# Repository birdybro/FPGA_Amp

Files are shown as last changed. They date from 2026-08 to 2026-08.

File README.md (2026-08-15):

# FPGA Amp

FPGA Amp is a physically informed vacuum-tube audio simulator. The immediate
target is a moving-magnet cartridge feeding the two triodes of a 12AX7 through
the passive RIAA network published by Kevin Kennedy in 1998. It is modeled as a
coupled electrical circuit—not as an EQ block followed by a waveshaper.

```text
AT-VM95E R/L source -> 47.5 kΩ || 150 pF -> 12AX7 #1
 -> 47 nF / 210 kΩ / 33.2 kΩ / 10 nF / 3.3 nF passive RIAA
 -> 12AX7 #2 -> 470 nF -> 2.21 MΩ line load
```

The project keeps three categories separate:

- **Reference:** the frozen 1998 circuit, including its measured low-frequency
  RIAA departure.
- **Approximation:** tube-model, integration, LUT, fixed-point, solver, and RTL
  errors measured against the immediately upstream reference.
- **Enhancement:** future subsonic filtering, tube variation, noise, and other
  modern/creative controls, all explicitly opt-in.

## Current measured milestone

The mono reference and complete 768 kHz circuit solver are operating:

- ngspice DC: stage 1 is 180.0 V / 0.992 mA and stage 2 is 192.8 V /
  1.072 mA at a 300 V supply.
- SPICE circuit gain is 41.087 dB at 1 kHz. Relative RIAA error is
  -0.919 to +0.000 dB from 20 Hz to 20 kHz; this is a property of the frozen
  historical network, not digitally corrected.
- The 768 kHz backward-Euler nonlinear nodal model differs from the ngspice
  5 mV-peak, 1 kHz result by -53.10 dB normalized residual and 0.0018 dB RMS
  gain, with no failed solves.
- A four-frequency SPICE transient sweep exposes backward-Euler's audio-band
  phase cost: at 100 Hz it is +0.00131 dB / +0.0244°, while at 20 kHz it is
  -0.0646 dB / +4.72°. Raising backward-Euler to 3.072 MHz still leaves 1.24°
  at 20 kHz. An explicit 768 kHz trapezoidal candidate improves 10/20 kHz
  floating error to at most 0.00846 dB / 0.0582°.
- A separately labeled 384 kHz/8× trapezoidal architecture candidate measures
  at most 0.06653 dB / 0.02234° against the same 10/20 kHz SPICE captures. At
  20 kHz, its complete-circuit selected 4/8/12/16 kHz products remain within
  0.52 dB of 768 kHz for 5 mV, 20 mV, and steady 0.5 V inputs, while a hot
  static-tube stress is 11.33 dB worse but still -118.65 dBc. Distinct
  fixed-point assets now match 1,024 all-bank chord, 1,024 KCL, and 512
  persistent full-solver RTL vectors exactly at 384 kHz with zero solver
  diagnostics. The 127-clock core
  leaves 129 of 256 clocks free at 98.304 MHz. Its Q17.1 chord inverse requires
  signed 19-bit coefficients rather than the 768 kHz core's 18 bits; controlled
  Yosys synthesis measures 13,713 LC / 183 DSP / 10 RAMB18 equivalents versus
  13,158 LC / 174 DSP / 10 RAMB18 equivalents at 768 kHz. The complete
  candidate stream now matches 64 external outputs across 512 nonlinear
  updates exactly, with zero converter, solver, or deadline diagnostics.
  After serializing each decimator center tap and replacing both resamplers'
  reset-cleared shift histories with reset-masked circular distributed memory,
  controlled full-stream synthesis measures 15,716 LC / 8,547 FF / 207 DSP /
  10 RAMB18 equivalents at 384 kHz versus 16,062 / 9,033 / 206 / 10 for 768 kHz.
  Reference mode remains 16×/768 kHz. A 772,608-update paired fixed-stream
  campaign finds
  8× recovery only 0.1875 ms later, with -84.71 dB aligned waveform and
  -81.02 dB audio-band residuals. Known-delay, windowed-sinc alignment measures
  the synthetic pop at -35.92 dB overall, 2.623 mV peak error, and -53.33 dB
  in-band. A layer decomposition measures the identity converters at -67.49 dB
  in-band, floating Newton at -55.71 dB, and fixed at -53.33 dB; same-rate
  fixed/float nulls remain about -59 dB. This supersedes an invalid earlier
  linear-interpolation result. Direct RTL capture matches the corresponding
  fixed models for all 24,576 pop/recovery outputs and 294,912 nonlinear
  updates at both rates with zero diagnostics. A matched, unfitted absolute
  pop-response comparison against ngspice measures -61.47 dB residual at the
  48 kHz output boundary for 384 kHz and -61.00 dB for 768 kHz; maximum errors
  are 0.539 and 0.546 mV, respectively, with zero failed floating solves. This
  experiment therefore does not support keeping 16× on transient-accuracy
  grounds. The earlier shifting-history three-pin harness packs on XC7A100T at
  63,902 LUTX / 14,737 FFX / 4,071 CARRY4 / 207 DSP, but heap placement does
  not legalize. That baseline legally places on XC7A200T with
  nextpnr's static placer at only 34.40 MHz versus 98.304 MHz. The experimental
  backend's `DEFAULT` grade is not qualified -1 signoff, but the 2.86× miss is
  decisive enough to skip routing. An explicit 49.152 MHz fabric schedule then
  halves every enable interval while preserving the same 384 kHz arithmetic:
  its 127-clock solver fits exactly within the 128-clock internal period, and
  the complete 64-output/512-update regression remains bit-exact with zero
  diagnostics. Baseline static A200T placement improves to 38.34 MHz versus
  49.152 MHz. Circular decimator history then cuts the packed design to 58,363
  LUTX / 10,562 FFX / 4,099 CARRY4 / 207 DSP and makes heap placement legal for
  the first time, but its 22.79 MHz estimate still fails timing. Static
  placement initially reaches 38.38 MHz. Circular interpolation then reduces
  the pack to 56,041 LUTX / 8,589 FFX / 4,116 CARRY4 / 207 DSP and improves
  static placement to 41.27 MHz. The completed legal route reaches 48.482 MHz,
  only 1.38% below 49.152 MHz. Its 20.626 ns critical path starts at solver
  state selection, crosses voltage selection and plate-pin conversion, and
  ends in the factorized-tube input mapping. A separately named exact
  123-clock parallel/pipelined profile instead grows to 242 DSPs and places at
  only 39.62 MHz, so it is rejected. A route-guided tube-pin prefetch plus
  diagnostic-only KCL maximum pipeline also preserves all 64 outputs / 512
  updates and the 127-clock latency. After removing an invalid-only dead
  maximum load it routes legally at 47.07 MHz, but its 21.24 ns chord-preview
  path is slower than the baseline and is likewise not promoted. The route
  remains diagnostic rather than timing closure or a bitstream claim. A
  zero-latency late-selector candidate instead converts current and corrected
  stage-one tube pins independently and selects only the two 32-bit pin buses.
  It remains bit-exact at 127 clocks, synthesizes to 15,645 LC / 8,589 FF /
  207 DSP / 10 RAMB18 equivalents, and routes legally at 48.700 MHz in seed 1.
  That is the best measured route but still misses 49.152 MHz by 0.92%; seed 2
  reaches only 45.051 MHz. Combining it with the register-heavy four-boundary
  maximum sideband was stopped after a pathological first routing iteration
  and is not promoted. A lower-state serial maximum instead scans the nine
  stable residual rows during terminal chord work. It matches 2,048 KCL
  vectors and the complete stream exactly, reduces the pack to 54,699 LUTX /
  8,657 FFX / 4,044 CARRY4 / 207 DSP, and routes legally in 14 iterations, but
  reaches only 47.567 MHz through the now-exposed chord-to-tube path.
  Registering the six raw tube nodes on the exact one-cycle-early chord preview
  removes that path without adding a solver clock: the same complete stream is
  bit-exact at 127 clocks, Yosys measures 15,220 LC / 8,855 FF / 207 DSP /
  10 RAMB18 equivalents, and a legal seed-1 A200T route reaches 61.072 MHz
  against 49.152 MHz. The 16.37 ns critical path is now terminal-current/state
  arithmetic, with 6.44 ns logic and 9.94 ns routing. This closes the target
  under nextpnr's experimental `DEFAULT` grade. Seed 2 independently routes at
  51.080 MHz with 0.77 ns positive estimated slack and a different 19.58 ns
  registered-node-to-tube critical path. Neither result is qualified -1
  signoff or physical validation. The selected seed-1 FASM now also passes a
  wholly open Project-X-Ray bitstream stage: 20,230 frame records become a
  reproducible 9,730,907-byte `.bit`, and `bitread -C` validates 24,060
  configuration frames / 2,432,650 words. Two conversions have identical
  SHA-256 `98a53adf...2b9dcb`; the script fixes only header timestamp metadata
  and records that hardware remains unprogrammed/unvalidated. The 8×
  architecture remains an explicit candidate and reference mode remains 16×.
  The selected 8× profile now also runs through the actual calibrated fabric
  adapter, asynchronous I²S bridge, register bank, and SPI transport. Exact
  regressions cover 64 adapter frames, 64 serial inputs / 44 observable DAC
  frames, control transitions, and 15 SPI frames. Yosys measures 15,699 LC /
  9,085 FF for the adapter and 16,614 LC / 11,586 FF for the full SPI/I²S top;
  both use 217 DSPs / 10 RAMB18 equivalents with zero structural problems.
  The Nexys Video clock leaf now cascades two checked XC7 MMCMs from its real
  100 MHz oscillator to exact 12.288 MHz codec MCLK and 49.152 MHz fabric
  clocks. Its clock-only open route and CRC-readable bitstream pass. A tested
  /16 divider now produces 3.072 MHz BCLK with owning-domain reset release;
  a bus-level-tested open-drain I2C writer and 27-register ADAU1761 startup
  sequence pass exact-byte and fail-stop NACK simulation. The codec layer is
  warning-free in XC7 synthesis at 88 estimated logic cells / 94 flip-flops /
  no DSP or BRAM. The codec remains subordinate to FPGA-provided BCLK/LRCLK,
  and line unmute occurs last. The actual Nexys Video wrapper now composes that
  clock/reset/bootstrap path with one shared codec LRCLK, the 384 kHz
  timing-closed phono profile, SPI control, open-drain I2C, and fail-closed DAC
  data. A mutation-tested contract checks all 18 LOC/IOSTANDARD pairs, active-
  low reset, internal 3.072 MHz BCLK constraint, model rate, and startup mute;
  a separate guard regression proves that serial DAC data stays zero and the
  I2S bridge/FIFO serial ports stay reset through two BCLK synchronizer edges
  after configuration. This prevents undefined ADC frames during the 10 ms
  bootstrap from pre-filling the receive FIFO. Complete synthesis reports
  16,688 estimated logic cells / 11,687 flip-flops / 217 DSPs / ten RAMB18
  equivalents and zero structural problems. Programming, physical ACKs,
  analog audio, and clock measurements remain open. The full open A200T route
  converges legally in 20 iterations and estimates 54.663 MHz against the
  49.152 MHz fabric constraint and 123.457 MHz against 3.072 MHz BCLK. The
  pinned Project-X-Ray stage twice emits the same CRC-readable 9,730,825-byte
  bitstream at SHA-256 `5f196e52...b09dbb8`. This closes the experimental open
  implementation gate only; the `DEFAULT` timing grade is not qualified -1
  signoff and the image has not been programmed. A non-programming hardware
  preflight now rechecks that exact artifact's part, length, SHA-256, and saved
  `bitread -C` evidence before asking openFPGALoader to detect the official
  `nexysVideo` board profile. The current host has neither openFPGALoader nor a
  Nexys Video USB device, so physical bring-up is explicitly blocked rather
  than inferred from the image.
- A 100 ms floating overload comparison finds the trapezoidal candidate finite
  and convergent through 1.5 V peak / 26.4 µA stage-two grid current. At 20 mV,
  its 10% / 1% / 1 mV recovery agrees with backward Euler within 2.6 µs. Both
  retain the modeled long recovery above 0.5 V; trapezoidal does not conceal or
  correct that reference behavior.
- The bit-accurate trapezoidal candidate uses the wide Q28/Q32 node contract,
  Q30 previous capacitor voltage, and explicit signed Q4.44 previous capacitor
  current. Across six 5 mV points from 20 Hz through 20 kHz it stays within
  0.000131 dB / 0.000784° of floating trapezoidal, with zero convergence,
  saturation, range, or correction-fallback events. Its RTL is bit-exact at the
  same 116-clock schedule, including the banked large-signal captures below.
  It remains an optional numerical candidate rather than a silent reference
  change.
- In the 5 ms burst gate, fixed trapezoidal stays diagnostic-clean through
  0.5 V peak and retains the same severe-overload boundary as backward Euler:
  1.0/1.5 V cause 1,107/1,690 residual failures and 1.5 V causes 4,048 tube-
  domain clips. Stored capacitor current reaches 203.34 uA with no arithmetic
  saturation. The doubled 470 nF companion coefficient requires signed 48-bit
  Q0.47, one bit wider than the current backward-Euler RTL KCL contract.
- The 128 × 256 Q0.31 tube LUT has 0.139 µA mean and 9.33 µA worst absolute
  error in a 100,000-point full-range probe.
- The complete bit-accurate three-pass chord candidate is -57.87 dB normalized
  residual from analytical/full-Newton float on the initial multitone; isolated
  state/chord error is -70.33 dB relative to the same circuit using the tube LUT.
- A settled 1 kHz sweep exposes a narrower low-level limitation: at 5 mV peak,
  fixed THD is 0.0733% versus 0.0191% analytical. Doubling either LUT axis does
  not fix the existing 2-D implementation.
- A new factorized Koren candidate replaces that current surface with three
  value/slope 1-D tables and cubic Hermite interpolation. Its bit-accurate Python
  model measures 50.6 nA worst plate-current error in 100,000 points and 0.0188%
  THD at 5 mV versus 0.0191% analytical. Its 1,024-point grid-current branch
  measures 12.55 nA worst / 2.82 nA active-region RMS error; total raw storage
  is 262,144 bits (14.22 raw RAMB18 equivalents). Standalone RTL is exact across
  4,110 vectors at the existing eight-clock latency; structural synthesis
  reports 1,496 logic cells, 35 DSP48E1s, and 8 RAMB18E1 + 1 RAMB36E1. Solver and
  complete-stream modes are also
  bit-exact at the unchanged 126-clock solver schedule.
- A separately named value-only factorized candidate keeps the physical Koren
  factorization and eight-clock interface while using 1,024/8,192/4,096 linear
  tables. Its dense fixed probe measures 47.49 nA worst plate-current error;
  tube, wide-solver, and complete 127-clock terminal-solver RTL are bit-exact.
  The isolated tube routes at 113.24 MHz with 27 DSPs. Full solver synthesis
  uses 166 DSPs and 13 RAMB18E1 + 5 RAMB36E1; routing is still in progress, so
  this remains an FPGA approximation candidate rather than reference mode.
- The SystemVerilog tube lookup accepts physical Q-format voltages, is
  bit-exact for 4,096 randomized vectors, and has eight-clock latency.
- The nine-node chord corrector is bit-exact for 1,024 randomized/boundary
  vectors, including 18 saturation cases, with ten-clock latency; XC7 synthesis
  uses 9 DSP48E1 blocks and no block RAM.
- A device-neutral depth-8 dual-clock FIFO now crosses full audio words with
  binary local/Gray synchronized pointers, two-flop CDC synchronizers, registered
  reads, sticky overflow/underflow, and conservative local-domain occupancy plus
  high-water diagnostics. Unrelated 100/71.4 MHz test clocks preserve a 128-word
  wrap sequence after directed full/empty faults; directed fill reaches exactly
  depth eight and both estimates return to zero after drain. Generic XC7 synthesis
  uses 127 logic cells / 331 flip-flops / no DSP or RAM; Yosys intentionally
  expands this small 8×32 memory to registers. Embedded formal invariants exist,
  and a depth-four formal instance now passes 13 properties for all arbitrary
  clock/control interleavings over 32 global steps. A separate trace reaches
  full plus both fault stickies. This is bounded safety evidence, not unbounded
  induction or a physical metastability claim.
- Separate I²S receive/transmit blocks now implement signed 24-bit stereo in
  32-BCLK slots with the mandatory one-clock I²S delay. A warning-free 16-frame
  loopback covers positive/negative endpoints, independent 32-period slot/delay
  monitoring, injected LRCLK framing failure, and transmit underflow/clear.
  Warning-free XC7 synthesis measures 35 LC / 105 rising-edge flops for receive
  and 97 LC / 137 falling-edge flops for transmit, with no DSP or RAM.
- A bidirectional I²S asynchronous bridge now composes those protocol blocks
  with independent depth-8 stereo-frame FIFOs. A warning-free test sends 20
  exact frames from BCLK to an unrelated fabric clock and back while applying
  fabric receive backpressure; all six bridge diagnostics remain clean apart
  from deliberate DAC startup starvation, which clears in its owning domain.
  Directed multi-frame receive backpressure records 3/3-frame receive and
  4/4-frame transmit high-water marks without loss. Flattened XC7
  synthesis reports 571 LC / 1,547 FF / no DSP or RAM. The small
  8×64 memories are explicitly register-expanded.
- A Gray-counter audio-clock monitor now measures BCLK over 32,768 fabric
  clocks, accepts 1,024 ± 1 edges, and requires three consecutive windows for
  lock. Warning-free directed RTL acquires at the exact ratio, observes 11
  rather than 10 edges after a deliberate speed change, drops lock/latches the
  error, reacquires, clears, detects a stopped clock as zero edges, and revokes
  live state on BCLK reset. Sixteen properties hold over 32-step arbitrary-clock
  traces in a reduced instance, and a witness locks before retaining a bad-rate
  error. The pin top measures exactly 1,024 edges in four windows. Standalone
  synthesis is 68 LC / 125 FF / no DSP or RAM. This detects gross rate error;
  FIFO drift remains the longer-term mismatch diagnostic and neither mechanism
  performs rate matching.
  The register-controlled wrapper now treats missing lock or retained rate
  error as an explicitly modern immediate-mute condition. A shortened-window
  integration test proves startup qualification, stopped-BCLK clamp, recovery
  that remains latched, coherent fault snapshot, and host clear before release;
  model scheduling continues silently so the receive FIFO is not filled.
- A reusable 16-bit held-bus CDC snapshot now uses a four-phase handshake, two
  data synchronizer stages, and a final settling clock. Three warning-free
  captures survive unrelated clocks and a destination reset during a request;
  nine properties also hold for every 40-step arbitrary-clock formal
  interleaving after shared startup reset, with a nonzero complete-transfer
  witness. Generic synthesis is 5 LC / 75 FF with no warnings. The register
  bank waits for this capture before advancing its snapshot sequence and packs
  all four I²S-domain FIFO level/high-water nibbles at `0x35`.
- Standalone converter calibration now maps PCM24 to physical input Q8.24 volts
  and physical output volts back to saturating PCM24 with explicit positive
  Q8.24 coefficients, full-width products, symmetric rounding, endpoint/clip
  counters, and invalid-configuration muting. Python and warning-free RTL match
  4,159 vectors per direction. Twelve full-width arithmetic/state properties
  also close by SAT temporal induction at depth 2, including proof that valid
  input conversion cannot silently truncate. Structural synthesis measures 95
  LC / 66 FF / 4 DSP48E1 input and 86 LC / 58 FF / 4 DSP48E1 output. The
  serial bridge and converter-specific control remain outside the framed
  fabric adapter below.
- The atomic calibration guard now has 12 arbitrary-input properties proven by
  Yosys SAT temporal induction at depth 2. They require exact acknowledge,
  simultaneous positive-pair commit only while muted, state retention on both
  rejection paths, sticky diagnostics, and clear precedence. A satisfiable
  trace includes invalid reject, accepted commit, and unsafe reject.
- A deterministic fabric frame scheduler now accepts one held stereo frame per
  2,048-clock interval and launches it one clock before phase zero, so the
  registered input calibrator reaches the core on its required 48 kHz phase.
  Warning-free RTL verifies held-frame handshakes, a missing-frame zero fill,
  phase alignment, and saturating underflow diagnostics. Generic synthesis is
  41 LC / 43 FF / no DSP or RAM. This aligns frequency-locked domains; it is not
  asynchronous sample-rate conversion and cannot absorb oscillator drift. Nine
  arbitrary-source assertions now prove phase wrap, launch strobes, accepted/
  zero-filled data, and exact saturating-underflow transitions by temporal
  induction at depth 2; a witness covers an absent then present boundary.
- A fabric-domain mono adapter now composes that scheduler, both calibration
  boundaries, and the exact trapezoidal/banked/terminal phono stream. It models
  only left input and explicitly duplicates the mono result into both output
  slots; this is bring-up routing, not stereo. A 64-frame warning-free
  regression checks every calibrated input, raw Q8.24 model output, and held
  PCM frame exactly, including unrelated right-channel data and five clocks of
  output backpressure, then forces and clears one held-output overrun without
  overwriting the older frame. Model and calibration diagnostics remain zero.
  The core remains reset through initial scheduler phase
  acquisition so hidden interpolator zeros cannot advance physical capacitor
  state before the first accepted frame. A downstream modern safety ramp begins
  muted, reaches exact-unity bypass, and leaves reference mode bit-identical;
  the integration test also checks a synchronous force-mute gain clamp.
  Flattened structural synthesis is 18,642 LC / 16,354 FF / 216 DSP48E1 /
  8 RAMB18E1 + 1 RAMB36E1. This leaves 24 DSPs on the provisional
  XC7A100T and has no placed timing, serial-pin, or physical-converter claim.
- A pin-facing digital top now composes the asynchronous I²S bridge with that
  adapter. With exactly frequency-locked but phase-offset 3.072 MHz BCLK and
  98.304 MHz fabric clocks, a warning-free integration test delivers all 64
  unrelated stereo inputs to the left-only model exactly, checks all 64 raw
  model outputs, and receives 45 consecutive observable post-startup DAC frames
  as exact mono duplicates. Receive prefill precedes audio-reset release;
  expected serial startup starvation remains observable. The active ADC/DAC
  scaling pair now resets to zero and commits atomically only while the output
  ramp is muted. The same test accepts the startup pair, then rejects a live
  candidate without changing either active coefficient and clears the unsafe
  diagnostic. Timestamped serial/fabric events measure 192 BCLKs, 62.500 µs,
  or three 48 kHz frames from the first complete ADC PCM frame to the first
  complete valid model-output DAC frame. This is transport latency, not FIR or
  circuit group delay. All four local FIFO views remain at a one-frame
  high-water mark, and the clock monitor is locked after four exact 1,024-edge
  windows. Flattened synthesis is 19,156 LC / 17,669 FF / 216 DSP48E1 /
  8 RAMB18E1 + 1 RAMB36E1. This is a
  digital protocol integration, not placed CDC/I/O timing or converter/analog
  validation. The digital ramp cannot revoke frames already queued in the CDC
  transmit FIFO and is not a substitute for physical analog muting. Host
  register transport and candidate CDC remain open.
- Exact RTL RHS and KCL engines stamp all ten capacitor histories and the
  physical conductance network. Each passes 1,024 vectors at 12 and 10 clocks.
- The integrated solver matches 512 sequential fixed-model samples bit-for-bit
  at every node and capacitor, completes three corrections plus its diagnostic
  residual in 126 of 128 available clocks, and reports no deadline misses.
- Hierarchical out-of-context XC7 synthesis of that complete solver reports
  8,024 estimated logic cells, 89 DSP48E1, and 47 RAMB18E1 blocks. This is an
  accuracy-first baseline; no Fmax is claimed before place-and-route.
- The selectable factorized solver also matches 512 persistent-state samples
  exactly at 126 clocks. Its hierarchy measures 9,148 logic cells, 108 DSP48E1s,
  and 8 RAMB18E1 + 1 RAMB36E1: 37 fewer RAMB18-equivalents at the cost of 19
  DSPs and 1,124 logic cells.
- The complete 48 kHz reference stream—16× interpolation, nonlinear circuit,
  saturating output-format conversion, and 16× decimation—matches 64 consecutive
  Python outputs exactly with zero diagnostic events. Structural synthesis is
  13,170 estimated XC7 logic cells, 137 DSP48E1s, and 47 RAMB18E1s.
- The factorized stream independently matches 64 outputs / 1,024 nonlinear
  updates with zero diagnostics. It synthesizes to 14,290 logic cells, 156
  DSP48E1s, and 8 RAMB18E1 + 1 RAMB36E1. Both modes remain explicit while broader accuracy
  and overload tests determine the preferred hardware configuration.
- At 5 mV the factorized fixed raw null is -42.90 dB, but its mean-removed null
  is -59.63 dB: a -2.840 mV DC difference dominates the raw result. Fundamental
  phase error is 0.00958°. These are reported separately; no DC/gain alignment
  is used to conceal implementation error.
- A 5 mV fixed-vs-analytical sweep at 20, 50, 100 Hz and 1, 10, 20 kHz bounds
  fundamental gain error to 0.00846 dB and phase error to 0.0729°, with no
  residual-limit failures, saturations, or tube-range clips. Raw high-frequency
  nulls remain DC-offset dominated and are not substituted for gain/phase error.
- A 5 ms, 1 kHz overload-burst study measures grid current, clipping asymmetry,
  and recovery against an undisturbed trajectory. The 20 mV fixed case is clean
  and recovers below 10% / 1% nominal RMS in 8.67 / 24.6 ms. At 1.0 V the
  residual limit fails; at 1.5 V stage-two grid current reaches 26.3 µA and the
  transformed tube domain clips.
- Increasing the fixed chord count from three to six reduces the 1.0 V maximum
  residual from 6.93 to 2.31 µA but still leaves 30 failures and projects a
  213-clock serialized schedule. At 1.5 V it remains inadequate. Overload needs
  a different solver/range strategy rather than an unbudgeted extra pass.
- A physically derived, fixed-schedule cutoff-Jacobian bank removes the 1.0 V
  residual failure for both backward-Euler and trapezoidal state. RTL matches
  every fixed state, retains the 116-clock schedule, and records zero
  diagnostics. A Vgk-slew-qualified shallow matrix extends that result through
  the tested 1.5 V peak burst without activating at 0.5 or 1.0 V. Structural
  synthesis is 13,302 logic cells / 120 DSPs / 8 RAMB18E1 + 1 RAMB36E1 for
  backward Euler and 13,840 / 120 / 8 RAMB18E1 + 1 RAMB36E1 for trapezoidal.
- A fixed-intermediate domain audit proves that all former 1.5 V range events
  were only `Vgk < -5 V`: measured `Vpk`, transformed coordinate, and `E1`
  remained inside their tables. The plate-law acceptance bound is now -8 V,
  covering the measured -7.03 V minimum, while the grid-current lookup still
  clamps below -5 V at its negative-grid leakage floor. Backward-Euler and
  trapezoidal 12 ms outputs are bit-exact before/after this diagnostic change.
  Integrated RTL is full-state exact at both 1.0 and 1.5 V; after the independent
  slew-selector change, all four captures have zero residual, range, arithmetic,
  or fallback events.
- Against full Newton with the same Q8.24 input, banked 1.0 V burst error is
  -76.43 dB backward Euler and -76.79 dB trapezoidal, improving the failing DC
  chord by 22.98 and 23.13 dB. No gain, DC, or delay alignment is applied.
- The optional backward-Euler terminal correction reuses the final measured
  residual for a fourth chord update and commits state bit-exact to a
  conventional four-pass fixed trajectory. Its complete 48→768→48 kHz stream
  matches 64 external outputs across 1,024 nonlinear updates exactly with zero
  diagnostics at a measured 127-clock solver latency. Full-hierarchy XC7
  synthesis reports 18,466 logic cells, 168 DSP48E1s, and 8 RAMB18E1 + 1 RAMB36E1; the
  one-clock schedule margin is not a timing-closure claim.
- A captured 100 ms RTL campaign now covers 20 mV, 0.5 V, 1.0 V, and 1.5 V
  overload bursts—384,000 updates including the control trajectory. All fixed
  state is exact and all diagnostics remain zero. Over the final three burst
  cycles, H2--H10 content grows from 0.903% to 25.213%, stage-two grid current
  reaches 26.267 µA, and peak asymmetry changes from +2.659 to -0.541 dB.
  Against analytical Newton, terminal-RTL burst RMS error is 0.288, 1.237,
  4.895, and 6.817 mV; harmonic-window phase error stays within 0.00221° and
  H2--H10 ratio within 0.00122 percentage points. This transient-window
  spectral fit is not mislabeled as settled continuous-drive THD.
- Trapezoidal terminal correction now recomputes all ten Q4.44 companion-current
  histories from the corrected, saturated branch voltages on that same final
  edge. A second 384,000-update campaign is full-state exact and diagnostic-
  clean; burst RMS error versus floating trapezoidal is 0.276, 1.210, 4.709,
  and 3.604 mV. Its 64-output complete 768 kHz stream is exact at 127 clocks.
  The current controlled Yosys build measures 13,158 logic cells / 174 DSPs
  for the solver and 18,280 / 206 / 8 RAMB18E1 + 1 RAMB36E1 for the complete
  stream. This fits the provisional A7-100T structurally with 34 DSPs free,
  but timing is not claimed.
- Schedule-neutral attempts to reduce its remaining 4.709/3.604 mV severe-
  burst error are preserved as negative results. Corrected-state bank
  reselection, rational terminal-residual relaxation, full dual-triode median
  Jacobians, and stage-one-split banks each fail cross-level, recovery, or
  residual-limit acceptance. Reference behavior and production coefficients
  remain unchanged; `make terminal-bank-study`, `make terminal-relaxation-study`,
  and `make dual-triode-bank-study` regenerate the evidence.
- A protocol-neutral fabric register bank now resets muted, atomically commits
  the two converter-calibration shadows, and freezes 16 diagnostic words behind
  a saturating snapshot sequence. Directed RTL covers accepted/invalid/unsafe
  commits, busy writes, clears, and malformed addresses. With delayed coherent
  capture and timeout, current structural synthesis is
  354 LC / 735 FF / no DSP or block RAM. The wrapper below supplies pin
  integration; a host protocol is supplied by the SPI composition below.
- The modern output mute/ramp now has a reproducible Yosys 0.66 formal harness.
  Fifteen reset, force-clamp, valid, state-hold, exact gain-step, endpoint, and
  monotonicity assertions close by temporal induction at depth 2 for arbitrary
  post-reset inputs. A separate SAT witness reaches unity in four accepted
  samples, guarding against vacuous assumptions. This proves the digital
  primitive's stated control contract, not analog speaker safety.
- A register-controlled pin wrapper now owns calibration and mute, freezes 22
  fabric-coherent status words, synchronizes sticky I²S faults, and transfers
  low-rate idempotent diagnostic clear across the unrelated BCLK domain. Ten
  properties hold over 40-step protocol-constrained arbitrary-clock traces,
  with a two-event witness; directed RTL exposes the one replay caused by
  destination reset while the retained source toggle is odd. Integration is
  warning-free. The wrapper also fails closed through BCLK qualification and
  after a retained rate error without changing reference-circuit state.
  Structural synthesis is 19,616 LC / 18,684 FF / 216 DSP48E1 /
  8 RAMB18E1 + 1 RAMB36E1. The current 22-word image adds a coherent held-bus
  I²S occupancy capture; stopped BCLK times out explicitly without advancing
  the retained-image sequence. Named-part timing is not claimed.
- A mode-0 SPI bridge now oversamples CS/SCLK/MOSI in the fabric domain and
  executes fixed 80-bit request/response frames on that register bus. Eight
  warning-free 5 MHz transactions cover real calibration, readback, malformed
  address, short frame, withheld response, and diagnostic clear. Eleven safety
  properties hold through 32 arbitrary-pin fabric steps, and a 100-step witness
  reaches request decode plus both transport errors. Standalone synthesis is
  112 LC / 172 FF / no DSP or RAM. The complete composition then
  passes 15 SPI frames through the pin-facing hierarchy, including untorn
  force-mute snapshots, snapshotted transport count, calibration ownership,
  a retained short-frame fault, and one I²S-domain clear event. Flattened
  synthesis is 19,719 LC / 18,856 FF /
  216 DSP48E1 / 8 RAMB18E1 + 1 RAMB36E1; placed SCLK/CDC/I/O limits remain open.
- A dependency-free Python host client defines the same ten-byte full-duplex
  wire frame, register/capability constants, status validation, explicit-mute
  snapshot/clear commands, snapshot completion polling, and guarded calibration
  commit sequencing. Six unit
  tests cover exact bytes and failure behavior through a fake transport; a
  physical `spidev`/USB/embedded backend remains board-specific and unvalidated.
- A captured complete-stream sweep at 100 Hz, 1 kHz, 10 kHz, and 20 kHz proves
  all 19,200 Q8.24 outputs exact with zero diagnostics. Relative to the composed
  floating trapezoidal reference, gain/phase error stays within 0.000134 dB /
  0.000444°. The worst mean-removed null is -63.77 dB at 20 kHz because the
  fixed/float startup-state residual drifts 87.89 µV across the 50 ms window;
  retaining that metric while removing only its fitted linear drift gives a
  -74.79 dB shape null. No gain, phase, or fractional-delay alignment is used.
- The fixed stream now has a real PCM WAV boundary with mandatory, explicit
  input/output peak-voltage mappings and no hidden normalization. A 1,024-frame
  synthetic MM/pop/multitone regression runs the trapezoidal terminal model
  with zero diagnostics or WAV clips. Its independent null fixture recovers an
  injected 23-sample delay exactly and preserves +2.405 dB raw, -30.462 dB
  latency-aligned, and -100.810 dB opt-in gain-aligned residuals as separate
  fields. Optional fractional alignment is labeled with its interpolation
  method; it is never enabled by default.
- A 14-vector PCM24 library exercises silence, 5/0.5 mV 1 kHz, selected
  19/20 kHz products, a 60 Hz/7 kHz 4:1 SMPTE-style profile, a 100 Hz/1/10 kHz
  multitone, 11 Hz warp, a record pop, a separately controlled impulse, a
  20 Hz–20 kHz log sweep, and both short severe and paired 250 ms accepted-range
  overload records. All 69,440 external frames / 1,111,040 nonlinear updates
  pass with zero model diagnostics or WAV clips. H2–H10 THD is 0.019826% at
  5 mV peak and 0.011559% at 0.5 mV; profile sideband IMD is 0.461295%. The
  5 mV one-sample impulse is strictly causal, first exceeds four PCM LSBs after
  34 samples, and peaks at 138.118 mV. Paired 0.5 V recovery crosses 10% of
  nominal RMS at 147.750 ms after the input burst stop and ends at 18.650 mV
  RMS over the final 10 ms. The high-frequency fixture remains a selected-
  product report, and the SMPTE-style fit is not a calibrated RP 120
  conformance claim.
- Moving only the shallow trapezoidal threshold from -2.50 to -2.75 V prevents
  bank activation at 0.5 V, preserves zero 1.0 V failures, and reduces final
  10 ms mean error from 1.042 to 0.537 mV with the former 128-point grid-current
  branch. This historical selector A/B remains reproducible; the denser branch
  below supersedes its absolute final-window figure.
- A 20 mV/sample previous-Vgk slew qualifier separates the measured severe
  cutoff arc from every accepted <=1.0 V trajectory. Backward Euler adds a
  fourth matrix evaluated at (-2.25 V, 261 V); trapezoidal reuses its shallow
  matrix. The 100 ms 1.5 V residual-failure counts fall from 72/67 to zero and
  the 12 ms RTL proof is full-state exact across 36,864 total updates. With the
  old 128-point grid-current branch, severe burst error remained
  -61.80/-62.12 dB and final 10 ms error remained 18.27/17.36 mV. Those results
  are retained as the pre-resolution baseline, not current accuracy.
- A converged layer decomposition localized that severe recovery error to the
  128-entry linear grid-current table, not the factorized plate law. The
  implemented 1,024-entry branch reduces direct worst error from 716 to
  12.55 nA. At 1.5 V it improves raw burst error to -72.87/-81.77 dB and the
  final-window circuit error to 0.631/0.321 mV for backward Euler/trapezoidal,
  with all fixed diagnostics clean. Standalone and 36,864-state integrated RTL
  regressions are bit-exact and structural RAM use remains eight RAMB18E1s plus one RAMB36E1.
- A second decomposition passes continuously evaluated quantized coefficients
  through the exact Q24/Q20 input and Q31 current interfaces of the banked fixed
  circuit. Integer Hermite evaluation accounts for only 0.149–0.168 mV burst
  RMS, while fixed node/capacitor/chord arithmetic accounts for 6.40–19.07 mV.
  Every intermediate solve is diagnostic-clean. This directs the next accuracy
  work to circuit/state/chord arithmetic rather than another tube-table change.
- A banked three-to-six-pass sensitivity study confirms that solver truncation
  is material: a fourth pass improves 1.0/1.5 V burst error by 5.65–9.02 dB,
  and six passes reduce maximum residual below 0.207 µA and burst RMS to
  2.35–2.94 mV. Recovery-state error is not monotonic with pass count, however,
  and a conventional extra serialized pass projects to 145 clocks versus the
  128-clock deadline. An optional backward-Euler terminal path instead reuses
  the already-computed diagnostic residual: it is output-exact to four-pass,
  completes in 127 measured clocks, and explicitly reports the preterminal
  residual. The later accuracy-first trapezoidal implementation also recomputes
  and commits all ten corrected companion-current histories on that edge.
- Removing the shallowest cutoff matrix is not a valid optimization: the 100 ms
  selector study leaves 289 backward-Euler or 119 trapezoidal 1.0 V residual
  failures. All generated matrices remain required; activation thresholds are
  studied separately from coefficient-bank removal.
- A new one-second silence/click audit exposes a Q12.20 state deadband that the
  KCL diagnostics miss: after bipolar 100 mV one-sample clicks, fixed output is
  still -5.368 mV in the final 100 ms while analytical output is about 7.2 uV
  RMS. The current RTL remains bit-exact to that now-rejected state contract;
  wider internal output/history precision is the active redesign.
- A 40-bit Q28/Q32 all-node Python candidate with Q30 capacitor history,
  branch-current stamping, and Q30/Q34/Q40 staged correction precision reduces
  that late raw residual from 5.375 mV to 38.74 uV RMS with zero diagnostics.
  At 5 mV/1 kHz it improves raw fixed/analytical null from -42.90 to -63.83 dB,
  with -0.000058 dB gain and -0.000187 degree phase error. Its standalone
  wide-state chord corrector is now bit-exact RTL, but complete KCL/state
  integration, schedule, and hierarchical synthesis gates remain.
- Across 20 Hz, 50 Hz, 100 Hz, 1 kHz, 10 kHz, and 20 kHz at 5 mV, that
  candidate stays within 0.000196 dB gain and 0.000982 degree phase of the
  analytical model with zero diagnostics. Raw null spans -95.26 to -44.75 dB;
  high-frequency values remain reported separately from their DC-dominated
  mean-removed residuals.
- A bounded block-floating correction selector requests Q30/Q34/Q40 but reduces
  precision when needed to keep all 25-bit residual operands in range. It
  eliminates arithmetic saturation in the 1.5 V burst (729 recorded fallbacks),
  while ordinary signals never fall back. At 20 mV, 1% recovery improves from
  24.61 ms legacy to 14.92 ms, matching analytical; post-burst error falls from
  5.80 mV to 0.258 mV RMS. Severe overload remains rejected: 1.0/1.5 V still
  produce 1,122/1,695 convergence failures and 1.5 V retains 4,046 range clips.
- The wide Q28/Q32 chord block accepts only the bounded Q30/Q34/Q40 correction
  schedule, matches 1,024 randomized and boundary vectors exactly at 10 clocks,
  and synthesizes structurally to 1,701 XC7 logic cells, 9 DSP48E1s, and no
  block RAM. The constrained three-format shifter avoids the 5,531-cell cost of
  the rejected arbitrary-shift experiment.
- Wide network RTL now matches 1,024 exact RHS and 1,024 exact KCL vectors. The
  two-clock RHS omits capacitor history by design; the ten-clock KCL evaluates
  all ten Q30 branch differences, tests delayed tube-current handshakes, and
  globally selects correction precision. Structural XC7 results are 31 logic
  cells / 4 DSPs for RHS and 8,034 logic cells / 72 DSPs for KCL.
- The same KCL block now has an explicit trapezoidal mode. It remains ten clocks
  and matches 1,024 independent residual/current-history vectors exactly,
  including 1,013 deliberately extreme Q4.44 current-saturation cases. The
  original backward-Euler vector set remains exact and warning-free.
- The integrated wide factorized solver matches Python bit-for-bit for 512
  sequential samples, including every node, capacitor, residual, and diagnostic.
  The measured schedule is 116 clocks, leaving 12 of 128 clocks, with zero test
  diagnostics. Hierarchical XC7 synthesis is 12,544 logic cells, 120 DSP48E1s,
  and 8 RAMB18E1 + 1 RAMB36E1; Fmax remains unmeasured.
- The explicitly selectable trapezoidal solver also matches 512 persistent
  samples exactly, including ten Q4.44 current histories, at the unchanged
  116-clock latency. Its separate chord-inverse ROM is required by the doubled
  capacitor companions. Structural synthesis measures 12,786 logic cells,
  120 DSP48E1s, and 8 RAMB18E1 + 1 RAMB36E1: +242 cells and no DSP/BRAM change versus
  backward Euler. This is structural evidence only; Fmax remains unmeasured.
- The corresponding complete 48 kHz stream matches 64 outputs spanning 1,024
  nonlinear updates exactly with zero diagnostics. Structural synthesis is
  17,492 logic cells, 168 DSP48E1s, and 8 RAMB18E1 + 1 RAMB36E1, so the mono reference fits
  the provisional A7-100T resource envelope but leaves only 72 of 240 DSPs.
- The selectable trapezoidal 48 kHz stream likewise matches all 64 outputs /
  1,024 nonlinear updates exactly with zero diagnostics and 5.02 nA maximum
  residual. Structural synthesis is 17,735 logic cells, 168 DSP48E1s, and
  8 RAMB18E1 + 1 RAMB36E1: +243 cells with unchanged DSP/BRAM versus backward Euler.
- A 23,040-sample captured RTL run at 5 mV / 1 kHz is Q32 bit-exact to fixed
  Python. Measured directly from RTL output, gain/phase error versus analytical
  float is -0.000054 dB / -0.000187 degrees, THD is 0.019371% versus 0.019059%,
  and raw/mean-removed residual is -63.83 / -88.45 dB.
- Captured solver output at 100 Hz, 1 kHz, 10 kHz, and 20 kHz remains Q32
  bit-exact to fixed Python. Against analytical float, maximum gain/phase error
  is 0.000194 dB / 0.000982 degrees with zero runtime diagnostics. This is an
  RTL-simulation result, not an FPGA or analog measurement.
- The same four-point captured sweep in trapezoidal mode is exact to fixed at
  every output and persistent state, and stays within 0.000128 dB / 0.000784°
  of floating trapezoidal with zero diagnostics. The report links, but does not
  combine, the independent ngspice layer: float trapezoidal differs by at most
  0.00846 dB / 0.0582° at the measured 10/20 kHz points.
- The complete 48 kHz trapezoidal boundary is captured for 4,800 outputs at
  each of 100 Hz, 1 kHz, 10 kHz, and 20 kHz. Every RTL output is fixed-model
  exact, all diagnostics remain zero, and the full chain stays within 0.000111
  dB / 0.001185° of its composed floating reference. The report measures the
  causal rate-converter path separately at exactly 51 external samples
  (1.0625 ms), then subtracts that phase only in the explicitly labeled
  circuit-attributed view.
- A captured 100 ms overload campaign matches all fixed nodes, capacitor states,
  outputs, and diagnostics for 384,000 total solver updates. The 20 mV burst
  reaches the 10% / 1% recovery thresholds in 8.47 / 14.92 ms. Bursts at 0.5 V
  and above remain outside even the 10% threshold after 85 ms in both analytical
  and RTL trajectories. Solver residual failures begin at 1.0 V; the 1.5 V case
  has 4,046 modeled-tube range clips and 729 safe scale fallbacks but no arithmetic
  saturation.
- A separate floating trapezoidal run extends physical-model observation to
  235 ms after the burst. It directly measures the 0.5 V case crossing 10% of
  nominal output at 146.552 ms. The 1.0/1.5 V cases remain above that threshold;
  50--240 ms envelope fits identify 110.1/98.2 ms dominant coupled modes and
  project 297/408 ms crossings. Those projections are not reported as measured
  recovery. Node/capacitor checkpoints show stage-two plate/output displacement
  dominates the observed window, rather than the isolated 1.039 s product of
  470 nF and 2.21 MΩ.
- Direct 850 ms trajectories then falsify those early single-exponential
  projections. The 1.0 V case reaches sustained 10% recovery at 270.112 ms but
  never reaches 1%; the 1.5 V case remains above 10% after 835 ms. More
  importantly, deviation nearly cancels at 362/316 ms and then rebounds by
  451×/413× to 31.6/183.8 mV RMS. Recovery is therefore gated on the last
  sliding-RMS threshold crossing, and no severe fixed/RTL accuracy is claimed.
- At the accepted 0.5 V boundary, a separate selectable-trapezoidal RTL run
  captures 192,000 control and 192,000 overload updates. Every node and both
  voltage/current histories for all ten capacitors are fixed-model exact, all
  diagnostics are zero, and sustained 10% recovery is 146.570 ms—18.23 µs from
  the independent floating result. The 1% threshold remains outside 235 ms.
- A continuous-time small-signal linearization of the frozen nodal circuit now
  solves `det(G+sC)=0` at the tube DC bias. All eight finite modes are stable.
  The two recovery-relevant time constants are 143.936 ms and 1.067763 s, with
  99.49% and >99.999999% of their normalized capacitor energy in the 470 nF
  output branch. Their opposing signs explain why an early exponential fit
  failed. Applying the slow mode only after the 835 ms measured endpoint
  estimates the last severe 1 mV crossing near 6.33 s; a seven-second direct
  run is required before turning that estimate into a measurement.
- The resulting seven-second trajectories now measure the complete tail. At
  1.0 V, sustained 10%/1%/1 mV recovery occurs at 0.270112/3.053927/4.536427 s;
  at 1.5 V it occurs at 2.429673/4.888292/6.370790 s. Full Newton covers the
  first 850 ms; a two-pass floating chord solver covers the near-bias tail only
  after a 100 ms overlap stays below 33.2 nV maximum error. A final-cycle probe
  stays below 17.9 nV and all solves converge. The modal estimates were within
  61.4 ms, but the measured times now supersede them.
- A downstream, explicitly non-reference output guard now starts muted, applies
  a configurable sample-qualified linear ramp, bypasses exactly at unity, and
  synchronously clamps held output on a fault. Its warning-free RTL regression
  passes signed rounding/reset/control cases; generic XC7 synthesis reports 171
  logic cells, 2 DSP48E1s, and no block RAM.
- The guarded wide-stream top now enforces model-change sequencing: linear
  ramp-down, frame-aligned core reset, 64-output muted warmup, acknowledgment,
  and ramp-up. A warning-free integration regression proves no reset or warmup
  sample escapes before mute. Structural synthesis reports 17,562 logic cells,
  170 DSP48E1s, and 8 RAMB18 + 1 RAMB36; this remains an unplaced estimate.
- A four-stage 16× half-band reference provides at least 91.6 dB per-stage image
  rejection and suppresses the measured cubic 45 kHz→3 kHz decimation alias to
  -137.8 dB with bit-accurate Q8.24/Q1.23 MACs. An 8,192-output RTL capture now
  reproduces -137.814 dB exactly with zero saturation. A separate complete-tube
  0.5 V / 15 kHz capture is also exact, but has a 1.402 mV finite-window 3 kHz
  projection before decimation. A phase-aware decomposition now isolates all 16
  internal frequencies that fold to ±3 kHz. The 45 kHz component produces zero
  Q8.24 output in the analysis window; removing the complete out-of-band family
  changes the 3 kHz output by only 10.77 nV (-176.96 dBc), below the measured
  fixed-rounding closure. The remaining 3 kHz output dominates by 102.37 dB, so
  the raw -74.59 dBc bin is no longer left ambiguous or mislabeled as aliasing.

There is no physical host-adapter backend, fabricated analog front end,
converter board, qualified speed-grade timing, or physical measurement yet.
The complete board top has a timing-clean experimental open route, but an older
98.304 MHz accuracy-first architecture remains instructive: its XC7 placement measures the
solver timing harness at only 13.90 MHz against 98.304 MHz; this is a diagnosed
architecture failure, not a timing-closure claim. A bit-exact three-clock
Hermite kernel independently routes at 132.54 MHz with two DSP48E1s, but a
value-only eight-clock tube candidate that independently reaches 113.24 MHz
still places at only 13.67 MHz in the full solver. This disproves the earlier
assumption that Hermite dominates the complete path. An extracted 54-DSP
terminal-current block improves from 51.95 to 88.83 MHz after a bit-exact
balanced diagnostic popcount, but still misses the target. Isolated chord and
KCL routes measure 46.40 and 16.64 MHz respectively, identifying KCL's final
residual/fallback cone as the primary limiter. A bit-exact residual register
plus balanced KCL reductions retains 127 integrated clocks and improves KCL
placement to 33.92 MHz, although its router2 attempt did not converge legally.
A separately selectable parallel dual-triode schedule remains bit-exact while
reducing the complete solver from 127 to 95 clocks. Optional KCL column/finish
and chord-apply registers then produce an exact 119-clock complete solver. The
pipelined chord routes at 100.92 MHz. A relaxed-constraint legal route of the
15-clock KCL reaches 42.07 MHz and identifies its exact maximum-residual
diagnostic as the limiter. Accumulator and final-only maximum pipelines plus an
equivalent sign-extension overflow predicate raise the selected isolated KCL
route to 92.23 MHz. The resulting complete solver remains exact at 126 clocks
and synthesizes to 14,990 logic cells, 13,458 flip-flops, 209/240 DSP48E1s, and
20 RAMB18 equivalents, leaving two clocks per internal sample. The isolated
KCL still misses 98.304 MHz by 6.6%. The full design packs to 59,027 slice LUT
elements and 209/240 DSPs but places at only 34.20 MHz, so its router run is
deliberately skipped. A placement-region report shows the KCL, terminal-current,
two tube, and chord hard blocks dispersed across most DSP rows. Building the
same open flow for the Nexys Video's XC7A200T reduces DSP utilization to
209/740, but deterministic placement reaches only 23.83 MHz at the default
timing weight and 35.22 MHz at a measured weight of 20. The larger device alone
therefore does not solve hierarchy timing, and its route is also skipped. A
second, explicitly selectable terminal-current schedule reuses five arithmetic
workers over two registered batches. It is bit-exact across 1,027 standalone
and 512 stateful solver vectors, uses 34 rather than 54 DSPs, and consumes the
last schedule clock (127 total). Fixed lane-pair muxes let the isolated block
route at 90.50 MHz with the default placement weight and 99.59 MHz with a
measured timing weight of 20, closing its 98.304 MHz isolated constraint. The
complete 189-DSP hierarchy still places at only 25.02 MHz with 59,514 LUTX and
14,590 FFX under the default weight. Timing weight 20 improves that placement
to 32.56 MHz, still below both the target and the selected 209-DSP baseline's
34.20 MHz. An overlapping hierarchy floorplan then reaches 36.83 MHz by keeping
KCL/RHS in the left and center DSP columns and nonlinear blocks in the center
and right columns. This is the best complete placement so far, but remains
2.67x short. Mapping all eleven KCL multipliers to LUT logic removes 72 more
DSPs, but the complete shared solver then packs to 101,479/126,800 LUT elements
(80%) and 117 DSPs; even the isolated 71,592-LUT KCL did not complete analytical
placement in a useful interval, so no timing result is claimed. The open runner
now has a pack-only stage that records this exact utilization while explicitly
leaving placement and Fmax incomplete. The candidate is retained as
resource-sharing evidence, not promoted as the default full-solver timing
solution. Softening only the two capacitor multipliers is less expensive—the
complete solver packs at 66,341 LUT elements and 171 DSPs—but its isolated KCL
places at only 37.57 MHz (seed 2), versus the all-DSP KCL's completed 92.23 MHz
route. Routing and complete placement are skipped. The final exact KCL maximum
diagnostic can now complete on a separate `max_valid` sideband while chord
correction starts from the already exact residual. This keeps 1,024 vectors per
integration method and all 512 stateful solver samples bit-exact while reducing
KCL correction latency from 19 to 16 clocks and the complete schedule from 126
to 123 clocks. The isolated decoupled candidate legally routes at only 87.07
MHz (29,569 LUTX / 72 DSP), timing-weight-20 placement reaches 80.03 MHz, and
the 209-DSP full hierarchy places at only 31.97 MHz. The change is retained for
its five-clock scheduling margin, not represented as physical timing closure.
That margin now supports an exact acceptance-edge prefetch of capacitor branch
9, allowing all ten capacitor branches to reuse one wide KCL multiplier with
no added latency. The isolated KCL and complete solver remain bit-exact at 16
and 123 clocks while DSP use falls from 72 to 63 and from 209 to 200. The
isolated candidate places at 72.95 MHz; the full hierarchy reaches 35.06 MHz at
the default weight but only 29.05 MHz at timing weight 20. Combining the same
KCL sharing with the two-batch terminal engine produces an exact 124-clock,
180-DSP solver, yet default and floorplanned placements reach only 30.63 and
32.94 MHz. These measured area reductions do not improve on the 36.83 MHz
complete-placement result and are not promoted as timing closure.
None of these experiments is timing closure or a reference-mode change.
All figures use the backend's unqualified `DEFAULT` timing grade. The implemented digital mute
primitive is not independent analog speaker protection.

## Verification chain

```text
published circuit/data
        -> ngspice
        -> Python floating-point circuit model
        -> bit-accurate Python LUT model
        -> synthesizable SystemVerilog
        -> synthesis
        -> future FPGA and analog measurement
```

The exact circuit and operating points are in
[`docs/phono_stage.md`](docs/phono_stage.md). Equations and measured error
layers are in [`docs/modeling.md`](docs/modeling.md), and the source decisions
are annotated in [`docs/references.md`](docs/references.md).

## Reproduce

Python 3.10+, NumPy, PyYAML, and Matplotlib are required. Verilator is needed
for RTL tests. If ngspice/Yosys are unavailable, the non-root bootstrap downloads
the distribution packages into ignored `.tools/` without changing the host:

```bash
make tools
make test
```

Individual workflows:

```bash
make spice                         # DC, AC, and 5 mV transient
python3 scripts/spice_level_sweep.py
python3 scripts/run_reference.py --plots
python3 scripts/compare_spice_python.py
make spice-python-frequency          # four SPICE transients + integrator study
make internal-rate-study             # explicit 8x-vs-16x nonlinear rate study
make internal-rate-pop-decomposition # converter/float/fixed transient layers
make internal-rate-spice-pop         # absolute rate-specific pop vs ngspice
make internal-rate-transient-rtl     # direct long pop/recovery RTL equivalence
make fixed-384-assets                 # regenerate distinct 384 kHz fixed assets
make trapezoidal-384-chord-rtl        # exact five-bank correction equivalence
make trapezoidal-384-network-rtl      # exact 384 kHz KCL equivalence
make trapezoidal-384-terminal-banked-solver-rtl # exact stateful core equivalence
make synth-trapezoidal-384-terminal-banked-solver # rate-tagged Yosys report
make stream-trapezoidal-384-terminal-banked-rtl # exact complete 48→384→48 kHz stream
make stream-trapezoidal-384-terminal-banked-half-clock-rtl # same stream at 49.152 MHz
make stream-trapezoidal-384-terminal-banked-half-clock-pipelined-rtl # exact rejected 123-clock schedule
make synth-stream-trapezoidal-384-terminal-banked # controlled full-stream synthesis
make trapezoidal-overload            # floating integrator overload stability
python3 scripts/characterize_solver.py
python3 scripts/study_solver_architecture.py
python3 scripts/compare_fixed_float.py
make accuracy-sweeps                # settled level and low-level LUT studies
make factorized-study               # smooth 1-D/Hermite tube candidate
make factorized-frequency           # 20 Hz-20 kHz fixed/analytical sweep
make factorized-frequency-wide      # same sweep with wide-state candidate
make factorized-frequency-trapezoidal # explicit-voltage/current-history candidate
make factorized-domain              # before/after cutoff-domain equivalence audit
make state-drift                    # one-second silence/click state audit
make state-wide                     # wide-state candidate on the same audit
make state-wide-audio               # 5 mV/1 kHz legacy/wide A/B
make linear-modes                   # physical G+sC poles at tube DC bias
make wide-rtl-audio                 # capture and measure 23,040 RTL samples
make wide-rtl-frequency             # captured 100 Hz-20 kHz solver sweep
make trapezoidal-rtl-frequency      # captured selectable-integrator sweep
make trapezoidal-rtl-recovery       # accepted 0.5 V long-recovery capture
make trapezoidal-stream-rtl-frequency # captured complete 48 kHz sweep
make trapezoidal-terminal-stream-rtl-frequency # accuracy-first stream sweep
make wide-rtl-overload              # captured 100 ms overload/recovery sweep
make terminal-banked-rtl-metrics    # terminal H1-H10/clipping/recovery capture
make wide-stream-rtl-alias          # captured nonlinear decimation-alias test
make wav-null-regression            # fixed V1 PCM WAV + explicit null fixture
make audio-regression               # nine-vector distortion/IMD/overload suite
make overload-study                 # grid conduction, clipping, recovery
make overload-trapezoidal           # fixed/float trapezoidal burst comparison
make overload-long                  # 235 ms floating severe-recovery observation
make overload-severe-long           # direct 850 ms multimode recovery test
make overload-seven-second          # complete severe floating recovery timing
make overload-wide                  # same bursts with wide-state candidate
make overload-iterations            # three-to-six-pass solver trade
make overload-banked                # cutoff-Jacobian bank convergence study
make banked-slew-selector           # qualify the severe shallow-bank selector
make banked-error-decomposition     # localize tube/circuit/chord error
make banked-iterations              # banked three-to-six-pass waveform study
make grid-current-resolution        # sweep grid-conduction table accuracy
python3 scripts/study_lut_resolution.py
python3 scripts/analyze_frontend.py
python3 scripts/design_resampler.py
make arithmetic-bounds             # prove wide RHS/KCL/chord integer widths
make rtl                           # lint + 4,096 bit-exact vectors
make factorized-rtl                # smooth tube RTL + directed clip vectors
make chord-rtl                     # lint + 1,024 circuit-correction vectors
make wide-chord-rtl                # exact 40-bit Q28/Q32 correction vectors
make network-rtl                   # RHS/KCL bit-exact unit tests
make wide-network-rtl              # branch-current RHS/KCL exact tests
make trapezoidal-network-rtl       # explicit current-history KCL vectors
make solver-rtl                    # 512-sample persistent-state integration
make solver-factorized-rtl         # exact smooth-tube solver integration
make wide-solver-rtl               # exact 40-bit branch-current solver
make trapezoidal-solver-rtl        # exact selectable integration-mode solver
make banked-solver-rtl             # exact four-bank cutoff solver
make terminal-banked-solver-rtl    # exact 127-clock terminal correction
make trapezoidal-banked-solver-rtl # exact five-bank cutoff solver
make trapezoidal-terminal-banked-solver-rtl # exact terminal current commit
make banked-rtl-overload           # 1.0/1.5 V full-state bank-selection gate
make terminal-banked-rtl-overload  # terminal full-state overload gate
make banked-accuracy               # 100 ms banked/full-Newton waveform gate
make banked-selector               # prove required cutoff-bank partitions
make banked-threshold              # sweep shallow trapezoidal activation
make halfband-rtl                  # exact 2x units and complete 16x streams
make stream-rtl                    # complete 48 kHz reference stream
make stream-factorized-rtl         # complete smooth-tube reference stream
make stream-wide-rtl               # complete wide-state reference stream
make stream-terminal-banked-rtl    # complete banked terminal-correction stream
make stream-trapezoidal-rtl        # complete trapezoidal reference stream
make stream-trapezoidal-terminal-banked-rtl # 127-clock trap terminal stream
make guarded-stream-rtl            # mute/reset/warmup model-change sequence
make mute-rtl                      # reset/ramp/fault output safety primitive
make formal-mute                   # Yosys SAT safety-ramp induction + witness
make formal-async-fifo             # bounded arbitrary-clock FIFO safety
make formal-calibration-control    # atomic scaling commit/reject induction
make formal-frame-scheduler        # cadence/zero-fill/counter induction
make formal-cdc-snapshot           # bounded coherent held-bus CDC safety
make formal-cdc-pulse              # bounded low-rate toggle CDC safety
make formal-audio-clock            # bounded BCLK monitor safety/lock witness
make formal-audio-calibration      # exhaustive converter rounding/saturation
make formal-spi-control            # bounded arbitrary-pin SPI state safety
make master-volume-rtl             # stereo click-free Q0.31 volume endpoint
make volume-servo-test             # host C11 motor-position/fault controller
make audio-clock-rtl               # BCLK/fabric ratio lock and error monitor
make async-fifo-rtl                # unrelated-clock CDC ordering/fault gate
make cdc-pulse-rtl                # one-shot host command CDC
make spi-control-rtl              # 80-bit mode-0 register transport
make i2s-rtl                       # 24-bit/32-slot stereo protocol loopback
make i2s-bridge-rtl                # exact bidirectional I2S/fabric CDC loopback
make calibration-rtl               # bit-exact PCM24/physical-volts boundary
make calibration-control-rtl       # atomic muted coefficient-pair commit
make control-registers-rtl         # snapshot/shadow/transaction register bank
make frame-scheduler-rtl           # deterministic 48 kHz fabric phase launch
make mono-adapter-rtl               # exact framed PCM-to-model-to-PCM datapath
make mono-adapter-384-rtl           # selected 8x/49.152 MHz adapter path
make i2s-mono-top-rtl               # serial ADC through model to serial DAC
make i2s-mono-top-384-rtl           # serial path with selected 384 kHz model
make i2s-control-top-rtl            # register-owned pin hierarchy and clear CDC
make i2s-control-top-384-rtl        # register hierarchy with 384 kHz model
make i2s-spi-top-rtl                # complete SPI-controlled I2S audio hierarchy
make i2s-spi-top-384-rtl            # complete 384 kHz SPI/I2S hierarchy
make synth                         # generic XC7 structural estimate
make synth-factorized              # factorized tube structural estimate
make synth-chord                   # generic XC7 chord-corrector estimate
make synth-wide-chord              # wide-state corrector structural estimate
make synth-wide-network            # wide RHS/KCL structural estimates
make synth-solver                  # hierarchical complete-solver estimate
make synth-solver-factorized       # smooth-tube hierarchy/resource trade
make synth-wide-solver             # wide-state hierarchy estimate
make synth-trapezoidal-solver      # trapezoidal hierarchy estimate
make synth-banked-solver           # backward-Euler banked hierarchy estimate
make synth-terminal-banked-solver  # terminal-correction hierarchy estimate
make synth-trapezoidal-banked-solver # trapezoidal banked hierarchy estimate
make synth-trapezoidal-terminal-banked-solver # terminal-current hierarchy
make synth-stream-wide             # complete wide-state stream estimate
make synth-stream-trapezoidal-terminal-banked # accuracy-first mono stream
make synth-stream-terminal-banked  # complete terminal-correction stream estimate
make synth-stream-trapezoidal      # complete trapezoidal stream estimate
make synth-stream-guarded          # wide stream plus safety/control guard
make synth-halfband                # complete interpolator/decimator estimates
make synth-stream                  # complete reference-stream estimate
make synth-stream-factorized       # smooth-tube stream resource estimate
make synth-mute                    # output ramp structural estimate
make synth-audio-clock             # audio clock ratio monitor estimate
make synth-async-fifo              # depth-8 dual-clock FIFO estimate
make synth-cdc-pulse               # one-shot command crossing estimate
make synth-spi-control             # oversampled SPI transport estimate
make synth-master-volume           # out-of-context stereo volume estimate
make synth-i2s                     # receiver/transmitter structural estimates
make synth-i2s-bridge              # bidirectional protocol/CDC bridge estimate
make synth-calibration             # dynamic converter-scaling estimates
make synth-calibration-control     # atomic calibration guard estimate
make synth-control-registers       # fabric control/snapshot register estimate
make synth-frame-scheduler         # frame-phase scheduler estimate
make synth-mono-adapter            # calibrated accuracy-first fabric datapath
make synth-i2s-mono-top            # protocol/CDC plus calibrated mono datapath
make synth-i2s-control-top         # register-controlled complete pin hierarchy
make synth-i2s-spi-top             # SPI transport plus complete pin hierarchy
make synth-mono-adapter-384        # 384 kHz adapter XC7 resource measurement
make synth-i2s-spi-top-384         # complete 384 kHz pin-top measurement
make audio-clock-plan              # verify exact MMCM ratios from board RTL
make nexys-audio-top-contract      # verify pins/reset/clocks/profile composition
make synth-audio-clock-xc7         # clock-only XC7 structural measurement
make audio-serial-clock-rtl        # verify /16 BCLK and domain reset release
make synth-audio-serial-clock-xc7  # XC7 BCLK/reset leaf measurement
make i2c-write-rtl                 # verify open-drain register transactions
make i2c-read-rtl                  # verify repeated-START byte register reads
make synth-i2c-read                # measure I2C read primitive XC7 resources
make adau1761-codec-init-rtl       # verify fixed bootstrap and fail-stop NACK
make pcm5242-dac-init-rtl          # verify exact DAC write sequence/NACK abort
make synth-pcm5242-dac-init        # measure DAC bootstrap XC7 resources
make pcm5242-dac-verify-rtl        # verify DAC readback/status fail-closed gate
make synth-pcm5242-dac-verify      # measure readback/status XC7 resources
make pcm5242-dac-runtime-rtl       # verify periodic clock/short/power monitor
make synth-pcm5242-dac-runtime     # measure runtime monitor XC7 resources
make pcm5242-dac-startup-rtl       # verify integrated startup/runtime gate
make synth-pcm5242-dac-startup     # measure integrated startup XC7 resources
make dac-line-sequencer-rtl        # verify relay-first/XSMT-first board order
make synth-dac-line-sequencer      # measure output sequencer XC7 resources
make codec-shared-i2s-guard-rtl    # verify shared LRCLK and startup zero gate
make synth-nexys-phono-audio-xc7   # synthesize complete board wrapper
make hermite-rtl                   # bit-exact iterative Hermite regression
make synth-hermite                 # isolated Hermite resource measurement
make factorized-linear-rtl         # value-only tube exact-vector regression
make wide-linear-solver-rtl        # integrated value-only solver regression
make factorized-linear-study       # Hermite/linear/full-Newton circuit A/B
make tools-openxc7                 # build pinned open XC7 P&R tools locally
make openxc7-probe                 # report Yosys/nextpnr/database revisions
make openxc7-a200t-probe           # verify the second Artix-7 chip database
make openxc7-stream-384-pack       # pack complete 384 kHz stream on A7-100T
make openxc7-stream-384-place      # attempt A7-100T heap placement
make openxc7-a200t-stream-384-static-place # static-place stream on A7-200T
make openxc7-a200t-stream-384-half-clock-static-place # test 49.152 MHz schedule
make openxc7-a200t-stream-384-half-clock-node-prefetch-serial-max-pnr # route selected 49.152 MHz profile
make openxc7-a200t-stream-384-half-clock-node-prefetch-serial-max-bit # Project X-Ray .bit + bitread CRC gate
make openxc7-a200t-audio-clock-pnr # route exact Nexys Video audio clocks
make openxc7-a200t-audio-clock-bit # assemble/CRC-check clock-only bitstream
make openxc7-a200t-phono-audio-pnr # route complete codec/phono/SPI board top
make openxc7-a200t-phono-audio-bit # assemble/CRC-check complete board image
make nexys-audio-hardware-preflight # validate image and detect cable, no load
make nexys-audio-program-sram      # explicitly load volatile SRAM after checks
make openxc7-pnr                   # route the solver timing harness on A7-100T
make openxc7-hermite-pnr           # route the Hermite timing harness on A7-100T
make openxc7-linear-tube-pnr       # route the value-only tube harness
make openxc7-linear-solver-pnr     # route the value-only complete solver
make openxc7-terminal-current-pnr  # isolate terminal companion-current timing
make terminal-current-half-parallel-rtl # exact two-batch resource-sharing test
make openxc7-terminal-current-half-parallel-pnr # route 34-DSP shared block
make openxc7-terminal-current-half-parallel-timing-pnr # measured weight-20 closure
make openxc7-kcl-pnr               # isolate wide KCL timing
make openxc7-chord-pnr             # isolate banked chord-correction timing
make openxc7-pipelined-kcl-pnr     # route bit-exact staged KCL candidate
make openxc7-pipelined-chord-pnr   # route bit-exact staged chord candidate
make openxc7-parallel-pipelined-solver-pnr # route 119-clock solver candidate
make openxc7-diagnostic-pipelined-kcl-pnr # route 19-clock final-diagnostic KCL
make openxc7-decoupled-diagnostic-pipelined-kcl-pnr # route 16-clock correction/sideband KCL
make openxc7-decoupled-diagnostic-pipelined-kcl-timing-place # weight-20 placement only
make shared-capacitor-decoupled-diagnostic-kcl-rtl # exact 63-DSP KCL schedule
make openxc7-shared-capacitor-decoupled-diagnostic-kcl-place # place shared KCL
make openxc7-parallel-diagnostic-pipelined-solver-place # diagnose full placement
make openxc7-parallel-diagnostic-pipelined-solver-pnr # route 126-clock solver
make openxc7-parallel-decoupled-diagnostic-pipelined-solver-place # place 123-clock solver
make trapezoidal-parallel-shared-capacitor-decoupled-diagnostic-pipelined-terminal-banked-solver-rtl # exact 200-DSP solver
make openxc7-parallel-shared-capacitor-decoupled-diagnostic-pipelined-solver-place # place 200-DSP solver
make openxc7-parallel-shared-capacitor-decoupled-diagnostic-pipelined-solver-timing-place # tagged weight-20 experiment
make trapezoidal-parallel-shared-capacitor-terminal-decoupled-diagnostic-pipelined-terminal-banked-solver-rtl # exact 180-DSP composition
make openxc7-parallel-shared-capacitor-terminal-decoupled-diagnostic-pipelined-solver-regions-place # floorplan 180-DSP solver
make openxc7-parallel-shared-terminal-diagnostic-pipelined-solver-place # place 189-DSP candidate
make openxc7-parallel-shared-terminal-diagnostic-pipelined-solver-timing-place # tagged weight-20 experiment
make openxc7-parallel-shared-terminal-diagnostic-pipelined-solver-regions-place # overlapping hierarchy floorplan
make openxc7-parallel-shared-terminal-diagnostic-pipelined-solver-soft-kcl-pack # exact all-soft-KCL resource trade
make openxc7-parallel-shared-terminal-diagnostic-pipelined-solver-soft-kcl-capacitors-pack # partial-soft full pack
make openxc7-diagnostic-pipelined-kcl-soft-pack # isolated all-soft-KCL pack
make openxc7-diagnostic-pipelined-kcl-soft-capacitors-place # partial-soft seed-2 timing
make openxc7-a200t-parallel-diagnostic-pipelined-solver-place # compare A200T
```

Run a user-supplied 48 kHz integer-PCM WAV through an explicitly selected V1
fixed model by supplying the physical peak-voltage mappings at both boundaries:

```bash
python3 scripts/process_wav.py input.wav output.wav \
  --report build/process.json \
  --mode banked-terminal-trapezoidal \
  --input-full-scale-v 0.02 --output-full-scale-v 2.0

python3 scripts/compare_wav.py reference.wav candidate.wav \
  --report build/null.json --residual-wav build/residual.wav \
  --spectrum-csv build/residual_spectrum.csv
```

The comparison defaults to integer latency alignment but does not fit gain, DC,
or fractional delay. `--gain-align` and `--fractional-delay` are opt-in. The
fractional method is explicitly selected as `linear` or `windowed_sinc`, and a
known physical delay can be supplied instead of correlation. Every applied
transformation is recorded alongside the unaligned metrics.

Generated CSV, plots, logs, ROM images, and reports are intentionally ignored;
every one has a source script. The compact LUT characterization report is kept
under `model/generated/` as part of the numerical contract.

## Repository map

- `reference/spice/`: frozen analog golden reference and Koren tube subcircuit
- `reference/tube_data/`, `reference/vectors/`: traceable comparison data
- `model/python/fpga_amp/`: mathematical, nonlinear circuit, and fixed models
- `model/configurations/`: circuit and simulation values
- `models/phono/`: versioned model asset metadata
- `rtl/tube/`, `rtl/circuit/`, `rtl/phono/`: synthesizable tube and V1 solver
- `sim/unit/`, `sim/integration/`: self-checking RTL testbenches
- `scripts/`: all reproduction, comparison, analysis, and synthesis entry points
- `firmware/front_panel/`: host-tested motor-volume safety/control core
- `hardware/kicad/front_panel_controller_rev_a/`: generated/routed six-layer
  touchscreen, UI MCU, memory, control, and backlight EVT controller
- `hardware/kicad/phono_adc_eval_rev_a/`: generated/routed four-layer MM input,
  flat-gain, differential-driver, and PCM4202 ADC EVT board
- `hardware/kicad/dac_line_output_eval_rev_a/`: generated/routed four-layer
  PCM5242 DAC, reconstruction, hardware-mute, and line-output EVT board
- `hardware/kicad/front_panel_motor_eval_rev_a/`: generated and routed KiCad
  motor/position EVT daughterboard, source generator, BOM, and invariants
- `docs/`: engineering decisions, budgets, known limitations, and hardware path
- `hardware/product_v1/`: machine-checked product-board requirements and
  interface ownership

The comprehensive product-board baseline is
[`docs/product_hardware_spec.md`](docs/product_hardware_spec.md). It partitions
the low-noise phono/ADC, eARC/FPGA, DAC/line, LCD/touch/motor-control, and power/
protection functions across five serviceable boards. Its eARC receiver,
asynchronous clock boundary, motorized volume servo, premium physical controls,
remote-control paths, grounding, safety, manufacturing, and acceptance gates
are checked for traceability with `make product-hardware-spec`. These are design
requirements, not a released PCB or HDMI compliance claim.

The first concrete PCB artifact is the motor-volume evaluation daughterboard
at
[`hardware/kicad/front_panel_motor_eval_rev_a/`](hardware/kicad/front_panel_motor_eval_rev_a/README.md).
It isolates the DRV8874, protected 5 V motor rail, current telemetry, and dual
ratiometric position tracks from audio. The checked 80 x 48 mm four-layer board
has 0 schematic ERC violations, 0 PCB DRC violations, and 0 unconnected items
under KiCad 10.0.5; `make kicad-motor-fab` regenerates its reports and
fabrication package. It remains an unbuilt EVT design, not a production PCB or
a motor-noise/lifetime result.

The matching front-panel controller is at
[`hardware/kicad/front_panel_controller_rev_a/`](hardware/kicad/front_panel_controller_rev_a/README.md).
Its checked 150 x 90 mm six-layer route has 0 ERC violations, 0 DRC
violations, and 0 unconnected items under KiCad 10.0.5. It concretely maps an
STM32H753ZIT6 to LTDC RGB565, 32 MiB SDRAM, Quad-SPI, touch, physical encoders,
mute/standby, and the motor/digital board links. Exact project-local Molex
54104-4031/52271-0679 footprints are dimension-audited and regression-checked.
The board is visibly marked and documented as not fabrication-released until
physical connector fit/first-article inspection, stackup/SI, switching-power
layout, and mechanical interfaces are signed off.

The first audio-input PCB is at
[`hardware/kicad/phono_adc_eval_rev_a/`](hardware/kicad/phono_adc_eval_rev_a/README.md).
Its checked 130 x 90 mm four-layer route has 0 ERC violations, 0 DRC
violations, and 0 unconnected items under KiCad 10.0.5. It implements physical
47.5 kilohm/selectable-capacitance MM loading, OPA1656 20/26/32 dB flat gain,
OPA1632 differential drive, PCM4202 conversion, and local low-noise
post-regulation. It remains an unbuilt EVT design; measured input capacitance,
noise/hum/overload/RF/ESD, production connector mechanics, muted relay changes,
and physical validation of the simulated 6.144 MHz/128-fS FPGA receiver are
explicit release gates.

The matching audio-output PCB is at
[`hardware/kicad/dac_line_output_eval_rev_a/`](hardware/kicad/dac_line_output_eval_rev_a/README.md).
Its checked 112 x 72 mm four-layer route has 0 ERC violations, 0 DRC
violations, and 0 unconnected items under KiCad 10.0.5. It implements a
PCM5242 external-clock slave, balanced and RCA reconstruction networks,
separate low-noise analog/digital post-regulators, normally-open output relays,
and dual hardware AND interlocks so an external supervisor dominates both DAC
XSMT and relay permission. It remains an unbuilt EVT design; converter
control integration, loaded audio measurements, physical fault/mute sequencing,
ESD/RF, production connector/chassis mechanics, stackup, and DFM are explicit
release gates.

The matching write-only PCM5242 RTL bootstrap is bus-regression-tested for its
exact twenty one-byte-register transactions and NACK abort. It configures the
external-clock, unity/reference path but deliberately exposes only
`configuration_written`; it cannot authorize board unmute until a later
readback/status layer validates the actual converter state.

A separate synthesizable I2C reader now implements the required one-byte
register-address transaction through repeated START and master NACK. Its
directed target model checks exact bus bytes, returned data, STOP/release, and
an address-NACK abort; Yosys reports 70 estimated XC7 logic cells, 63
flip-flops, no DSP/BRAM, and no warnings. It remains deliberately transport
only. The page-aware verifier above it performs 24 exact operations and requires
the critical page 0/1 configuration, detected 48 kHz, 512-fS SCK, 64-fS BCK,
valid clock flags, DSP boot, and run state. Directed simulation covers the
complete success path and injected masked-mismatch/NACK failures. Its
`configuration_verified` result is distinct from the ACK-only write result;
Yosys reports 170 logic cells, 173 flip-flops, no DSP/BRAM, and no warnings.
This remains a startup snapshot; the integrated controller follows it with a
separate continuous monitor rather than treating it as permanent health.

The integrated controller now makes that ordering explicit: it runs the
20-write initializer, launches the 24-operation verifier only after ACK-only
completion, then requires a four-register runtime-health sweep before exposing
one fail-low `unmute_permitted`. Periodic polls read live/latched clock faults,
active/sticky output-short status, and DSP power state. Its full bus test proves
48-transaction release and shows that ACK-only completion, the startup snapshot,
both startup failure phases, and a post-unmute short cannot leave permission
asserted. The runtime monitor alone is 122 logic cells / 178 flip-flops; the
integrated controller is 340 / 439, with no DSP/BRAM or warnings. Physical
FPGA/PCB integration and measured fault/mute timing remain release gates.

The final controller-side split matches the PCB rather than driving both gates
at once. `dac_line_output_sequencer` closes the normally-open relays, waits a
default 491,520 clocks (5 ms at 98.304 MHz), then releases XSMT. Orderly mute
drops XSMT, waits for the soft ramp, and opens the relays; emergency mute drops
both registered controller permissions on the next fabric edge. The independent
`HARD_MUTE_N` path remains asynchronous hardware veto. Directed simulation
covers all paths, and Yosys reports 28 logic cells / 22 flip-flops with no
DSP/BRAM or warnings.

The prioritized engineering ledger is [`TASKS.md`](TASKS.md). The next critical
path is further reducing terminal-solver approximation error without breaking
the 128-clock deadline and resolving full-placement congestion through broader
cross-block scheduling or explicit hierarchy placement; controlled XC7A200T
and 189-DSP terminal-sharing experiments show that capacity or one locally
shared block alone is insufficient. The required Linux flow is Yosys plus the
experimental nextpnr-Himbaechel/Project X-Ray XC7 backend; Vivado is not part
of the project flow, and the backend's `DEFAULT` timing grade is not presented
as qualified XC7A100T-1 signoff.

## License

GPL-3.0; see [`LICENSE`](LICENSE).

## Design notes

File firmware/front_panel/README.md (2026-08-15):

# Front-panel firmware cores

`volume_servo.c` is the mechanism-independent safety and position controller
for the motorized volume dial. It contains no STM32 HAL calls and builds under a
host C11 compiler so command, reversal, timeout, and fault behavior can be
regressed before a front-panel PCB exists.

The integration task calls `volume_servo_step()` at one fixed period (a 1 ms
initial target), after synchronously sampling:

- ratiometric absolute dial position;
- filtered DRV8874-class current feedback;
- the motor-driver fault pin;
- optional grip/manual-override detection; and
- the latest serialized authoritative volume-position command.

The returned `drive` and `duty_per_mille` command the H-bridge. Hardware current
regulation remains mandatory; software is not a safety substitute for the
driver's cycle-level limit. The core adds soft endpoints, approach-speed
reduction, deadband/coast, reversal dead time, retained overcurrent/stall,
bounded travel time, driver/sensor faults, explicit safe fault clear, manual
override, and idle back-drive takeover. A fault clear resets the target to the
present safe position, so it cannot automatically retry against a mechanical
stop.

`target_changed` tells the UI event owner to propagate a manual position change
back through the same authoritative volume sequence used by touchscreen, CEC,
and network commands. The target maps to decibels outside this core. No
potentiometer track or position value is part of the audio path.

Run:

```sh
make volume-servo-test
```

The host regression builds with C11, `-Wall -Wextra -Werror -pedantic`, then
checks configuration rejection, endpoint clamping, fast/approach duty,
deadband, exact reversal coast, explicit and inferred manual takeover, retained
stall, safe clear/no retry, travel timeout, driver fault, and sensor fault. This
is digital behavioral evidence only. PWM/ADC timing, motor torque, EMI, acoustic
noise, touch safety, and mechanism lifetime require the physical FP prototype.

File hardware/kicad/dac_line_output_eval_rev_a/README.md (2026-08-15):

# PCM5242 DAC / protected line-output Rev-A EVT board

This directory contains a routed four-layer KiCad 10 evaluation board for the
stereo FPGA-to-line-output path. It is a concrete bench prototype, not a
production fabrication release and not evidence of measured audio performance.
Open `dac_line_output_eval.kicad_pro` in KiCad 10. KiCad does not live-reload
files changed by the generator, so close/reopen the board after regeneration.

```text
FPGA 24-bit I2S + 24.576 MHz SCK
  -> PCM5242 in external-clock slave / I2C mode
  +-> 499 ohm/leg + 1 nF differential reconstruction -> fail-open relays -> balanced harness
  +-> 499 ohm + 2.2 nF shunt reconstruction -> fail-open relay -> isolated-RCA harness
```

The board is 112 x 72 mm with F.Cu / continuous L2 GND / L3 POWER_SIG /
B.Cu. Digital/control entry, DAC and charge pump, reconstruction networks,
relays, and panel harnesses are physically partitioned. The harness connectors
are EVT choices; production XLR/RCA mechanics belong to the enclosure design.

## Fixed electrical contract

- DAC: PCM5242RHBR, 48 kHz slave, 24-bit I2S in 32-BCK channel slots.
- Clocks: 24.576 MHz external SCK (`512 fS`), 3.072 MHz BCK (`64 fS`), and
  48 kHz LRCK. External SCK is used instead of making the DAC PLL the reference.
- Control: I2C mode with `MODE1=0`, `MODE2=1`, `ADR1=0`, and `ADR2=0`.
  Reference firmware must hold XSMT low while configuring and reading back a
  unity path; optional miniDSP/creative processing is disabled in reference
  mode.
- Supplies: separate external 3.7 V analog and digital feeds post-regulated by
  two TPS7A2033 devices, plus a separate 5 V relay feed. The power board owns
  sequencing and the single reviewed chassis/signal-ground bond.
- Balanced output: the official EVM-style 499 ohm per-leg and 1 nF
  differential network. Into 20 kilohm differential, calculated full scale is
  4.00038 V RMS at DC and 3.97214 V RMS at 20 kHz.
- RCA output: the data-sheet-style 499 ohm / 2.2 nF single-ended network. Into
  10 kilohm, calculated full scale is 2.00019 V RMS at DC and 1.98314 V RMS at
  20 kHz.
- Output switching: three Omron G6K-2F-Y 5 V relays use only normally-open
  contacts, so loss of power opens every signal output.

Two SN74LVC1G08 gates provide independent fail-low interlocks:

```text
LINE_RELAY_EN_SAFE = LINE_RELAY_EN_CTL AND HARD_MUTE_N
DAC_XSMT_SAFE      = DAC_SOFT_UNMUTE_CTL AND HARD_MUTE_N
```

Each input is pulled low. The external supervisor can therefore force both
PCM5242 soft mute and physical relay mute even if the controller is stuck high,
reset, absent, or unpowered. The intended unmute order is configure/read back
the DAC while XSMT is low, energize output relays, then raise XSMT. Mute reverses
that order after allowing the DAC ramp to finish.

`design.py` is the auditable source for exact clock, loading, output-level, and
reconstruction-response calculations. Its committed result is
`design_calculations.json`.

## Reproduction and verification

From the repository root:

```sh
make kicad-dac-line-check
make kicad-dac-line-render
```

To regenerate and route from source, set `FREEROUTING_JAR` to Freerouting 2.2.4
or a verified compatible release:

```sh
make kicad-dac-line-route FREEROUTING_JAR=/path/to/freerouting.jar
make kicad-dac-line-check
```

The route script rotates the PCM5242 so its clock pins face the digital side and
its four analog outputs face the reconstruction networks. Freerouting completes
the dense routing; a deterministic reviewed back-edge trace finishes J2.4 I2C
SDA without passing through the header's other even-numbered pads.

The committed board passes KiCad ERC and DRC with zero violations and zero
unconnected items. `verify.py` also locks the PCM5242 and interlock pad maps,
mode straps, normally-open relay contacts, filter values, DNP chassis options,
calculation consistency, board stack/outline, and minimum routing geometry.

The matching open RTL now includes the 20-write configuration bootstrap,
24-operation page-aware readback verifier, and periodic clock/error/short/power
monitor. The integrated controller requires a 48-transaction success path
before `unmute_permitted` and revokes it on a later fault. A separate
`dac_line_output_sequencer` maps that permission to the actual board pins:
`LINE_RELAY_EN_CTL` rises first, `DAC_SOFT_UNMUTE_CTL` follows after a default
5 ms, and orderly mute reverses the order. Emergency mute drops both registered
permissions on the next fabric edge; `HARD_MUTE_N` remains the independent
asynchronous hardware veto. All bus/sequence tests and Yosys structural checks
pass, but no populated-board timing or audio behavior is claimed.

## Release gates

Do not order this as a production board until all of the following are closed:

- PCM5242 control is integrated onto the selected FPGA pins and every physical
  mute transition is verified with the external supervisor able to dominate a
  stuck controller;
- loaded THD+N, dynamic range, frequency response, channel balance, crosstalk,
  output impedance, DC, and clipping are measured on populated hardware;
- power-up, shutdown, brownout, missing-clock, hot-plug, and harness-unplug
  behavior are measured without an audible or damaging transient;
- enclosure-qualified XLR/RCA connectors, pin-1/chassis treatment, isolated
  RCA mounting, and keyed harnesses are selected;
- the provisional PESD5V0X1BCL output clamps pass leakage/capacitance/audio and
  IEC ESD/EFT/RF-immunity qualification; and
- a fabricator stackup, DFM, return-current, thermal, assembly, and sourcing
  review is complete.

## Primary component sources

- [TI PCM5242 data sheet](https://www.ti.com/lit/ds/symlink/pcm5242.pdf)
- [TI PCM5242EVM user guide](https://www.ti.com/lit/ug/slau592a/slau592a.pdf)
- [TI TPS7A20 data sheet](https://www.ti.com/lit/ds/symlink/tps7a20.pdf)
- [TI SN74LVC1G08 data sheet](https://www.ti.com/lit/ds/symlink/sn74lvc1g08.pdf)
- [Omron G6K relay family](https://components.omron.com/sg-en/products/relays/G6K)

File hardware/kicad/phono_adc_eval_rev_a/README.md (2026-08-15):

# Shielded MM phono / PCM4202 ADC Rev-A EVT board

This directory contains a routed four-layer KiCad 10 evaluation board for the
flat-gain Architecture A input path. It is a concrete bench prototype, not a
production fabrication release and not evidence of measured performance.

```text
isolated panel RCA harness -> 100 ohm RF limiter -> 47.5 kilohm load
  -> selectable 0/47/100/147 pF C0G load -> OPA1656 flat gain
  -> OPA1632 fully differential driver/filter -> PCM4202 stereo ADC
  -> 24-bit I2S to the FPGA board
```

The board is 130 x 90 mm with F.Cu / continuous L2 GND / L3 POWER_SIG /
B.Cu. Cartridge entry, relay loading, flat gain, differential drivers, ADC,
local post-regulation, and digital headers are physically partitioned. The RCA
and turntable-ground connectors are EVT harness/terminal choices; production
parts remain enclosure decisions.

## Fixed electrical contract

- ADC: PCM4202DBR, 48 kHz single-rate master, 24-bit I2S.
- SCKI: 24.576 MHz from the digital board (`512 fS`).
- ADC outputs: 6.144 MHz BCK (`128 fS`), 48 kHz LRCK, serial data, and L/R
  clip indicators. `pcm4202_i2s_capture` now receives this exact 64-BCK
  half-frame format and crosses it into fabric in RTL simulation; pin timing
  and populated-board operation remain unverified.
- PCM4202 straps: `S/M=0`, `FMT1:FMT0=01`, `FS2:FS0=001`, `HPFD=1`.
  `HPFD=1` disables the converter high-pass filter so reference mode retains
  the external circuit's low-frequency behavior.
- Analog rails: TPS7A39 local +12.0/-11.9 V from external +/-15.5 V;
  TPS7A2050 +5 V from +5.7 V; TPS7A2033 +3.3 V from +3.7 V. Relay +5 V is
  supplied separately.
- Input termination: 47.5 kilohm, 0.1%, per channel. Installed capacitance is
  switchable in 47 pF and 100 pF increments. Cable, connector, ESD, relay,
  amplifier, and PCB parasitics are additional and must be measured.
- ADC reset and all relay controls fail low. The signal path must be hardware
  muted before changing gain or capacitance.

The gain relay truth table is:

| `GAIN_BANK_CTL` | `GAIN_RANGE_CTL` | Selected gain | Meaning |
|---:|---:|---:|---|
| 0 | X | 26.064 dB | unpowered/reset default |
| 1 | 0 | 20.008 dB | high-headroom range |
| 1 | 1 | 32.002 dB | low-level range; 100 mV stress clips |

The capacitance relays act independently:

| `CAP_47PF_CTL` | `CAP_100PF_CTL` | Installed C0G increment |
|---:|---:|---:|
| 0 | 0 | 0 pF |
| 1 | 0 | 47 pF |
| 0 | 1 | 100 pF |
| 1 | 1 | 147 pF |

`design.py` is the auditable source for exact gain, headroom, clock, strap, and
rail calculations. Its committed result is `design_calculations.json`.

## Reproduction and verification

From the repository root:

```sh
make kicad-phono-adc-check
make kicad-phono-adc-render
```

To regenerate and autoroute from source, set `FREEROUTING_JAR` to Freerouting
2.2.4 or a verified compatible release and run:

```sh
make kicad-phono-adc-route FREEROUTING_JAR=/path/to/freerouting.jar
make kicad-phono-adc-check
```

The committed routed board passes KiCad ERC and DRC with zero violations and
zero unconnected items. `verify.py` additionally locks the critical IC and
relay pad maps, component population, ADC straps/clocks, layer structure,
outline, minimum routing geometry, and generated calculation consistency.

## Release gates

Do not order this as a production board until all of the following are closed:

- enclosure-qualified isolated RCA jacks and turntable ground-post mechanics;
- measured total input capacitance in every relay state;
- input-referred noise, hum, gain, overload recovery, channel separation, RF
  injection, and ESD tests on populated hardware;
- stackup/return-current and safety review with the intended enclosure/power
  board;
- 128-fS PCM4202 receive timing verified at physical FPGA pins (RTL simulation
  is complete); and
- muted relay switching and all power-up/down fault cases verified.

## Primary component sources

- [TI PCM4202 data sheet](https://www.ti.com/lit/ds/symlink/pcm4202.pdf)
- [TI OPA1656 data sheet](https://www.ti.com/lit/ds/symlink/opa1656.pdf)
- [TI OPA1632 data sheet](https://www.ti.com/lit/ds/symlink/opa1632.pdf)
- [TI TPS7A39 data sheet](https://www.ti.com/lit/ds/symlink/tps7a39.pdf)
- [TI TPS7A20 data sheet](https://www.ti.com/lit/ds/symlink/tps7a20.pdf)

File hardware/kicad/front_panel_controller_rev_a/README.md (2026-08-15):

# Front-panel controller PCB — revision A EVT

This directory contains the generated, routed KiCad controller board for the
5-inch touchscreen, user controls, and motor-volume daughterboard. Open
`front_panel_controller.kicad_pro` in KiCad 10. KiCad does not live-reload
files changed externally, so close and reopen the schematic/PCB editor after a
generator or routing run.

## Checked artifact

The checked-in board is 150 x 90 mm with six copper layers:

```text
L1  F.Cu    components and signals
L2  GND1    continuous ground reference
L3  PWR     power and routing
L4  SIG2    signals
L5  GND2    continuous ground reference
L6  B.Cu    signals and ground pour
```

KiCad 10.0.5 reports zero schematic ERC violations, zero PCB DRC
violations, and zero unconnected items after zone fill. The open route has
1,827 track segments and 327 vias at minimum 0.20 mm track / 0.30 mm drill.
The source-aware verifier checks the package pin map, connector electrical map,
layer stack, board size, source damping, regulator choice, and routed
geometries.

This is an EVT routing baseline, **not a fabrication release**. In particular,
the checked board deliberately carries `NOT FAB RELEASED` silkscreen and the
following gates remain open:

- print and physically fit the drawing-derived Molex 54104-4031 and 52271-0679
  footprints, obtain assembler DFM review, and inspect first-article joints;
- define the fabricator's six-layer stackup, then review impedance, return
  paths, SDRAM flight time/skew, and LTDC edge integrity;
- perform a specialist layout review of the TPS62132 buck and TPS61165 boost,
  including switch-node copper, hot loops, thermal paths, and emissions;
- freeze enclosure, display, harness, encoder, and mounting geometry; and
- close sourcing, assembly, bring-up, ESD, thermal, EMC, and lifetime tests.

No fabrication-output target is provided while those stop conditions are
open.

## Implemented electrical architecture

- STM32H753ZIT6 in LQFP-144 with all supply pins, 11 local 100 nF bypass
  sites, connected VCAP pins with two 2.2 uF low-ESR capacitors, filtered
  VDDA/VREF+, HSE/LSE footprints, reset, BOOT0, and 10-pin SWD.
- An independently checked 106-I/O allocation covering RGB565 LTDC, touch,
  x16 FMC SDRAM, Quad-SPI, FPGA control SPI, three quadrature encoders,
  mute/standby, ambient sensing, and the motor-volume interface.
- IS42S16160J 32 MiB x16 SDR SDRAM and W25Q256JV 32 MiB Quad-SPI flash.
- Twenty 33 ohm LTDC source-damping resistors plus clock damping for SDRAM and
  Quad-SPI. Values are provisional until stackup-specific measurement/SI.
- Exact NHD-5.0-800480AF-ASXP-CTP electrical pin assignment. Unused RGB LSBs
  are grounded for RGB565; DE, HSYNC, VSYNC, standby, and the capacitive-touch
  reset/interrupt signals are retained.
- Project-local footprints for the exact Molex 54104-4031 40-pin top-contact
  TFT connector and 52271-0679 6-pin bottom-contact touch connector. Their
  manufacturer-drawing pad count, pitch, land size, and fitting-nail geometry
  are locked by `verify.py`; see `footprint_audit.md` for the dimension audit.
- TPS61165 backlight boost from 12 V with a 3.32 ohm feedback resistor for
  approximately 60.2 mA nominal LED current and 32 kHz PWM target. The display
  data sheet's typical LED string voltage is about 21.1 V.
- TPS62132 fixed 3.3 V / 3 A buck. TPS62133 is intentionally rejected here
  because it is the fixed 5 V member, not the 3.3 V part.
- Separate harnesses for panel-mounted encoders/buttons, digital-board control,
  and the motor-volume board. The motor position tracks remain control inputs
  only and never carry audio.
- `FORCE_MUTE_N` defaults asserted through hardware. A healthy MCU must
  intentionally establish control; the GUI is not allowed to become the sole
  safety path.

The high-quality source/model/parameter knobs are panel-mounted optical
encoder candidates rather than PCB-mounted consumer encoders. This keeps shaft
loads in the metal panel and lets enclosure mechanics determine the exact
Grayhill 62H or Bourns EM14 variant. The motorized volume mechanism remains on
the separate, already-routed motor board so its PWM currents do not share the
display/MCU board.

Direct Ethernet is not available in this LQFP-144 Rev-A allocation: the RMII
pin set conflicts with the chosen LTDC/FMC functions. Adding Ethernet requires
an external SPI bridge/module or a package/architecture revision. The eARC
receiver is also intentionally absent; it belongs on the separately licensed
digital/eARC mainboard next to the HDMI connector and ASRC.

## Reproduction

```text
make kicad-controller-generate
make kicad-controller-route FREEROUTING_JAR=/path/to/freerouting.jar
make kicad-controller-check
make kicad-controller-render
```

`generate.py` recreates the native schematic, source placement, custom symbol
library, project, and BOM from one part/net model. It erases routing by design.
`route_open.py` exchanges DSN/SES with Freerouting and refills zones on import.
It also applies one reviewed 1.6 mm U2 ground dogleg when v2.2.4 stops one
connection short; the mandatory DRC remains the acceptance gate. The checked
route used Freerouting v2.2.4. `verify_pin_assignment.py` rejects
duplicate package pins or package-position drift before board generation.

## Primary references

- [Newhaven NHD-5.0-800480AF-ASXP-CTP data sheet](https://newhavendisplay.com/content/specs/NHD-5.0-800480AF-ASXP-CTP.pdf)
- [Molex 54104-4031 product/drawing record](https://www.molex.com/en-us/products/part-detail/541044031)
- [Molex 52271-0679 product/drawing record](https://www.molex.com/en-us/products/part-detail/522710679)
- [ST STM32H753ZI data sheet](https://www.st.com/resource/en/datasheet/stm32h753zi.pdf)
- [ST AN4938 hardware-development guidance](https://www.st.com/resource/en/application_note/an4938-getting-started-with-stm32h74xig-and-stm32h75xig-mcu-hardware-development-stmicroelectronics.pdf)
- [ST official open pin data](https://github.com/STMicroelectronics/STM32_open_pin_data), pinned extract provenance commit `7d1f1514ed5583ec5007ad91236b4e1d377295b1`
- [ISSI IS42S16160J data sheet](https://www.issi.com/WW/pdf/42-45S83200J-16160J.pdf)
- [TI TPS61165 data sheet](https://www.ti.com/lit/ds/symlink/tps61165.pdf)
- [TI TPS62132/TPS6213x data sheet](https://www.ti.com/lit/gpn/TPS62133)
- [Freerouting open autorouter](https://github.com/freerouting/freerouting)

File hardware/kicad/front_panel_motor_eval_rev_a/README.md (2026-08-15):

# Motor-volume evaluation PCB — revision A

This is the first physical KiCad design derived from the product hardware
specification. It isolates the electrically noisy and mechanically uncertain
motor-volume subsystem so it can be measured before committing it to the large
LCD/MCU front-panel board.

Open `front_panel_motor_eval.kicad_pro` in KiCad 10. The checked board was
generated and verified with KiCad 10.0.5. KiCad does not live-reload files
changed by the generator, so close and reopen the schematic/PCB editor after an
external regeneration. Do not hand-edit generated connectivity without also
updating `generate.py`.

## Verified artifact

The checked-in board is an 80 x 48 mm, four-copper-layer EVT daughterboard with
44 schematic parts, four M3 mounting holes, 28 named nets, 235 routed segments,
and 28 vias. The last clean run reports:

```text
schematic ERC violations:  0
PCB DRC violations:        0
unconnected PCB items:     0
minimum routed width:      0.25 mm
minimum via drill:         0.35 mm
```

The bottom and inner-1 layers are GND pours. Inner-2 is reserved as `POWER` but
is not used as an indiscriminate plane in this small prototype. Connector and
test-point functions are labeled on silkscreen. R19/C10 carry KiCad DNP flags,
and placement export excludes them.

## Electrical intent

- 4.75–5.25 V motor input for the Bourns PRM16 4.5 V / 100 mA prototype motor.
- DRV8874 in PH/EN control mode with 33 ohm input damping and 100 kilohm
  fail-off pulldowns.
- 10 kilohm IPROPI resistor: nominal 0.45 V at 100 mA using the datasheet's
  nominal 450 microamp/amp scaling. This is stall telemetry, not precision
  metrology; the datasheet permits substantial absolute error below 0.4 A.
- 14.7/10 kilohm VREF divider and 10 kilohm IPROPI resistor: nominal hardware
  current regulation near 297 mA. This threshold and the 500 mA PTC are not
  released values until motor start/stall measurements are complete.
- IMODE uses 62 kilohms to select cycle-by-cycle regulation and latched-off
  overcurrent behavior. Firmware still detects ordinary stalls from IPROPI and
  stops without waiting for device OCP.
- Dual 10 kilohm-class potentiometer tracks are excited ratiometrically from
  MCU 3.3 V. Their filtered wipers carry position only and never audio.
- R19/C10 are deliberately DNP EMI-tuning sites. They may only be populated
  from measured motor emissions and driver-current evidence.

## Connectors

`J1` is keyed motor power. `J2` is the prototype MCU interface. `J3` is a
separate twisted motor pair. `J4` carries the two position tracks. Separating
J3 from J4 prevents PWM current from sharing position-sensor conductors.

This is an EVT instrument, not a production-released board. The PRM16 has a
published 15,000-cycle rotational life, while the product requirement remains
100,000 qualified full-range cycles.

The DRV8874 PowerPAD is assigned to GND using the standard non-via-in-pad KiCad
HTSSOP footprint. That is suitable for low-current motor evaluation only after
assembly inspection; a production layout must close copper area, thermal vias,
paste aperture, and fabricator capability from measured dissipation. The
0.25 mm routes are ample for the candidate's published 100 mA maximum motor
current but are not evidence for an unselected larger mechanism. Connector
families, PTC trip/hold rating, TVS selection, current threshold, and optional
snubber remain provisional until bench measurements.

Primary component references are the
[TI DRV8874 datasheet](https://www.ti.com/lit/ds/symlink/drv8874.pdf) and the
[Bourns PRM16 datasheet](https://www.bourns.com/docs/product-datasheets/PRM16.pdf).
The route was produced with
[Freerouting](https://github.com/freerouting/freerouting) v2.2.4 through
KiCad's DSN/SES interchange. Freerouting is intentionally not vendored.

## Commands

```text
make kicad-motor-generate
make kicad-motor-route FREEROUTING_JAR=/path/to/freerouting.jar
make kicad-motor-check
make kicad-motor-fab
```

`kicad-motor-route` starts from generated placement and can occasionally leave
an unrouted item because the open autorouter is heuristic. The mandatory check
target fails in that case; rerun the route rather than accepting an incomplete
board. Fabrication outputs are generated under
`build/kicad/front_panel_motor_eval/fab/` and are intentionally not committed.
Passing export is not an instruction to order boards: peer layout review,
mechanical fit, sourcing, assembly rules, and the provisional items above are
still open.

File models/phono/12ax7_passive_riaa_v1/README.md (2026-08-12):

# 12AX7 passive-RIAA V1 asset

This directory is the stable identity/provenance wrapper for the exact Kennedy
1998 mono circuit. `model.yaml` links the single source of component values, the
ngspice golden reference, Python implementation, and expected nominal results.

The asset category is `reference`. Tube/component tolerance, modern subsonic
filtering, hum reduction, and creative bias/sag controls require distinct mode
metadata and may not alter these expected results in place.

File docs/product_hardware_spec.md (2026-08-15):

# Product hardware specification — V1 platform

Status: architecture baseline, not a released schematic or production claim.  
Machine-readable requirements: `hardware/product_v1/requirements.json`.  
Signal/contact budget: `hardware/product_v1/interface_budget.csv`.  
Last reviewed: 2026-08-15.

This specification turns the existing phono-model prototype into a product
platform with a TV input, premium local controls, and a motorized volume dial.
It deliberately does not change the frozen two-stage 12AX7 passive-RIAA
circuit. HDMI eARC, asynchronous rate conversion, master volume, display,
remote control, muting, and protection are modern system functions outside the
historical model (`SYS-002`).

The product is a line-level component in V1. A later clean physical power
amplifier may be attached, but speaker power and speaker protection are not
provided by the FPGA or by the V1 line-output boards.

## 1. Decisions and release gates

### 1.1 Frozen architecture decisions

- Use five cooperating PCBs rather than one mixed-signal board (`SYS-001`).
- Keep phono input/RIAA modeling, TV audio, and safety/UX layers explicitly
  separated (`SYS-002`, `SYS-004`).
- Use a local low-jitter 48 kHz-family clock for ADC, FPGA output, and DAC;
  cross TV audio through an asynchronous sample-rate converter (`CLK-001`,
  `EARC-005`).
- Advertise only stereo LPCM in V1. Do not claim or expose compressed-audio,
  Atmos, DTS, DSD, or multichannel decoding (`EARC-002`, `EARC-004`).
- Use the volume dial only as a position/control transducer. It carries no
  audio (`VOL-002`).
- Provide local mute and standby controls that work without the LCD
  (`UI-004`).
- Build and program FPGA images with Yosys, nextpnr/Project X-Ray, and
  openFPGALoader; a vendor-IDE-only device is not an acceptable production
  substitution (`FPGA-001`).

### 1.2 Provisional component selections

| Function | Baseline candidate | Reason and open gate |
|---|---|---|
| eARC/ARC receiver | Lattice SiI9437 | Audio-device eARC receiver with four-lane I2S and S/PDIF output. Selection is conditional on current supply, full documentation, vendor software terms, licensed reference design, and adopter/compliance access. |
| full HDMI contingency | Analog Devices ADV7671A | Current 48 Gbit/s transceiver with eARC receiver support, but its video/HDCP complexity, 108-LFCSP package, licensed high-level API, and adopter requirements make it an expensive fallback rather than the audio-only baseline. |
| asynchronous SRC | TI SRC4392 | Active two-channel converter, host control/diagnostics, 24-bit words, and rates through 216 kHz. ADI AD1896 is the no-programming alternate. Bench comparison must measure lock behavior, group delay, spur floor, and recovery. |
| FPGA | XC7A200T resource class, SBG484 prototype baseline | Existing mono hierarchy openly routes on this device. The exact production package and speed grade remain provisional until stereo/full-path synthesis, power analysis, SI, and sourcing close. |
| front-panel MCU | STM32H753ZIT6 Cortex-M7 | LTDC, FMC, timers/ADCs, 2 MiB flash, and hardware cryptography in a serviceable LQFP-144 package. The completed Rev-A allocation uses 106 unique I/O positions and cannot expose the on-chip Ethernet MAC because RMII conflicts with LTDC/FMC; Ethernet therefore requires an external bridge/module or an architecture revision. Firmware shall use an open GCC/Clang build even if manufacturer configuration tools assist bring-up. |
| LCD/touch | Newhaven NHD-5.0-800480AF-ASXP-CTP | 5-inch, 800 x 480, 24-bit RGB, IPS, capacitive FT5426G touch over I2C, cover glass, EMI-shielded FPC, and high-brightness backlight. Lifecycle and backlight thermal tests remain gates. |
| motorized rotary prototype | Bourns PRM16 dual-track motorized control | Available rotary prototype part with manual/motor operation. Its 15,000-cycle rating is not acceptable as the unqualified production life claim. |
| production volume mechanism | supported metal shaft + position sensor + back-drivable gearmotor, or qualified motor-pot | Must pass the mechanical feel, acoustic, stall, manual override, and at least 100,000 full-range-cycle qualification in `VOL-006`. A front bearing/coupler carries the large knob load. |
| volume motor driver | TI DRV8874 | Bidirectional H-bridge with current regulation, proportional current feedback, fault indication, and supply range compatible with prototype motor rails. Current limit is set for the selected mechanism, not for the driver's maximum rating. |
| other rotary controls | Grayhill 62H or Bourns EM14 optical encoder | Metal shaft/bushing, quadrature output, push option, and long published rotational life. Final detent torque and resolution are selected by a physical human-factors trial. |

The parts table is not permission to copy a public data brief into a schematic.
In particular, the HDMI connector network and receiver layout shall come from
the licensed specification and vendor reference design after `EARC-008` is
closed.

### 1.3 Production stop conditions

Do not order a production PCB or advertise eARC until all of these are true:

1. the manufacturer is operating under the required HDMI adopter agreement;
2. the receiver vendor has supplied the complete register/API, schematic,
   layout, firmware, errata, and compliance package;
3. the selected receiver and approved connector have a credible production
   supply path;
4. stereo FPGA processing meets numerical, timing, resource, and thermal gates
   (`SYS-003`);
5. a pre-layout power-integrity and signal-integrity review is complete;
6. the eARC design passes analyzer tests and multi-vendor TV interoperability;
7. HDMI compliance is completed for the finished product (`EARC-008`,
   `TEST-002`); and
8. the full board set passes the noise, mute, motor, ESD, thermal, and analog
   acceptance tests in section 18.

An HDMI receiver component does not license the finished device. HDMI LA states
that the finished product must be made by an adopter and satisfy compliance
requirements even if it contains licensed components.

## 2. System partition

```text
                            PRODUCT CHASSIS

  MM RCA L/R + ground                          TV eARC/ARC
          |                                         |
          v                                         v
  +----------------+       local I2S       +-----------------------+
  | AB: PHONO/ADC  |---------------------->| DB: eARC + ASRC + FPGA|
  | termination    |                       | source router          |
  | flat gain      |                       | physical models        |
  | anti-alias     |                       | volume/mute/diagnostics |
  +----------------+                       +-----------+-----------+
                                                      |
                                            local I2S |
                                                      v
  +----------------+       control SPI     +-----------------------+
  | FP: LCD/TOUCH  |<--------------------->| OB: DAC + LINE OUTPUT |
  | encoders       |                       | reconstruction/filter  |
  | motor volume   |                       | analog mute/line driver|
  | remote host    |                       +-----------------------+
  +-------+--------+
          |
          | power-good / hard-mute / fault
          v
  +---------------------------------------------------------------+
  | PB: DC INPUT + RAIL SEQUENCING + SUPERVISION + PROTECTION     |
  +---------------------------------------------------------------+
```

The phono/ADC board occupies the quiet rear corner immediately behind the RCA
jacks. The HDMI connector and eARC receiver occupy the opposite rear corner.
The FPGA and switching regulators remain between those zones only when plane
and enclosure current paths have been reviewed. The front-panel motor and
backlight are physically remote from the cartridge input (`EMC-002`).

### 2.1 DB — digital and eARC mainboard

Responsibilities:

- approved Type-A TV-audio connector, eARC/ARC receiver, CEC/control support,
  capability data, link diagnostics, and ESD network;
- incoming-TV-clock serial audio capture;
- stereo asynchronous rate conversion into the local audio domain;
- local master oscillator, FPGA clocks, ADC/DAC clocks, and reset sequencing;
- FPGA, configuration flash, JTAG, serial control, source routing, model
  processing, master volume, delay, muting, and diagnostic counters;
- board-identity/calibration EEPROM and temperature/rail monitors; and
- service USB/UART/JTAG headers that can be depopulated for production.

### 2.2 AB — shielded phono and ADC board

Responsibilities inherit the quantitative design in `analog_frontend.md`:

- two RCA inputs, turntable ground post, 47.5 kilohm termination, and
  selectable 0/47/100 pF installed input capacitance (`PHONO-001`,
  `PHONO-003`);
- low-capacitance ESD/RF protection whose capacitance is included in the total
  cartridge load;
- 20/26/32 dB relay- or low-leakage-switch-selected flat gain (`PHONO-002`);
- fully characterized input-referred noise and overload behavior;
- differential anti-alias drive and a stereo 24-bit-class ADC (`CONV-001`);
- a local low-noise post-regulator tree from separately supplied analog rails;
  and
- no display, motor, radio, HDMI, or high-current switching load.

The physical input loading is required even though the reference tube circuit
is digital. Cartridge inductance, cable capacitance, front-end capacitance, and
47.5 kilohm resistance form a real electrical network before the ADC.

The concrete Rev-A EVT artifact is
`hardware/kicad/phono_adc_eval_rev_a/`. It implements OPA1656 flat gain,
OPA1632 differential drive, PCM4202 conversion, relay-selected gain/loading,
and local post-regulation on a routed 130 x 90 mm four-layer board. KiCad 10.0.5
reports zero ERC, DRC, and unconnected items. It is intentionally marked not
fabrication-released: the panel RCA/ground mechanics, total input capacitance,
noise/hum/overload, RF/ESD behavior, stackup, muted relay operation, and the
PCM4202 128-fS FPGA receive path are still release gates.

### 2.3 OB — DAC and line-output board

Responsibilities:

- stereo 24-bit-class DAC clocked from the local audio domain;
- reconstruction filtering and a low-noise line driver;
- nominal consumer output near 2 V RMS and a balanced path with sufficient
  clean headroom for the documented 2.25 V RMS reference case;
- calibrated output scaling owned atomically with ADC calibration
  (`CONV-003`);
- balanced outputs preferred, plus protected single-ended outputs
  (`CONV-002`);
- hardware analog mute that defaults active when power, clocks, configuration,
  or supervisory state is invalid (`SAFE-001`, `SAFE-002`); and
- output DC/overload monitoring and test injection points.

Line muting may use an audio-qualified relay or a measured low-distortion solid
state arrangement. The release decision is based on THD+N, resistance,
charge-injection transient, fail state, and lifetime measurements, not on part
category alone.

The concrete Rev-A EVT artifact is
`hardware/kicad/dac_line_output_eval_rev_a/`. It implements a PCM5242 in 48 kHz
external-clock slave/I2C mode, official-reference 499 ohm reconstruction
branches, direct ground-centered balanced and RCA outputs, separate analog and
digital post-regulators, normally-open signal relays, and two fail-low hardware
AND interlocks. The controller and external supervisor must both release the
relay path and PCM5242 XSMT independently. The routed 112 x 72 mm four-layer
board passes KiCad 10.0.5 with zero ERC, DRC, and unconnected items. It remains
an unbuilt EVT artifact. The open RTL now provides exact configuration/readback,
continuous status polling, and relay-first/XSMT-first controller sequencing;
pin integration, audio performance, physical mute/fault transitions, ESD/RF,
connector/chassis mechanics, stackup, and DFM remain release gates.

### 2.4 FP — front-panel board

Responsibilities:

- MCU, external SDRAM/QSPI flash, LCD timing, touch input, encoder decoding,
  LEDs, ambient-light sensing, and local settings storage;
- volume position sensing, H-bridge control, current/stall detection, manual
  takeover, and motor fault reporting;
- protocol-neutral FPGA register access over SPI plus interrupt and heartbeat;
- local-only operation always available (`UI-006`). The Rev-A LQFP-144 pin
  allocation omits direct Ethernet because RMII conflicts with the selected
  LTDC/FMC signals; any network option must use an isolated external SPI
  bridge/module or trigger a package/architecture review rather than silently
  stealing display or memory pins; and
- direct physical mute/standby paths that do not depend on the GUI task.

The MCU owns the GUI and user intent, not audio samples. If it resets, the FPGA
continues with the last valid settings only under the selected safe policy; an
invalid heartbeat, malformed transaction, or explicit safety event mutes
output (`UI-005`, `SAFE-002`).

The routed Rev-A controller source is in
`hardware/kicad/front_panel_controller_rev_a/`. It implements the MCU, SDRAM,
QSPI, RGB565/touch display, backlight supply, panel-control harnesses, and
motor-board/control-board interfaces. It passes KiCad connectivity checks but
remains an EVT artifact. The exact Molex 54104-4031/52271-0679 land patterns
are now drawing-derived and regression-checked; physical connector fit and
first-article inspection, stackup/SI, switching-power layout, and enclosure
geometry remain explicit fabrication stop conditions.

### 2.5 PB — power and protection board

V1 uses an external safety-certified DC supply so mains does not enter the
development enclosure (`PWR-001`). PB provides input fuse/e-fuse, reverse and
surge protection, standby supply, sequenced main rails, rail monitoring,
thermal sensing, hard-mute logic, and keyed board distribution. A future
integrated speaker amplifier gets a separate high-current supply/protection
design and may not borrow this line-level protection argument (`SAFE-003`).

## 3. Source and processing modes

| Source | Clock boundary | Allowed processing | Forbidden implicit behavior |
|---|---|---|---|
| MM phono | local ADC clock | input calibration -> frozen V1 tube/RIAA model -> optional explicitly labeled modern subsonic -> master volume -> DAC | bypassing or retuning historical RIAA because another mode sounds better |
| TV eARC/ARC | TV clock -> ASRC -> local clock | bypass/line mode initially; later selected virtual line or complete-amplifier model -> master volume -> DAC | sending TV PCM through phono RIAA; silently discarding channels; claiming compressed decode |
| service digital generator | explicit local or asynchronous test clock | bypass or selected model with capture diagnostics | entering customer mode without an obvious test indication |

The first eARC firmware shall publish capability data for two-channel LPCM only
(`EARC-002`). V1 accepts 16/20/24-bit PCM containers at the rates proven during
bring-up, with a design target through 192 kHz (`EARC-003`). If the link presents
an unadvertised or unsupported format, the product mutes that source, records
the received status, and tells the user why. It does not interpret IEC 61937
payloads as PCM.

The UI may expose the following clearly labeled paths:

- **Phono Reference** — frozen phono circuit, no modern filter.
- **Phono Modern** — same reference model plus separately identified modern
  options.
- **TV Direct** — ASRC, delay, master volume, and DAC.
- **TV Amplifier** — future line/full-amplifier model, never the phono model.
- **Diagnostic Loop** — factory/service only.

## 4. eARC/ARC electrical and protocol architecture

### 4.1 Receiver choice and connector

The SiI9437 is the preferred audio-only receiver because its public brief
describes eARC/ARC reception, an eARC discovery/control channel, I2C control,
four I2S outputs, and an IEC 60958 output. The public brief also describes up to
eight-channel, 24-bit, 192 kHz transport capability. Those transport limits do
not authorize V1 to advertise decoders that do not exist.

The DB layout shall:

- use an HDMI-approved connector applicable to the licensed design;
- place receiver, prescribed common-mode/ESD components, and connector as a
  compact vendor-reviewed block;
- route eARC differential signals at the impedance, loss, skew, and reference
  plane required by the licensed reference design;
- connect DDC/CEC/HPD/5 V detection and every unused connector signal exactly
  as required by the licensed implementation, not by guesswork from a public
  pin summary;
- bond the connector shell to chassis at entry with the reviewed high-frequency
  return network (`EMC-001`); and
- place accessible link-status and bus test points without creating stubs on
  sensitive high-speed nets.

The ADV7671A is retained only if the product later needs a full video
transceiver. Its official page says purchase/sample access requires HDMI 2.1
and HDCP 2.x adopter status. Adding it would also add high-speed video lanes,
HDCP/key handling, API integration, power, BGA/LFCSP layout, and compliance
scope that an audio-only receiver avoids.

### 4.2 Capability and control policy

Capability data shall be generated from one versioned table shared by receiver
firmware and UI. Automated tests decode that table and fail if it advertises a
format absent from the audio router (`EARC-004`). Initial capability:

```text
channels:       2
encoding:       LPCM
word lengths:   advertise only receiver/ASRC/router combinations tested
sample rates:   32 / 44.1 / 48 / 88.2 / 96 / 176.4 / 192 kHz as qualified
compressed:     none
multichannel:   none
```

ARC fallback is a separate tested state. If a TV exposes only legacy ARC, V1
accepts the stereo PCM subset proven with that receiver. The UI reports
`eARC`, `ARC`, `no link`, `unsupported format`, or `receiver fault` rather than
presenting all failures as silence.

CEC or receiver-supported control messages may request volume, mute, standby,
or active source (`EARC-007`). They enter the same event queue as the physical
dial, touchscreen, and any future network/radio transport. No source writes
FPGA gain registers directly.

### 4.3 Clock boundary and ASRC

The TV/eARC receiver is an asynchronous audio source. Its I2S clocks enter only
the source side of the SRC4392-class boundary. The ASRC output is subordinate
to the local 48 kHz audio clock. This arrangement:

- prevents TV clock ppm error from filling or emptying a finite audio FIFO;
- attenuates incoming sample-clock jitter before the physical model and DAC;
- lets the phono ADC and DAC remain synchronous; and
- makes the FPGA model operate at one calibrated external rate.

A plain asynchronous FIFO is not a rate converter and is not accepted as the
steady-state clock-drift solution. The selected ASRC must be measured for pass
band, alias rejection, idle tones, THD+N, group delay, ratio-change transients,
lock time, and mute behavior. The AD1896 remains a pin-programmed alternate if
the SRC4392 host/control complexity proves unnecessary.

The ASRC output feeds the FPGA as stereo 24-bit I2S at local 48 kHz. A bypass
relay in firmware is permitted only when input and local clocks are proven
synchronous and the transition occurs under mute. Normal eARC operation keeps
ASRC enabled.

### 4.4 TV latency and diagnostics

DB exposes at least (`EARC-006`):

- connector 5 V/HPD state;
- receiver reset/boot/API version;
- discovery result and eARC versus ARC mode;
- capability exchange completion;
- incoming coding type, word length, channel count, and measured sample rate;
- I2S framing error, receiver interrupt/fault, and CEC error counters;
- ASRC lock, ratio class, input/output mute, and overflow/underflow evidence;
- source-to-DAC sample count and measured analog latency; and
- the last rejected-format reason.

Provide a user TV-delay control after ASRC and before master volume. Initial
storage reserves 0–250 ms in 1 ms user steps, but the actual range and step are
frozen only after memory sizing and lip-sync tests. Changing delay is
cross-faded or performed while muted; it may not drop/duplicate a sample
without an explicit discontinuity diagnostic.

## 5. Audio clocks and reset domains

The local clock family is based on a low-phase-noise 24.576 MHz or 12.288 MHz
audio oscillator. The selected FPGA plan derives the exact fabric and internal
sample enables documented in `adc_dac.md`; no fractional PLL approximation is
accepted without measured jitter and rate error. The current Nexys path uses
12.288 MHz MCLK, 3.072 MHz BCLK, 48 kHz LRCLK, 49.152 MHz fabric, and a 384 kHz
model enable.

Clock ownership:

| Domain | Owner | Crossings |
|---|---|---|
| local audio serial | DB oscillator/FPGA clock leaf | AB ADC in, OB DAC out, ASRC output |
| FPGA fabric | DB FPGA clock manager | clock enables only for model/resampler |
| eARC input audio | TV through eARC receiver | terminates at ASRC input |
| front-panel control | FP MCU | oversampled SPI plus explicit IRQ/heartbeat synchronizers |
| touch/encoder/motor | FP MCU timers/GPIO | never enters FPGA as raw edges |
| power supervisor | PB asynchronous logic | fail-safe static inputs and qualified synchronizers |

Every reset asserts asynchronously where required for safety and releases
synchronously in the owning domain (`CLK-002`). Startup order is:

1. PB asserts hard analog mute and holds main reset.
2. Standby and monitored rails become valid.
3. Local oscillator and FPGA configuration become valid.
4. FPGA rate monitors acquire lock; ADC, ASRC, and DAC remain muted/reset.
5. Control firmware identifies every board and checks compatible versions.
6. Converter configuration and readback complete.
7. ADC/DAC calibration commits as a muted atomic pair.
8. Model state initializes at its DC operating point and consumes stable frames.
9. Digital output ramps from zero.
10. OB analog mute releases last.

Shutdown reverses the audible portion: analog mute first, digital ramp/reset
second, rails last. Brownout and watchdog faults jump immediately to analog
mute (`PWR-003`).

## 6. FPGA and memory architecture

The current `XC7A200T-SBG484` implementation is a prototype sizing baseline,
not a production-package freeze (`FPGA-002`). It openly routes the mono 384 kHz
phono top using 217 DSP48E1 blocks and has not yet proven stereo or a complete
amplifier. Before DB schematic freeze:

- synthesize and place/route the exact stereo product hierarchy;
- include eARC router, stereo ASRC interface, delay RAM, source crossfades,
  volume, control, diagnostic snapshots, configuration, and both audio ports;
- reserve measured headroom for the selected full-amplifier milestone rather
  than assuming unused headline resources are routable;
- generate switching activity and size the core/auxiliary regulators and
  thermal path from measured implementation data; and
- retain the exact open-source tool/database revisions and reproducible
  bitstream manifest.

DB provides nonvolatile configuration flash supported by the open programming
flow, JTAG pads/header, a recoverable golden image or external recovery path,
board ID EEPROM, and sufficient block/external memory for TV delay and future
model assets. External memory is outside the real-time solver unless its worst
case latency is bounded.

The current protocol-neutral 32-bit register bus remains the audio control ABI.
FP receives no direct internal-node write access outside labeled creative or
service modes. Runtime counters include saturation, solver residual failure,
iteration count, deadline miss, FIFO errors, converter clipping, invalid
control commit, rate/link fault, and mute cause (`FPGA-003`).

## 7. Front-panel display and touch

The baseline display is 5-inch, 800 x 480, IPS, capacitive touch, and 24-bit
parallel RGB (`UI-001`). The candidate Newhaven module's official product page
identifies a 900-nit backlight, FT5426G I2C touch controller, cover glass,
3.3 V logic, and EMI-shielded FPC. The production build shall add:

- MCU LTDC output with series damping selected from edge-rate/SI measurements;
- local framebuffer in at least 16 MiB SDRAM, with 32 MiB preferred;
- QSPI asset/firmware flash sized after UI assets are frozen;
- backlight constant-current driver with >25 kHz PWM or measured DC dimming;
- ambient-light input and a user-set maximum brightness;
- touch interrupt/reset, ESD protection, and production calibration;
- a shield/back plate bonded through the intended chassis return; and
- a replaceable FFC/interposer arrangement that does not require replacing DB.

The front-panel MCU renders the display (`UI-002`). The FPGA neither scans
touch nor generates pixels. The screen shows source/link format, active model
and category (reference/variation/modern/creative), volume, mute, clock/link
faults, and a diagnostics page. It never hides an unsupported TV format behind
a generic spinner.

The LCD is not a safety interface. Mute, standby, and volume remain usable when
the display cable is disconnected. Touch targets are sized for finger use,
critical destructive actions require confirmation, and reference-mode changes
remain visibly labeled.

## 8. Physical controls

The proposed front-panel control set is:

| Control | Mechanical function | Electrical function |
|---|---|---|
| volume | large 50 mm-class aluminum dial, smooth rotation, motor follow | absolute position request, never analog audio |
| source/select | premium detented optical encoder with push | source selection and confirm |
| model | premium detented optical encoder with push | reference model/variation selection |
| parameter | premium detented optical encoder with push | context-sensitive parameter, balance, or tone function |
| mute | dedicated illuminated momentary button | MCU event plus independent hard-mute request path |
| standby | dedicated button | PB-supervised standby request |

Grayhill 62H and Bourns EM14 are current encoder candidates (`UI-003`). Both
offer metal shaft/bushing optical construction; published configurations and
life differ. Order multiple detent/torque samples and perform a blind tactile
trial with the final knob inertia. The electrical design provides Schmitt
inputs, pull resistors per manufacturer guidance, ESD protection at panel
cables, hardware timer decoding where available, and impossible-transition
counters.

Knob shafts must be panel supported. Encoder/volume bushings locate the control
but do not carry cantilever loads from a heavy cosmetic knob. The volume
assembly uses a front bearing or supported coupler, anti-rotation structure,
and serviceable connector (`MECH-002`).

## 9. Motorized volume system

### 9.1 Signal ownership

There is one authoritative `volume_target` in signed decibels. Physical,
touchscreen, CEC/TV, optional network/radio, and restore-on-boot events are
serialized by the front-panel MCU. The MCU commits target plus monotonic
sequence number to the FPGA. The FPGA applies click-free gain outside the
reference model and returns the accepted sequence/effective gain. Only the
accepted effective gain drives the motor target and display (`VOL-005`).

Suggested UI mapping is -96 dB through 0 dB with a distinct hard-mute state.
User steps may be 0.5 dB while internal gain and remote ramps use finer
resolution. The exact law is frozen after listening and level-resolution tests,
but it remains a modern output control and cannot modify tube operating points.

The FPGA endpoint is now implemented as `rtl/audio/master_volume_ramp.sv`.
It accepts unsigned Q0.31 linear gain, reserves `0x7fffffff` as an exact-unity
sentinel, rejects values with bit 31 set, and slews a new target in at most
2^10 accepted 48 kHz samples (21.33 ms by default) using a shift/round-up
operation rather than hardware division. Stereo samples use full 64-bit
products and symmetric round-to-nearest, ties away from zero. Silence and unity
bypass the multiplier exactly. The primitive is outside the historical model
and is not yet integrated into the mono Nexys board top.

Warning-free directed/randomized RTL simulation covers mid-ramp retargeting,
positive/negative rounding, independent stereo samples, silence, exact unity,
and invalid-target retention. Yosys out-of-context XC7 synthesis reports 312
estimated logic cells, 151 flip-flops, eight DSP48E1 blocks, no BRAM, and zero
structural problems or warnings. This is not placed timing or stereo product-
hierarchy evidence.

### 9.2 Position sensor and prototype mechanism

For the PRM16 prototype, one resistive section is excited from the filtered MCU
ADC reference and read ratiometrically; the second section may be used for
plausibility or left available for evaluation. Neither section carries audio
(`VOL-002`). Production may replace it with a supported shaft, absolute
magnetic/optical angle sensor, and back-drivable gearmotor if that produces
better feel and life.

At manufacturing calibration, the MCU learns safe low/high endpoints, maps the
usable span to volume, and stores values with CRC plus board serial number.
Endpoint calibration is clamped inside mechanical stops and may not be run by
normal users.

### 9.3 Servo and motor driver

The DRV8874-class H-bridge receives a separately filtered motor rail, 25 kHz or
higher PWM, direction/enable, sleep, current-limit setting, proportional
current feedback, and fault feedback (`VOL-003`). The motor rail and return go
directly to PB/FP power entry rather than through touch/display ground traces.
The MCU ADC samples position and motor current synchronously to PWM blanking.

The first concrete PCB artifact is the separate
`hardware/kicad/front_panel_motor_eval_rev_a` daughterboard. It implements this
motor/position boundary without any audio nets, labels eight bring-up points,
and has a checked open route with zero KiCad 10.0.5 ERC/DRC/unconnected items.
It is intentionally narrower than the eventual FP board: it qualifies the
driver, mechanism, current telemetry, motor cable, and position sensing before
placing those aggressors beside the LCD MCU. Its current threshold, PTC/TVS,
connector release, and PowerPAD thermal-via implementation remain EVT
decisions; the clean CAD checks are not electrical or production validation.

The servo shall implement (`VOL-004`):

- position-dependent speed so large remote moves are quick and the final
  approach is quiet;
- a deadband that removes hunting and leaves the bridge in coast/sleep;
- soft endpoints inside calibrated hard stops;
- a bounded movement timeout and accumulated motor-on-time diagnostic;
- current-limited stall detection with immediate coast, latched fault, and UI
  report;
- reversal dead time and command slew;
- local manual movement detection while the bridge is idle;
- manual override/current rise handling while driven; and
- no automatic retry against a mechanical stop.

The mechanism-independent portion is now implemented in
`firmware/front_panel/volume_servo.c` with a warning-as-error host regression.
It explicitly retains command intent through reversal dead time; without that
state, the idle-manual detector can mistake a pending remote reversal for a
back-driven knob and cancel it. The core is not a physical motor validation or
an STM32 peripheral implementation. PWM timing, ADC/current filtering, grip
detection, and exact tick parameters are closed on the FP prototype.

The motor is normally unpowered. Grabbing the dial must not expose unsafe
torque or cause the control loop to fight continuously. A production prototype
should evaluate a capacitive grip electrode or clutch if current-limited
back-drive does not feel natural.

### 9.4 Motor acceptance

Prototype Bourns/Alps-class motor pots commonly publish roughly 15,000-cycle
life. Therefore the production assembly must complete at least 100,000
full-range remote cycles under representative knob inertia and enclosure
temperature, followed by position-linearity, backlash, acoustic-noise, stall,
and manual-feel checks (`VOL-006`). The test logs motor current and travel time
to identify wear trends. This is a design qualification requirement, not a
claim that the current candidate passes it.

## 10. Remote-control architecture

Remote operation is additive:

- CEC/TV control through the selected eARC receiver when supported;
- optional wired Ethernet through a separately allocated SPI bridge/module or
  a future MCU/package revision; the Rev-A LTDC/FMC allocation cannot route
  the STM32H753 RMII pins;
- optional certified Wi-Fi/BLE module, isolated from the phono zone and able
  to be depopulated or disabled; and
- USB-C service/configuration with no requirement for a cloud account.

All transports call the same settings API. Authentication is mandatory on IP
control, remote access is disabled by default until commissioned, and network
services bind only as configured. Firmware update uses signed images, an
anti-rollback policy appropriate to release state, and a recovery image or
physical recovery path (`FW-001`). Audio remains locally usable without any
network (`UI-006`).

Hardware revision, FPGA ABI, UI firmware, eARC firmware/API, converter setup,
and model asset versions are reported together. Incompatible combinations stay
muted and show a precise error (`FW-002`).

## 11. Power architecture

The line-level product accepts a locking external DC input from a certified
supply. A 24 V distribution voltage is preferred because it supports efficient
distribution and future line-driver headroom, but connector, input range, and
wattage are frozen only after measured FPGA/display/motor load and 30% design
margin are available.

Preliminary rail tree:

```text
external DC
   |
   +-- always-on standby -> supervisor / power button / hard mute
   |
   +-- digital preregulator -> FPGA core / auxiliary / I/O post-regulators
   |                       -> eARC receiver rails
   |                       -> ASRC and digital clock rails
   |
   +-- UI preregulator ------> MCU / SDRAM / QSPI / touch
   |                       -> constant-current LCD backlight
   |
   +-- motor rail -----------> current-limited H-bridge (normally asleep)
   |
   +-- low-noise analog -----> AB ADC/front-end local post-regulators
                           -> OB DAC/line-driver local post-regulators
```

Motor, backlight, FPGA, converter digital, converter analog, phono analog, and
line-driver rails are separate at the impedance-sensitive level (`PWR-002`).
This does not mean arbitrary split grounds. Each board uses a continuous local
reference plane, deliberate connector returns, and controlled chassis/signal
bonding. Switching nodes remain compact and outside the phono enclosure zone.

Every rail has design-min/max load, startup monotonicity, soft start,
sequencing dependency, ripple/noise mask, test point, and fault response before
schematic release. FPGA rail current comes from a post-route activity-based
estimate with margin and is verified on hardware; headline typical current is
not adequate.

## 12. Grounding, EMC, and physical layout

### 12.1 Chassis and signal reference

- Conductive chassis panels bond at low impedance; paint/anodizing is removed
  or pierced at designated bonds (`MECH-001`).
- HDMI shell, USB shield, Ethernet magnetics/shield, XLR pin-1/shield, and ESD
  return at their entry zones, with the exact DC/RF bond selected in EMC test.
- Turntable ground gets a dedicated binding post adjacent to phono RCAs and a
  documented connection to chassis/signal reference.
- Phono RCA grounds do not carry display, motor, eARC, or DC-input currents.
- Balanced internal audio is preferred when a cable leaves a board.
- Board-to-board connectors assign return pins beside each fast clock/data
  group and do not share one remote ground pin for high-current and phono
  returns.

### 12.2 Noise zoning

The AB board gets a shielding can or compartment. HDMI/eARC, FPGA clocks,
configuration flash, display RGB, backlight switch node, radio antenna, and
motor/motor cable remain outside it (`EMC-002`). Motor wires are a close
twisted pair with local suppression selected after motor emissions testing.
Backlight and motor PWM run above the audio band, but frequency placement alone
does not prove absence of intermodulation (`EMC-003`).

Worst-case phono tests exercise full-white/display-pattern changes, maximum
backlight PWM, optional network traffic, radio transmit, FPGA stress activity,
repeated motor moves, and eARC link changes individually and together
(`TEST-003`).

### 12.3 ESD/RF

External ports use protectors selected for the port impedance and capacitance.
Protection returns to chassis before sensitive traces. The MM protector's
capacitance is measured and counted in selectable cartridge load. The exact
eARC protector and common-mode parts come from receiver reference/compliance
guidance. Pre-compliance includes contact/air ESD, EFT on the DC input where
applicable, conducted/radiated emissions, RF immunity, and graceful recovery.

## 13. Connectors and service access

Rear-panel baseline:

- 1 x approved Type-A TV eARC/ARC connector;
- 2 x phono RCA plus turntable ground post;
- 2 x balanced line outputs, with 2 x RCA line outputs preferred;
- locking DC power input;
- 10/100 Ethernet where fitted;
- USB-C service/configuration, explicitly not assumed to be USB-PD power;
- optional 12 V trigger in/out after protection review; and
- an expansion connector for a future clean power amplifier, carrying
  differential audio, mute, fault, standby, and low-current control—not raw
  speaker current through the line-level stack.

Internal connectors are keyed, locking, and pin-staggered where sequencing
matters. AB/OB audio clock and data connectors include local grounds and reset/
fault lines. FP control includes SPI, IRQ, heartbeat, and hard-mute request.
PB supervisory lines are electrically valid when destination rails are absent.

Production JTAG/SWD/UART and rail test pads remain accessible after assembly
but may require an authenticated/service fixture. Each board includes a read-
only identity/calibration EEPROM or equivalent (`TEST-001`).

## 14. Control plane and settings integrity

`IF-CTRL-FP-DB` carries the existing protocol-neutral register transactions
through SPI. FP is SPI main; DB oversamples the raw input in the fabric clock
and reports frame/underflow errors. Production timing is set below the placed
oversampling limit with at least the documented margin.

Settings update rules:

- active audio parameters use shadow/commit semantics;
- state-disruptive model/rate/source changes ramp down, reset or cross-fade,
  warm up, and ramp up;
- ADC/DAC calibration changes only while muted and commits atomically;
- reference mode exposes only values belonging to the frozen model;
- modern/creative settings carry their category in register snapshots and
  saved presets; and
- control sequence, source, volume, mute cause, model version, and diagnostic
  snapshot are captured with every hardware-comparison recording.

The UI heartbeat is not used as a high-frequency audio command. Its timeout and
safe action are explicit. A UI reboot cannot send uninitialized zeros as valid
configuration (`UI-005`).

## 15. Safety, mute, and fault behavior

There are three mute layers:

1. FPGA sample-domain ramp for click-free normal operations;
2. DAC mute/configuration state; and
3. independent OB/PB analog mute, asserted by hardware default.

Master volume precedes the safety mute ramp. A unity master setting is
bit-transparent; safety mute retains authority regardless of the user target.

The dedicated front mute button requests both normal digital mute and a direct
hardware-safe path. Normal user action may ramp before opening the analog path;
a rail, clock, watchdog, overtemperature, DC, or control-integrity fault asserts
hardware mute immediately (`UI-004`, `SAFE-001`).

Fault state is latched with a cause and cannot silently clear merely because a
clock returned. Recovery verifies rails, clocks, receiver/converter state,
model initialization, calibration, and digital zero before controlled unmute
(`SAFE-002`).

If a later physical speaker amplifier is installed, dedicated hardware owns
speaker DC disconnect, overcurrent, overtemperature, and power-stage fault.
FPGA/UI diagnostics may observe or request protection but cannot be the only
protector (`SAFE-003`).

## 16. Thermal and mechanical design

The target is fanless line-level operation at the specified ambient. DB uses a
four-or-more-layer stackup appropriate to the FPGA/eARC SI and power planes;
the exact layer counts of AB and OB are selected from noise and manufacturing
review rather than forced to match DB. FPGA thermal vias/spreader and chassis
coupling are sized after placed-design power estimates and verified with
thermocouples or calibrated thermal imaging.

Temperature sensors cover FPGA vicinity, eARC/ASRC area, phono compartment,
line driver, regulator hot spots, display enclosure, and any later power stage.
Firmware exposes temperatures and maximums; PB supplies an independent critical
shutdown where required.

The display mounts without FPC strain and is replaceable. The front glass and
metalwork do not load the LCD active area. Knobs have controlled panel gaps,
ESD paths, and replaceable couplers. Board removal does not require disturbing
the phono input wiring unless AB itself is serviced (`MECH-001`).

## 17. Manufacturing and calibration

Each board records:

- product/board ID, assembly revision, serial, and manufacture date;
- BOM variant and fitted options;
- bootloader/application/API compatibility versions;
- ADC/DAC scale and DC offset calibration;
- volume endpoint/linearity calibration;
- phono capacitance/gain variant and measured input capacitance; and
- final test result hash or database key.

Factory sequence:

1. boundary-scan/short/open and rail-current test;
2. program recovery, FPGA, UI, receiver, and board identity;
3. verify every rail, reset, oscillator, and supervisory fault;
4. calibrate volume endpoints and exercise servo/stall response;
5. configure eARC analyzer modes and verify capability data;
6. calibrate converter gains under mute;
7. run stereo digital/analog loopback, crosstalk, noise, gain, phase, THD+N,
   clipping, and mute transient tests (`TEST-004`);
8. run phono cartridge-emulator loading/noise/gain tests;
9. save coherent FPGA diagnostics and firmware versions; and
10. complete button, touch, display, encoder, network, and standby test.

Calibration never edits reference-model constants to conceal analog hardware
error. Converter calibration maps PCM to physical volts; model changes remain
versioned assets.

## 18. Verification and acceptance matrix

These are design targets until measured reports are committed.

| Subsystem | Required evidence before DVT release |
|---|---|
| eARC | analyzer discovery/capability/PCM sweep; ARC fallback; CEC volume/mute where implemented; link interruption/recovery; at least five TV families from multiple vendors; finished-product compliance (`TEST-002`) |
| ASRC | 32–192 kHz supported-rate matrix; 24-bit stereo; passband and stopband; THD+N and residual spectrum; lock/group delay; ppm offset; rate change and unplug transient |
| phono | exact 47.5 kilohm and installed capacitance; 20/26/32 dB gain; cartridge-emulator sweep; overload; input-referred noise; hum/RF/ESD recovery |
| converters/output | at least 115 dB(A) target dynamic range at 2 V RMS class, output noise below 4 microvolt RMS target, gain/phase/crosstalk, line-load drive, THD+N, DC, clipping and reconstruction spectrum |
| FPGA | stereo bit-accurate regressions, open synthesis/P&R/bitstream, no deadline miss, resource/power report, clock/CDC review, hardware capture versus fixed model (`SYS-003`) |
| UI | 24-hour animation/touch stress, unplug/reset behavior, backlight thermal/EMI test, all operations possible without network, safety controls with LCD disconnected |
| motor volume | endpoint/stall/manual override, target/effective-position coherence, acoustic noise, conducted/radiated coupling, 100,000-cycle production qualification (`VOL-006`) |
| system noise | phono and line noise with every aggressor idle and worst-case active; no hidden mute during test (`TEST-003`) |
| power/mute | cold/hot plug, rapid cycling, brownout, stuck clock, receiver/MCU/FPGA reset, invalid firmware, unplugged board, and output transient capture |
| EMC/thermal | pre-compliance emissions/immunity/ESD and worst-case ambient steady state before formal certification |

For the motor/display aggressor test, record both integrated input-referred
phono noise and spectra. A threshold is frozen after quiet-board baseline data,
but any deterministic spur or audible transient correlated with motor/backlight
activity is a release failure requiring root-cause analysis—not a candidate for
masking with digital noise or reference-model changes.

## 19. Development sequence

### EVT-0 — evaluation interconnect

- Obtain receiver/vendor access and eARC evaluation hardware.
- Evaluate SiI9437 versus any current supported successor before schematic
  commitment.
- Compare SRC4392 and AD1896 evaluation paths with asynchronous TV/audio clocks.
- Bring up STM32H753-class MCU, selected LCD/touch, optical controls, PRM16, and
  DRV8874 on a front-panel bench harness.
- Implement the authoritative volume event/servo state machine and instrument
  current, position, faults, and travel time.

### EVT-1 — first board set

- Spin FP and PB first because their interfaces are stable and their emissions
  can be characterized against the existing FPGA platform.
- Spin AB/OB from the completed analog requirements and converter evaluation.
- Keep eARC as a receiver mezzanine on the first DB if vendor/supply risk is not
  fully closed; do not contaminate every DB revision with an uncertain IC.
- Run full aggressor/noise and analog loopback characterization.

### EVT-2 — integrated digital board

- Integrate the selected eARC receiver only after licensed reference review.
- Route the exact stereo FPGA image with production I/O/package constraints.
- Complete multi-vendor TV, ASRC, CEC, latency, and recovery tests.
- Produce compliance-intent enclosure, grounding, and connector layout.

### DVT/PVT

- Close formal compliance, environmental/ESD/EMC, thermal, life, safety, and
  production-test coverage.
- Freeze component alternates only after electrical and firmware compatibility
  evidence.
- Publish measured rather than estimated performance.

## 20. Open issues

- Current mono RTL must become stereo and be openly placed/routed before DB
  FPGA/package freeze (`SYS-003`).
- SiI9437 lifecycle, access terms, current receiver successor, and full eARC
  software/reference package must be confirmed (`EARC-001`, `EARC-008`).
- SRC4392 versus AD1896 requires evaluation measurements, especially ratio
  change and mute/relock behavior.
- Production ADC/DAC parts remain deliberately unfrozen in `adc_dac.md`.
- PRM16 is a prototype mechanism; production volume feel/life is a mechanical
  development project, not a BOM assumption (`VOL-006`).
- Exact remote transport, antenna, and cybersecurity maintenance policy remain
  to be selected; offline local operation is the baseline, while Rev-A direct
  MCU Ethernet has been rejected by the frozen pin-conflict audit.
- Enclosure dimensions, display viewing angle, knob spacing, and thermal path
  require industrial-design mockups.
- Numeric EMC, environmental, motor-coupling, and mute-transient limits must be
  frozen from EVT baseline data and applicable market standards.

## 21. Requirement traceability

The normative requirement records are machine checked from
`hardware/product_v1/requirements.json`. IDs covered by this specification are:

```text
SYS-001 SYS-002 SYS-003 SYS-004
EARC-001 EARC-002 EARC-003 EARC-004 EARC-005 EARC-006 EARC-007 EARC-008
CLK-001 CLK-002
PHONO-001 PHONO-002 PHONO-003
CONV-001 CONV-002 CONV-003
FPGA-001 FPGA-002 FPGA-003
UI-001 UI-002 UI-003 UI-004 UI-005 UI-006
VOL-001 VOL-002 VOL-003 VOL-004 VOL-005 VOL-006
PWR-001 PWR-002 PWR-003
EMC-001 EMC-002 EMC-003
SAFE-001 SAFE-002 SAFE-003
MECH-001 MECH-002
TEST-001 TEST-002 TEST-003 TEST-004
FW-001 FW-002
```

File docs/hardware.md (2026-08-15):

# FPGA and synthesis baseline

## Reference development platform

The provisional FPGA is the Digilent Arty A7-100T (XC7A100T). It offers roughly
101,440 logic cells, 240 DSP48E1 blocks, and 4,860 Kib of block RAM. It is widely
available and Project X-Ray contains the exact `xc7a100tcsg324-1` database, but
has no precision audio converter on board; a short, controlled-interface
converter daughterboard is required. Core RTL stays device-neutral and Xilinx
primitives are not used in the tube module.

The required Linux implementation flow is fully open source: Yosys produces
the XC7 JSON netlist and nextpnr-Himbaechel performs packing, placement, and
routing against Project X-Ray data. The upstream nextpnr project labels its
7-series backend experimental. At the pinned revision it imports timing data
under a single `DEFAULT` grade rather than identifying XC7A100T-1, so a routed
frequency result is valuable engineering evidence but is not mislabeled as a
certified `-1` speed-grade limit. `scripts/bootstrap_openxc7.sh` builds the
pinned backend without root access; `make openxc7-probe` records the installed
versions and database. No Vivado step is part of the required flow.

`run_openxc7.py --pack-only` records exact named-part packing and utilization
without claiming placement or timing. `--place-only` continues through
placement, writes a separate placed netlist/log/report/summary, and records
placement Fmax without claiming a route. These stages exist for candidates
whose congestion makes the next implementation step impractical or whose
placement miss is too large to justify a long router run.
`analyze_openxc7_placement.py` groups a flattened placed JSON by the major
solver blocks and reports resource counts, bounding boxes, and hard-block
centroids. These diagnostic artifacts remain generated; their measured
conclusions are recorded here.

## First named-part placement diagnosis

`solver_pnr_harness` wraps the complete 127-clock
trapezoidal/banked/terminal solver with an internal deterministic stimulus and
a one-bit registered signature. Only the Arty oscillator, one button, and one
LED are package pins, so wide debug buses cannot distort the I/O requirement.
Yosys 0.66 measures the harness at 14,967 estimated logic cells, 6,372
flip-flops, 174 DSP48E1s, eight RAMB18E1s, and one RAMB36E1. The open XC7
packer expands this to 50,789 `SLICE_LUTX` elements, including 29,653 LUT1s,
plus 3,770 CARRY4s and the same DSP/RAM count.

With seed 1, one thread, router2, and a 98.304 MHz request, nextpnr commit
`4d23515` reports only 13.90 MHz after placement. This is an experimental
`DEFAULT`-grade estimate, not a qualified -1 speed result, but the 7.07x miss is
too large to treat as a signoff nuance. The value-only tube substitution later
placed at 13.67 MHz despite its isolated 113.24 MHz result. That controlled
experiment falsifies the initial hypothesis that cubic Hermite is the dominant
complete-solver path. The historical circuit and numerical tolerances are not
changed to hide this timing failure. Router2 completion and post-route
critical-path extraction remain in progress for both full baselines.

### Bit-exact Hermite timing experiment

`hermite_q16_pipeline` preserves the factorized tube's exact cubic-Hermite
Horner arithmetic: signed 32-bit state wraps at the same boundaries, each
32-by-17-bit product is retained at 49 bits, and add-half arithmetic-shift
rounding is unchanged. It accepts one request while idle and emits the result
three clocks later, ignoring starts while busy. The test covers 4,096
deterministic directed/random full-range input tuples plus in-flight reset; the
existing 4,110-vector complete tube regression also remains exact.

Out-of-context Yosys synthesis reports 265 estimated logic cells, 198
flip-flops, two DSP48E1s, no RAM, no warnings, and no structural problems. The
three-pin `hermite_pnr_harness` packs to 886 `SLICE_LUTX`, 231 `SLICE_FFX`, 49
CARRY4, and two DSP48E1s. With the same part, XDC, seed, router, and 98.304 MHz
request as the solver baseline, routing completes in seven router2 iterations
and reports 132.54 MHz post-route. This demonstrates that the separated kernel
meets the open backend estimate; it does not establish qualified -1 timing or
complete-solver closure.

The kernel is intentionally not wired into the accuracy-first tube yet. The
three physical table evaluations are serially dependent, and the reciprocal
and softplus results each feed another multiplication. A direct substitution
therefore consumes more than the existing eight-clock tube contract and, when
repeated across solver passes, exceeds the 127-clock internal-sample deadline.
The next architecture step must budget those dependencies explicitly instead
of trading away the reference law or silently lowering oversampling.

### Value-only eight-clock tube candidate

`triode_12ax7_factorized_linear` takes a different, separately error-bounded
route: it spends memory on 1,024/8,192/4,096 value-only tables so each scalar
interpolation has one product, while preserving the original eight-clock tube
and 127-clock complete-solver schedules. Out-of-context Yosys reports 642
estimated logic cells, 27 DSP48E1s, 13 RAMB18E1s, and five RAMB36E1s. The
three-pin tube harness packs to 2,630 `SLICE_LUTX`, 373 `SLICE_FFX`, 246 CARRY4,
the same DSP/RAM count, and routes at 113.24 MHz against 98.304 MHz. As with all
current nextpnr-XC7 results, this is an experimental `DEFAULT`-grade estimate.

The complete accuracy-first terminal solver remains bit-exact to its matching
Python candidate at 127 clocks. Its named-part synthesis measures 14,140
estimated logic cells, 6,282 flip-flops, 166 DSP48E1s, 13 RAMB18E1s, and five
RAMB36E1s; packing expands it to 49,530 `SLICE_LUTX` and 3,710 CARRY4. This is
eight fewer DSPs and 1,259 fewer packed LUT elements than the Hermite harness,
at the cost of additional RAM. Placement reaches only 13.67 MHz, statistically
indistinguishable from and slightly below the Hermite solver's 13.90 MHz.
Therefore it is not a whole-solver timing solution and is not promoted to the
reference/default implementation. Full routing remains in progress only to
extract the detailed path and congestion evidence.

### Solver-block timing isolation

The ten simultaneous trapezoidal terminal-current recomputations are factored
into `terminal_current_update_v1` without changing their single-edge contract.
Both 512-vector solver regressions remain bit exact at 116 and 127 clocks. The
three-pin isolated harness measures 54 DSP48E1s, 5,442 packed `SLICE_LUTX`,
1,281 `SLICE_FFX`, and 612 CARRY4s. A literal serial overflow-count expression
initially limited post-route timing to 51.95 MHz. Replacing only that diagnostic
sum with an explicitly widened balanced popcount raises the measured result to
88.83 MHz. It still fails 98.304 MHz and does not claim full-solver closure,
but it converts a source-level suspicion into a measured, reproducible timing
target. The next experiment must separately route KCL and chord blocks, then
pipeline or reschedule the dominant physical paths without changing the V1
circuit law.

The isolated banked chord corrector uses nine DSP48E1s and routes at 46.40 MHz.
Its worst path is the final correction scaling, node subtraction, and
saturation commit, not the nine-cycle coefficient MAC itself. The original
wide trapezoidal KCL block uses 72 DSP48E1s and routes at only 16.64 MHz. Its
60.09 ns critical cone begins at a stored accumulator, performs the final tube
and capacitor-9 residual sum, propagates through the cross-row Q40/Q34/Q30
fallback decision, and ends at the saturated residual register. This matches
the whole-solver placement failure and establishes KCL as the primary limiter.

The first KCL correction captures invariant capacitor 9 on the first matrix
column and stages the complete physical residual when the second tube result
arrives. That edge was already an integrated-solver wait, so all 512 complete
solver vectors retain their exact 127-clock contract; a standalone request
with an early tube result now takes 11 rather than 10 clocks. Serial procedural
all-fit, maximum-residual, and saturation-count reductions were also replaced
with explicit balanced trees. All 1,024 backward-Euler and 1,024 trapezoidal
KCL vectors remain exact, including tube-result delays through 19 clocks. The
revised isolated KCL placement estimate improves from 14.95 to 33.92 MHz. A
router2 experiment reached 183 overused resources at iteration 57 before
diverging to 499 by iteration 114 and was stopped without a legal route. This
is a measured improvement, not timing closure, and the remaining gap requires
further staged arithmetic and a solver schedule that can absorb it.

### Parallel dual-triode schedule

The V1 circuit contains two physical 12AX7 sections whose currents depend only
on the candidate node-voltage vector for a solver pass. A selectable scheduling
mode therefore instantiates two identical factorized Hermite primitives and
launches both sections together. It does not share one result between stages,
alter the tube equations, or change any physical network state. Both the 512-
vector backward-Euler solver and the complete 512-vector trapezoidal/banked/
terminal solver remain bit-exact; their measured latencies fall from 116 to 84
clocks and from 127 to 95 clocks respectively. The latter recovers 32 of the
128 clocks available per 768 kHz sample for additional network pipelining.

Yosys 0.66 measures the complete parallel terminal harness at 15,887 estimated
logic cells, 7,360 flip-flops, 209 DSP48E1s, 16 RAMB18E1s, and two RAMB36E1s.
The comparable sequential harness after KCL restructuring is 14,354 cells,
7,000 flip-flops, 174 DSP48E1s, eight RAMB18E1s, and one RAMB36E1. Thus the
schedule recovery costs 1,533 cells, 360 flip-flops, 35 DSPs, and ten
RAMB18-equivalents while remaining below the XC7A100T's 240-DSP limit. The
parallel harness has a reproducible open-flow netlist but no placement or Fmax
claim yet. It is an implementation option, not a modern or creative circuit
mode.

### Bit-exact KCL and chord timing schedules

The recovered parallel-tube margin is now spent by three independent compile-
time schedule controls. KCL column products, rounded currents, and prior-column
accumulation overlap at one column per clock with two pipeline-fill clocks per
call. Two further KCL clocks separate physical-residual capture, fixed-point
format conversion, global fallback/diagnostic reduction, and saturation.
Finally, two clocks per chord separate scaled correction, updated-node/
diagnostic calculation, and saturation commit. All four nonlinear passes use
the same unchanged equations and arithmetic boundaries.

The pipelined chord is bit-exact across 1,024 vectors at 12 clocks rather than
10. Its isolated Arty-A7-100 harness routes legally at 100.92 MHz against the
98.304 MHz request, improving the original 46.40 MHz result. It uses nine
DSP48E1s and packs to 9,501 `SLICE_LUTX`, 2,865 `SLICE_FFX`, and 530 CARRY4s.
This is an experimental nextpnr `DEFAULT`-grade result, not qualified -1
speed-grade signoff.

The combined pipelined KCL remains bit-exact across 1,024 backward-Euler and
1,024 trapezoidal vectors at 15 early-current clocks rather than 11. A finish-
only candidate placed at 40.00 MHz, and a superseded one-stage column candidate
placed at 36.76 MHz. The selected two-fill-clock column pipeline plus finish
pipeline uses 72 DSP48E1s and packs to 32,006 `SLICE_LUTX`, 9,356 `SLICE_FFX`,
and 1,958 CARRY4s. Its initial 98.304 MHz placement reaches only 38.95 MHz. A
subsequent 40 MHz request routes legally in 25 router2 iterations and measures
42.07 MHz post-route. That route identifies four cascaded 63-bit comparisons
in the exact maximum-absolute-residual diagnostic as the critical path rather
than the physical accumulator.

The route-informed schedule adds a register before the accumulator feedback
and pipelines only the final solver pass's nine-row maximum diagnostic. Earlier
KCL passes bypass the three maximum clocks because the solver does not consume
that diagnostic until its final residual. The global Q30/Q34/Q40 fallback is
unchanged. Signed 25-bit fit is expressed as the exactly equivalent sign-
extension test on bits 62:24; Q34/Q40 saturation is known false after their
existing all-row fit qualification, so only the registered Q30 fallback needs
an overflow count. The standalone diagnostic-enabled KCL is bit-exact across
1,024 vectors per integration method at 19 clocks.

Successive legal routes measure 64.90 MHz after splitting the maximum tree,
72.31 MHz after moving Q30 overflow work before global selection, and 92.23 MHz
after using the exact sign-extension predicate. The selected seed-1 route packs
to 29,514 `SLICE_LUTX`, 10,436 `SLICE_FFX`, 1,814 CARRY4s, and 72 DSP48E1s. Its
10.84 ns critical path now forms a signed capacitor stamp and adds it to a
registered matrix current; 3.34 ns is logic and 7.50 ns is routing. It misses
the 98.304 MHz request by 6.6% under the experimental `DEFAULT` timing grade.
An algebraically collapsed one-adder source form was tested and rejected: it
placed at only 70.24 MHz and produced substantially worse router congestion.
The completed 92.23 MHz result remains the measured baseline.

The final maximum is a diagnostic, not an input to chord correction. A new
selectable schedule therefore emits the final correction after the first
maximum-tree boundary and completes the exact maximum on a separate
`max_valid` sideband two clocks later. The KCL engine remains busy until the
sideband commits, preventing a new request from overwriting its diagnostic
state. Both backward-Euler and trapezoidal tests remain bit-exact across 1,024
vectors: correction latency falls from 19 to 16 clocks while the maximum value
and its valid pulse remain exact. The integrated chord is already running
during those two clocks, so the complete solver falls from 126 to 123 clocks
without changing its output, state, or diagnostic counters. This leaves five
of 128 fabric clocks available for subsequent multiplier scheduling.

This schedule recovery is not timing closure. The isolated seed-1 harness uses
6,294 estimated logic cells and 72 DSP48E1s, packs to 29,569 `SLICE_LUTX`,
10,437 `SLICE_FFX`, and 1,814 CARRY4s, and routes legally at 87.07 MHz against
98.304 MHz. Its 11.48 ns critical path is a registered capacitor current
through the exact current-overflow comparison into the current-state result;
1.50 ns is logic and 9.99 ns is routing. A timing-weight-20 placement reaches
only 80.03 MHz, so its congested router run is deliberately not continued.
The complete 123-clock hierarchy packs to 59,188 LUTX, 13,459 FFX, 4,036
CARRY4s, and 209 DSPs, then places at only 31.97 MHz. These results keep the
decoupled schedule as cycle-budget infrastructure while rejecting it as a
standalone Fmax fix.

### KCL capacitor-multiplier sharing

The decoupled schedule permits a cycle-free reduction in simultaneous KCL hard
multipliers. On the accepting `start` edge, capacitor branch 9's exact Q0.47 by
Q30 product is formed directly from the request voltage and history buses and
captured before those buses are latched. The same explicitly muxed 48-by-44-bit
multiplier then serves branches 0--8 during the existing pipelined column
schedule. This removes one wide multiplier implementation, or nine DSP48E1s,
without changing a product, rounding boundary, state update, or latency.

Both 1,024-vector integration-mode KCL regressions remain bit-exact at the
16-clock correction latency with the exact maximum sideband two clocks later.
Yosys measures the isolated candidate at 6,422 estimated logic cells, 10,437
flip-flops, and 63 DSP48E1s instead of 72. It packs to 29,469 `SLICE_LUTX`,
10,437 `SLICE_FFX`, 1,783 CARRY4s, and 63 DSPs, but seed-1 placement reaches
only 72.95 MHz. Because this is below the 98.304 MHz request and the established
72-DSP KCL has already routed at 87.07 MHz under the same decoupled schedule,
routing is skipped. The candidate is an area result, not an isolated timing
improvement.

The complete solver remains exact for all 512 stateful vectors at 123 clocks.
Its structural result is 14,779 estimated logic cells, 13,459 flip-flops, 200
DSPs, 16 RAMB18E1s, and two RAMB36E1s. Default placement uses 58,885 LUTX,
13,459 FFX, 4,005 CARRY4s, and 200 DSPs and reaches 35.06 MHz, a small gain over
the otherwise matching 209-DSP decoupled hierarchy's 31.97 MHz. A controlled
timing-weight-20 placement instead falls to 29.05 MHz. Neither run justifies
routing or promotion as the timing architecture.

Composing this KCL sharing with the two-batch terminal-current engine removes
another 20 DSPs. The 180-DSP solver is bit-exact for 512 stateful vectors at
124 clocks and synthesizes to 14,975 estimated logic cells and 14,591
flip-flops. Default placement reaches 30.63 MHz; the existing overlapping
hierarchy floorplan and timing weight 20 reach 32.94 MHz while matching 36,180
KCL/RHS and 25,572 nonlinear cells. Both are slower than the prior 189-DSP
floorplanned candidate's 36.83 MHz. An attempted reuse of that floorplan for
the 200-DSP candidate over-constrained its larger nonlinear group and was
stopped before a timing result. Multiplier sharing is therefore retained as a
selectable, exact scheduling architecture, while the measured results direct
the next timing work toward broader registered data paths rather than DSP count
alone.

With parallel triodes, KCL column/finish/accumulator boundaries, the final-only
maximum pipeline, and chord-apply boundaries enabled, the complete trapezoidal/
banked/terminal solver remains bit-exact across 512 stateful vectors at 126
clocks, leaving two of the 128 clocks available per internal sample. Yosys 0.66
measures its harness at 14,990 estimated logic cells, 13,458 flip-flops, 209
DSP48E1s, 16 RAMB18E1s, and two RAMB36E1s. The structural check has zero
problems. A separately verified capacitor-current rounding boundary would use
127 clocks, but has not been promoted because the selected KCL route shows a
different limiter. This is a structurally fitting schedule, not timing closure:
the isolated KCL is still 6.6% short.

The complete 126-clock hierarchy packs to 59,027 `SLICE_LUTX`, 13,458
`SLICE_FFX`, 4,036 CARRY4s, 209 DSP48E1s, 16 RAMB18E1s, and two RAMB36E1s.
Seed-1 placement reaches only 34.20 MHz against 98.304 MHz, so routing is not
attempted. The result is reproducible with the placement-only target and is a
whole-design architecture failure, not a local KCL timing estimate.

Placed-hierarchy analysis explains why isolated-block results do not compose.
KCL's 72 DSPs span 91 by 202 device-coordinate units; its 36,090 placed cells
span nearly the full device. Terminal-current uses another 54 DSPs over a
31-by-182 hard-block region. The two exact tube engines each use 35 DSPs plus
eight RAMB18E1s and one RAMB36E1; their hard-block centroids are approximately
(98,104) and (52,39). Chord correction's nine DSPs center near (98,179).
Therefore the 209-DSP hierarchy necessarily crosses most available DSP rows and
columns. The next architecture decision must reduce simultaneous hard-block
occupancy, adopt a larger open-tool-supported target, or both; another isolated
KCL register alone cannot close the measured 2.87x full-placement gap.

### Terminal-current resource-sharing experiment

The first lower-simultaneous-hard-block candidate reuses five terminal-current
workers for lanes 0--4 and 5--9. The pipelined chord exposes its already
registered final node update one cycle before `valid`, allowing the first batch
to overlap that preview. The second batch and its exact saturation count are
registered, after which a dedicated terminal-commit state consumes the last
available internal-sample clock. This is a scheduling approximation only: all
rounding, saturation, terminal voltages, conductances, and current-history
subtractions remain unchanged.

A dynamic procedural lane index initially synthesized into wide mux trees. The
corrected implementation uses five explicit fixed lane-pair muxes and latches
only the second-batch inputs. The isolated candidate is exact against the
original all-lane arithmetic for 1,027 directed/random vectors. Its named-part
route uses 4,296 `SLICE_LUTX`, 2,412 `SLICE_FFX`, 334 CARRY4s, and 34 DSP48E1s,
reaching 90.50 MHz with the default heap timing weight under the experimental
`DEFAULT` grade. A second deterministic seed-1 route with heap timing weight 20
reaches 99.59 MHz and closes the 98.304 MHz isolated-block constraint. The
established all-lane block uses 54 DSPs and reaches 88.83 MHz, so sharing
removes 20 DSPs and can meet the isolated deadline when placement is instructed
to prioritize timing.

The complete selectable schedule remains bit-exact for all 512 stateful solver
vectors at 127 clocks. Yosys measures 15,072 estimated logic cells, 14,590
flip-flops, 189 DSP48E1s, 16 RAMB18E1s, and two RAMB36E1s. Packing reports
59,514 `SLICE_LUTX`, 14,590 `SLICE_FFX`, 3,964 CARRY4s, and 189/240 DSPs. Legal
seed-1 placement reaches only 25.02 MHz, worse than the 209-DSP schedule's
34.20 MHz, so routing is deliberately skipped and the candidate is not
promoted. Region analysis confirms terminal hard-block occupancy falls from 54
to 34 DSPs and its span contracts to 31 by 161 coordinate units, but KCL still
spans 60 by 202 and the full design remains globally dispersed. Reducing a
single hierarchy's DSP count is therefore insufficient by itself. The isolated
99.59 MHz result does not supersede the separately measured 25.02 MHz complete
hierarchy result.

A tagged timing-weight-20 placement raises the complete candidate to 32.56 MHz
but still misses 98.304 MHz by 66.9% and remains below the selected 209-DSP
schedule's 34.20 MHz default-weight result. That run packs 59,539 `SLICE_LUTX`,
14,590 `SLICE_FFX`, 3,964 CARRY4s, and 189 DSPs. Its terminal-current DSP region
actually expands to 91 by 167 coordinate units while KCL remains spread 60 by
197, so the timing preference does not create useful hierarchy locality.
Routing remains unjustified. The open-flow runner's `--run-tag` option retains
the netlist, placed design, logs, reports, and compact summary for tuning runs
without overwriting the untagged baseline evidence.

### Overlapping hierarchy-region experiment

The A100T exposes DSP columns at tile X coordinates 28, 88, and 119. A strict
left/right partition was over-constrained: forcing KCL plus RHS into 76 of the
left column's 80 DSP sites did not complete even its first heap iteration in
more than six minutes. That exploratory partition was stopped and is not a
timing result.

The retained V2 floorplan instead uses overlapping rectangular regions. KCL
plus RHS may use the left and center columns (76 of 160 DSP sites); the tube,
chord, and terminal-current blocks may use the center and right columns (113 of
160 sites). Solver control remains unconstrained. The pre-place hook matches
36,360 packed KCL/RHS cells and 25,574 nonlinear cells, proving the hierarchy
selectors are active after packing.

At seed 1 and timing weight 20, this placement reaches 36.83 MHz. It improves
the same candidate's unconstrained 32.56 MHz by 13.1% and the selected
209-DSP/default-weight baseline's 34.20 MHz by 7.7%, but still falls 62.5% below
98.304 MHz. KCL remains 60 by 197 hard-block coordinates, while the terminal
DSP span contracts from 91 by 167 to 31 by 161. Total annealed wire length falls
from 3,010,517 to 2,006,868 units. This validates explicit hierarchy placement
as a useful optimization, but its 2.67x remaining frequency gap requires a
broader arithmetic/scheduling change; routing is deliberately skipped.

### Soft KCL multiplier experiments

The KCL source contains eleven signed multipliers; their widths expand to 72
DSP48E1s in the selected isolated implementation. A reproducible Yosys branch
stops immediately before `map_dsp`, asserts that exactly those eleven `$mul`
cells exist under `network_kcl_v1_wide`, marks them for soft multiplication,
and then resumes the standard XC7 mapping flow. This is a technology-mapping
experiment: it changes neither RTL, fixed-point widths, rounding, saturation,
nor the 19-clock KCL schedule.

The isolated KCL maps from 72 DSPs to zero, but Yosys grows from the selected
implementation's compact hard-multiplier structure to 43,389 estimated logic
cells. Exact nextpnr packing consumes 71,592/126,800 `SLICE_LUTX`, 10,436
`SLICE_FFX`, and 1,843 CARRY4s. In the complete shared-terminal solver, KCL
softening reduces the DSP count from 189 to 117 but raises estimated logic from
15,072 to 51,475 cells. Exact packing consumes 101,479/126,800 LUT elements
(80%), 14,590 FFX, 3,993 CARRY4s, 117 DSPs, 16 RAMB18s, and two RAMB36s.

No Fmax is claimed. The isolated 56%-LUT candidate did not finish placement in
a useful diagnostic interval: the default run completed five analytical
iterations in about 7 minutes 20 seconds without reaching timing analysis, and
an eightfold tighter heap-attempt bound reproduced 81.39 and 77.29 second first
iterations because that option does not bound the dominant analytical phase.
Both exploratory placement runs were stopped. The retained `--pack-only` flow
finishes normally and labels placement/timing as incomplete. All-soft KCL is
therefore not promoted: it removes DSP pressure at the cost of severe LUT and
placement pressure. Partial multiplier sharing or a scheduled, explicitly
pipelined soft-multiply kernel remains a distinct future experiment.

A second mapping softens only the two 48-by-44-bit capacitor-current
multipliers, selected by cell type, hierarchy, and operand-width parameter with
an asserted count of two. The nine 41-by-40 matrix multipliers remain hard.
This removes 18 rather than 72 DSP48E1s. Isolated synthesis reports 12,710
estimated logic cells and 54 DSPs; exact packing uses 36,327 LUTX, 10,436 FFX,
1,798 CARRY4s, and 54 DSPs. Seed 1 fails strict legalization on one FFX after
the backend's 10,001-attempt minimum. Reducing the documented timeout divisor
from 8 to 4 reproduces the same minimum and failure, so this is not represented
as increased placement effort. Seed 2 legalizes and reaches only 37.57 MHz
after placement, versus the selected all-DSP KCL's completed 92.23 MHz route.
Routing is deliberately skipped after the 2.62x placement miss.

The partial mapping raises the complete shared-terminal solver from 15,072 to
21,333 estimated logic cells. It packs legally at 66,341 LUTX, 14,590 FFX,
3,948 CARRY4s, 171 DSPs, 16 RAMB18s, and two RAMB36s. This is a much smaller LUT
penalty than all-soft KCL, but it adds 6,827 LUT elements while the isolated
block loses 59.2% of its measured frequency. Complete placement is therefore
not justified. Static hard-block removal without an explicit registered
soft-multiply schedule is rejected for both tested scopes.
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

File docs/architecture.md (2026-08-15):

# Architecture

## Accuracy boundary

Reference mode begins at the cartridge generator and ends at the line load.
Its circuit values come from the frozen model asset. Converter calibration maps
real volts to the model's physical units; it must not compensate reference
response. Approximation diagnostics sit beside the datapath. Modern features
are separate blocks with explicit bypass and mode state.

```text
physical RCA input
  -> selectable 47.5 kΩ / total capacitance and RF protection
  -> low-current-noise flat gain, nominally 26 dB
  -> differential anti-alias/ADC (2 V RMS differential design reference)
  -> calibrated volts/sample
  -> 48 kHz to 768 kHz interpolation
  -> nonlinear V1 circuit solver (reference)
  -> 768 kHz to 48 kHz anti-alias/decimation
  -> mute/volume outside reference model
  -> DAC/reconstruction/line driver
```
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

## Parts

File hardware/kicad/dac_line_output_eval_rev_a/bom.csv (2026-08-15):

Reference | Value | Footprint | Description
J1 | DAC_AUDIO | Connector_PinHeader_2.54mm:PinHeader_2x05_P2.54mm_Vertical | 24.576MHz SCK; 3.072MHz BCK; 48kHz LRCK; 24-bit I2S from digital board
J2 | DAC_CONTROL | Connector_PinHeader_2.54mm:PinHeader_2x05_P2.54mm_Vertical | Low-speed control; DAC and relay paths fail muted
J3 | POWER_INPUT | Connector_PinHeader_2.54mm:PinHeader_2x04_P2.54mm_Vertical | Separate analog; digital; relay; chassis; and return feeds from power board
J4 | BALANCED_PANEL_HARNESS_EVT | Connector_JST:JST_XH_B8B-XH-A_1x08_P2.50mm_Vertical | EVT harness to enclosure XLRs; XLR pin 1 bonds to chassis at connector
J5 | RCA_PANEL_HARNESS_EVT | Connector_JST:JST_XH_B3B-XH-A_1x03_P2.50mm_Vertical | EVT harness to isolated RCA output jacks
U1 | PCM5242RHBR | Package_DFN_QFN:Texas_RHB0032E_VQFN-32-1EP_5x5mm_P0.5mm_EP3.45x3.45mm_ThermalVias | Stereo DirectPath DAC; I2C mode; slave clocks; external SCK; VREF output mode
U2 | TPS7A2033PDBVR_ANALOG | Package_TO_SOT_SMD:SOT-23-5 | Low-noise analog/charge-pump 3.3V post-regulator
U3 | TPS7A2033PDBVR_DIGITAL | Package_TO_SOT_SMD:SOT-23-5 | Low-noise digital 3.3V post-regulator
U4 | SN74LVC1G08DBVR_RELAY_INTERLOCK | Package_TO_SOT_SMD:SOT-23-5 | Hardware AND: controller and independent supervisor must both release line relays
U5 | SN74LVC1G08DBVR_XSMT_INTERLOCK | Package_TO_SOT_SMD:SOT-23-5 | Hardware AND: controller and independent supervisor must both release DAC XSMT
R1 | 0R_LINK | Resistor_SMD:R_0402_1005Metric | Receiver-side link; source damping belongs on digital board
R2 | 0R_LINK | Resistor_SMD:R_0402_1005Metric | Receiver-side link; source damping belongs on digital board
R3 | 0R_LINK | Resistor_SMD:R_0402_1005Metric | Receiver-side link; source damping belongs on digital board
R4 | 0R_LINK | Resistor_SMD:R_0402_1005Metric | Receiver-side link; source damping belongs on digital board
R5 | 1k | Resistor_SMD:R_0603_1608Metric
R6 | 100k_FAIL_MUTE | Resistor_SMD:R_0603_1608Metric
C1 | 10nF_X7R | Capacitor_SMD:C_0603_1608Metric
R7 | 4.7k | Resistor_SMD:R_0603_1608Metric
R8 | 4.7k | Resistor_SMD:R_0603_1608Metric
R9 | 0R_LINK | Resistor_SMD:R_0603_1608Metric
R10 | 0R_LINK | Resistor_SMD:R_0603_1608Metric
R11 | 10k | Resistor_SMD:R_0603_1608Metric
R12 | 100k_FAIL_MUTE | Resistor_SMD:R_0603_1608Metric
R13 | 100k_FAIL_MUTE | Resistor_SMD:R_0603_1608Metric | Independent supervisor release defaults low if disconnected
R14 | 100k_FAIL_MUTE | Resistor_SMD:R_0603_1608Metric
C11 | 100nF_X7R | Capacitor_SMD:C_0402_1005Metric | U4 local bypass
C12 | 100nF_X7R | Capacitor_SMD:C_0402_1005Metric | U5 local bypass
C2 | 100nF_X7R_LDOO | Capacitor_SMD:C_0402_1005Metric
C3 | 2.2uF_X7R_FLY | Capacitor_SMD:C_0603_1608Metric
C4 | 2.2uF_X7R_VNEG | Capacitor_SMD:C_0603_1608Metric
C5 | 100nF_X7R_AVDD | Capacitor_SMD:C_0402_1005Metric
C6 | 10uF_X5R_AVDD | Capacitor_SMD:C_0805_2012Metric
C7 | 100nF_X7R_CPVDD | Capacitor_SMD:C_0402_1005Metric
C8 | 2.2uF_X7R_CPVDD | Capacitor_SMD:C_0603_1608Metric
C9 | 100nF_X7R_DVDD | Capacitor_SMD:C_0402_1005Metric
C10 | 10uF_X5R_DVDD | Capacitor_SMD:C_0805_2012Metric
R20 | 499R_0.1% | Resistor_SMD:R_0805_2012Metric
R21 | 499R_0.1% | Resistor_SMD:R_0805_2012Metric
R22 | 499R_0.1% | Resistor_SMD:R_0805_2012Metric
R23 | 499R_0.1% | Resistor_SMD:R_0805_2012Metric
R24 | 499R_0.1% | Resistor_SMD:R_0805_2012Metric
R25 | 499R_0.1% | Resistor_SMD:R_0805_2012Metric
C20 | 1nF_C0G_DIFF | Capacitor_SMD:C_0603_1608Metric
C21 | 1nF_C0G_DIFF | Capacitor_SMD:C_0603_1608Metric
C22 | 2.2nF_C0G_SE | Capacitor_SMD:C_0603_1608Metric
C23 | 2.2nF_C0G_SE | Capacitor_SMD:C_0603_1608Metric
K1 | G6K-2F-Y-5V_FAIL_OPEN_1 | Relay_SMD:Relay_DPDT_Omron_G6K-2F-Y | Left balanced normally-open hard mute
Q1 | MMBT3904 | Package_TO_SOT_SMD:SOT-23 | Independent low-side relay driver
R31 | 2.2k | Resistor_SMD:R_0603_1608Metric
R34 | 100k | Resistor_SMD:R_0603_1608Metric
D1 | 1N4148W_FLYBACK | Diode_SMD:D_SOD-123
K2 | G6K-2F-Y-5V_FAIL_OPEN_2 | Relay_SMD:Relay_DPDT_Omron_G6K-2F-Y | Right balanced normally-open hard mute
Q2 | MMBT3904 | Package_TO_SOT_SMD:SOT-23 | Independent low-side relay driver
R32 | 2.2k | Resistor_SMD:R_0603_1608Metric
R35 | 100k | Resistor_SMD:R_0603_1608Metric
D2 | 1N4148W_FLYBACK | Diode_SMD:D_SOD-123
K3 | G6K-2F-Y-5V_FAIL_OPEN_3 | Relay_SMD:Relay_DPDT_Omron_G6K-2F-Y | Stereo RCA normally-open hard mute
Q3 | MMBT3904 | Package_TO_SOT_SMD:SOT-23 | Independent low-side relay driver
R33 | 2.2k | Resistor_SMD:R_0603_1608Metric
R36 | 100k | Resistor_SMD:R_0603_1608Metric
D3 | 1N4148W_FLYBACK | Diode_SMD:D_SOD-123
D4 | PESD5V0X1BCL_EVT | Diode_SMD:D_SOD-882 | EVT bidirectional line-output ESD candidate; qualify to IEC test plan
D5 | PESD5V0X1BCL_EVT | Diode_SMD:D_SOD-882 | EVT bidirectional line-output ESD candidate; qualify to IEC test plan
D6 | PESD5V0X1BCL_EVT | Diode_SMD:D_SOD-882 | EVT bidirectional line-output ESD candidate; qualify to IEC test plan
D7 | PESD5V0X1BCL_EVT | Diode_SMD:D_SOD-882 | EVT bidirectional line-output ESD candidate; qualify to IEC test plan
D8 | PESD5V0X1BCL_EVT | Diode_SMD:D_SOD-882 | EVT bidirectional line-output ESD candidate; qualify to IEC test plan
D9 | PESD5V0X1BCL_EVT | Diode_SMD:D_SOD-882 | EVT bidirectional line-output ESD candidate; qualify to IEC test plan
R40 | 1R_ANALOG_ISOLATION | Resistor_SMD:R_0805_2012Metric
C30 | 1uF_X7R_LDO_IN | Capacitor_SMD:C_0805_2012Metric
C31 | 2.2uF_X7R_LDO_OUT | Capacitor_SMD:C_0805_2012Metric
C32 | 10uF_X5R_ANALOG_BULK | Capacitor_SMD:C_0805_2012Metric
C33 | 1uF_X7R_LDO_IN | Capacitor_SMD:C_0805_2012Metric
C34 | 2.2uF_X7R_LDO_OUT | Capacitor_SMD:C_0805_2012Metric
C35 | 10uF_X5R_DIGITAL_BULK | Capacitor_SMD:C_0805_2012Metric
C36 | 10uF_X5R_RELAY_BULK | Capacitor_SMD:C_0805_2012Metric
R50 | DNP_0R_CHASSIS_BOND | Resistor_SMD:R_1206_3216Metric | DNP; populate only from complete chassis grounding review
C50 | DNP_4.7nF_CHASSIS | Capacitor_SMD:C_1206_3216Metric | DNP; safety/EMC population requires rated part and review
TP1 | +3V3A | TestPoint:TestPoint_Pad_D1.0mm | Local EVT pogo point
TP2 | +3V3D | TestPoint:TestPoint_Pad_D1.0mm | Local EVT pogo point
TP3 | DAC_XSMT_PIN | TestPoint:TestPoint_Pad_D1.0mm | Local EVT pogo point
TP4 | LINE_RELAY_EN_SAFE | TestPoint:TestPoint_Pad_D1.0mm | Local EVT pogo point
TP5 | L_RCA_OUT | TestPoint:TestPoint_Pad_D1.0mm | Local EVT pogo point
TP6 | R_RCA_OUT | TestPoint:TestPoint_Pad_D1.0mm | Local EVT pogo point
TP7 | CHASSIS | TestPoint:TestPoint_Pad_D1.0mm | Local EVT pogo point
TP8 | GND | TestPoint:TestPoint_Pad_D1.0mm | Local EVT pogo point

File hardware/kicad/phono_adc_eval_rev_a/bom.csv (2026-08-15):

Reference | Value | Footprint | Description
J1 | ISOLATED_PANEL_RCA_HARNESS | Connector_JST:JST_XH_B3B-XH-A_1x03_P2.50mm_Vertical | Short shielded harness to enclosure-qualified isolated RCA jacks; connector is EVT only
J2 | TURNTABLE_GROUND_POST | TerminalBlock_MetzConnect:TerminalBlock_MetzConnect_360425_1x01_Horizontal_ScrewM4.0_Boxed | EVT screw terminal; production binding post is chassis-mounted
J3 | ADC_AUDIO | Connector_PinHeader_2.54mm:PinHeader_2x05_P2.54mm_Vertical | Clock/data harness to digital board; PCM4202 is the 48 kHz I2S master
J4 | POWER_INPUT | Connector_PinHeader_2.54mm:PinHeader_2x06_P2.54mm_Vertical | Separately supplied analog; digital; and relay rails from product power board
J5 | ADC_CONTROL | Connector_PinHeader_2.54mm:PinHeader_2x05_P2.54mm_Vertical | Low-speed controls; all selection controls default low
U1 | TPS7A39DSCR | Package_SON:Texas_DSC0010J_ThermalVias | Dual low-noise post-regulator; ±12 V nominal from separately supplied ±15.5 V
U2 | TPS7A2050PDBVR | Package_TO_SOT_SMD:SOT-23-5 | Low-noise +5 V ADC analog post-regulator
U3 | TPS7A2033PDBVR | Package_TO_SOT_SMD:SOT-23-5 | Low-noise +3.3 V ADC digital post-regulator
U4 | OPA1656IDR | Package_SO:SOIC-8_3.9x4.9mm_P1.27mm | Dual JFET-input flat gain stage; 2.9 nV/rtHz at 10 kHz; 6 fA/rtHz at 1 kHz
U5 | OPA1632DR | Package_SO:SOIC-8_3.9x4.9mm_P1.27mm | Left fully differential PCM4202 driver; enabled by grounding EN with bipolar supplies
U6 | OPA1632DR | Package_SO:SOIC-8_3.9x4.9mm_P1.27mm | Right fully differential PCM4202 driver; enabled by grounding EN with bipolar supplies
U7 | PCM4202DBR | Package_SO:SSOP-28_5.3x10.2mm_P0.65mm | Stereo 24-bit ADC; 48 kHz master/I2S; 512fS SCKI; internal HPF disabled
U8 | OPA1656IDR | Package_SO:SOIC-8_3.9x4.9mm_P1.27mm | Dual voltage follower required because PCM4202 VCOM cannot drive OPA1632 VOCM directly
R1 | 100R_0.1% | Resistor_SMD:R_0805_2012Metric
R2 | 100R_0.1% | Resistor_SMD:R_0805_2012Metric
R3 | 47.5k_0.1%_25ppm | Resistor_SMD:R_0805_2012Metric
R4 | 47.5k_0.1%_25ppm | Resistor_SMD:R_0805_2012Metric
D1 | PESD5V0X1BCL_EVT | Diode_SMD:D_SOD-882 | 0.49 pF nominal bidirectional ESD candidate; fit only after leakage/noise review
D2 | PESD5V0X1BCL_EVT | Diode_SMD:D_SOD-882 | 0.49 pF nominal bidirectional ESD candidate; fit only after leakage/noise review
C1 | 47pF_C0G_1% | Capacitor_SMD:C_0603_1608Metric
C2 | 47pF_C0G_1% | Capacitor_SMD:C_0603_1608Metric
C3 | 100pF_C0G_1% | Capacitor_SMD:C_0603_1608Metric
C4 | 100pF_C0G_1% | Capacitor_SMD:C_0603_1608Metric
C5 | DNP_22pF_C0G_RF | Capacitor_SMD:C_0603_1608Metric | DNP; populate only from RF injection data and include in measured cartridge load
C6 | DNP_22pF_C0G_RF | Capacitor_SMD:C_0603_1608Metric | DNP; populate only from RF injection data and include in measured cartridge load
K1 | G6K-2F-Y-5V_GAIN_BANK | Relay_SMD:Relay_DPDT_Omron_G6K-2F-Y | Default NC is 26 dB; energized delegates both channels to K2
K2 | G6K-2F-Y-5V_GAIN_RANGE | Relay_SMD:Relay_DPDT_Omron_G6K-2F-Y | NC selects 20 dB and NO selects 32 dB only while K1 is energized
K3 | G6K-2F-Y-5V_CAP47 | Relay_SMD:Relay_DPDT_Omron_G6K-2F-Y | Normally open 47 pF C0G load increment for both channels
K4 | G6K-2F-Y-5V_CAP100 | Relay_SMD:Relay_DPDT_Omron_G6K-2F-Y | Normally open 100 pF C0G load increment for both channels
R5 | 19.1k_0.1% | Resistor_SMD:R_0805_2012Metric
R6 | 19.1k_0.1% | Resistor_SMD:R_0805_2012Metric
R7 | 1.00k_0.1% | Resistor_SMD:R_0805_2012Metric
R8 | 1.00k_0.1% | Resistor_SMD:R_0805_2012Metric
R9 | 2.12k_0.1% | Resistor_SMD:R_0805_2012Metric
R10 | 2.12k_0.1% | Resistor_SMD:R_0805_2012Metric
R11 | 492R_0.1% | Resistor_SMD:R_0805_2012Metric
R12 | 492R_0.1% | Resistor_SMD:R_0805_2012Metric
R20 | 316R_0.1% | Resistor_SMD:R_0603_1608Metric
R21 | 316R_0.1% | Resistor_SMD:R_0603_1608Metric
R22 | 316R_0.1% | Resistor_SMD:R_0603_1608Metric
R23 | 316R_0.1% | Resistor_SMD:R_0603_1608Metric
C20 | 1nF_C0G | Capacitor_SMD:C_0603_1608Metric
C21 | 1nF_C0G | Capacitor_SMD:C_0603_1608Metric
R24 | 40.2R_0.1% | Resistor_SMD:R_0603_1608Metric
R25 | 40.2R_0.1% | Resistor_SMD:R_0603_1608Metric
C22 | 2.7nF_C0G | Capacitor_SMD:C_0603_1608Metric
C23 | 100pF_C0G | Capacitor_SMD:C_0603_1608Metric
C24 | 100pF_C0G | Capacitor_SMD:C_0603_1608Metric
R30 | 316R_0.1% | Resistor_SMD:R_0603_1608Metric
R31 | 316R_0.1% | Resistor_SMD:R_0603_1608Metric
R32 | 316R_0.1% | Resistor_SMD:R_0603_1608Metric
R33 | 316R_0.1% | Resistor_SMD:R_0603_1608Metric
C30 | 1nF_C0G | Capacitor_SMD:C_0603_1608Metric
C31 | 1nF_C0G | Capacitor_SMD:C_0603_1608Metric
R34 | 40.2R_0.1% | Resistor_SMD:R_0603_1608Metric
R35 | 40.2R_0.1% | Resistor_SMD:R_0603_1608Metric
C32 | 2.7nF_C0G | Capacitor_SMD:C_0603_1608Metric
C33 | 100pF_C0G | Capacitor_SMD:C_0603_1608Metric
C34 | 100pF_C0G | Capacitor_SMD:C_0603_1608Metric
C40 | 33uF_LOW_ESR | Capacitor_SMD:C_Elec_4x5.8
C41 | 100nF_X7R | Capacitor_SMD:C_0603_1608Metric
C42 | 33uF_LOW_ESR | Capacitor_SMD:C_Elec_4x5.8
C43 | 100nF_X7R | Capacitor_SMD:C_0603_1608Metric
C44 | 100nF_X7R | Capacitor_SMD:C_0603_1608Metric
C45 | 100nF_X7R | Capacitor_SMD:C_0603_1608Metric
C46 | 33uF_LOW_ESR | Capacitor_SMD:C_Elec_4x5.8
C47 | 100nF_X7R | Capacitor_SMD:C_0603_1608Metric
C48 | 33uF_LOW_ESR | Capacitor_SMD:C_Elec_4x5.8
C49 | 100nF_X7R | Capacitor_SMD:C_0603_1608Metric
R40 | 22R | Resistor_SMD:R_0402_1005Metric
R41 | 33R | Resistor_SMD:R_0402_1005Metric
R42 | 33R | Resistor_SMD:R_0402_1005Metric
R43 | 33R | Resistor_SMD:R_0402_1005Metric
R44 | 100k | Resistor_SMD:R_0603_1608Metric | External control must actively release reset; PCM4202 internal POR remains upstream
R45 | 10k | Resistor_SMD:R_0603_1608Metric
Q1 | MMBT3904 | Package_TO_SOT_SMD:SOT-23 | Relay low-side driver
R51 | 2.2k | Resistor_SMD:R_0603_1608Metric
R55 | 100k | Resistor_SMD:R_0603_1608Metric
D3 | 1N4148W | Diode_SMD:D_SOD-123
Q2 | MMBT3904 | Package_TO_SOT_SMD:SOT-23 | Relay low-side driver
R52 | 2.2k | Resistor_SMD:R_0603_1608Metric
R56 | 100k | Resistor_SMD:R_0603_1608Metric
D4 | 1N4148W | Diode_SMD:D_SOD-123
Q3 | MMBT3904 | Package_TO_SOT_SMD:SOT-23 | Relay low-side driver
R53 | 2.2k | Resistor_SMD:R_0603_1608Metric
R57 | 100k | Resistor_SMD:R_0603_1608Metric
D5 | 1N4148W | Diode_SMD:D_SOD-123
Q4 | MMBT3904 | Package_TO_SOT_SMD:SOT-23 | Relay low-side driver
R54 | 2.2k | Resistor_SMD:R_0603_1608Metric
R58 | 100k | Resistor_SMD:R_0603_1608Metric
D6 | 1N4148W | Diode_SMD:D_SOD-123
R60 | 90.9k_0.1% | Resistor_SMD:R_0603_1608Metric
R61 | 10.0k_0.1% | Resistor_SMD:R_0603_1608Metric
R62 | 100k_0.1% | Resistor_SMD:R_0603_1608Metric
R63 | 10.0k_0.1% | Resistor_SMD:R_0603_1608Metric
C60 | 10nF_X7R | Capacitor_SMD:C_0603_1608Metric
C61 | 10nF_X7R | Capacitor_SMD:C_0603_1608Metric
C62 | 10nF_X7R | Capacitor_SMD:C_0603_1608Metric
C63 | 10uF_25V_X7R | Capacitor_SMD:C_1206_3216Metric
C64 | 10uF_25V_X7R | Capacitor_SMD:C_1206_3216Metric
C65 | 10uF_25V_X7R | Capacitor_SMD:C_1206_3216Metric
C66 | 10uF_25V_X7R | Capacitor_SMD:C_1206_3216Metric
C67 | 1uF_X7R | Capacitor_SMD:C_0603_1608Metric
C68 | 1uF_X7R | Capacitor_SMD:C_0603_1608Metric
C69 | 1uF_X7R | Capacitor_SMD:C_0603_1608Metric
C70 | 1uF_X7R | Capacitor_SMD:C_0603_1608Metric
C71 | 100nF_X7R | Capacitor_SMD:C_0603_1608Metric
C72 | 100nF_X7R | Capacitor_SMD:C_0603_1608Metric
C73 | 100nF_X7R | Capacitor_SMD:C_0402_1005Metric
C74 | 100nF_X7R | Capacitor_SMD:C_0402_1005Metric
C75 | 100nF_X7R | Capacitor_SMD:C_0402_1005Metric
C76 | 100nF_X7R | Capacitor_SMD:C_0402_1005Metric
C77 | 100nF_X7R | Capacitor_SMD:C_0603_1608Metric
C78 | 100nF_X7R | Capacitor_SMD:C_0603_1608Metric
C79 | 10uF_25V_X7R | Capacitor_SMD:C_1206_3216Metric
C80 | 10uF_25V_X7R | Capacitor_SMD:C_1206_3216Metric
R70 | 0R_CHASSIS_BOND | Resistor_SMD:R_1206_3216Metric | Reference build bonds signal return to chassis at the cartridge entry
R71 | DNP_10R_CHASSIS | Resistor_SMD:R_1206_3216Metric | Alternative only; remove R70 before fitting
C81 | DNP_100nF_CHASSIS | Capacitor_SMD:C_1206_3216Metric | Alternative RF bond used only with documented ground strategy
TP1 | L_INPUT | TestPoint:TestPoint_Pad_D1.0mm | Local EVT pogo point; do not extend sensitive-node routing
TP2 | R_INPUT | TestPoint:TestPoint_Pad_D1.0mm | Local EVT pogo point; do not extend sensitive-node routing
TP3 | L_GAIN_OUT | TestPoint:TestPoint_Pad_D1.0mm | Local EVT pogo point; do not extend sensitive-node routing
TP4 | R_GAIN_OUT | TestPoint:TestPoint_Pad_D1.0mm | Local EVT pogo point; do not extend sensitive-node routing
TP5 | ADC_L_IN_P | TestPoint:TestPoint_Pad_D1.0mm | Local EVT pogo point; do not extend sensitive-node routing
TP6 | ADC_L_IN_N | TestPoint:TestPoint_Pad_D1.0mm | Local EVT pogo point; do not extend sensitive-node routing
TP7 | ADC_R_IN_P | TestPoint:TestPoint_Pad_D1.0mm | Local EVT pogo point; do not extend sensitive-node routing
TP8 | ADC_R_IN_N | TestPoint:TestPoint_Pad_D1.0mm | Local EVT pogo point; do not extend sensitive-node routing
TP9 | +12VA | TestPoint:TestPoint_Pad_D1.0mm | Local EVT pogo point; do not extend sensitive-node routing
TP10 | -12VA | TestPoint:TestPoint_Pad_D1.0mm | Local EVT pogo point; do not extend sensitive-node routing
TP11 | +5VA | TestPoint:TestPoint_Pad_D1.0mm | Local EVT pogo point; do not extend sensitive-node routing
TP12 | +3V3D | TestPoint:TestPoint_Pad_D1.0mm | Local EVT pogo point; do not extend sensitive-node routing
TP13 | SCKI_24M576 | TestPoint:TestPoint_Pad_D1.0mm | Local EVT pogo point; do not extend sensitive-node routing
TP14 | ADC_BCK_OUT | TestPoint:TestPoint_Pad_D1.0mm | Local EVT pogo point; do not extend sensitive-node routing
TP15 | ADC_LRCK_OUT | TestPoint:TestPoint_Pad_D1.0mm | Local EVT pogo point; do not extend sensitive-node routing
TP16 | GND | TestPoint:TestPoint_Pad_D1.0mm | Local EVT pogo point; do not extend sensitive-node routing

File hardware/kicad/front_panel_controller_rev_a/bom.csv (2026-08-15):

Reference | Value | Footprint | Description
U1 | STM32H753ZIT6 | Package_QFP:LQFP-144_20x20mm_P0.5mm | 480 MHz UI controller; exact Rev-A pin map in pin_assignment.csv
U2 | IS42S16160J-6TLI_32MiB | Package_SO:TSOP-II-54_22.2x10.16mm_P0.8mm | 166 MHz x16 SDR SDRAM; 32 MiB framebuffer/work RAM
U3 | W25Q256JVSIQ_32MiB | Package_SO:SOIC-8_5.3x5.3mm_P1.27mm | Quad-SPI UI assets and firmware storage
U4 | TPS62132RGTR_3V3_3A | Package_DFN_QFN:VQFN-16-1EP_3x3mm_P0.5mm_EP1.6x1.6mm_ThermalVias | Fixed 3.3 V 3 A synchronous buck; TPS62132; not TPS62133
U5 | TPS61165DRVR | Package_SON:WSON-6-1EP_2x2mm_P0.65mm_EP1x1.6mm_ThermalVias | 38 V boost LED driver; 60 mA nominal current
J1 | UI_12V_INPUT | Connector_JST:JST_VH_B2P-VH-B_1x02_P3.96mm_Vertical | Protected 12 V input from product power board
J2 | NHD-5.0-800480AF-ASXP-CTP_TFT | fpga_amp:Molex_54104-4031_1x40-2MP_P0.50mm_Horizontal | 40-pin 0.5 mm TFT FFC; land pattern from Molex 541041000 rev B
J3 | NHD_CTP_6P | fpga_amp:Molex_52271-0679_1x06-2MP_P1.00mm_Horizontal | 6-pin 1.0 mm capacitive touch FFC; land pattern from Molex SD-52271-036 rev F
J4 | MOTOR_VOLUME_BOARD | Connector_PinHeader_2.54mm:PinHeader_2x06_P2.54mm_Vertical | Harness to isolated motor-volume evaluation board
J5 | DIGITAL_BOARD_CONTROL | Connector_PinHeader_2.54mm:PinHeader_2x08_P2.54mm_Vertical | Low-speed control link to FPGA/digital board; no audio samples
J6 | PANEL_CONTROLS | Connector_PinHeader_2.54mm:PinHeader_2x08_P2.54mm_Vertical | Panel-mounted optical encoders/buttons and ambient sensor
J7 | CORTEX_SWD | Connector_PinHeader_1.27mm:PinHeader_2x05_P1.27mm_Vertical | 1.27 mm Cortex debug connector
F1 | 1.5A_PTC | Fuse:Fuse_1206_3216Metric | Select final hold/trip after measured UI load
D1 | SMBJ15A | Diode_SMD:D_SMB
C1 | 10uF_25V_X7R | Capacitor_SMD:C_1210_3225Metric
C2 | 100nF_25V_X7R | Capacitor_SMD:C_0603_1608Metric
L1 | 2.2uH_4A | Inductor_SMD:L_Bourns_SRN6045TA
C3 | 22uF_6V3_X7R | Capacitor_SMD:C_1210_3225Metric
C4 | 22uF_6V3_X7R | Capacitor_SMD:C_1210_3225Metric
C5 | 3.3nF_X7R | Capacitor_SMD:C_0603_1608Metric
R1 | 100k | Resistor_SMD:R_0603_1608Metric
R2 | 100k | Resistor_SMD:R_0603_1608Metric
L2 | 10uH_1A | Inductor_SMD:L_Bourns-SRN4018
D2 | MBR0540T1G | Diode_SMD:D_SOD-123
C6 | 1uF_50V_X7R | Capacitor_SMD:C_1206_3216Metric
R3 | 3.32R_1% | Resistor_SMD:R_0805_2012Metric
C7 | 220nF_X7R | Capacitor_SMD:C_0603_1608Metric
R4 | 100k | Resistor_SMD:R_0603_1608Metric
R10 | 33R | Resistor_SMD:R_0402_1005Metric | LTDC source damping; verify by scope/SI
R11 | 33R | Resistor_SMD:R_0402_1005Metric | LTDC source damping; verify by scope/SI
R12 | 33R | Resistor_SMD:R_0402_1005Metric | LTDC source damping; verify by scope/SI
R13 | 33R | Resistor_SMD:R_0402_1005Metric | LTDC source damping; verify by scope/SI
R14 | 33R | Resistor_SMD:R_0402_1005Metric | LTDC source damping; verify by scope/SI
R15 | 33R | Resistor_SMD:R_0402_1005Metric | LTDC source damping; verify by scope/SI
R16 | 33R | Resistor_SMD:R_0402_1005Metric | LTDC source damping; verify by scope/SI
R17 | 33R | Resistor_SMD:R_0402_1005Metric | LTDC source damping; verify by scope/SI
R18 | 33R | Resistor_SMD:R_0402_1005Metric | LTDC source damping; verify by scope/SI
R19 | 33R | Resistor_SMD:R_0402_1005Metric | LTDC source damping; verify by scope/SI
R20 | 33R | Resistor_SMD:R_0402_1005Metric | LTDC source damping; verify by scope/SI
R21 | 33R | Resistor_SMD:R_0402_1005Metric | LTDC source damping; verify by scope/SI
R22 | 33R | Resistor_SMD:R_0402_1005Metric | LTDC source damping; verify by scope/SI
R23 | 33R | Resistor_SMD:R_0402_1005Metric | LTDC source damping; verify by scope/SI
R24 | 33R | Resistor_SMD:R_0402_1005Metric | LTDC source damping; verify by scope/SI
R25 | 33R | Resistor_SMD:R_0402_1005Metric | LTDC source damping; verify by scope/SI
R26 | 33R | Resistor_SMD:R_0402_1005Metric | LTDC source damping; verify by scope/SI
R27 | 33R | Resistor_SMD:R_0402_1005Metric | LTDC source damping; verify by scope/SI
R28 | 33R | Resistor_SMD:R_0402_1005Metric | LTDC source damping; verify by scope/SI
R29 | 33R | Resistor_SMD:R_0402_1005Metric | LTDC source damping; verify by scope/SI
R30 | 22R | Resistor_SMD:R_0402_1005Metric | SDRAM clock source termination
R31 | 22R | Resistor_SMD:R_0402_1005Metric | QSPI clock source termination
C10 | 100nF_X7R | Capacitor_SMD:C_0402_1005Metric | One per STM32 VDD/VDD33_USB pin; place at assigned power pin
C11 | 100nF_X7R | Capacitor_SMD:C_0402_1005Metric | One per STM32 VDD/VDD33_USB pin; place at assigned power pin
C12 | 100nF_X7R | Capacitor_SMD:C_0402_1005Metric | One per STM32 VDD/VDD33_USB pin; place at assigned power pin
C13 | 100nF_X7R | Capacitor_SMD:C_0402_1005Metric | One per STM32 VDD/VDD33_USB pin; place at assigned power pin
C14 | 100nF_X7R | Capacitor_SMD:C_0402_1005Metric | One per STM32 VDD/VDD33_USB pin; place at assigned power pin
C15 | 100nF_X7R | Capacitor_SMD:C_0402_1005Metric | One per STM32 VDD/VDD33_USB pin; place at assigned power pin
C16 | 100nF_X7R | Capacitor_SMD:C_0402_1005Metric | One per STM32 VDD/VDD33_USB pin; place at assigned power pin
C17 | 100nF_X7R | Capacitor_SMD:C_0402_1005Metric | One per STM32 VDD/VDD33_USB pin; place at assigned power pin
C18 | 100nF_X7R | Capacitor_SMD:C_0402_1005Metric | One per STM32 VDD/VDD33_USB pin; place at assigned power pin
C19 | 100nF_X7R | Capacitor_SMD:C_0402_1005Metric | One per STM32 VDD/VDD33_USB pin; place at assigned power pin
C20 | 100nF_X7R | Capacitor_SMD:C_0402_1005Metric | One per STM32 VDD/VDD33_USB pin; place at assigned power pin
C21 | 4.7uF_X7R | Capacitor_SMD:C_0805_2012Metric
C22 | 2.2uF_LOW_ESR | Capacitor_SMD:C_0805_2012Metric | VCAP; two capacitors total; VCAP pins connected per ST AN4938
C23 | 2.2uF_LOW_ESR | Capacitor_SMD:C_0805_2012Metric
FB1 | 600R@100MHz | Inductor_SMD:L_0603_1608Metric_Pad1.05x0.95mm_HandSolder
C24 | 1uF_X7R | Capacitor_SMD:C_0603_1608Metric
C25 | 100nF_X7R | Capacitor_SMD:C_0402_1005Metric
R40 | 0R | Resistor_SMD:R_0402_1005Metric
C26 | 1uF_X7R | Capacitor_SMD:C_0603_1608Metric
C27 | 100nF_X7R | Capacitor_SMD:C_0402_1005Metric
Y1 | 25MHz_10pF | Crystal:Crystal_SMD_3225-4Pin_3.2x2.5mm
Y2 | 32.768kHz_7pF | Crystal:Crystal_SMD_3215-2Pin_3.2x1.5mm
C28 | 12pF_C0G | Capacitor_SMD:C_0402_1005Metric
C29 | 12pF_C0G | Capacitor_SMD:C_0402_1005Metric
C30 | 10pF_C0G_DNP | Capacitor_SMD:C_0402_1005Metric | DNP pending crystal CL calculation
C31 | 10pF_C0G_DNP | Capacitor_SMD:C_0402_1005Metric | DNP pending crystal CL calculation
R41 | 10k | Resistor_SMD:R_0603_1608Metric
C32 | 100nF | Capacitor_SMD:C_0603_1608Metric
SW1 | RESET | Button_Switch_SMD:Panasonic_EVQPUJ_EVQPUA
R42 | 100k | Resistor_SMD:R_0603_1608Metric
JP1 | BOOT0 | Connector_PinHeader_2.54mm:PinHeader_1x02_P2.54mm_Vertical
FB2 | 600R@100MHz | Inductor_SMD:L_0603_1608Metric_Pad1.05x0.95mm_HandSolder
C33 | 1uF_X7R | Capacitor_SMD:C_0603_1608Metric
C34 | 100nF_X7R | Capacitor_SMD:C_0402_1005Metric
R43 | 2.2k | Resistor_SMD:R_0603_1608Metric
R44 | 2.2k | Resistor_SMD:R_0603_1608Metric
R45 | 10k | Resistor_SMD:R_0603_1608Metric
R46 | 10k | Resistor_SMD:R_0603_1608Metric
C40 | 100nF_X7R | Capacitor_SMD:C_0402_1005Metric | SDRAM VDD/VDDQ bypass
C41 | 100nF_X7R | Capacitor_SMD:C_0402_1005Metric | SDRAM VDD/VDDQ bypass
C42 | 100nF_X7R | Capacitor_SMD:C_0402_1005Metric | SDRAM VDD/VDDQ bypass
C43 | 100nF_X7R | Capacitor_SMD:C_0402_1005Metric | SDRAM VDD/VDDQ bypass
C44 | 100nF_X7R | Capacitor_SMD:C_0402_1005Metric | SDRAM VDD/VDDQ bypass
C45 | 100nF_X7R | Capacitor_SMD:C_0402_1005Metric | SDRAM VDD/VDDQ bypass
C46 | 10uF_X7R | Capacitor_SMD:C_0805_2012Metric
C47 | 100nF_X7R | Capacitor_SMD:C_0402_1005Metric
C48 | 1uF_X7R | Capacitor_SMD:C_0603_1608Metric
R47 | 10k | Resistor_SMD:R_0603_1608Metric
R48 | 10k | Resistor_SMD:R_0603_1608Metric | Default asserted; firmware must release mute intentionally
R49 | 10k | Resistor_SMD:R_0603_1608Metric
R50 | 10k | Resistor_SMD:R_0603_1608Metric
R51 | 1k | Resistor_SMD:R_0603_1608Metric
D3 | GREEN_STATUS | LED_SMD:LED_0603_1608Metric
TP1 | +12V_UI | TestPoint:TestPoint_Plated_Hole_D2.0mm | EVT bring-up test point
TP2 | +3V3 | TestPoint:TestPoint_Plated_Hole_D2.0mm | EVT bring-up test point
TP3 | GND | TestPoint:TestPoint_Plated_Hole_D2.0mm | EVT bring-up test point
TP4 | VCAP_CORE | TestPoint:TestPoint_Plated_Hole_D2.0mm | EVT bring-up test point
TP5 | VDDA | TestPoint:TestPoint_Plated_Hole_D2.0mm | EVT bring-up test point
TP6 | LCD_LED_A | TestPoint:TestPoint_Plated_Hole_D2.0mm | EVT bring-up test point
TP7 | BL_FB | TestPoint:TestPoint_Plated_Hole_D2.0mm | EVT bring-up test point
TP8 | NRST | TestPoint:TestPoint_Plated_Hole_D2.0mm | EVT bring-up test point

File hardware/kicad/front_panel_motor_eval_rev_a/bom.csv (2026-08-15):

Reference | Value | Footprint | Description
U1 | DRV8874PWPR | Package_SO:HTSSOP-16-1EP_4.4x5mm_P0.65mm_EP3.4x5mm_Mask2.46x2.31mm | Current-sensed PH/EN H-bridge; PWP PowerPAD must be soldered
J1 | MOTOR_5V_INPUT | Connector_JST:JST_VH_B2P-VH-B_1x02_P3.96mm_Vertical | Keyed 4.75-5.25 V motor supply from PB
J2 | FP_MCU_CONTROL | Connector_PinHeader_2.54mm:PinHeader_2x06_P2.54mm_Vertical | MCU control/telemetry; prototype header; production connector TBD
J3 | PRM16_MOTOR | Connector_JST:JST_VH_B2P-VH-B_1x02_P3.96mm_Vertical | Twisted motor pair to supported volume mechanism
J4 | PRM16_POSITION | Connector_JST:JST_XH_B6B-XH-A_1x06_P2.50mm_Vertical | Two ratiometric position tracks; never carries audio
F1 | 500mA_PTC | Fuse:Fuse_1206_3216Metric | Resettable input fuse; select hold/trip after measured stall test
D1 | SMBJ6.0A | Diode_SMD:D_SMB | Motor-rail transient clamp
C1 | 100nF_50V_X7R | Capacitor_SMD:C_0805_2012Metric
C2 | 10uF_16V_X7R | Capacitor_SMD:C_1210_3225Metric
C3 | 220uF_10V_LOW_ESR | Capacitor_SMD:C_Elec_6.3x5.8
C4 | 100nF_16V_X7R | Capacitor_SMD:C_0805_2012Metric
C5 | 22nF_16V_X7R | Capacitor_SMD:C_0805_2012Metric
R1 | 33R | Resistor_SMD:R_0805_2012Metric
R2 | 100k | Resistor_SMD:R_0805_2012Metric
R3 | 33R | Resistor_SMD:R_0805_2012Metric
R4 | 100k | Resistor_SMD:R_0805_2012Metric
R5 | 33R | Resistor_SMD:R_0805_2012Metric
R6 | 100k | Resistor_SMD:R_0805_2012Metric
R7 | 10k | Resistor_SMD:R_0805_2012Metric
R8 | 14.7k_1% | Resistor_SMD:R_0805_2012Metric
R9 | 10k_1% | Resistor_SMD:R_0805_2012Metric
C6 | 10nF_X7R | Capacitor_SMD:C_0805_2012Metric
R10 | 10k_1% | Resistor_SMD:R_0805_2012Metric
C7 | 10nF_X7R | Capacitor_SMD:C_0805_2012Metric
R11 | 1k | Resistor_SMD:R_0805_2012Metric
R12 | 62k_1% | Resistor_SMD:R_0805_2012Metric
R13 | 100R | Resistor_SMD:R_0805_2012Metric
R14 | 100R | Resistor_SMD:R_0805_2012Metric
R15 | 1k | Resistor_SMD:R_0805_2012Metric
C8 | 10nF_C0G | Capacitor_SMD:C_0805_2012Metric
R16 | 1k | Resistor_SMD:R_0805_2012Metric
C9 | 10nF_C0G | Capacitor_SMD:C_0805_2012Metric
R17 | 22k_1% | Resistor_SMD:R_0805_2012Metric
R18 | 10k_1% | Resistor_SMD:R_0805_2012Metric
R19 | DNP_SNUBBER | Resistor_SMD:R_0805_2012Metric | DNP; tune only from conducted/radiated measurements
C10 | DNP_SNUBBER | Capacitor_SMD:C_0805_2012Metric | DNP; tune only from conducted/radiated measurements
TP1 | VM_DRV | TestPoint:TestPoint_Plated_Hole_D2.0mm | Bring-up test point
TP2 | GND | TestPoint:TestPoint_Plated_Hole_D2.0mm | Bring-up test point
TP3 | MOTOR_OUT1 | TestPoint:TestPoint_Plated_Hole_D2.0mm | Bring-up test point
TP4 | MOTOR_OUT2 | TestPoint:TestPoint_Plated_Hole_D2.0mm | Bring-up test point
TP5 | VREF | TestPoint:TestPoint_Plated_Hole_D2.0mm | Bring-up test point
TP6 | IPROPI_SENSE | TestPoint:TestPoint_Plated_Hole_D2.0mm | Bring-up test point
TP7 | POT_A_ADC | TestPoint:TestPoint_Plated_Hole_D2.0mm | Bring-up test point
TP8 | POT_B_ADC | TestPoint:TestPoint_Plated_Hole_D2.0mm | Bring-up test point

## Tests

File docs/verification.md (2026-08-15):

# Verification

## Reproducible gates

`make test` runs the mathematical unit suite and the bit-exact RTL test. The
reference tests cover the canonical RIAA table, AT-VM95E resonance, 12AX7 bias,
LUT absolute error, V1 DC nodes, 1 kHz gain, and solver convergence. Verilator
checks 4,096 deterministic randomized tuples including range boundaries and
requires exact `Ip`, `Ig`, clipping, valid timing, and eight-clock latency.
The chord-corrector test requires exact nine-node outputs and saturation status
for 1,024 vectors, including forced positive/negative limits, at ten clocks.
The network tests require 1,024 exact RHS and 1,024 exact KCL vectors. The
integration test then carries one persistent circuit state through 512 samples
and compares every node, capacitor, residual, output, and diagnostic count.
The complete stream test independently composes the fixed interpolator, 1,024
fixed nonlinear updates, output format conversion, and decimator, then requires
64 consecutive 48 kHz RTL outputs to be exactly equal without latency/gain
alignment. The wide-stream bench also accepts up to 8,192 external samples and
can capture arbitrary exact trajectories for longer measurements. The
guarded-stream integration test covers muted startup, ramp-down before core
reset, 48 kHz phase-aligned reset release, muted warmup, one acknowledgment, and
unity-gain recovery. The standalone output-safety test covers reset,
positive/negative rounding, sample-qualified gain changes, exact-unity bypass,
graceful ramp-down, and a forced clamp with and without a valid input sample.

`make formal-mute` independently uses the Yosys 0.66 built-in SAT engine. After
one assumed reset clock it leaves sample data, validity, mute request, and force
mute arbitrary. Fifteen assertions cover reset state, synchronous force clamp,
valid timing, held state, the exact saturating gain transition, endpoint output,
gain monotonicity, and status decode. Temporal induction closes at depth 2. A
separate satisfiability run reaches `0xffff` gain after four accepted samples,
showing the reset assumptions admit the intended unmute path. Logs are retained
under `build/formal_output_mute_ramp/`.

The asynchronous FIFO test uses unrelated 10 ns write and 14 ns read clocks. It
fills exactly, rejects and records a ninth word, drains in order, records an
empty read, clears both owning-domain sticky flags, and preserves 128 further
words over repeated pointer wraps. The RTL includes Gray one-bit-transition and
blocked-pointer formal assertions under `FORMAL`; they are not claimed as proven
for all time. `make formal-async-fifo` uses `clk2fflogic` to retain independent
clock transitions and exhaustively checks 13 Gray-transition, blocked-pointer,
occupancy/watermark, valid, and sticky-fault properties through 32 global formal
steps after a disciplined shared-reset release. A separate satisfiable 24-step
trace reaches depth four and both overflow/underflow stickies. Unbounded
induction does not close with the current incomplete invariant set; the bounded
result also cannot represent analog metastability.

The held-bus snapshot test uses unrelated 10 ns source and 14 ns destination
clocks to require three exact 16-bit captures and recovery when the destination
is reset during an active request. `make formal-cdc-snapshot` separately leaves
both clock levels, request, and four-bit live data arbitrary after a disciplined
shared startup reset. Nine assertions cover destination capture provenance and
hold stability, exact source-domain data, one-cycle valid, completion bounded by
accepted requests, and idle only after all accepted requests complete for every
40-step interleaving. A separate satisfiable trace accepts and completes one
nonzero `0xa` transfer and returns to available. This is a bounded digital logic
result: it neither proves progress if a clock stops, models analog metastability,
nor covers an independently resetting destination in the formal environment.

The toggle-pulse CDC directed test transfers two source commands across
unrelated 10 ns/34 ns clocks. It also resets the destination while the retained
source toggle is one and requires exactly one replay after release; only
idempotent commands may use this primitive. `make formal-cdc-pulse` assumes a
new event is launched only after the previous event has been observed, then
leaves both clocks and source event timing arbitrary. Ten pipeline, decode,
pulse-width, at-most-one-outstanding, no-fabrication, and delivery-accounting
properties hold through 40 global steps. A satisfiable trace accepts and
delivers two events. Progress with a stopped clock, independently resetting
domains, events outside the separation contract, and analog metastability are
not proven.

The asynchronous audio-clock monitor's directed test uses 320-clock windows to
acquire three exact ten-edge measurements, reject an 11-edge window, reacquire,
clear retained evidence, reject a stopped clock as zero edges, and revoke live
state after BCLK reset. `make formal-audio-clock` uses a reduced four-clock,
one-edge, two-good-window instance with arbitrary BCLK/fabric clock levels and
clear timing after disciplined startup reset. Sixteen assertions cover exact
binary/Gray counter and synchronizer evolution, measurement cadence, every
window-state branch, measured delta, lock/count invariants, and sticky-clear
precedence through 32 global steps. A 48-step witness acquires lock and later
retains a bad-rate error while unlocked. This bounded digital proof does not
establish Gray-bus skew/placement, metastability MTBF, absolute clock accuracy,
or progress if either clock stops.

The I²S test passes 16 stereo frames through independent transmitter and
receiver blocks, including signed 24-bit maximum/minimum and pseudorandom-like
channel patterns. A separate monitor—not the receiver—requires 31 stable sampled
edges between LRCLK changes and a zero serial delay bit on each transition.
Starving the next frame sets transmitter underflow; a one-edge LRCLK corruption
sets receiver framing error; both sticky flags clear in the BCLK domain.

The bidirectional bridge test uses a 20 ns BCLK and an unrelated, phase-offset
13 ns fabric clock. An I²S transmitter supplies 20 nonzero signed stereo frames;
the fabric scoreboards each receive handshake, loops each frame back, and
deliberately removes receive ready one cycle in four. Held valid/data stability
is checked during every stall. A second I²S receiver requires the exact same 20
frames in order. Bridge framing and both FIFO overflow/underflow pairs remain
clear; deliberate zero output during pipeline startup sets the serial underflow
flag, which is then cleared in the BCLK domain.

The calibration generator preserves 4,159 deterministic vectors in each
direction: signed endpoints, zero/negative coefficients, realistic study
coefficients, full coefficient range, and 4,096 seeded random tuples. Python and
one-clock RTL must agree exactly. The input test records 14 PCM endpoint events
and 51 invalid configurations. The output test deliberately produces 4,079
saturations and 52 invalid configurations; saturation is not weakened to make
random vectors pass. Both diagnostic blocks are cleared explicitly after the
count/sticky checks.

`make formal-audio-calibration` complements those vectors with arbitrary
full-width samples, coefficients, valid timing, and clears. Twelve assertions
cover the input conversion's signed-32 post-shift range, exact registered
valid/output/hold behavior in both directions, exact PCM24 clipping, saturating
endpoint/saturation counters, and invalid-configuration sticky precedence.
Yosys 0.66 SAT temporal induction closes at depth 2. A separate trace reaches
one endpoint event, one output saturation, and both invalid-configuration
stickies. This proves the digital arithmetic/control contract, not the physical
converter voltage calibration.

The frame-scheduler unit test reduces the period to eight clocks for directed
coverage while preserving the production phase relationship. A source holds a
nonzero frame until the one-clock ready pulse, leaves the next boundary empty,
and supplies a second signed-endpoint frame after that miss. An independent
one-clock preprocessing register and phase counter require outputs `[frame A,
zero, frame B]` only at consumer phase zero. Exactly one underflow is retained
and then cleared. The test does not claim asynchronous rate conversion.

The mode-0 SPI integration drives eight complete 80-bit frames at 5 MHz through
the real register bank and calibration guard, plus a ten-bit abort and withheld
response. `make formal-spi-control` independently leaves the asynchronous pins,
response channel, and diagnostic clear arbitrary. Eleven synchronization,
bit-count, request-field, response-state, saturating-count, frame-reset, and
sticky-precedence assertions hold through 32 fabric clocks. Because a request
requires 40 synchronized input bits, a separate 100-step satisfiable trace
reaches request decode plus short-frame and underflow evidence. The result is
explicitly bounded and does not prove analog metastability, a placed SCLK rate,
or complete-frame wire order; the directed integration supplies the latter.

The analog/reference commands are intentionally separate so a missing external
tool is not reported as a pass:

```text
make spice                          ngspice DC/AC/transient
scripts/spice_level_sweep.py        H1-H10/THD/gain compression
scripts/compare_spice_python.py     transient residual
scripts/compare_spice_python_frequency.py  four-point integrator/SPICE sweep
scripts/compare_internal_rate_pop_spice.py matched 8x/16x pop vs ngspice
scripts/characterize_solver.py      fixed-iteration residual/convergence
scripts/study_lut_resolution.py     BRAM/error trade study
scripts/study_factorized_tube.py    factorized current/circuit accuracy
scripts/analyze_factorized_domain.py  paired cutoff-domain equivalence audit
scripts/characterize_factorized_frequency.py  six-point audio-band equivalence
scripts/characterize_state_drift.py           one-second silence/click state audit
scripts/characterize_wide_state_audio.py      nominal-level state-format A/B
scripts/analyze_linearized_modes.py           physical G+sC pole extraction
scripts/characterize_wide_solver_rtl.py       captured 1 kHz RTL metrics/null
scripts/sweep_wide_solver_rtl.py              captured four-point RTL sweep
scripts/sweep_wide_solver_rtl.py --trapezoidal  captured integrator sweep
scripts/characterize_trapezoidal_solver_rtl_recovery.py  accepted long recovery
scripts/sweep_wide_stream_rtl.py --trapezoidal  captured complete 48 kHz sweep
scripts/characterize_wide_solver_rtl_overload.py  captured 100 ms burst/recovery
scripts/characterize_wide_solver_rtl_overload.py --banked --terminal-correction  terminal H1-H10/clipping/recovery
scripts/characterize_wide_stream_rtl_alias.py     captured cubic alias/full stream
scripts/process_wav.py                         explicit-voltage fixed V1 WAV path
scripts/compare_wav.py                         latency/gain/residual WAV comparison
scripts/run_wav_null_regression.py             synthetic end-to-end audio gate
scripts/generate_audio_regression_vectors.py   original physical-level fixtures
scripts/run_audio_regression.py                fixed distortion/IMD/overload gate
scripts/characterize_overload_recovery.py     grid conduction and recovery
scripts/characterize_overload_recovery.py --trapezoidal  fixed integrator overload
scripts/characterize_long_overload_recovery.py  235 ms physical-model tail
scripts/measure_severe_overload_recovery.py     direct 850 ms multimode tail
scripts/measure_seven_second_recovery.py        complete severe recovery timing
scripts/study_overload_iterations.py          pass-count/deadline trade
scripts/study_banked_chord_iterations.py      banked pass-count waveform trade
scripts/study_trapezoidal_overload.py         floating integrator stability
scripts/characterize_factorized_frequency.py --trapezoidal  fixed integrator sweep
scripts/run_synthesis.py            XC7 structural resource report
scripts/run_mute_formal.py          safety-ramp temporal induction/reachability
scripts/run_async_fifo_formal.py    32-step arbitrary-clock FIFO safety bound
scripts/run_calibration_control_formal.py  atomic calibration induction/witness
scripts/run_frame_scheduler_formal.py  phase/zero-fill/counter induction
```

## Current acceptance record
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

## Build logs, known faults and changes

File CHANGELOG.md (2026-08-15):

# Changelog

All notable engineering changes are recorded here. The project is pre-release; dates use ISO 8601.

## Unreleased

### Added

- Added the board-facing DAC relay/XSMT sequencer. Normal release asserts the
  relay permission, waits a default 491,520 clocks (5 ms at 98.304 MHz), then
  asserts PCM5242 XSMT permission; orderly mute drops XSMT first and opens the
  relays after the same conservative interval. Release cancellation avoids an
  unnecessary mute delay before XSMT ever rises, while emergency mute drops
  both registered permissions on the next fabric edge. The PCB's independent
  `HARD_MUTE_N` remains the asynchronous veto. Directed simulation covers every
  transition; Yosys reports 28 XC7 logic cells / 22 flip-flops / no DSP/BRAM or
  warnings. Physical contact/ramp/transient timing is still unmeasured.
- Added a periodic PCM5242 runtime monitor and integrated it after the 20-write
  initializer and 24-operation startup verifier. A first four-register sweep is
  now required before the fail-low `unmute_permitted` can rise; nominal 100 ms
  polls then check live/latched clock faults, active/sticky output shorts, DSP
  boot, and run state. First-fault evidence is retained even though PCM5242
  sticky bits clear on read. The complete bus regression proves 48-transaction
  release, ACK-only/startup-snapshot non-permission, both startup failure phases,
  and post-unmute revocation on a short. Yosys reports 122 LC / 178 FF for the
  monitor and 340 LC / 439 FF for the complete controller, with no DSP/BRAM or
  warnings. The independent external supervisor remains the faster hardware
  veto and physical fault/mute timing is not yet validated.
- Added the page-aware PCM5242 startup verifier above the generic read
  transport. Its 24 operations compare critical page 0/1 writable fields with
  reserved-bit-safe masks, restore page 0, and require detected 48 kHz,
  512-fS SCK, 64-fS BCK, valid clock status, DSP boot complete, and run state.
  A bus-level regression proves the exact success sequence and injected masked
  mismatch/NACK fail-closed paths, including captured failure evidence. Yosys
  reports 170 estimated XC7 logic cells / 173 flip-flops / no DSP or BRAM /
  zero warnings. `configuration_verified` remains a startup snapshot; it is
  explicitly distinct from ACKed writes and does not replace runtime monitors
  or the independent hardware supervisor.
- Added a synthesizable one-byte-register I2C read primitive for PCM5242
  verification. It implements address+W, register index, repeated START,
  address+R, one returned byte, master NACK, and STOP with open-drain pins and
  clock-stretch handling. A directed bus target verifies exact transaction
  bytes, returned data, final NACK/STOP/release, and fail-closed address-NACK
  abort. Yosys reports 70 estimated XC7 logic cells / 63 flip-flops / no DSP or
  BRAM / zero warnings. This is transport only; page-aware masked register and
  live clock/power status checks still gate DAC unmute.
- Added a synthesizable write-only PCM5242 reference-path bootstrap and extended
  the existing I2C writer to select one- or two-byte register addresses. The
  twenty-write sequence explicitly selects the strapped 0x4c device, external
  SCK with PLL disabled, 24-bit I2S, direct stereo routing, ROM interpolation
  program 1, unity digital/analog gain, VREF output, no de-emphasis, and no
  zero-detect auto mute. A bus-level target captures and checks every byte,
  confirms released-bus completion, and proves an injected NACK stops at the
  failing index without further writes. Existing 16-bit ADAU1761 and generic
  writer regressions remain passing. Yosys reports 83 estimated XC7 logic cells
  / 86 flip-flops / no DSP or BRAM / zero warnings. The output is deliberately
  `configuration_written`, not `configured`; register readback and live
  clock/power validation still gate hardware unmute.
- Added the routed four-layer PCM5242 DAC/protected line-output Rev-A EVT KiCad
  project. It implements 48 kHz 24-bit I2S slave operation with external
  24.576 MHz SCK, I2C unity/reference configuration, separate analog/digital
  TPS7A2033 post-regulators, official-reference 499 ohm/1 nF differential and
  499 ohm/2.2 nF RCA reconstruction branches, three normally-open fail-open
  signal relays, and provisional chassis-referenced ESD sites. Two
  SN74LVC1G08 gates require both controller and external-supervisor release
  before relay drive or PCM5242 XSMT can assert, fixing an initial unsafe
  concept that directly tied the two control sources. Rotating the PCM5242 so
  analog outputs face the reconstruction side eliminated fragile QFN escape
  routing; a deterministic back-edge I2C trace completes the open Freerouting
  result. One source model generates 85 schematic parts, 89 board footprints,
  53 nets, BOM, and exact clock/load calculations. The 112 x 72 mm route has
  581 segments / 86 vias; KiCad 10.0.5 reports zero ERC, zero DRC, and zero
  unconnected items. The board is unbuilt and not fabrication-released pending
  register/readback firmware, loaded audio performance, mute/fault sequencing,
  output connector/chassis, ESD/RF, stackup, DFM, and physical validation.
- Added a receive-only PCM4202 I2S/fabric boundary for the phono/ADC EVT board.
  It captures 24-bit I2S in the converter's fixed 64-BCK half-frames at
  6.144 MHz, crosses complete stereo frames through a depth-8 asynchronous FIFO,
  holds fabric data under backpressure, and exposes framing, overflow,
  underflow, occupancy, and high-water diagnostics. Keeping this receive-only
  avoids incorrectly clocking a future 32-BCK DAC at 96 kHz. The generic I2S
  loopback now passes both 32- and 64-BCK slot configurations. A separate exact
  6.144 MHz ADC / 49.152 MHz fabric test passes 16 signed frames with unrelated
  phase, initial and periodic backpressure, held-data checks, and an injected/
  cleared LRCK fault. Yosys reports 252 estimated XC7 logic cells / 791
  flip-flops / no DSP or block RAM / zero structural problems; the sole warning
  records register mapping of the small dual-clock FIFO. No FPGA-pin or
  populated-board timing is claimed.
- Added the routed four-layer shielded MM phono/PCM4202 ADC Rev-A EVT KiCad
  project. It implements 47.5 kilohm 0.1% termination, relay-selected
  0/47/100/147 pF C0G loading, OPA1656 flat 20.008/26.064/32.002 dB gain,
  OPA1632 differential conversion and ADC reservoir filtering, PCM4202 48 kHz
  master I2S with reference-mode HPF disabled, local TPS7A39/TPS7A20
  post-regulation, fail-low relay drivers, and separate relay power. One source
  model generates 135 schematic parts, 139 board footprints, 77 nets, BOM, and
  exact headroom/clock/strap calculations. The open Freerouting 2.2.4 route has
  926 segments / 141 vias; KiCad 10.0.5 reports zero ERC, zero DRC, and zero
  unconnected items. A source-aware verifier audits critical pin maps, relay
  defaults, DNP population, layers, dimensions, geometry, route statistics,
  and calculation consistency. The board is unbuilt and visibly marked not
  fabrication-released pending production RCA/ground mechanics, measured input
  capacitance/noise/hum/overload/crosstalk/RF/ESD, stackup review, muted relay
  testing, and 128-fS PCM4202 receiver validation.
- Replaced both provisional display connector footprints with project-local,
  manufacturer-drawing implementations for the Molex 54104-4031 40-pin
  top-contact TFT FFC and 52271-0679 6-pin bottom-contact touch FFC. A dimension
  audit records pad count, pitch, signal-land size, fitting-nail size/location,
  contact side, and source drawing revisions; the board verifier now locks those
  geometries. The larger truthful J3 actuator courtyard exposed five placement
  errors, which were fixed by relocating J3 before rerouting. The final open
  route has 1,827 segments / 327 vias and passes KiCad 10.0.5 with zero ERC,
  zero DRC, and zero unconnected items. Physical fit, assembler DFM, and
  first-article inspection remain fabrication gates.
- Added the routed six-layer front-panel controller Rev-A EVT KiCad project.
  One source model generates 111 schematic elements, a 150 x 90 mm placement,
  native symbols, BOM, and the exact 106-I/O STM32H753ZIT6 allocation. The
  circuit includes x16 32 MiB SDRAM, 32 MiB Quad-SPI, RGB565 LTDC with twenty
  source dampers, the exact display electrical pin map, I2C capacitive touch,
  TPS62132 3.3 V conversion, TPS61165 nominal 60.2 mA backlight boost, MCU
  core/analog power support, crystals, reset/BOOT0/SWD, three encoder/control
  harnesses, motor-volume telemetry/control, and fail-asserted mute. The open
  Freerouting v2.2.4 route finishes in five passes plus one reviewed 1.6 mm
  U2-ground dogleg; after zone refill KiCad 10.0.5 reports zero ERC, zero DRC,
  and zero unconnected items on the original 1,895-track / 314-via baseline. A source-aware
  verifier audits package and display pin maps, layers, dimensions, damping,
  regulator identity, route geometry, and records SDRAM/display route lengths.
  Exact Molex FFC physical-fit/FAI signoff, stackup/SI, regulator layout,
  mechanics, sourcing, EMC, and physical tests
  remain fabrication stop conditions. The allocation also documents that
  direct RMII Ethernet cannot coexist with the selected LTDC/FMC mapping.
  A pre-commit TI data-sheet audit corrected the TPS61165 WSON order to
  `FB/COMP/GND/SW/CTRL/VIN`; the incorrect initial route was discarded.
- Added the first KiCad PCB artifact: an 80 x 48 mm, four-layer motor-volume
  EVT daughterboard around the DRV8874. It includes protected 5 V input,
  current-limit/reference networks, IPROPI and nFAULT telemetry, fail-off motor
  controls, physically separate motor and dual ratiometric position connectors,
  filtered MCU ADC returns, DNP snubber tuning sites, mounting holes, and eight
  labeled test points. A single Python parts/net model generates the native
  KiCad 10 schematic, PCB placement, symbols, and BOM; an open Freerouting
  DSN/SES flow supplies the checked-in route. KiCad 10.0.5 reports zero ERC,
  zero DRC, and zero unconnected items on the final 235-segment/28-via board.
  The verifier additionally checks dimensions, layer count, the DRV8874 pad
  map, motor/position connector separation, DNP flags, and manufacturing
  minima. Make targets regenerate, route, check, and export Gerbers, drill
  files/maps/report, and DNP-filtered placement data. This is an unbuilt EVT
  design; thermal strategy, connector release, motor EMI/current/torque/noise,
  assembly, and lifetime are not validated.
- Added a synthesizable stereo master-volume endpoint corresponding to the
  motorized front-panel control. The modern, post-model primitive accepts
  unsigned Q0.31 linear targets, reserves zero and `0x7fffffff` for exact
  silence/unity bypass, rejects out-of-range targets with retained diagnostics,
  and reaches a new target within a configurable power-of-two sample count
  without hardware division. Full 64-bit stereo products use symmetric
  round-to-nearest. Warning-free directed/randomized RTL exercises mid-ramp
  retargeting, signed rounding, stereo independence, silence, unity, and target
  rejection. Yosys out-of-context XC7 synthesis reports 312 estimated logic
  cells / 151 flip-flops / eight DSP48E1 / no BRAM / zero structural problems.
  It is not yet integrated into the mono Nexys hierarchy; no placed timing,
  physical audio, or stereo-product fit is claimed.
- Added a portable C11 motor-volume servo core for the future front-panel MCU.
  It keeps the motor position transducer outside audio, clamps commands to
  calibrated soft endpoints, reduces duty on approach, coasts in deadband,
  inserts direction-reversal dead time, accepts explicit or inferred manual
  takeover, and latches sensor, driver, current/stall, and travel-timeout faults.
  Explicit safe clear adopts the present position and requires a new command,
  preventing automatic retries against a mechanical stop. A host test compiled
  with all common warnings promoted to errors covers the control and fault
  transitions. The initial regression caught a command-intent bug where the
  idle manual detector canceled a reversal after its coast interval; a retained
  `target_pending` state fixes it. No physical motor, MCU peripheral, EMI,
  torque, acoustic, touch-safety, or lifetime result is claimed.
- Added a comprehensive V1 product hardware specification for the requested TV
  and front-panel platform. It partitions the product into five serviceable
  boards—digital/eARC, shielded phono/ADC, DAC/line output, LCD/touch/motor
  controls, and power/protection—and keeps all new functions outside the frozen
  historical phono model. The design uses a provisional audio-only SiI9437
  eARC/ARC receiver, an explicit SRC4392/AD1896-class asynchronous boundary to
  the local 48 kHz clock, truthful stereo-LPCM-only capability policy, a
  5-inch 800x480 IPS capacitive display on a dedicated STM32H753-class MCU,
  premium optical encoder candidates, and a current-sensed motorized volume
  servo whose position element never carries audio. It also specifies remote
  control arbitration, grounding/EMC zoning, rail sequencing, independent
  analog mute, manufacturing calibration, release gates, multi-TV testing, and
  the finished-product HDMI adopter/compliance dependency. A machine-readable
  ledger contains 52 reference/modern/infrastructure/safety/regulatory
  requirements; a 31-row signal/contact budget owns six inter-board interfaces.
  Seven regressions, including six deliberate mutations, reject traceability,
  interface, contact, board-reference, and frozen-invariant drift. This is an architecture baseline,
  not a released PCB/BOM, licensed HDMI product, measured eARC implementation,
  stereo FPGA result, or qualified motor-life claim.

- Added a non-programming Nexys Video hardware preflight and an explicit
  volatile-SRAM load target using openFPGALoader's official `nexysVideo`
  profile. The preflight rejects any bitstream whose part, byte count, SHA-256,
  saved `bitread -C` result, configuration frames, or configuration words do
  not match its adjacent manifest, then limits probe operations to programmer
  version/board enumeration and JTAG detection. Three Python regressions cover
  exact acceptance, tamper rejection, and absent-programmer behavior. The real
  9,730,825-byte artifact passes all integrity checks; this host has no
  openFPGALoader executable or attached Nexys Video, so no programming or
  physical validation is claimed.
- Added the complete Nexys Video audio board wrapper. It composes the exact
  dual-MMCM clock leaf, /16 serial clock and reset release, ADAU1761 bootstrap,
  one physically shared LRCLK, bidirectional I2S data, the selected 384 kHz
  phono profile, SPI control, open-drain I2C, and four status LEDs on the real
  Rev. A pins. Audio remains reset/muted and DAC serial data remains zero until
  all codec writes ACK and the ready bit crosses two BCLK synchronizer stages.
  It also holds the I2S bridge/FIFO serial ports reset through the same ready
  synchronizer so undefined ADC frames cannot fill the receive FIFO during
  bootstrap. A mutation-tested static contract checks every LOC/IOSTANDARD,
  active-low G4 reset, the explicit internal 3.072 MHz BCLK constraint, model
  schedule, I2C, pre-configuration-frame exclusion, and fail-closed release.
  The shared-I2S guard is warning-free at one logic
  cell / two flip-flops. Complete Yosys synthesis reports 16,688 estimated
  logic cells / 11,687 flip-flops / 217 DSPs / ten RAMB18 equivalents and zero
  structural problems; open A200T packing uses 59,710 LUTX / 11,687 FFX /
  4,192 CARRY4 / 217 DSP / three BUFG / two MMCM. Router2 reaches zero overuse
  in 20 iterations and passes the experimental constraints at 54.663 MHz for
  the 49.152 MHz fabric domain and 123.457 MHz for 3.072 MHz BCLK. Pinned
  Project X-Ray twice produces the same CRC-readable 9,730,825-byte bitstream,
  SHA-256 `5f196e5232a391d63f57f1cbe2ee00ec5a261f445c7432530e5442f43b09dbb8`.
  It supersedes the unprogrammed `3ea5cea8...c286f23` artifact that released
  the serial transport before codec configuration.
  This does not claim qualified -1 timing, physical codec ACK, programmed
  hardware, measured clocks, or analog audio.
- Added the fixed ADAU1761 startup sequencer above the generic I2C writer. Its
  27-entry table uses direct 12.288 MHz MCLK, leaves the codec subordinate to
  FPGA-provided 3.072 MHz BCLK/48 kHz LRCLK, configures stereo ADC/DAC routes,
  keeps both line outputs muted during setup, and unmutes them only in the last
  two transactions. A bus-target regression checks every transmitted byte and
  proves that an injected table-index-five NACK latches the failed index and
  prevents all later writes. Warning-free Yosys XC7 synthesis reports 88
  estimated logic cells, 94 flip-flops, ten CARRY4s, and no DSP/BRAM. This is
  digital verification; no physical codec ACK or analog output is claimed.
- Added a device-neutral, synthesizable open-drain I2C register writer for the
  codec-control path. It sends a seven-bit device address, a 16-bit register
  address, and an eight-bit value; honors target clock stretching; records a
  NACK from any byte; and always completes with STOP. The bus-level test checks
  byte-exact ACK, deliberate NACK, and clean recovery. Warning-free Yosys XC7
  synthesis reports 43 estimated logic cells, 59 flip-flops, three CARRY4s,
  and no DSP or BRAM. Readback, arbitration, and multi-main behavior are not
  claimed.
- Added a warning-free serial-clock/reset leaf for the board implementation.
  A device-neutral power-of-two divider produces exact BCLK=/16, while the
  XC7 wrapper promotes it through a BUFG. Independent three-stage reset
  pipelines assert asynchronously and release only on their local 49.152 MHz
  fabric or 3.072 MHz BCLK edge. The RTL test checks every BCLK period, both
  three-edge releases, and asynchronous reassertion. Yosys reports 10 FDCEs,
  one CARRY4, one BUFG, zero structural problems, and no warnings; its named-
  board timing is now included in the complete-wrapper route above.
- Added the first physical audio-clock implementation for the Nexys Video using
  only checked XC7 primitives and the open toolchain. Two cascaded MMCMs produce
  exact 12.288 MHz codec MCLK and 49.152 MHz fabric clocks from the board's
  100 MHz oscillator; a generated arithmetic contract rejects RTL parameter
  drift and now also rejects incorrect active-low G4 reset handling. An
  explicit XDC input constraint lets nextpnr derive the correct 12.288/49.152
  MHz domains. The three-iteration A200T route packs 99 LUTX, 24 FFX, six
  CARRY4s, two BUFGs, and two MMCMs; its activity counter passes the 49.152 MHz
  `DEFAULT`-grade constraint at 291.55 MHz. Project X-Ray emits
  a 9,730,853-byte bitstream with SHA-256
  `1d7d934fb1241213962d6d2a0ca29f1c57d8620573622ecca0b6c0b27234b248`,
  and `bitread -C` accepts 24,060 frames / 2,432,650 words. Codec
  configuration, shared I²S-clock wiring, programming, and frequency
  measurement remain unvalidated.
- Extended the selected 384 kHz / 49.152 MHz implementation from the
  three-pin timing harness through the real framed-audio hierarchy. The fabric
  adapter, asynchronous I²S bridge, register-owned controls, and mode-0 SPI
  transport now select the 8x rate explicitly while preserving the legacy
  16x default. The adapter matches 64 calibrated frames exactly; the pin test
  matches all 64 serial inputs and 44 observable DAC frames with one-frame
  FIFO high-water marks; the control and 15-frame SPI tests pass. Yosys 0.66
  measures 15,699 LC / 9,085 FF / 217 DSP / 10 RAMB18 equivalents for the
  adapter and 16,614 LC / 11,586 FF / 217 DSP / 10 RAMB18 equivalents for the
  complete SPI/I²S hierarchy. Both structural checks report zero problems;
  named-board clock generation, pin constraints, CDC timing, and hardware
  operation remain open.
- Corrected the retained 768 kHz pin-transport latency contract after locating
  its four-clock change at the circular-history decimator conversion. Each of
  the four 2x stages now performs its center tap in one dedicated clock, so
  calibrated model input to output-valid is 277 rather than the stale 273
  clocks. Audio values, first-nonzero index, and the 192-BCLK/three-sample
  serial frame-boundary latency remain unchanged.
- Added a reproducible, Vivado-free FASM-to-bitstream stage for the pinned XC7
  toolchain. `generate_openxc7_bitstream.py` invokes Project X-Ray's
  `fasm2frames` and `xc7frames2bit`, normalizes only variable `.bit` header
  timestamp metadata to a configurable epoch, uses a repository-relative
  source name, hashes every artifact, records both source/database revisions,
  and validates the result with `bitread -C`. The selected seed-1 route produces
  20,230 frame records and a 9,730,907-byte bitstream; two complete conversions
  are byte-identical at SHA-256 `98a53adf504a9a36669c34da59e6d1f185a4a67c8ba7de3aa4fab3c83a2b9dcb`.
  `bitread` accepts 24,060 configuration frames / 2,432,650 words. This is an
  artifact-generation result, not board programming or hardware validation.
- Closed the complete 48->384->48 kHz stream's 49.152 MHz open-flow timing
  target on XC7A200T without changing arithmetic or the 127-clock solver
  schedule. A selectable node-prefetch boundary captures the six raw tube nodes
  from the exact one-cycle-early chord preview, then performs the original node
  subtraction and Q conversion during the existing preview-to-launch interval.
  The 64-output/512-update stream remains bit-exact with zero diagnostics.
  Yosys measures 15,220 LC / 8,855 FF / 207 DSP / 10 RAMB18 equivalents and the
  open pack is 54,280 LUTX / 8,855 FFX / 3,979 CARRY4 / 207 DSP. The legal
  seed-1 router2 result completes in 23 iterations at 61.072 MHz versus
  49.152 MHz; its 16.37 ns terminal-current/state path contains 6.44 ns logic
  and 9.94 ns routing. Seed 2 independently closes in 14 iterations at
  51.080 MHz with a 19.58 ns registered-node-to-tube path. This is nextpnr
  `DEFAULT`-grade timing evidence, not
  qualified -1 signoff, a bitstream, or physical validation.
- Replaced the final-pass-only combinational KCL maximum with an optional
  low-state serial diagnostic. The correction result remains valid at the
  original 11-clock KCL latency while one unsigned comparator scans the nine
  stable residual rows and emits the exact maximum eight clocks later during
  terminal chord processing. All 1,024 backward-Euler and 1,024 384 kHz
  trapezoidal KCL vectors plus the complete 64-output/512-update stream remain
  exact at 127 solver clocks. Combined with late pin selection, Yosys measures
  15,208 LC / 8,657 FF / 207 DSP / 10 RAMB18 equivalents; the A200T pack falls
  to 54,699 LUTX / 8,657 FFX / 4,044 CARRY4 / 207 DSP. A legal 14-iteration
  route reaches 47.567 MHz, exposing a 21.02 ns chord-node-to-tube path instead
  of the removed maximum tree. It is retained for its exact low-area schedule,
  not promoted as timing closure.
- Added a zero-latency late tube-pin selector guided by the completed baseline
  route. Current and corrected stage-one tube pins are converted independently,
  then only the exact 32-bit `Vgk`/`Vpk` buses are selected; the numerical
  operations, output order, and 127-clock schedule are unchanged. The complete
  64-output/512-update stream is bit-exact with zero diagnostics. Yosys measures
  15,645 LC / 8,589 FF / 207 DSP / 10 RAMB18 equivalents and the A200T pack is
  56,549 LUTX / 8,589 FFX / 4,181 CARRY4 / 207 DSP. Seed 1 routes legally in
  28 iterations at 48.700 MHz against 49.152 MHz, moving the 20.53 ns critical
  path to the exact KCL maximum tree; seed 2 routes at 45.051 MHz. A seed-3
  route and a 16,120-LC/9,665-FF late-select-plus-deep-maximum profile were
  bounded after exceptionally slow router iterations and are retained only as
  incomplete congestion evidence. Timing closure and a bitstream are not
  claimed.
- Added route-guided tube-pin prefetch and diagnostic-only KCL maximum
  retiming experiments for the complete 49.152 MHz stream. The exact chord
  preview, backward-Euler/384 kHz KCL sideband, 512-sample solver, and
  64-output/512-update stream regressions all pass without changing the
  127-clock solver latency. The final sideband registers absolute value and
  each maximum-tree level while chord correction is active and suppresses a
  dead maximum-output load when diagnostics are disabled. Yosys measures
  15,852 LC / 9,793 FF / 207 DSP / 10 RAMB18 equivalents; the A200T pack is
  58,322 LUTX / 9,793 FFX / 4,258 CARRY4 / 207 DSP. Its legal 24-iteration
  route reaches only 47.07 MHz, with a 21.24 ns chord-preview-to-tube-input
  path, versus the selected baseline's 48.482 MHz. The prefetch family is
  therefore retained as rejected timing evidence and is not promoted.
- Completed the first legal route of the full 48->384->48 kHz nonlinear
  stream on XC7A200T using only Yosys, nextpnr-Himbaechel, and Project X-Ray.
  The circular-resampler design routes at 48.482 MHz against 49.152 MHz, a
  1.38% miss, with 56,041 LUTX / 8,589 FFX / 4,116 CARRY4 / 207 DSP. The
  20.626 ns critical path begins at solver state selection, crosses the
  corrected/current voltage mux and Q20 plate-voltage conversion, and ends in
  the first factorized-tube input mapping; logic/routing split is 6.19/14.44
  ns. This is route evidence, not timing closure or a bitstream claim.
- Added a separately named complete-stream profile that composes the already
  bit-exact parallel-tube, pipelined-KCL, decoupled-maximum, and pipelined-chord
  schedules. The same 64 outputs / 512 nonlinear updates remain exact with
  zero diagnostics at 123 clocks, but synthesis grows to 17,161 LC / 15,046
  FF / 242 DSP / 20 RAMB18 equivalents and A200T static placement falls to
  39.62 MHz. It is retained as measured scheduling evidence and is not the
  default or a promoted hardware architecture.

- Replaced each half-band interpolator's reset-cleared shift history with a
  reset-masked circular distributed memory. A single asynchronous read address
  is multiplexed between the serial MAC and pre-write odd-phase delay capture,
  preserving output order and latency. A reset-after-history regression covers
  both phases; unit, both 8x schedules, 16x conversion, and complete 384/768 kHz
  streams remain bit-exact. Yosys maps the 8x histories into 12 `RAM32M` plus
  11 `RAM64M` primitives. One stage measures 364 LC / 306 FF / 4 DSP, 8x is
  950 / 938 / 12, and 16x is 1,417 / 1,229 / 16. Complete 384/768 kHz synthesis
  falls to 15,716 LC / 8,547 FF / 207 DSP and 16,062 / 9,033 / 206. Static A200T
  placement packs at 56,041 LUTX / 8,589 FFX / 4,116 CARRY4 / 207 DSP and
  improves from 38.38 to 41.27 MHz against 49.152 MHz; timing remains open.

- Replaced every half-band decimator's reset-cleared shifting sample array with
  a circular history inferred as distributed RAM. An explicit valid-sample
  count provides architectural zero fill after reset while leaving physical
  memory bits unreset; a new reset-after-history regression proves that stale
  data cannot leak. Unit, 8x/16x converter, and complete 384/768 kHz streams
  remain bit-exact. A 79-tap stage falls from 1,284 LC / 2,753 FF to 349 / 214,
  the 8x decimator from 2,448 / 4,791 to 961 / 618, and the 16x decimator from
  3,000 / 5,615 to 1,408 / 817, with unchanged DSP counts. The complete 384 kHz
  stream drops from 17,693 LC / 14,737 packed FFX to 16,315 LC / 10,562 packed
  FFX; the refreshed complete 768 kHz stream is 16,704 LC / 11,282 FF / 206
  DSP. A200T heap placement now legalizes at 58,363 LUTX / 10,562 FFX / 4,099
  CARRY4 / 207 DSP, removing the prior decimator-FF placement blocker, but its
  22.79 MHz estimate still fails 49.152 MHz. Static placement reaches 38.38 MHz,
  effectively unchanged from the old 38.34 MHz result, with the decimator
  hierarchy reduced from 8,397 LUTX / 4,791 FFX to 2,725 / 618. Routing remains
  skipped.

- Extended the placed-JSON analyzer to separate complete-stream interpolator,
  decimator, and solver-control hierarchy, with flattened-name regression
  coverage. The half-clock static placement attributes 8,397 LUTX / 4,791 FFX
  / 12 DSP to the 244x143-coordinate decimator and 5,193 / 2,910 / 12 to the
  244x139 interpolator, identifying reset-cleared shifting histories as a
  measured congestion target rather than an assumed optimization.
- Added an explicit 49.152 MHz fabric schedule for the 384 kHz candidate. It
  scales the three interpolator enable phases to 1,024 clocks per external
  sample and 128 per nonlinear update without changing circuit arithmetic.
  Both interpolator schedules and the complete 64-output / 512-update stream
  are bit-exact with zero diagnostics; the solver consumes 127 of 128 clocks.
  A200T static placement reaches 38.34 MHz against 49.152 MHz, reducing the
  miss to 1.28x; the reduced-netlist heap placer still fails decimator-FF
  legalization, so routing and promotion remain open.
- Added a complete three-pin 384 kHz stream timing harness and exposed
  nextpnr's heap/SA/static placer selection. The reduced-DSP design packs on
  XC7A100T at 63,902 LUTX / 14,737 FFX / 4,071 CARRY4 / 207 DSP but heap
  placement does not legalize. The independent static placer legally places
  it on XC7A200T at only 34.40 MHz versus 98.304 MHz under the experimental
  `DEFAULT` grade; routing is skipped after the 2.86x miss.
- Serialized each half-band decimator's center tap through its existing MAC,
  capturing the pre-shift history operand explicitly. The unit, 8x/16x chain,
  and complete nonlinear-stream regressions remain bit-exact. Decimator DSP
  use falls from 24 to 12 at 8x and 32 to 16 at 16x; controlled complete-stream
  synthesis is now 17,693 LC / 207 DSP at 384 kHz and 18,280 / 206 at 768 kHz.
  Refreshed flattened integration results are 18,642 LC / 16,354 FF / 216 DSP
  for the fabric adapter, 19,156 / 17,669 / 216 for the I²S top, 19,616 /
  18,684 / 216 for the controlled top, and 19,719 / 18,856 / 216 with SPI.
- Added an automated absolute record-pop comparison between the 384/768 kHz
  floating trapezoidal paths and ngspice. Each SPICE run is driven by the
  corresponding interpolated INPUT-node PWL, paired with a matched 5 mV/1 kHz
  control, and passed through the matching decimator. With no latency, gain, or
  DC fitting, external residual is -61.47/-61.00 dB and maximum error is
  0.539/0.546 mV at 384/768 kHz; both solves converge. This closes the prior
  absolute-transient evidence gap but does not promote 8x before timing closes.
- Adopted a fully open Linux FPGA implementation path. A pinned non-root
  bootstrap now builds nextpnr-Himbaechel for XC7A100T against Project X-Ray,
  and `run_openxc7.py` probes versions then composes Yosys synthesis with
  deterministic named-part packing, placement, routing, FASM, log, and JSON
  report generation. Added a three-pin Arty-A7-100 timing harness around the
  complete 127-clock trapezoidal/banked/terminal solver so its internal
  arithmetic can be routed without turning wide diagnostic buses into package
  pins. The backend is explicitly experimental and reports a `DEFAULT` timing
  grade; no qualified XC7A100T-1 or bitstream claim is inferred.
- The first accuracy-first solver harness packs on `xc7a100tcsg324-1` at
  50,789 `SLICE_LUTX`, 6,372 flip-flops, 3,770 CARRY4, 174 DSP48E1, eight
  RAMB18E1, and one RAMB36E1. Seed-1 placement reaches only 13.90 MHz against
  98.304 MHz. A controlled value-only tube substitution later reaches only
  13.67 MHz at placement, so the earlier Hermite-path diagnosis is explicitly
  rejected rather than preserved as a convenient explanation. Both are
  retained as failing timing baselines, not qualified speed-grade signoff.
- Added a bit-exact iterative Q0.16 cubic-Hermite kernel that preserves the
  established signed-32 wrap and add-half rounding contract while scheduling
  one full-width 32x17 multiply per clock. It passes 4,096 deterministic
  full-range vectors, in-flight reset, ignored-start, and all 4,110 existing
  factorized-tube vectors at a three-clock kernel latency. Yosys measures 265
  logic cells and two DSP48E1s out of context. Its three-pin harness routes on
  `xc7a100tcsg324-1` at 132.54 MHz against 98.304 MHz using nextpnr's
  experimental `DEFAULT` grade (886 packed LUT elements, 231 FFX, 49 CARRY4,
  two DSPs). The kernel is not yet substituted into the tube/solver: its added
  dependency latency must first be reconciled with the 127-clock deadline.
- Added a separately selectable value-only factorized 12AX7 candidate rather
  than changing reference mode. Measured 1,024/8,192/4,096-point reciprocal,
  softplus, and power tables retain the Koren law and eight-clock interface
  while trading 458,752 raw table bits for linear interpolation. A 100,000-
  point fixed probe measures 4.95 nA mean, 7.87 nA RMS, and 47.49 nA worst
  plate-current error. The RTL passes 4,110 tube vectors and both 512-vector
  wide/terminal solver regressions exactly at 116/127 clocks. The isolated
  tube routes at 113.24 MHz (`DEFAULT` grade) with 27 DSP48E1s; complete solver
  synthesis falls from 174 to 166 DSPs, but full placement reaches only 13.67
  MHz versus the Hermite solver's 13.90 MHz. It is therefore not promoted to
  the reference/default path; full routing remains in progress for detailed
  path evidence.
- Factored the ten parallel trapezoidal terminal-current recomputations into a
  separately routable, bit-exact module and added terminal-current, KCL, and
  chord timing harnesses to the open flow. Both 512-vector solver regressions
  retain 116/127-clock latency. The isolated terminal block uses 54 DSP48E1s;
  replacing its serial diagnostic overflow sum with an explicitly widened
  balanced popcount improves post-route timing from 51.95 to 88.83 MHz while
  preserving exact results. This still fails the 98.304 MHz target and is not
  represented as solver closure.
- Completed the first block-level solver timing diagnosis. The isolated banked
  chord corrector routes at 46.40 MHz, while the original 72-DSP wide KCL
  engine routes at 16.64 MHz with a 60.09 ns accumulator-to-global-fallback
  cone, establishing KCL rather than tube interpolation as the primary whole-
  solver limiter. Capacitor 9 is now captured during the first matrix column,
  the final physical residual is registered in the existing second-tube wait
  window, and serial fit/max/saturation reductions are balanced. The 1,024-
  vector backward-Euler and trapezoidal regressions now cover tube-result
  delays through 19 clocks and remain exact; the complete 512-vector terminal
  solver remains exact at 127 clocks. Revised KCL placement improves from
  14.95 to 33.92 MHz; its legal route is still in progress and no closure is
  claimed.
- Added an explicitly selectable parallel dual-triode solver schedule. Two
  identical factorized Hermite primitives now evaluate the two physical 12AX7
  sections from the same candidate node vector, preserving all reference
  arithmetic and circuit state. The 512-vector backward-Euler and complete
  trapezoidal/banked/terminal regressions remain bit-exact while latency falls
  from 116/127 to 84/95 clocks. A dedicated open-flow harness synthesizes to
  15,887 estimated logic cells, 7,360 flip-flops, 209 DSP48E1s, 16 RAMB18E1s,
  and two RAMB36E1s. This fits the XC7A100T structurally and recovers 32 clocks
  for network pipelining; placement and Fmax are not yet claimed.
- Added independently selectable, bit-exact pipeline schedules for KCL column
  issue/round/accumulate, KCL residual conversion/fallback/saturation, and
  chord scale/update/saturation. Default 11-clock KCL, 10-clock chord, and
  127-clock terminal paths remain exact; the all-pipelined parallel solver is
  exact across 512 stateful vectors at 119 clocks. Its Yosys harness measures
  16,348 LC, 12,378 FF, 209 DSP48E1, and 20 RAMB18 equivalents. The isolated
  chord now routes at 100.92 MHz versus 46.40 MHz originally, closing the
  98.304 MHz request under the experimental `DEFAULT` grade. The 72-DSP KCL is
  exact at 15 clocks but places at only 38.95 MHz; router2 was stopped after
  the placement miss, so neither KCL nor full-solver timing closure is claimed.
- Continued KCL timing work from completed legal routes rather than placement
  estimates. The 15-clock pipeline routes at 42.07 MHz with the exact nine-row
  maximum diagnostic as its critical cone. Added selectable accumulator,
  capacitor-current, and final-only maximum boundaries; only the maximum is
  enabled on the solver pass that consumes it. Replaced generic signed-25
  magnitude comparisons with an exactly equivalent sign-extension test and
  proved all 1,024 backward-Euler, 1,024 trapezoidal, and 512 integrated vectors
  bit-exact, including directed fallback/saturation cases. Successive legal KCL
  routes improve to 64.90, 72.31, and 92.23 MHz. The selected 126-clock solver
  synthesizes to 14,990 LC / 13,458 FF / 209 DSP / 20 RAMB18 equivalents; its
  complete route and the remaining 6.6% isolated-KCL gap remain open.
- Added a first-class placement-only stage to the open XC7 runner. It writes
  stage-specific placed JSON, timing log/report, and compact summary, parses
  placement Fmax when nextpnr's pre-route JSON omits it, removes stale stage
  artifacts, and never labels placement as a completed route. Added a placed-
  hierarchy analyzer for resources, bounding boxes, and hard-block centroids.
  The full 126-clock solver reproducibly packs to 59,027 LUTX / 13,458 FFX /
  4,036 CARRY4 / 209 DSP and places at only 34.20 MHz, so routing is skipped.
  Region analysis shows KCL and terminal-current spread across most DSP rows;
  isolated 92.23 MHz KCL timing therefore does not compose on XC7A100T.
- Extended the pinned open-XC7 bootstrap and runner to device-qualified
  XC7A200T builds, added the Digilent Nexys Video timing-only pin harness, and
  retained separate artifacts for each named part. The unchanged solver packs
  at 59,027 LUTX / 13,458 FFX / 4,036 CARRY4 / 209 DSP, which is only 28% of
  XC7A200T DSP capacity. Nevertheless, seed-1/default placement reaches 23.83
  MHz, seed 2 reaches 30.55 MHz, and seed 1 with heap timing weight 20 reaches
  only 35.22 MHz against 98.304 MHz. Routing is skipped: larger-part capacity
  alone is now measured and rejected as a timing remedy.
- Added a selectable two-batch terminal-current engine that overlaps its first
  five lanes with the pipelined chord preview and registers the second five
  before a dedicated final commit. Explicit fixed lane-pair muxes avoid the
  variable-index LUT explosion found by synthesis. The engine is bit-exact for
  1,027 standalone vectors; the complete solver is exact for 512 stateful
  vectors at 127 clocks. The isolated route uses 4,296 LUTX / 2,412 FFX / 334
  CARRY4 / 34 DSP and reaches 90.50 MHz at the default placement weight. A
  reproducible timing-weight-20 run closes the isolated 98.304 MHz constraint
  at 99.59 MHz. Whole-solver synthesis falls from 209 to 189 DSPs, but seed-1
  default-weight placement reaches only 25.02 MHz with 59,514 LUTX / 14,590 FFX
  / 3,964 CARRY4. The candidate is retained for reproducible resource evidence
  but is not promoted because it worsens full placement.

- Added validated open-XC7 experiment tags so tuning runs retain separate
  netlists, placed designs, logs, reports, and summaries. A tagged
  timing-weight-20 placement improves the 189-DSP shared-terminal solver from
  25.02 to 32.56 MHz, but still misses 98.304 MHz and remains below the selected
  209-DSP baseline's 34.20 MHz. Region analysis shows the terminal DSP span
  expands to 91 by 167 coordinates, rejecting placer-weight tuning as the
  hierarchy-congestion fix.

- Added nextpnr pre-place hook support and an XC7A100T overlapping hierarchy
  floorplan. KCL/RHS are constrained to the left/center DSP columns and tube,
  chord, and terminal-current blocks to the center/right columns, with control
  logic left free. The hook matches 61,934 packed hierarchy cells and improves
  the shared solver from 32.56 to 36.83 MHz while reducing annealed wire length
  from 3,010,517 to 2,006,868 units. The remaining 2.67x timing gap rejects
  floorplanning alone; routing remains skipped.

- Added a first-class pack-only open-XC7 stage that writes a packed netlist,
  exact utilization report, and tagged summary while explicitly withholding
  placement, routing, and timing claims. Added a selective Yosys experiment
  that stops before DSP mapping, asserts exactly eleven KCL multipliers, maps
  them to soft logic, and resumes the standard XC7 flow without changing RTL
  arithmetic. Isolated KCL packs legally at 71,592 LUTX / 10,436 FFX / 1,843
  CARRY4 / 0 DSP; the complete shared solver packs at 101,479 LUTX / 14,590 FFX
  / 3,993 CARRY4 / 117 DSP. Two exploratory isolated placements did not reach
  timing analysis in a useful interval, so no Fmax is reported and the
  80%-LUT complete candidate is not promoted.

- Added an asserted capacitor-only KCL soft-multiplier scope. It remaps exactly
  the two 48x44 products while leaving nine matrix products DSP-backed.
  Isolated packing uses 36,327 LUTX / 10,436 FFX / 1,798 CARRY4 / 54 DSP.
  Seed 1 and its ineffective timeout-divisor retry fail the same 10,001-attempt
  FFX legalization; seed 2 completes placement at only 37.57 MHz, so routing is
  skipped. The complete candidate packs at 66,341 LUTX / 14,590 FFX / 3,948
  CARRY4 / 171 DSP. This smaller 18-DSP exchange is also rejected because its
  unpipelined soft products materially worsen isolated timing.

- Decoupled the final-only exact KCL maximum diagnostic from the correction
  result that feeds chord. A separate `max_valid` sideband completes two clocks
  after the 16-clock correction while holding the KCL engine busy. Both 1,024-
  vector integration-mode regressions and the 512-sample stateful solver remain
  bit-exact, including diagnostics, and the full schedule falls from 126 to 123
  clocks. The isolated candidate packs to 29,569 LUTX / 10,437 FFX / 1,814
  CARRY4 / 72 DSP and routes legally at 87.07 MHz; timing-weight-20 placement
  reaches only 80.03 MHz. The complete 209-DSP hierarchy packs to 59,188 LUTX
  and places at 31.97 MHz. The five recovered clocks are retained for broader
  arithmetic scheduling, but no timing-closure claim is made.

- Added selectable, cycle-free KCL capacitor-multiplier sharing. Capacitor
  branch 9 is prefetched from the accepting request buses, after which its
  48-by-44-bit multiplier is reused for branches 0--8. Both 1,024-vector KCL
  modes remain bit-exact at 16 correction clocks and the 512-vector full solver
  remains exact at 123 clocks. Isolated/full DSP use falls from 72/209 to
  63/200, but placement reaches only 72.95/35.06 MHz; a tagged full timing-
  weight-20 run falls to 29.05 MHz. Composing the same KCL schedule with the
  two-batch terminal-current engine is exact at 124 clocks and 180 DSPs, yet
  default and overlapping-region placements reach only 30.63/32.94 MHz. These
  are retained as reproducible area results, not timing closure or a reference-
  circuit change.

- Added reproducible 384 kHz fixed-point and RTL assets for the explicitly
  non-reference 8x candidate. The lower-rate chord bank is measured at
  -23,414..+146,717 Q17.1 and therefore uses signed 19-bit coefficients with an
  exact 44-bit product, while 768 kHz remains signed 18 bit. Verilator matches
  1,024 all-bank chord, 1,024 KCL, and 512 persistent full-solver vectors
  exactly at 10/11/127 clocks;
  the solver records a 4.565 nA maximum preterminal residual and zero
  diagnostics. Rate-specific Yosys synthesis measures 13,713 LC / 183 DSP / 10
  RAMB18 equivalents, versus 13,158 / 174 / 10 for the controlled 768 kHz
  build. The verified reference stream remains 16x pending complete 8x
  converter, transient, recovery, and alias proof.

- Added separate three-stage `interpolator_8x` and `decimator_8x` RTL for the
  384 kHz candidate. Exact regressions match 1,024 interpolation and 128
  decimation outputs with zero saturation, overrun, or phase errors and measure
  eight 384 kHz samples (20.83 us) of interpolation scheduling delay. Yosys
  initial structural synthesis reported 1,549 LC / 12 DSP and 2,355 LC / 24
  DSP, respectively; later center-tap sharing supersedes the decimator count.

- Composed the three-stage converters with the rate-specific 384 kHz
  banked-terminal nonlinear core. The generalized fixed reference and
  SystemVerilog stream match 64 external outputs across 512 persistent solver
  updates exactly, including all converter, solver, and deadline diagnostics.
  Initial controlled Yosys 0.66 XC7 builds measured 17,629 LC / 219 DSP / 10 RAMB18
  equivalents at 384 kHz versus 18,302 / 222 / 10 for the selected 768 kHz
  stream; later center-tap sharing supersedes both resource counts. The 8x path remains an explicit non-reference candidate pending
  transient alias, overload recovery, and named-part timing evidence.

- Extended the internal-rate study through complete fixed-stream synthetic-pop
  and accepted-range 0.5 V overload/control pairs. Across 772,608 nonlinear
  updates both rates remain diagnostic-clean and the 8x recovery crossing is
  0.1875 ms later. The initial linear fractional-delay interpolation produced
  invalid near-Nyquist residual magnitudes; the correction below supersedes
  those values rather than preserving them as acceptance evidence.

- Added direct long-vector RTL proof for the rate-study transients. Both
  complete streams match 4,096 synthetic-pop and 8,192 overload/recovery fixed
  outputs exactly, totaling 24,576 external outputs / 294,912 nonlinear
  updates with zero diagnostics and 127-clock latency. Maximum solver residual
  is 0.672 uA at 384 kHz and 0.322 uA at 768 kHz. This closes RTL transcription
  as an explanation for the pop discrepancy; it does not promote 8x.

- Corrected the transient A/B methodology after layer decomposition exposed
  linear fractional-delay interpolation as the dominant measurement artifact.
  Added explicit caller-known latency and a 64-tap Lanczos-windowed sinc method;
  a 997/7,013/17,003 Hz regression nulls below -70 dB and improves over linear
  interpolation by more than 40 dB. With the independently known -1.25-sample
  converter delay, pop error is -35.92 dB overall, 2.623 mV peak, and -53.33 dB
  in-band; recovery is -84.71 dB overall / -81.02 dB in-band. A separate
  393,216-update decomposition measures converter/floating/fixed in-band error
  at -67.49/-55.71/-53.33 dB and same-rate fixed/float at about -59 dB. The
  prior -15.18 dB / 85.6 mV claim is explicitly invalidated.

- Added a reproducible 384 kHz/8x architecture study while retaining
  768 kHz/16x as reference mode. The SPICE comparison now measures the lower-
  rate trapezoidal model at 10 and 20 kHz: maximum error is 0.06653 dB and
  0.02234 degree, versus 0.00846 dB and 0.0582 degree at 768 kHz. A new exact-
  window nonlinear-rate script compares the Koren law and complete circuit
  through the matching three- or four-stage half-band decimators. At 20 kHz,
  complete-circuit selected 4/8/12/16 kHz products remain within 0.52 dB of
  16x for 5 mV, 20 mV, and steady 0.5 V, with zero failed solves; a hot static-
  tube stress is 11.33 dB worse but remains -118.65 dBc. The resulting 256-
  cycle scheduling option remains unimplemented pending fixed-point, transient,
  recovery, and RTL proof.

- Added a bounded arbitrary-pin formal contract for the oversampled mode-0 SPI
  control transport. Eleven assertions cover the two-stage pin synchronizers,
  0--80 bit-count bound/transition, one-cycle request decode and exact fields,
  mutually exclusive response states, saturating completed-frame count, frame
  reset, and exact diagnostic clear/error precedence through 32 fabric clocks.
  A separate 100-step trace reaches a decoded request plus short-frame and
  response-underflow evidence. The existing eight complete transactions remain
  the byte-order/full-frame check; unbounded induction, placed SCLK limits, and
  analog asynchronous-input behavior are not claimed.
- Added exhaustive formal contracts for both converter-calibration arithmetic
  boundaries. Twelve assertions prove the PCM24-to-Q8.24 valid-coefficient
  shifted product always fits signed 32 bits, exact registered valid/output/
  hold behavior, Q8.24-to-PCM24 clipping at both signed endpoints, and exact
  clear/increment/saturation/sticky diagnostic transitions for arbitrary
  samples and signed coefficients. Yosys 0.66 SAT temporal induction closes at
  depth 2; a separate trace reaches an input endpoint, output saturation, and
  both invalid-configuration stickies. The existing 4,159-vector-per-direction
  Python/RTL test remains the bit-accurate implementation comparison.
- Added a bounded arbitrary-clock formal contract for the BCLK-rate monitor
  used by the modern fail-closed mute guard. Sixteen assertions cover exact
  BCLK binary/Gray evolution, both synchronizer stages, measurement cadence,
  inactive/activation/window transitions, measured delta, lock qualification
  and drop, counter saturation, and sticky-error clear precedence through 32
  global steps in a reduced-parameter instance. A separate 48-step trace first
  acquires lock and then retains an out-of-tolerance error while unlocked. This
  proves digital state-machine safety, not Gray-bus placement, metastability,
  absolute clock accuracy, or progress when either clock stops.
- Added a bounded arbitrary-clock formal contract for the low-rate toggle-pulse
  CDC used by diagnostic clear. Ten embedded/harness assertions cover exact
  toggle and three-stage destination transitions, pulse decode/width, at-most-
  one outstanding event, no fabricated delivery, and exact delivery accounting
  through 40 global steps when a source event waits for the preceding event to
  be observed. A separate trace delivers two events. The directed RTL test now
  makes the reset contract explicit: destination reset while the source toggle
  is odd replays the idempotent command once after release. This is not an
  arbitrary-rate event channel or an analog-metastability proof.
- Added a bounded arbitrary-clock formal contract for the coherent held-bus CDC
  snapshot. Nine embedded/harness assertions cover capture-event provenance,
  destination hold stability, exact returned data, one-cycle valid behavior,
  request/completion accounting, and idle only after completion through 40
  global steps. A separate satisfiable trace transfers nonzero `0xa` data and
  returns to idle. This digital safety result assumes one disciplined shared
  startup reset; destination reset during an active request remains covered by
  the directed RTL regression, and analog metastability is not modeled.
- Added a formal frame-scheduler contract. Nine arbitrary-source assertions
  cover reset phase, deterministic wrap, ready/valid/present launch strobes,
  accepted data, zero fill, and exact clear/increment/saturation behavior of the
  32-bit underflow count. Yosys 0.66 SAT temporal induction closes at depth 2;
  a separate trace reaches an absent boundary followed by a present launch.
- Added a formal contract for atomic converter-calibration commits. Twelve
  arbitrary-input assertions cover reset, exact acknowledgment, simultaneous
  positive-pair commit only while muted, rejected-state immutability, invalid/
  unsafe sticky accumulation, and clear precedence. Yosys 0.66 SAT temporal
  induction closes at depth 2; a separate trace reaches invalid rejection,
  accepted commit, and unsafe rejection. The claim remains local to the guard,
  not the host transport or physical converters.
- Added a bounded multi-clock formal environment for the asynchronous FIFO.
  Thirteen embedded/harness properties cover Gray transitions, blocked
  pointers, occupancy/watermark bounds, read-valid timing, and diagnostic
  sticky/clear behavior for every arbitrary clock/control interleaving through
  32 global steps after disciplined reset. A separate 24-step satisfiable trace
  reaches depth four plus overflow and underflow evidence. The result is
  deliberately labeled bounded; the current invariant set does not close
  unbounded induction and SAT does not model analog metastability.
- Added a reproducible formal contract for the modern output mute/ramp. Fifteen
  assertions cover reset, force clamp, valid timing, held state, exact
  saturating gain transitions, endpoint output, monotonicity, and status under
  arbitrary post-reset inputs. Yosys 0.66 SAT closes temporal induction at
  depth 2; a separate satisfiable trace reaches unity in four accepted samples
  to rule out a vacuous reset environment. `make formal-mute` runs both checks
  and retains logs without extending the result to CDC or physical protection.
- Integrated coherent I²S FIFO levels/high-water marks into the atomic control
  snapshot. Snapshot commands now commit the retained image and saturating
  sequence only after the held-bus CDC returns; live status reports busy and
  capture availability. A default 131,072-clock timeout preserves the previous
  image/sequence and latches explicit evidence. Unit/integration tests cover
  busy rejection, stopped-BCLK timeout, later re-arm, captured timeout evidence,
  and clear. The Python client polls completion and rejects stale results. The
  22-word map adds packed I²S diagnostics at `0x35`, and the compatible ABI
  minor is now 1.1. XC7 structural synthesis is 354 LC / 735 FF for the register
  bank, 21,466 LC / 17,922 FF for the controlled hierarchy, and 21,589 LC /
  18,094 FF with SPI; the complete variants retain 232 DSP48E1 /
  8 RAMB18E1 + 1 RAMB36E1 and zero structural-check problems.
- Added a reusable 16-bit held-bus CDC snapshot primitive. Its four-phase
  request/acknowledge handshake holds destination data stable through two
  source-clock synchronizer stages and one final settling clock. Three exact,
  warning-free captures cover unrelated clocks and destination reset during an
  active request. XC7 structural synthesis is 5 LC / 75 FF / no DSP or RAM with
  zero warnings/problems; register-bank integration is intentionally separate.
- Added `fpga_amp.host_control`, a dependency-free host definition of the
  ten-byte full-duplex SPI/register ABI. It validates identity, ABI,
  capabilities, lengths, reserved status, and bus errors; makes mute ownership
  explicit for snapshot/clear commands; and guards atomic calibration
  commit/poll/sequence handling. Six fake-link unit tests cover exact wire
  bytes and accepted/error paths without claiming a physical adapter backend.
- Added fail-closed BCLK-rate muting to the register-controlled pin wrapper,
  explicitly outside the historical model. Output is immediately clamped until
  three good clock windows qualify. A stopped/bad BCLK reasserts the clamp, and
  retained error evidence prevents automatic unmute after clock recovery until
  a host clear. A shortened-window end-to-end regression proves qualification,
  stopped-clock detection, reacquisition, coherent fault snapshot, and exact
  fabric/I²S clear delivery without stopping model scheduling or filling the
  receive FIFO. Updated flattened XC7 synthesis is 21,375 LC / 17,787 FF for
  the controlled hierarchy and 21,507 LC / 17,959 FF with SPI; both retain
  232 DSP48E1 / 8 RAMB18E1 + 1 RAMB36E1 and have zero structural-check
  problems.
- Added the complete SPI-controlled pin hierarchy. `phono_i2s_spi_top` connects
  the oversampled mode-0 transport to the atomic register/calibration bank and
  I²S/model path. A warning-free 15-frame test covers startup calibration,
  register readback, two retained diagnostic images across a live force-mute
  change, a retained aborted-frame fault, snapshotted transport count, and one
  fabric-to-BCLK diagnostic clear.
  The snapshot aperture grows to 21 words and now records transport faults and
  completed frames. Flattened XC7 structural synthesis is 21,506 LC /
  17,959 FF / 232 DSP48E1 / 8 RAMB18E1 + 1 RAMB36E1 with zero structural-check
  problems; named-part SCLK, CDC, I/O, and fabric timing remain unproven.
- Added a mode-0 SPI transport that oversamples asynchronous pins in the fabric
  domain and never creates a derived clock. Fixed 80-bit transactions carry a
  40-bit write/address/data request followed by status plus 32-bit read data.
  Warning-free integration drives eight 5 MHz transactions through the real
  register bank and calibration guard, retaining short-frame and withheld-
  response diagnostics and returning bad-address status. Standalone XC7
  synthesis is 112 LC / 172 FF / no DSP or RAM; no placed SCLK limit is claimed.
- Added a register-controlled pin-facing wrapper. Its 20-word snapshot includes
  every fabric counter, clock status, fabric FIFO levels, solver residual, and
  safely synchronized sticky I²S faults while deliberately excluding unsafe
  multibit I²S levels. A 1-LC / 5-FF toggle crossing delivers each diagnostic-
  clear command once to BCLK. Warning-free integration proves bus-owned startup
  calibration, untorn snapshots, force-mute capture, and clear CDC. Complete XC7
  structural synthesis is 21,363 LC / 17,755 FF / 232 DSP48E1 /
  8 RAMB18E1 + 1 RAMB36E1; named-part timing and the subsequently added host
  transport composition were still open at this layer.
- Added a protocol-neutral fabric control register bank. It resets muted,
  snapshots 16 moving diagnostic words atomically, saturates snapshot/commit
  sequences, holds a coherent two-word converter-calibration shadow pair, and
  distinguishes accepted, invalid, unsafe, busy, and malformed transactions.
  Warning-free Verilator covers retained snapshots, two diagnostic clear pulses,
  and the real calibration guard. XC7 structural synthesis reports 323 LC /
  715 FF / no DSP or block RAM with one expected snapshot-array expansion
  warning and no timing claim.
- Added reproducible schedule-neutral terminal-solver rejection studies.
  Corrected-state bank reselection improves the 1.0 V burst by only 0.101 mV
  while worsening the 1.5 V and recovery results. Unconditional 5/4 terminal-
  residual scaling reduces burst RMS to 3.570/3.454 mV but worsens late state;
  cutoff-only scaling does not preserve the benefit. Full dual-triode median
  Jacobians do not generalize, while stage-one-split banks create 58 residual-
  limit misses and about 6.12 mV burst error at 1.5 V. All tests retain raw,
  unaligned metrics and leave the physical reference, production bank, unity
  correction, and 127-clock implementation unchanged.
- Extended the original deterministic PCM24 suite from nine to fourteen
  vectors. The exact fixed stream now processes 69,440 external frames /
  1,111,040 nonlinear updates with zero diagnostics or WAV clips. A 60 Hz/
  7 kHz, 4:1 SMPTE-RP-120-style profile reports 0.461295% first/second
  sideband-pair IMD while explicitly declining calibrated conformance; a paired
  5 mV one-sample impulse is exactly zero before the event, crosses four output
  LSBs after 34 samples, and peaks at 138.118 mV; paired nominal/0.5 V, 250 ms
  records measure final 1 ms RMS-threshold recovery at 147.750 ms relative to
  the input burst stop and 18.650 mV RMS deviation over the final 10 ms.
  Known-signal unit tests prove ideal AM-depth recovery and final-crossing
  semantics, including a synthetic late rebound.
- Added a Gray-counter BCLK/fabric rate monitor to the pin top. The default
  fabric window requires 1,024 ± 1 BCLK edges and three consecutive good
  windows for lock; one bad window immediately drops lock and latches an error.
  Warning-free directed RTL locks on exact 10-edge short windows, observes 11
  after a deliberate speed-up, recovers after three restored windows, clears
  the sticky diagnostic, detects stopped BCLK as a zero-edge bad window, and
  revokes live state on BCLK reset. The actual-rate
  pin test measures exactly 1,024 edges in all four observed windows without
  changing latency or PCM. Warning-free standalone synthesis is 68 LC / 125 FF
  / no DSP or RAM; the updated pin top is 21,014 LC / 16,907 FF / 232 DSP48E1 /
  8 RAMB18E1 + 1 RAMB36E1.
- Added conservative local-domain FIFO occupancy and high-water diagnostics.
  Gray-to-binary conversion uses only the already synchronized remote pointer;
  write-side estimates may lag reads high and read-side estimates may lag writes
  low, so no coherent cross-domain snapshot is claimed. The depth-8 unit reaches
  exactly eight, drains to zero, clears both watermarks, and preserves 128-word
  wrap ordering. Both bridge and actual-rate pin regressions remain warning-free;
  deliberate bridge backpressure reaches RX 3/3 and TX 4/4 frames without loss,
  while all four locked-rate pin views peak at one frame. Updated synthesis is
  127 LC / 331 FF for one 8×32 FIFO, 571 LC / 1,547 FF for the bridge, and,
  with the later rate monitor, 21,014 LC / 16,907 FF / 232 DSP48E1 /
  8 RAMB18E1 + 1 RAMB36E1 for the pin top.
- Added a protocol-neutral atomic converter-calibration commit guard. The two
  active Q8.24 coefficients reset to zero and change together only for a
  positive candidate pair while the digital output is fully muted. Directed
  warning-free RTL proves invalid rejection, muted commit/acknowledgment, live
  rejection without active-value change, and diagnostic clear. The pin-level
  regression now commits its startup pair before audio-state release and
  rejects a later live update. Standalone XC7 synthesis is 14 LC / 67 FF / no
  DSP or RAM with zero warnings and structural problems; the later
  clock-monitored pin top is 21,014 LC / 16,907 FF / 232 DSP48E1 /
  8 RAMB18E1 + 1 RAMB36E1.
- Added the pin-facing digital mono top that composes the asynchronous I²S
  bridge with the calibrated accuracy-first adapter. An exactly rate-locked but
  phase-offset 3.072/98.304 MHz test pre-fills receive CDC, releases audio state,
  matches all 64 calibrated serial inputs and raw model outputs, and recovers 45
  consecutive observable DAC frames as exact mono duplicates. Expected startup
  serial starvation is retained and every other diagnostic stays zero.
  With the later integrated safety, calibration, and clock diagnostics,
  flattened XC7 synthesis is 21,014 LC / 16,907 FF / 232 DSP48E1 /
  8 RAMB18E1 + 1 RAMB36E1; converter selection, placed timing, physical analog
  mute, and validation remain open.
- Added the calibrated fabric mono adapter around the exact
  trapezoidal/banked/terminal V1 stream. It selects left PCM24, schedules and
  calibrates physical input volts, runs the nonlinear circuit, calibrates the
  line-voltage result, holds ready/valid output, and explicitly duplicates mono
  into both slots without claiming stereo. A warning-free 64-frame regression
  checks every calibrated input, raw model output, and PCM frame exactly under
  output backpressure, then records/clears a directed overrun while retaining
  the older frame; all model/calibration diagnostics stay zero. Holding the core reset through
  initial phase acquisition fixes the observed hidden capacitor-state advance
  from pre-input interpolator zeros. The later integrated modern output ramp
  starts muted and reaches exact unity before reference comparison. Flattened
  XC7 synthesis is 20,489 LC / 15,592 FF / 232 DSP48E1 /
  8 RAMB18E1 + 1 RAMB36E1; no Fmax is claimed.
- Added a deterministic fabric audio-frame scheduler for the strict 2,048-clock
  48 kHz core phase. It raises ready once per period, prelaunches by the
  registered calibration latency, injects a zero frame on starvation, and
  retains a saturating underflow count. Warning-free directed RTL proves held
  ready/valid transfer and phase-zero A/zero/B order; XC7 synthesis is 41 logic
  cells / 43 flip-flops / no DSP or RAM. It is explicitly not an ASRC.
- Added bit-accurate converter calibration models and synthesizable RTL.
  PCM24 maps to input-referred Q8.24 physical volts using explicit measured
  peak-voltage scaling; Q8.24 line voltage maps through an explicit reciprocal
  coefficient to saturating PCM24. Full products, symmetric nearest rounding,
  saturating counters, invalid-coefficient muting, and one-clock latency match
  across 4,159 vectors per direction. Warning-free XC7 synthesis reports input
  95 LC / 66 FF / 4 DSP48E1 and output 86 LC / 58 FF / 4 DSP48E1, with no RAM
  and no timing claim.
- Added a bidirectional stereo I²S/fabric bridge around the protocol primitives
  and two depth-8 × 64-bit asynchronous FIFOs. Warning-free simulation preserves
  20 exact frames across unrelated clocks and deliberate receive backpressure,
  checks six bridge diagnostics, and clears expected startup starvation in its
  owning domain. With later occupancy instrumentation, flattened XC7 synthesis
  is 571 logic cells / 1,547 flip-flops /
  no DSP or RAM with explicit small-memory register expansion. Post-map
  flattening also prevents the resource reporter from omitting instantiated
  primitive registers; a rejected intermediate 67-FF count is not retained.
- Added conventional 24-bit stereo I²S receive/transmit primitives in 32-BCLK
  slots. Warning-free loopback verifies 16 signed frames, independent slot/delay
  timing, LRCLK framing faults, and starvation; warning-free XC7 synthesis is
  35 LC / 105 FF receive and 97 LC / 137 falling-edge FF transmit with no DSP or
  RAM. The resource parser now counts negative-edge Xilinx flip-flop variants.
- Added a device-neutral asynchronous FIFO with binary/Gray pointers, two-flop
  pointer synchronization, registered reads, sticky per-domain overflow/
  underflow, and embedded formal invariants. Unrelated-clock simulation covers
  exact fill/drain faults and 128 wrapped words; generic XC7 synthesis reports
  127 logic cells / 331 flip-flops with later occupancy watermarks and the small memory explicitly expanded to
  registers and zero structural problems.
- Added simultaneous least-squares tone, H2--H10 THD, and explicitly selected
  intermodulation-product measurement plus nine original PCM24 fixtures. The
  accuracy-first fixed stream processes 32,448 outputs / 519,168 internal
  updates with zero diagnostics or clips; measured WAV-boundary THD is
  0.019826% at 5 mV peak and 0.011559% at 0.5 mV peak. High-frequency product
  bins are retained without mislabeling them as a standards-compliant scalar.
- Added dependency-free 16/24/32-bit integer PCM WAV I/O, an offline 48 kHz
  fixed-V1 processor with mandatory peak-voltage mappings and per-channel
  diagnostics, and explicit latency/gain/fractional-delay null comparison with
  residual WAV and spectrum outputs. A 1,024-frame synthetic terminal-
  trapezoidal regression is diagnostic/clip clean, recovers an injected
  23-sample delay exactly, and retains raw, latency-only, and opt-in gain-aligned
  residuals separately.
- Added exact trapezoidal terminal correction. Ten corrected Q4.44 capacitor
  current histories commit on the existing final chord edge, remain full-state
  bit-exact across 384,000 overload updates, and retain the 127-clock schedule.
  Generated constant conductances reduce the measured solver from a rejected
  210-DSP first implementation to 174 DSP48E1s.
- Integrated that solver into the complete 48→768→48 kHz stream. All 64 Q8.24
  outputs / 1,024 internal updates are exact with zero diagnostics; structural
  synthesis measures 20,241 logic cells, 222 DSP48E1s, and 8 RAMB18E1 + 1 RAMB36E1. Named-
  part timing remains unproven.
- Added a captured 100 Hz/1/10/20 kHz frequency gate for the complete
  trapezoidal terminal stream. All 19,200 outputs are exact; gain/phase error
  versus floating trapezoidal stays within 0.000134 dB / 0.000444 degree. The
  report preserves startup drift separately from its -74.79 dB worst linear-
  detrended waveform null.
- Added a phase-coherent complete-stream alias-family decomposition covering all
  16 internal frequencies that fold to ±3 kHz. The combined out-of-band
  projection is captured bit-exactly in RTL; the 45 kHz fold is exactly zero in
  the Q8.24 window and the family-removed difference is -176.96 dBc, below fixed
  rounding closure.
- Extended overload capture to the banked terminal RTL and added coherent
  H1--H10, clipping-asymmetry, grid-current, recovery, and direct analytical
  null metrics. The 384,000-update campaign is full-state bit-exact with zero
  diagnostics through 1.5 V peak.
- Integrated the backward-Euler banked terminal solver into the complete mono
  48→768→48 kHz stream. The fixed composition and RTL match all 64 external
  outputs across 1,024 nonlinear updates at the measured 127-clock solver
  latency, with zero diagnostics.
- Added a dedicated complete-stream wrapper, reproducible vectors/metadata,
  regression and synthesis targets. Out-of-context XC7 synthesis measures
  18,466 logic cells, 168 DSP48E1s, and 8 RAMB18E1 + 1 RAMB36E1 with zero structural
  problems; timing remains unclaimed without named-part place-and-route.
- Added an optional backward-Euler terminal-correction contract that reuses the
  final diagnostic residual for one Q40 chord update. Fixed Python and RTL keep
  the preterminal residual semantics explicit, commit four-pass-exact persistent
  state, and preserve a distinct integration-mode selection.
- Added exact sequential and 1.0/1.5 V overload RTL regressions for the terminal
  path, plus a dedicated synthesis wrapper and reproducible Make targets.
- Added a full 100 ms banked correction-count study for both integrators at
  1.0/1.5 V, including unaligned burst/recovery metrics, diagnostics, bank use,
  and explicit measured-versus-projected latency labeling.
- Established the physical-reference → SPICE → Python float → Python fixed → RTL verification hierarchy.
- Selected and versioned the Kennedy 1998 single-12AX7 passive-RIAA phono stage as the V1 circuit artifact.
- Added reproducible project structure, engineering instructions, task ledger, and local-tool bootstrap path.
- Added the AT-VM95E R/L/load model, canonical RIAA reference, Koren 12AX7 plate/grid-current equations, checked GE curve points, and deterministic mathematical regressions.
- Added an automated ngspice golden reference with DC, 10 Hz–100 kHz AC, transient, and H1–H10 level-sweep extraction.
- Added a nine-node 768 kHz backward-Euler nonlinear nodal model of the complete V1 signal circuit and SPICE/null comparison tooling.
- Added reproducible 12AX7 LUT generation, resolution/error study, bit-accurate fixed interpolation, and a synthesizable serialized SystemVerilog tube primitive.
- Added an integer-only complete V1 chord candidate with per-node Q formats,
  Q0.47 conductances, Q4.44 diagnostic KCL residuals, explicit rounding/
  saturation, fixed capacitor state, and diagnostics.
- Added four-stage 16× half-band interpolation/decimation design, reproducible
  float/Q1.23 coefficients, response/latency extraction, and a nonlinear alias
  regression.
- Added bit-accurate Q8.24 half-band sample paths with Q1.23 coefficients,
  signed MAC rounding, per-stage saturation, and fixed-chain alias verification.
- Added GitHub Actions model/RTL/generated-asset and ngspice cross-model jobs.
- Added a synthesizable nine-row V1 chord corrector, reproducible coefficient/
  vector generation, exact boundary testbench, and generic XC7 synthesis flow.
- Added bit-exact capacitor-history RHS and heterogeneous-format KCL engines,
  each verified against 1,024 generated vectors with explicit saturation counts.
- Added the complete mono V1 solver scheduler: both serialized 12AX7 evaluations,
  three chord corrections, final residual, ten capacitor-state commits, and
  request/deadline/saturation/LUT/convergence diagnostics.
- Added a 512-sample persistent-state integration regression covering silence,
  tones, multitone, noise, and ±100 mV clicks.
- Added serial-MAC Q8.24/Q1.23 half-band interpolation and decimation primitives,
  four-stage 48↔768 kHz chains, coefficient ROM generation, and exact unit/stream
  regressions with phase, overrun, and saturation diagnostics.
- Added the complete mono 48 kHz reference stream, including 16× rate conversion,
  all circuit state, saturating line-output format conversion, and aggregated
  runtime diagnostics.
- Added a settled analytical/fixed 1 kHz sweep from 0.5 mV to 5 V and a targeted
  low-level LUT-resolution study with explicit raw memory tradeoffs.
- Added floating and bit-accurate factorized Koren models using reciprocal-root,
  softplus, and power value/slope 1-D tables with cubic Hermite interpolation,
  plus a reproducible 100,000-point and five-level circuit study.
- Added a synthesizable eight-clock factorized 12AX7 primitive, reproducible
  packed ROM generation, and an exact 4,110-vector RTL regression with directed
  endpoint and out-of-range cases.
- Added an explicit factorized-tube solver mode with independent initialization,
  persistent-state vectors, metadata, regression entry point, and synthesis path.
- Added factorized mode to the complete interpolator/circuit/decimator stream,
  including independent exact output vectors, metadata, and structural synthesis.
- Added a reproducible six-frequency, cycle-counted factorized fixed-versus-
  analytical circuit sweep with gain, phase, THD, raw/mean-removed residual,
  DC difference, range, saturation, and convergence reporting.
- Added controlled overload-burst and recovery analysis against an undisturbed
  nominal trajectory, including per-triode grid-current peaks, output clipping
  asymmetry, three recovery thresholds, and solver/range diagnostics.
- Added a three-through-six-correction overload solver study with analytical
  waveform error and explicit serialized latency projections.
- Added a one-second, 768,000-sample fixed/analytical state audit with bipolar
  synthetic clicks and complete node/capacitor checkpoints.
- Added a 40-bit heterogeneous-node/Q30-history Python candidate with direct
  capacitor branch-current stamping, staged Q30/Q34/Q40 correction residuals,
  a matched one-second audit, and nominal-level legacy A/B report.
- Added bounded adaptive correction-residual scaling and a wide-state overload
  comparison with fallback, range, recovery, and convergence counters.
- Added a synthesizable 40-bit Q28/Q32 chord corrector with explicit
  Q30/Q34/Q40 residual scaling, exact randomized/boundary vectors, and a generic
  XC7 structural synthesis path.
- Added independent wide-state RHS and KCL blocks with direct Q30 capacitor
  branch stamping, bounded correction-format selection, delayed-current
  handshaking, exact vectors, and structural synthesis targets.
- Added the complete persistent wide factorized solver, exact 512-sample
  integration vectors, fallback/minimum-format diagnostics, and hierarchical
  synthesis support.
- Added a complete wide 48 kHz reference stream with explicit Q8.32-to-Q8.24
  conversion, exact end-to-end vectors, diagnostics, and synthesis target.
- Added arbitrary-vector/capture support to the wide solver regression and an
  automated 23,040-sample RTL-versus-analytical nominal audio measurement.
- Added a captured wide-solver RTL frequency regression at 100 Hz, 1 kHz,
  10 kHz, and 20 kHz with fixed equivalence, analytical gain/phase bounds, and
  zero-diagnostic acceptance checks.
- Added shared arbitrary-trajectory wide-solver vector/capture infrastructure
  and a 100 ms captured overload/recovery regression through 1.5 V peak.
- Extended the wide complete-stream testbench and runner with bounded dynamic
  vector counts, alternate vector files, and direct 48 kHz output capture.
- Extended the complete decimator bench to 131,072 custom inputs / 8,192
  captured outputs and added a captured cubic nonlinear-alias regression.
- Added a model-change guard and complete guarded wide-stream top with muted
  startup, ramp-down, frame-aligned reset, muted warmup, acknowledgment, and
  ramp-up sequencing.
- Added a four-frequency ngspice/Python transient sweep, a two-rate refinement
  study, and an explicit floating trapezoidal capacitor-companion candidate.
- Added a 100 ms floating backward-Euler/trapezoidal overload stability study
  spanning 20 mV through 1.5 V peak.
- Added an explicit bit-accurate trapezoidal circuit candidate with Q30 previous
  capacitor voltage, signed Q4.44 previous current, identical rounded KCL/state
  branch arithmetic, nominal-range instrumentation, and a gated six-frequency
  comparison against floating trapezoidal.
- Extended the controlled overload harness to select fixed trapezoidal state,
  report all capacitor-current maxima, and enforce a diagnostic-clean <=0.5 V
  acceptance region while retaining severe overload as characterization.
- Added a parameterized 48-bit-capacitor KCL mode with Q4.44 previous/next
  current ports, exact trapezoidal branch stamping, state saturation reporting,
  and an independent 1,024-vector warning-free RTL regression.
- Added a selectable persistent trapezoidal solver with a separate generated
  chord-inverse ROM, ten Q4.44 current-state registers, exact 512-sample
  integration regression, and an explicit synthesis wrapper/target.
- Added selectable trapezoidal state to the complete 48 kHz stream, an exact
  64-output/1,024-update integration regression, and an explicit full-stream
  synthesis wrapper/target.
- Extended arbitrary-length solver capture and the four-point frequency sweep
  to trapezoidal state, including all current-history words, separate artifacts,
  gated gain/phase/diagnostics, and a non-combined link to ngspice evidence.
- Added reusable composed fixed/floating complete-stream references and a
  captured four-point 48 kHz trapezoidal sweep. The regression proves 19,200
  outputs exactly, gates float error and diagnostics, and reports the measured
  51-sample converter delay separately from circuit-attributed phase.
- Added a gated 250 ms floating trapezoidal overload study with direct sustained
  recovery timing, exponential-envelope fit quality, projected-versus-measured
  labels, and complete node/capacitor difference checkpoints.
- Added parallel 850 ms floating severe-overload trajectories and a regression
  that preserves their non-monotonic cancellation/rebound. This falsifies the
  earlier one-exponential projection instead of converting it into a claim.
- Added a 384,000-update selectable-trapezoidal RTL recovery capture at the
  accepted 0.5 V boundary, with full-state exactness, zero-diagnostic gates,
  and an explicitly non-sample-identical floating recovery comparison.
- Added a dependency-free continuous-time nodal pole extractor with tube
  small-signal linearization, mode shapes, capacitor-energy participation,
  stability gates, and measured-overload interpretation.
- Added parallel seven-second severe-recovery trajectories with a bounded
  Newton-to-chord handoff, overlap/final-probe error gates, and direct sustained
  timing for every 10%, 1%, and 1 mV threshold.
- Added a standalone downstream output mute/ramp with reset-muted startup,
  sample-qualified linear transitions, symmetric signed rounding, exact-unity
  bypass, synchronous fault clamp, and a self-checking RTL regression.
- Added warning-free Verilator lint and a 4,096-vector bit-exact testbench with checked eight-clock latency.
- Added non-root ngspice/Yosys bootstrap and a generic XC7 out-of-context synthesis report.
- Added quantitative cartridge/front-end noise, ADC headroom, and analog-versus-digital RIAA partition analysis.
- Added a reproducible fixed cutoff-Jacobian bank study using integration-mode-
  specific matrices derived from the analytical second-stage trajectory and a
  previous-sample Vgk selector held across the fixed three-correction schedule.
- Added generated four-bank backward-Euler and five-bank trapezoidal chord
  assets, a sample-held selector in the wide solver, explicit synthesis
  wrappers, and a 9,216-sample-per-mode full-state RTL overload regression.
- Added a parallel 100 ms banked/DC-chord/full-Newton waveform audit at 20 mV,
  0.5 V, and 1.0 V with Q8.24 stimulus, unaligned windowed residuals, and a
  -70 dB raw burst-error gate.
- Added a bank-prefix minimization study across 0.5/1.0 V and both integration
  modes; it preserves the negative result that every current cutoff matrix is
  required for the 1.0 V residual gate.
- Added a trapezoidal shallow-bank threshold sweep from -2.50 to -2.90 V and
  selected the most-negative diagnostic-clean threshold that excludes the
  accepted 0.5 V trajectory.
- Added a 100 ms previous-Vgk-slew selector study, a reproducible
  backward-Euler shallow Jacobian, matched fixed/RTL selector history, and
  1.0/1.5 V full-state overload gates for both integration modes.
- Added a converged four-layer banked error decomposition and a 128/256/512/
  1,024-entry grid-current resolution study with direct-current, burst,
  recovery, storage, and fixed-diagnostic measurements.
- Added architecture, model, phono, fixed-point, gain, noise, analog front-end, converter/clock, hardware, controls, safety, verification, and annotated-reference documentation.

### Fixed

- Refreshed seven tracked fixed-model metadata assets that had lagged their
  deterministic generators. The files now record the exact
  `factorized_hermite` implementation, explicit 384/768 kHz rate fields, chord
  coefficient widths, per-bank vector counts, and full vector provenance.
  Re-running each owning generator produces byte-identical metadata, restoring
  the CI `git diff --exit-code -- model/generated` contract after `make test`.
- Corrected the clock-only Nexys Video harness reset polarity. Physical G4 is
  active-low `CPU_RESETN`; the prior harness passed it directly to active-high
  MMCM and counter resets, so its generated `941a8c07...e0ff656` bitstream
  would remain reset while the button was released. The renamed port is now
  inverted explicitly, the clock-plan regression checks both RTL polarity and
  the G4 XDC binding, and a new three-iteration legal route plus CRC-readable
  bitstream supersedes that artifact at SHA-256 `1d7d934f...234b248`. No board
  was programmed with either image.

- Corrected the pin-level integration bench's absolute clocks. Its former
  5 ns/160 ns half-periods exercised the correct 32:1 ratio but were actually
  100/3.125 MHz, not the documented 98.304/3.072 MHz. Femtosecond-resolution
  periods now exercise the stated rates without changing exact frame/model
  results. Timestamped handshake and serial markers are regression-gated and
  record 192 BCLKs / 62.500 µs / 3.000 samples from first complete ADC frame to
  first complete valid model-output DAC frame; this is transport latency, not
  signal group delay.
- Corrected synthesis resource reporting to count mapped RAMB36E1 primitives
  and publish RAMB18-equivalent totals. Every factorized-tube hierarchy maps
  eight RAMB18E1s plus one RAMB36E1 (10 RAMB18-equivalents); earlier eight-only
  summaries omitted the 36-Kib primitive. The same audit retains flattened
  primitive flip-flop totals and distinguishes local-array expansion warnings
  from asynchronous-FIFO memory inference. RTL numerical behavior is unchanged.
- Corrected the synthesis driver's `_factorized` alias detection so the real
  `triode_12ax7_factorized` top is synthesized directly while the legacy solver
  and stream wrapper aliases still receive their parameter override.
- Widened the wide-network capacitor difference from signed 43 to 44 bits and
  its full product from 91 to 92 bits. Capacitor 6 can legally join opposite
  signed-40 Q28 node extremes and subtract a full-range Q30 history; directed
  backward-Euler and trapezoidal vectors now prevent this silent-wrap defect
  from recurring.
- Widened signed Q31 tube currents before cathode-stamp negation so the legal
  `INT32_MIN` pair produces positive `2^32` instead of wrapping in a 33-bit
  expression; both triodes now have directed boundary vectors.
- Replaced 32-bit tube-pin subtraction in the wide solver with 40-bit node
  conversion, 41-bit subtraction, and explicit signed-32 saturation. Fixed
  Python now defines the same boundary behavior, and a regression forces both
  polarities instead of permitting extreme Vgk/Vpk values to wrap.

### Reference decisions

- V1 is one mono channel using both halves of one 12AX7, 300 V B+, unbypassed 1.21 kΩ cathode resistors, and the original two-pole passive equalizer values.
- High-resolution inspection corrected the equalizer capacitor transcription to 3300 pF shunt (the source scan's decimal text is easy to misread at page scale). The failed 300 pF/series interpretations were rejected by topology inspection and RIAA regression.
- The nominal external cartridge is the Audio-Technica AT-VM95E equivalent: 485 Ω, 550 mH, 47 kΩ load, and configurable total shunt capacitance (150 pF nominal).
- The Koren 12AX7 parameter set is the first analytical and SPICE tube model. Model error against manufacturer curves is tracked separately from numerical implementation error.
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

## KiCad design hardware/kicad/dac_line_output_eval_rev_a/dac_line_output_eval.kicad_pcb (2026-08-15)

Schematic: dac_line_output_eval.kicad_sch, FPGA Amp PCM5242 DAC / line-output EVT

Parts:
C1: 10nF_X7R; C_0603_1608Metric
C2: 100nF_X7R_LDOO; C_0402_1005Metric
C3: 2.2uF_X7R_FLY; C_0603_1608Metric
C4: 2.2uF_X7R_VNEG; C_0603_1608Metric
C5: 100nF_X7R_AVDD; C_0402_1005Metric
C6: 10uF_X5R_AVDD; C_0805_2012Metric
C7: 100nF_X7R_CPVDD; C_0402_1005Metric
C8: 2.2uF_X7R_CPVDD; C_0603_1608Metric
C9: 100nF_X7R_DVDD; C_0402_1005Metric
C10: 10uF_X5R_DVDD; C_0805_2012Metric
C11, C12: 100nF_X7R; C_0402_1005Metric
C20, C21: 1nF_C0G_DIFF; C_0603_1608Metric
C22, C23: 2.2nF_C0G_SE; C_0603_1608Metric
C30, C33: 1uF_X7R_LDO_IN; C_0805_2012Metric
C31, C34: 2.2uF_X7R_LDO_OUT; C_0805_2012Metric
C32: 10uF_X5R_ANALOG_BULK; C_0805_2012Metric
C35: 10uF_X5R_DIGITAL_BULK; C_0805_2012Metric
C36: 10uF_X5R_RELAY_BULK; C_0805_2012Metric
C50: DNP_4.7nF_CHASSIS; C_1206_3216Metric
D1, D2, D3: 1N4148W_FLYBACK; D_SOD-123
D4, D5, D6, D7, D8, D9: PESD5V0X1BCL_EVT; D_SOD-882
J1: DAC_AUDIO; PinHeader_2x05_P2.54mm_Vertical
J2: DAC_CONTROL; PinHeader_2x05_P2.54mm_Vertical
J3: POWER_INPUT; PinHeader_2x04_P2.54mm_Vertical
J4: BALANCED_PANEL_HARNESS_EVT; JST_XH_B8B-XH-A_1x08_P2.50mm_Vertical
J5: RCA_PANEL_HARNESS_EVT; JST_XH_B3B-XH-A_1x03_P2.50mm_Vertical
K1: G6K-2F-Y-5V_FAIL_OPEN_1; Relay_DPDT_Omron_G6K-2F-Y
K2: G6K-2F-Y-5V_FAIL_OPEN_2; Relay_DPDT_Omron_G6K-2F-Y
K3: G6K-2F-Y-5V_FAIL_OPEN_3; Relay_DPDT_Omron_G6K-2F-Y
Q1, Q2, Q3: MMBT3904; SOT-23
R1, R2, R3, R4: 0R_LINK; R_0402_1005Metric
R5: 1k; R_0603_1608Metric
R6, R12, R13, R14: 100k_FAIL_MUTE; R_0603_1608Metric
R7, R8: 4.7k; R_0603_1608Metric
R9, R10: 0R_LINK; R_0603_1608Metric
R11: 10k; R_0603_1608Metric
R20, R21, R22, R23, R24, R25: 499R_0.1%; R_0805_2012Metric
R31, R32, R33: 2.2k; R_0603_1608Metric
R34, R35, R36: 100k; R_0603_1608Metric
R40: 1R_ANALOG_ISOLATION; R_0805_2012Metric
R50: DNP_0R_CHASSIS_BOND; R_1206_3216Metric
TP1: +3V3A; TestPoint_Pad_D1.0mm
TP2: +3V3D; TestPoint_Pad_D1.0mm
TP3: DAC_XSMT_PIN; TestPoint_Pad_D1.0mm
TP4: LINE_RELAY_EN_SAFE; TestPoint_Pad_D1.0mm
TP5: L_RCA_OUT; TestPoint_Pad_D1.0mm
TP6: R_RCA_OUT; TestPoint_Pad_D1.0mm
TP7: CHASSIS; TestPoint_Pad_D1.0mm
TP8: GND; TestPoint_Pad_D1.0mm
U1: PCM5242RHBR; Texas_RHB0032E_VQFN-32-1EP_5x5mm_P0.5mm_EP3.45x3.45mm_Therm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
U2: TPS7A2033PDBVR_ANALOG; SOT-23-5
U3: TPS7A2033PDBVR_DIGITAL; SOT-23-5
U4: SN74LVC1G08DBVR_RELAY_INTERLOCK; SOT-23-5
U5: SN74LVC1G08DBVR_XSMT_INTERLOCK; SOT-23-5

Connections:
+3V3A: C5.1 (+3V3A), C6.1 (+3V3A), C7.1 (+3V3A), C8.1 (+3V3A), C32.1 (+3V3A), R40.2 (+3V3A), TP1.1, U1.5 (+3V3A), U1.14 (+3V3A)
+3V3A_RAW: C31.1 (+3V3A_RAW), R40.1 (+3V3A_RAW), U2.5 (+3V3A_RAW)
+3V3D: C9.1 (+3V3D), C10.1 (+3V3D), C11.1 (+3V3D), C12.1 (+3V3D), C34.1 (+3V3D), C35.1 (+3V3D), J1.9 (+3V3D), J2.1 (+3V3D), R7.1 (+3V3D), R8.1 (+3V3D), TP2.1, U1.4 (+3V3D), U1.24 (+3V3D), U3.5 (+3V3D), U4.5 (+3V3D), U5.5 (+3V3D)
+3V7A_IN: C30.1 (+3V7A_IN), J3.1 (+3V7A_IN), U2.1 (+3V7A_IN), U2.3 (+3V7A_IN)
+3V7D_IN: C33.1 (+3V7D_IN), J3.3 (+3V7D_IN), U3.1 (+3V7D_IN), U3.3 (+3V7D_IN)
+5V_RELAY: C36.1 (+5V_RELAY), D1.1 (+5V_RELAY), D2.1 (+5V_RELAY), D3.1 (+5V_RELAY), J3.5 (+5V_RELAY), K1.1 (+5V_RELAY), K2.1 (+5V_RELAY), K3.1 (+5V_RELAY)
CHASSIS: C50.1 (CHASSIS), D4.1 (CHASSIS), D5.1 (CHASSIS), D6.1 (CHASSIS), D7.1 (CHASSIS), D8.1 (CHASSIS), D9.1 (CHASSIS), J3.7 (CHASSIS), J4.3 (CHASSIS), J4.7 (CHASSIS), R50.1 (CHASSIS), TP7.1
CP_FLY_N: C3.2 (CP_FLY_N), U1.8 (CP_FLY_N)
CP_FLY_P: C3.1 (CP_FLY_P), U1.6 (CP_FLY_P)
DAC_BCK: R2.2 (DAC_BCK), U1.27 (DAC_BCK)
DAC_BCK_IN: J1.3 (DAC_BCK_IN), R2.1 (DAC_BCK_IN)
DAC_DIN: R4.2 (DAC_DIN), U1.28 (DAC_DIN)
DAC_DIN_IN: J1.7 (DAC_DIN_IN), R4.1 (DAC_DIN_IN)
DAC_LDOO: C2.1 (DAC_LDOO), U1.2 (DAC_LDOO)
DAC_LN: R21.1 (DAC_LN), U1.11 (DAC_LN)
DAC_LP: R20.1 (DAC_LP), R24.1 (DAC_LP), U1.10 (DAC_LP)
DAC_LRCK: R3.2 (DAC_LRCK), U1.31 (DAC_LRCK)
DAC_LRCK_IN: J1.5 (DAC_LRCK_IN), R3.1 (DAC_LRCK_IN)
DAC_RN: R23.1 (DAC_RN), U1.12 (DAC_RN)
DAC_RP: R22.1 (DAC_RP), R25.1 (DAC_RP), U1.13 (DAC_RP)
DAC_SCK: R1.2 (DAC_SCK), U1.26 (DAC_SCK)
DAC_SCK_IN: J1.1 (DAC_SCK_IN), R1.1 (DAC_SCK_IN)
DAC_SOFT_UNMUTE_CTL: J2.5 (DAC_SOFT_UNMUTE_CTL), R14.1 (DAC_SOFT_UNMUTE_CTL), U5.1 (DAC_SOFT_UNMUTE_CTL)
DAC_VNEG: C4.1 (DAC_VNEG), U1.9 (DAC_VNEG)
DAC_XSMT_PIN: C1.1 (DAC_XSMT_PIN), R5.2 (DAC_XSMT_PIN), R6.1 (DAC_XSMT_PIN), TP3.1, U1.1 (DAC_XSMT_PIN)
DAC_XSMT_SAFE: R5.1 (DAC_XSMT_SAFE), U5.4 (DAC_XSMT_SAFE)
GND: C1.2 (GND), C2.2 (GND), C4.2 (GND), C5.2 (GND), C6.2 (GND), C7.2 (GND), C8.2 (GND), C9.2 (GND), C10.2 (GND), C11.2 (GND), C12.2 (GND), C22.2 (GND), C23.2 (GND), C30.2 (GND), C31.2 (GND), C32.2 (GND), C33.2 (GND), C34.2 (GND), C35.2 (GND), C36.2 (GND), C50.2 (GND), J1.2 (GND), J1.4 (GND), J1.6 (GND), J1.8 (GND), J1.10 (GND), J2.2 (GND), J2.9 (GND), J2.10 (GND), J3.2 (GND), J3.4 (GND), J3.6 (GND), J3.8 (GND), J4.4 (GND), J4.8 (GND), J5.2 (GND), Q1.2 (GND), Q2.2 (GND), Q3.2 (GND), R6.2 (GND), R11.2 (GND), R12.2 (GND), R13.2 (GND), R14.2 (GND), R34.2 (GND), R35.2 (GND), R36.2 (GND), R50.2 (GND), TP8.1, U1.3 (GND), U1.7 (GND), U1.15 (GND), U1.22 (GND), U1.23 (GND), U1.32 (GND), U1.33 (GND), U2.2 (GND), U3.2 (GND), U4.3 (GND), U5.3 (GND)
HARD_MUTE_N: J2.8 (HARD_MUTE_N), R13.1 (HARD_MUTE_N), U4.2 (HARD_MUTE_N), U5.2 (HARD_MUTE_N)
I2C_SCL: R7.2 (I2C_SCL), R9.2 (I2C_SCL), U1.18 (I2C_SCL)
I2C_SCL_IN: J2.3 (I2C_SCL_IN), R9.1 (I2C_SCL_IN)
I2C_SDA: R8.2 (I2C_SDA), R10.2 (I2C_SDA), U1.17 (I2C_SDA)
I2C_SDA_IN: J2.4 (I2C_SDA_IN), R10.1 (I2C_SDA_IN)
K1_BASE: Q1.1 (K1_BASE), R31.2 (K1_BASE), R34.1 (K1_BASE)
K1_COIL_LOW: D1.2 (K1_COIL_LOW), K1.8 (K1_COIL_LOW), Q1.3 (K1_COIL_LOW)
K2_BASE: Q2.1 (K2_BASE), R32.2 (K2_BASE), R35.1 (K2_BASE)
K2_COIL_LOW: D2.2 (K2_COIL_LOW), K2.8 (K2_COIL_LOW), Q2.3 (K2_COIL_LOW)
K3_BASE: Q3.1 (K3_BASE), R33.2 (K3_BASE), R36.1 (K3_BASE)
K3_COIL_LOW: D3.2 (K3_COIL_LOW), K3.8 (K3_COIL_LOW), Q3.3 (K3_COIL_LOW)
LINE_RELAY_EN_CTL: J2.6 (LINE_RELAY_EN_CTL), R12.1 (LINE_RELAY_EN_CTL), U4.1 (LINE_RELAY_EN_CTL)
LINE_RELAY_EN_SAFE: R31.1 (LINE_RELAY_EN_SAFE), R32.1 (LINE_RELAY_EN_SAFE), R33.1 (LINE_RELAY_EN_SAFE), TP4.1, U4.4 (LINE_RELAY_EN_SAFE)
L_BAL_N_FILT: C20.2 (L_BAL_N_FILT), K1.6 (L_BAL_N_FILT), R21.2 (L_BAL_N_FILT)
L_BAL_N_OUT: D5.2 (L_BAL_N_OUT), J4.2 (L_BAL_N_OUT), K1.5 (L_BAL_N_OUT)
L_BAL_P_FILT: C20.1 (L_BAL_P_FILT), K1.3 (L_BAL_P_FILT), R20.2 (L_BAL_P_FILT)
L_BAL_P_OUT: D4.2 (L_BAL_P_OUT), J4.1 (L_BAL_P_OUT), K1.4 (L_BAL_P_OUT)
L_RCA_FILT: C22.1 (L_RCA_FILT), K3.3 (L_RCA_FILT), R24.2 (L_RCA_FILT)
L_RCA_OUT: D8.2 (L_RCA_OUT), J5.1 (L_RCA_OUT), K3.4 (L_RCA_OUT), TP5.1
OB_PRESENT_N: J2.7 (OB_PRESENT_N), R11.1 (OB_PRESENT_N)
R_BAL_N_FILT: C21.2 (R_BAL_N_FILT), K2.6 (R_BAL_N_FILT), R23.2 (R_BAL_N_FILT)
R_BAL_N_OUT: D7.2 (R_BAL_N_OUT), J4.6 (R_BAL_N_OUT), K2.5 (R_BAL_N_OUT)
R_BAL_P_FILT: C21.1 (R_BAL_P_FILT), K2.3 (R_BAL_P_FILT), R22.2 (R_BAL_P_FILT)
R_BAL_P_OUT: D6.2 (R_BAL_P_OUT), J4.5 (R_BAL_P_OUT), K2.4 (R_BAL_P_OUT)
R_RCA_FILT: C23.1 (R_RCA_FILT), K3.6 (R_RCA_FILT), R25.2 (R_RCA_FILT)
R_RCA_OUT: D9.2 (R_RCA_OUT), J5.3 (R_RCA_OUT), K3.5 (R_RCA_OUT), TP6.1

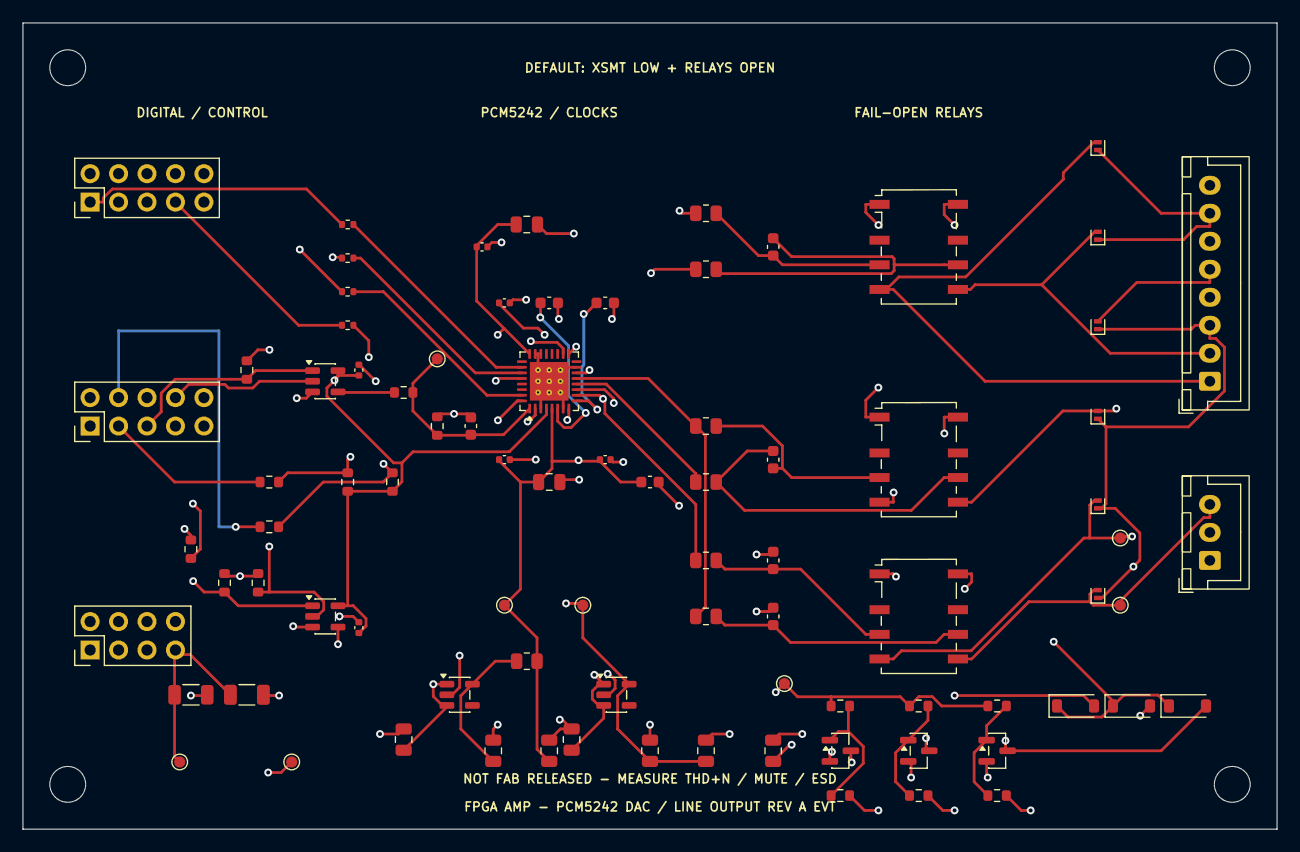
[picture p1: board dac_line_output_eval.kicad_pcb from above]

Board: 4 copper layers, 112.0 x 72.0 mm, 89 parts (0 on the bottom side), 53 nets.

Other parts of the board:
H1, H2, H3, H4: M3_CHASSIS_STANDOFF; MountingHole_3.2mm_M3

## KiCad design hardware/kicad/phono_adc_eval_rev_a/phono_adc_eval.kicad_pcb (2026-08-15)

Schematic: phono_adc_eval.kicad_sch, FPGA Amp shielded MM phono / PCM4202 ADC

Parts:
C1, C2: 47pF_C0G_1%; C_0603_1608Metric
C3, C4: 100pF_C0G_1%; C_0603_1608Metric
C5, C6: DNP_22pF_C0G_RF; C_0603_1608Metric
C20, C21, C30, C31: 1nF_C0G; C_0603_1608Metric
C22, C32: 2.7nF_C0G; C_0603_1608Metric
C23, C24, C33, C34: 100pF_C0G; C_0603_1608Metric
C40, C42, C46, C48: 33uF_LOW_ESR; C_Elec_4x5.8
C41, C43, C44, C45, C47, C49, C71, C72, C77, C78: 100nF_X7R; C_0603_1608Metric
C60, C61, C62: 10nF_X7R; C_0603_1608Metric
C63, C64, C65, C66, C79, C80: 10uF_25V_X7R; C_1206_3216Metric
C67, C68, C69, C70: 1uF_X7R; C_0603_1608Metric
C73, C74, C75, C76: 100nF_X7R; C_0402_1005Metric
C81: DNP_100nF_CHASSIS; C_1206_3216Metric
D1, D2: PESD5V0X1BCL_EVT; D_SOD-882
D3, D4, D5, D6: 1N4148W; D_SOD-123
J1: ISOLATED_PANEL_RCA_HARNESS; JST_XH_B3B-XH-A_1x03_P2.50mm_Vertical
J2: TURNTABLE_GROUND_POST; TerminalBlock_MetzConnect_360425_1x01_Horizontal_ScrewM4.0_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
J3: ADC_AUDIO; PinHeader_2x05_P2.54mm_Vertical
J4: POWER_INPUT; PinHeader_2x06_P2.54mm_Vertical
J5: ADC_CONTROL; PinHeader_2x05_P2.54mm_Vertical
K1: G6K-2F-Y-5V_GAIN_BANK; Relay_DPDT_Omron_G6K-2F-Y
K2: G6K-2F-Y-5V_GAIN_RANGE; Relay_DPDT_Omron_G6K-2F-Y
K3: G6K-2F-Y-5V_CAP47; Relay_DPDT_Omron_G6K-2F-Y
K4: G6K-2F-Y-5V_CAP100; Relay_DPDT_Omron_G6K-2F-Y
Q1, Q2, Q3, Q4: MMBT3904; SOT-23
R1, R2: 100R_0.1%; R_0805_2012Metric
R3, R4: 47.5k_0.1%_25ppm; R_0805_2012Metric
R5, R6: 19.1k_0.1%; R_0805_2012Metric
R7, R8: 1.00k_0.1%; R_0805_2012Metric
R9, R10: 2.12k_0.1%; R_0805_2012Metric
R11, R12: 492R_0.1%; R_0805_2012Metric
R20, R21, R22, R23, R30, R31, R32, R33: 316R_0.1%; R_0603_1608Metric
R24, R25, R34, R35: 40.2R_0.1%; R_0603_1608Metric
R40: 22R; R_0402_1005Metric
R41, R42, R43: 33R; R_0402_1005Metric
R44, R55, R56, R57, R58: 100k; R_0603_1608Metric
R45: 10k; R_0603_1608Metric
R51, R52, R53, R54: 2.2k; R_0603_1608Metric
R60: 90.9k_0.1%; R_0603_1608Metric
R61, R63: 10.0k_0.1%; R_0603_1608Metric
R62: 100k_0.1%; R_0603_1608Metric
R70: 0R_CHASSIS_BOND; R_1206_3216Metric
R71: DNP_10R_CHASSIS; R_1206_3216Metric
TP1: L_INPUT; TestPoint_Pad_D1.0mm
TP2: R_INPUT; TestPoint_Pad_D1.0mm
TP3: L_GAIN_OUT; TestPoint_Pad_D1.0mm
TP4: R_GAIN_OUT; TestPoint_Pad_D1.0mm
TP5: ADC_L_IN_P; TestPoint_Pad_D1.0mm
TP6: ADC_L_IN_N; TestPoint_Pad_D1.0mm
TP7: ADC_R_IN_P; TestPoint_Pad_D1.0mm
TP8: ADC_R_IN_N; TestPoint_Pad_D1.0mm
TP9: +12VA; TestPoint_Pad_D1.0mm
TP10: -12VA; TestPoint_Pad_D1.0mm
TP11: +5VA; TestPoint_Pad_D1.0mm
TP12: +3V3D; TestPoint_Pad_D1.0mm
TP13: SCKI_24M576; TestPoint_Pad_D1.0mm
TP14: ADC_BCK_OUT; TestPoint_Pad_D1.0mm
TP15: ADC_LRCK_OUT; TestPoint_Pad_D1.0mm
TP16: GND; TestPoint_Pad_D1.0mm
U1: TPS7A39DSCR; Texas_DSC0010J_ThermalVias
U2: TPS7A2050PDBVR; SOT-23-5
U3: TPS7A2033PDBVR; SOT-23-5
U4, U8: OPA1656IDR; SOIC-8_3.9x4.9mm_P1.27mm
U5, U6: OPA1632DR; SOIC-8_3.9x4.9mm_P1.27mm
U7: PCM4202DBR; SSOP-28_5.3x10.2mm_P0.65mm

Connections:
+3V3D: C48.1 (+3V3D), C49.1 (+3V3D), C70.1 (+3V3D), J5.1 (+3V3D), TP12.1, U3.5 (+3V3D), U7.6 (+3V3D), U7.9 (+3V3D), U7.12 (+3V3D), U7.14 (+3V3D)
+3V7_IN: C69.1 (+3V7_IN), J4.7 (+3V7_IN), U3.1 (+3V7_IN), U3.3 (+3V7_IN)
+5V7_IN: C67.1 (+5V7_IN), J4.5 (+5V7_IN), U2.1 (+5V7_IN), U2.3 (+5V7_IN)
+5VA: C46.1 (+5VA), C47.1 (+5VA), C68.1 (+5VA), TP11.1, U2.5 (+5VA), U7.22 (+5VA)
+5V_RELAY: D3.1 (+5V_RELAY), D4.1 (+5V_RELAY), D5.1 (+5V_RELAY), D6.1 (+5V_RELAY), J4.9 (+5V_RELAY), K1.1 (+5V_RELAY), K2.1 (+5V_RELAY), K3.1 (+5V_RELAY), K4.1 (+5V_RELAY)
+12VA: C61.1 (+12VA), C65.1 (+12VA), C71.1 (+12VA), C73.1 (+12VA), C75.1 (+12VA), C77.1 (+12VA), C79.1 (+12VA), R60.1 (+12VA), TP9.1, U1.10 (+12VA), U4.8 (+12VA), U5.3 (+12VA), U6.3 (+12VA), U8.8 (+12VA)
+15V5_IN: C63.1 (+15V5_IN), J4.1 (+15V5_IN), U1.1 (+15V5_IN), U1.2 (+15V5_IN)
-12VA: C62.1 (-12VA), C66.1 (-12VA), C72.1 (-12VA), C74.1 (-12VA), C76.1 (-12VA), C78.1 (-12VA), C80.1 (-12VA), R62.1 (-12VA), TP10.1, U1.6 (-12VA), U4.4 (-12VA), U5.6 (-12VA), U6.6 (-12VA), U8.4 (-12VA)
-15V5_IN: C64.1 (-15V5_IN), J4.3 (-15V5_IN), U1.5 (-15V5_IN)
AB_PRESENT_N: J5.8 (AB_PRESENT_N), R45.1 (AB_PRESENT_N)
ADC_BCK_OUT: J3.3 (ADC_BCK_OUT), R41.2 (ADC_BCK_OUT), TP14.1
ADC_BCK_SRC: R41.1 (ADC_BCK_SRC), U7.16 (ADC_BCK_SRC)
ADC_CLIP_L: J3.9 (ADC_CLIP_L), U7.21 (ADC_CLIP_L)
ADC_CLIP_R: J3.10 (ADC_CLIP_R), U7.20 (ADC_CLIP_R)
ADC_DATA_OUT: J3.7 (ADC_DATA_OUT), R43.2 (ADC_DATA_OUT)
ADC_DATA_SRC: R43.1 (ADC_DATA_SRC), U7.15 (ADC_DATA_SRC)
ADC_LRCK_OUT: J3.5 (ADC_LRCK_OUT), R42.2 (ADC_LRCK_OUT), TP15.1
ADC_LRCK_SRC: R42.1 (ADC_LRCK_SRC), U7.17 (ADC_LRCK_SRC)
ADC_L_IN_N: C22.2 (ADC_L_IN_N), C24.1 (ADC_L_IN_N), R25.2 (ADC_L_IN_N), TP6.1, U7.5 (ADC_L_IN_N)
ADC_L_IN_P: C22.1 (ADC_L_IN_P), C23.1 (ADC_L_IN_P), R24.2 (ADC_L_IN_P), TP5.1, U7.4 (ADC_L_IN_P)
ADC_RESET_N: J5.3 (ADC_RESET_N), R44.1 (ADC_RESET_N), U7.19 (ADC_RESET_N)
ADC_R_IN_N: C32.2 (ADC_R_IN_N), C34.1 (ADC_R_IN_N), R35.2 (ADC_R_IN_N), TP8.1, U7.24 (ADC_R_IN_N)
ADC_R_IN_P: C32.1 (ADC_R_IN_P), C33.1 (ADC_R_IN_P), R34.2 (ADC_R_IN_P), TP7.1, U7.25 (ADC_R_IN_P)
CAP_47PF_CTL: J5.6 (CAP_47PF_CTL), R53.1 (CAP_47PF_CTL)
CAP_100PF_CTL: J5.7 (CAP_100PF_CTL), R54.1 (CAP_100PF_CTL)
CHASSIS: C81.1 (CHASSIS), J2.1, R70.1 (CHASSIS), R71.1 (CHASSIS)
GAIN_BANK_CTL: J5.4 (GAIN_BANK_CTL), R51.1 (GAIN_BANK_CTL)
GAIN_RANGE_CTL: J5.5 (GAIN_RANGE_CTL), R52.1 (GAIN_RANGE_CTL)
GND: C1.2 (GND), C2.2 (GND), C3.2 (GND), C4.2 (GND), C5.2 (GND), C6.2 (GND), C23.2 (GND), C24.2 (GND), C33.2 (GND), C34.2 (GND), C40.2 (GND), C41.2 (GND), C42.2 (GND), C43.2 (GND), C44.2 (GND), C45.2 (GND), C46.2 (GND), C47.2 (GND), C48.2 (GND), C49.2 (GND), C60.2 (GND), C63.2 (GND), C64.2 (GND), C65.2 (GND), C66.2 (GND), C67.2 (GND), C68.2 (GND), C69.2 (GND), C70.2 (GND), C71.2 (GND), C72.2 (GND), C73.2 (GND), C74.2 (GND), C75.2 (GND), C76.2 (GND), C77.2 (GND), C78.2 (GND), C79.2 (GND), C80.2 (GND), C81.2 (GND), D1.1 (GND), D2.1 (GND), J1.2 (GND), J3.2 (GND), J3.4 (GND), J3.6 (GND), J3.8 (GND), J4.2 (GND), J4.4 (GND), J4.6 (GND), J4.8 (GND), J4.10 (GND), J4.12 (GND), J5.2 (GND), J5.9 (GND), J5.10 (GND), Q1.2 (GND), Q2.2 (GND), Q3.2 (GND), Q4.2 (GND), R3.2 (GND), R4.2 (GND), R7.2 (GND), R8.2 (GND), R9.2 (GND), R10.2 (GND), R11.2 (GND), R12.2 (GND), R21.1 (GND), R31.1 (GND), R44.2 (GND), R45.2 (GND), R55.2 (GND), R56.2 (GND), R57.2 (GND), R58.2 (GND), R61.2 (GND), R70.2 (GND), R71.2 (GND), TP16.1, U1.4 (GND), U1.11 (GND), U2.2 (GND), U3.2 (GND), U5.7 (GND), U6.7 (GND), U7.2 (GND), U7.7 (GND), U7.8 (GND), U7.10 (GND), U7.11 (GND), U7.13 (GND), U7.23 (GND), U7.27 (GND)
K1_BASE: Q1.1 (K1_BASE), R51.2 (K1_BASE), R55.1 (K1_BASE)
K1_COIL_LOW: D3.2 (K1_COIL_LOW), K1.8 (K1_COIL_LOW), Q1.3 (K1_COIL_LOW)
K2_BASE: Q2.1 (K2_BASE), R52.2 (K2_BASE), R56.1 (K2_BASE)
K2_COIL_LOW: D4.2 (K2_COIL_LOW), K2.8 (K2_COIL_LOW), Q2.3 (K2_COIL_LOW)
K3_BASE: Q3.1 (K3_BASE), R53.2 (K3_BASE), R57.1 (K3_BASE)
K3_COIL_LOW: D5.2 (K3_COIL_LOW), K3.8 (K3_COIL_LOW), Q3.3 (K3_COIL_LOW)
K4_BASE: Q4.1 (K4_BASE), R54.2 (K4_BASE), R58.1 (K4_BASE)
K4_COIL_LOW: D6.2 (K4_COIL_LOW), K4.8 (K4_COIL_LOW), Q4.3 (K4_COIL_LOW)
LDO_BUF: R63.2 (LDO_BUF), U1.8 (LDO_BUF)
LDO_FBN: C62.2 (LDO_FBN), R62.2 (LDO_FBN), R63.1 (LDO_FBN), U1.7 (LDO_FBN)
LDO_FBP: C61.2 (LDO_FBP), R60.2 (LDO_FBP), R61.1 (LDO_FBP), U1.9 (LDO_FBP)
LDO_NR: C60.1 (LDO_NR), U1.3 (LDO_NR)
L_CAP47: C1.1 (L_CAP47), K3.4 (L_CAP47)
L_CAP100: C3.1 (L_CAP100), K4.4 (L_CAP100)
L_DRV_IN_N: C21.2 (L_DRV_IN_N), R21.2 (L_DRV_IN_N), R23.2 (L_DRV_IN_N), U5.1 (L_DRV_IN_N)
L_DRV_IN_P: C20.2 (L_DRV_IN_P), R20.2 (L_DRV_IN_P), R22.2 (L_DRV_IN_P), U5.8 (L_DRV_IN_P)
L_DRV_OUT_N: C20.1 (L_DRV_OUT_N), R22.1 (L_DRV_OUT_N), R25.1 (L_DRV_OUT_N), U5.5 (L_DRV_OUT_N)
L_DRV_OUT_P: C21.1 (L_DRV_OUT_P), R23.1 (L_DRV_OUT_P), R24.1 (L_DRV_OUT_P), U5.4 (L_DRV_OUT_P)
L_GAIN20: K2.2 (L_GAIN20), R9.1 (L_GAIN20)
L_GAIN26: K1.2 (L_GAIN26), R7.1 (L_GAIN26)
L_GAIN32: K2.4 (L_GAIN32), R11.1 (L_GAIN32)
L_GAIN_ALT: K1.4 (L_GAIN_ALT), K2.3 (L_GAIN_ALT)
L_GAIN_N: K1.3 (L_GAIN_N), R5.2 (L_GAIN_N), U4.2 (L_GAIN_N)
L_GAIN_OUT: R5.1 (L_GAIN_OUT), R20.1 (L_GAIN_OUT), TP3.1, U4.1 (L_GAIN_OUT)
L_INPUT: C5.1 (L_INPUT), D1.2 (L_INPUT), K3.3 (L_INPUT), K4.3 (L_INPUT), R1.2 (L_INPUT), R3.1 (L_INPUT), TP1.1, U4.3 (L_INPUT)
L_INPUT_RAW: J1.1 (L_INPUT_RAW), R1.1 (L_INPUT_RAW)
L_VCOM_BUF: U5.2 (L_VCOM_BUF), U8.1 (L_VCOM_BUF), U8.2 (L_VCOM_BUF)
R_CAP47: C2.1 (R_CAP47), K3.5 (R_CAP47)
R_CAP100: C4.1 (R_CAP100), K4.5 (R_CAP100)
R_DRV_IN_N: C31.2 (R_DRV_IN_N), R31.2 (R_DRV_IN_N), R33.2 (R_DRV_IN_N), U6.1 (R_DRV_IN_N)
R_DRV_IN_P: C30.2 (R_DRV_IN_P), R30.2 (R_DRV_IN_P), R32.2 (R_DRV_IN_P), U6.8 (R_DRV_IN_P)
R_DRV_OUT_N: C30.1 (R_DRV_OUT_N), R32.1 (R_DRV_OUT_N), R35.1 (R_DRV_OUT_N), U6.5 (R_DRV_OUT_N)
R_DRV_OUT_P: C31.1 (R_DRV_OUT_P), R33.1 (R_DRV_OUT_P), R34.1 (R_DRV_OUT_P), U6.4 (R_DRV_OUT_P)
R_GAIN20: K2.7 (R_GAIN20), R10.1 (R_GAIN20)
R_GAIN26: K1.7 (R_GAIN26), R8.1 (R_GAIN26)
R_GAIN32: K2.5 (R_GAIN32), R12.1 (R_GAIN32)
R_GAIN_ALT: K1.5 (R_GAIN_ALT), K2.6 (R_GAIN_ALT)
R_GAIN_N: K1.6 (R_GAIN_N), R6.2 (R_GAIN_N), U4.6 (R_GAIN_N)
R_GAIN_OUT: R6.1 (R_GAIN_OUT), R30.1 (R_GAIN_OUT), TP4.1, U4.7 (R_GAIN_OUT)
R_INPUT: C6.1 (R_INPUT), D2.2 (R_INPUT), K3.6 (R_INPUT), K4.6 (R_INPUT), R2.2 (R_INPUT), R4.1 (R_INPUT), TP2.1, U4.5 (R_INPUT)
R_INPUT_RAW: J1.3 (R_INPUT_RAW), R2.1 (R_INPUT_RAW)
R_VCOM_BUF: U6.2 (R_VCOM_BUF), U8.6 (R_VCOM_BUF), U8.7 (R_VCOM_BUF)
SCKI_24M576: R40.2 (SCKI_24M576), TP13.1, U7.18 (SCKI_24M576)
SCKI_24M576_IN: J3.1 (SCKI_24M576_IN), R40.1 (SCKI_24M576_IN)
VCOM_L: C44.1 (VCOM_L), U7.3 (VCOM_L), U8.3 (VCOM_L)
VCOM_R: C45.1 (VCOM_R), U7.26 (VCOM_R), U8.5 (VCOM_R)
VREF_L: C40.1 (VREF_L), C41.1 (VREF_L), U7.1 (VREF_L)
VREF_R: C42.1 (VREF_R), C43.1 (VREF_R), U7.28 (VREF_R)

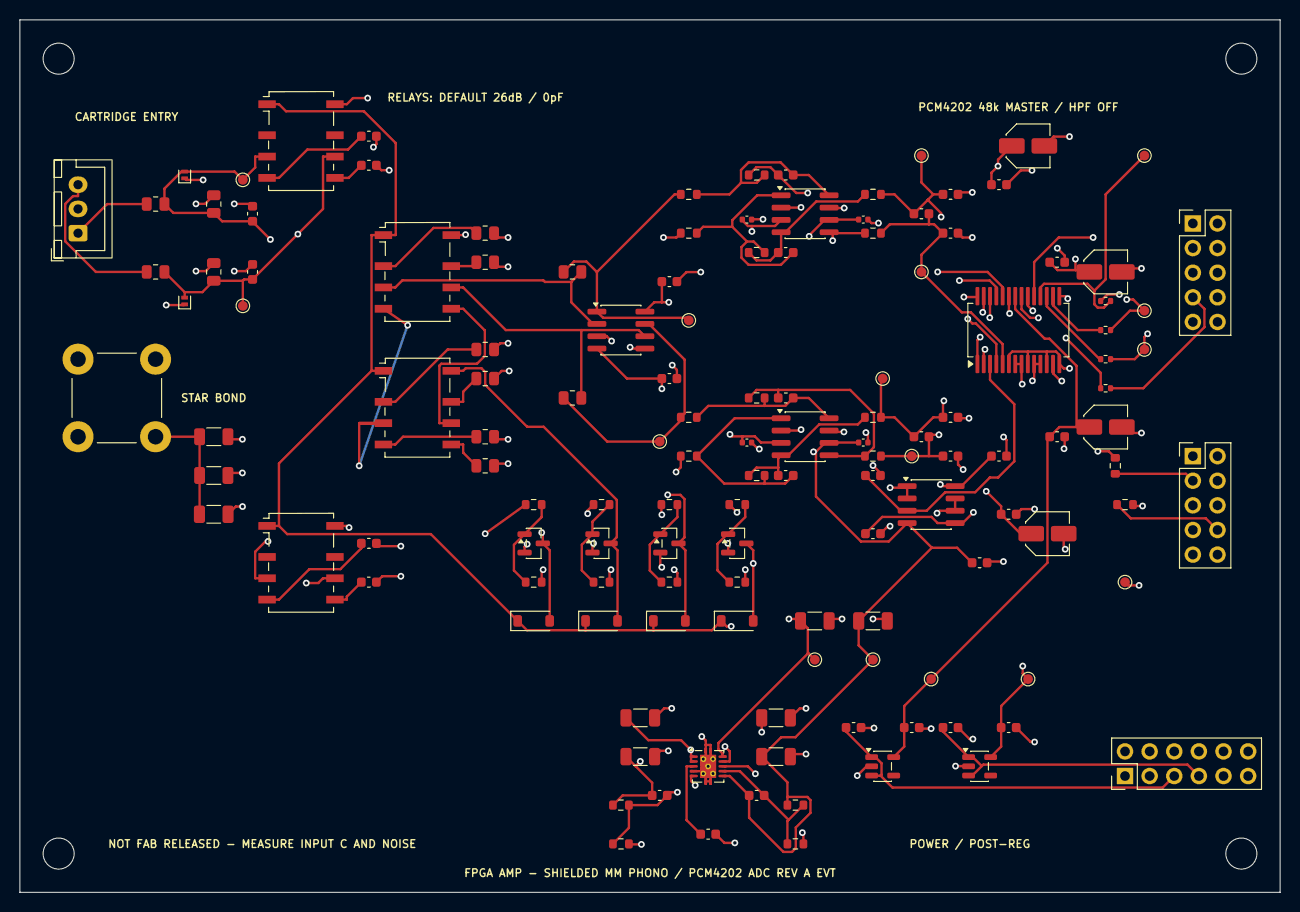
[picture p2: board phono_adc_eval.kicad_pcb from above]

Board: 4 copper layers, 130.0 x 90.0 mm, 139 parts (0 on the bottom side), 77 nets.

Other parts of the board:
H1, H2, H3, H4: M3_SHIELD_STANDOFF; MountingHole_3.2mm_M3

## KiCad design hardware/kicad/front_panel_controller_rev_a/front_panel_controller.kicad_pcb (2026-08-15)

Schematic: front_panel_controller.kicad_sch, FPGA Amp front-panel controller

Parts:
C1: 10uF_25V_X7R; C_1210_3225Metric
C2: 100nF_25V_X7R; C_0603_1608Metric
C3, C4: 22uF_6V3_X7R; C_1210_3225Metric
C5: 3.3nF_X7R; C_0603_1608Metric
C6: 1uF_50V_X7R; C_1206_3216Metric
C7: 220nF_X7R; C_0603_1608Metric
C10, C11, C12, C13, C14, C15, C16, C17, C18, C19, C20, C25, C27, C34, C40, C41, C42, C43, C44, C45, C47: 100nF_X7R; C_0402_1005Metric
C21: 4.7uF_X7R; C_0805_2012Metric
C22, C23: 2.2uF_LOW_ESR; C_0805_2012Metric
C24, C26, C33, C48: 1uF_X7R; C_0603_1608Metric
C28, C29: 12pF_C0G; C_0402_1005Metric
C30, C31: 10pF_C0G_DNP; C_0402_1005Metric
C32: 100nF; C_0603_1608Metric
C46: 10uF_X7R; C_0805_2012Metric
D1: SMBJ15A; D_SMB
D2: MBR0540T1G; D_SOD-123
D3: GREEN_STATUS; LED_0603_1608Metric
F1: 1.5A_PTC; Fuse_1206_3216Metric
FB1, FB2: 600R@100MHz; L_0603_1608Metric_Pad1.05x0.95mm_HandSolder
J1: UI_12V_INPUT; JST_VH_B2P-VH-B_1x02_P3.96mm_Vertical
J2: NHD-5.0-800480AF-ASXP-CTP_TFT; Molex_54104-4031_1x40-2MP_P0.50mm_Horizontal
J3: NHD_CTP_6P; Molex_52271-0679_1x06-2MP_P1.00mm_Horizontal
J4: MOTOR_VOLUME_BOARD; PinHeader_2x06_P2.54mm_Vertical
J5: DIGITAL_BOARD_CONTROL; PinHeader_2x08_P2.54mm_Vertical
J6: PANEL_CONTROLS; PinHeader_2x08_P2.54mm_Vertical
J7: CORTEX_SWD; PinHeader_2x05_P1.27mm_Vertical
JP1: BOOT0; PinHeader_1x02_P2.54mm_Vertical
L1: 2.2uH_4A; L_Bourns_SRN6045TA
L2: 10uH_1A; L_Bourns-SRN4018
R1, R2, R4, R42: 100k; R_0603_1608Metric
R3: 3.32R_1%; R_0805_2012Metric
R10, R11, R12, R13, R14, R15, R16, R17, R18, R19, R20, R21, R22, R23, R24, R25, R26, R27, R28, R29: 33R; R_0402_1005Metric
R30, R31: 22R; R_0402_1005Metric
R40: 0R; R_0402_1005Metric
R41, R45, R46, R47, R48, R49, R50: 10k; R_0603_1608Metric
R43, R44: 2.2k; R_0603_1608Metric
R51: 1k; R_0603_1608Metric
SW1: RESET; Panasonic_EVQPUJ_EVQPUA
TP1: +12V_UI; TestPoint_Plated_Hole_D2.0mm
TP2: +3V3; TestPoint_Plated_Hole_D2.0mm
TP3: GND; TestPoint_Plated_Hole_D2.0mm
TP4: VCAP_CORE; TestPoint_Plated_Hole_D2.0mm
TP5: VDDA; TestPoint_Plated_Hole_D2.0mm
TP6: LCD_LED_A; TestPoint_Plated_Hole_D2.0mm
TP7: BL_FB; TestPoint_Plated_Hole_D2.0mm
TP8: NRST; TestPoint_Plated_Hole_D2.0mm
U1: STM32H753ZIT6; LQFP-144_20x20mm_P0.5mm
U2: IS42S16160J-6TLI_32MiB; TSOP-II-54_22.2x10.16mm_P0.8mm
U3: W25Q256JVSIQ_32MiB; SOIC-8_5.3x5.3mm_P1.27mm
U4: TPS62132RGTR_3V3_3A; VQFN-16-1EP_3x3mm_P0.5mm_EP1.6x1.6mm_ThermalVias
U5: TPS61165DRVR; WSON-6-1EP_2x2mm_P0.65mm_EP1x1.6mm_ThermalVias
Y1: 25MHz_10pF; Crystal_SMD_3225-4Pin_3.2x2.5mm
Y2: 32.768kHz_7pF; Crystal_SMD_3215-2Pin_3.2x1.5mm

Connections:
+3V3: C3.1 (+3V3), C4.1 (+3V3), C10.1 (+3V3), C11.1 (+3V3), C12.1 (+3V3), C13.1 (+3V3), C14.1 (+3V3), C15.1 (+3V3), C16.1 (+3V3), C17.1 (+3V3), C18.1 (+3V3), C19.1 (+3V3), C20.1 (+3V3), C21.1 (+3V3), C40.1 (+3V3), C41.1 (+3V3), C42.1 (+3V3), C43.1 (+3V3), C44.1 (+3V3), C45.1 (+3V3), C46.1 (+3V3), C47.1 (+3V3), C48.1 (+3V3), FB1.1 (+3V3), FB2.1 (+3V3), J2.4 (+3V3), J4.1 (+3V3), J5.1 (+3V3), J6.1 (+3V3), J7.1 (+3V3), JP1.1 (+3V3), L1.2 (+3V3), R2.2 (+3V3), R41.1 (+3V3), R47.1 (+3V3), R49.1 (+3V3), R50.1 (+3V3), TP2.1, U1.6 (+3V3), U1.17 (+3V3), U1.30 (+3V3), U1.39 (+3V3), U1.52 (+3V3), U1.62 (+3V3), U1.72 (+3V3), U1.84 (+3V3), U1.95 (+3V3), U1.108 (+3V3), U1.121 (+3V3), U1.131 (+3V3), U1.143 (+3V3), U1.144 (+3V3), U2.1 (+3V3), U2.3 (+3V3), U2.9 (+3V3), U2.14 (+3V3), U2.27 (+3V3), U2.43 (+3V3), U2.49 (+3V3), U3.8 (+3V3), U4.14 (+3V3)
+3V3_TOUCH: C33.1 (+3V3_TOUCH), C34.1 (+3V3_TOUCH), FB2.2 (+3V3_TOUCH), J3.1 (+3V3_TOUCH), R43.1 (+3V3_TOUCH), R44.1 (+3V3_TOUCH), R45.1 (+3V3_TOUCH), R46.1 (+3V3_TOUCH)
+12V_UI: C1.1 (+12V_UI), C2.1 (+12V_UI), D1.2 (+12V_UI), F1.2 (+12V_UI), L2.1 (+12V_UI), R1.1 (+12V_UI), TP1.1, U4.10 (+12V_UI), U4.11 (+12V_UI), U4.12 (+12V_UI), U5.6 (+12V_UI)
AMBIENT_ADC: J6.14 (AMBIENT_ADC), U1.41 (AMBIENT_ADC)
BACKLIGHT_PWM: R4.1 (BACKLIGHT_PWM), U1.98 (BACKLIGHT_PWM), U5.5 (BACKLIGHT_PWM)
BL_COMP: C7.1 (BL_COMP), U5.2 (BL_COMP)
BL_FB: J2.1 (BL_FB), R3.1 (BL_FB), TP7.1, U5.1 (BL_FB)
BL_SW: D2.1 (BL_SW), L2.2 (BL_SW), U5.4 (BL_SW)
BOOT0: JP1.2 (BOOT0), R42.1 (BOOT0), U1.138 (BOOT0)
BUCK_EN: R1.2 (BUCK_EN), U4.13 (BUCK_EN)
BUCK_PG: R2.1 (BUCK_PG), U4.4 (BUCK_PG)
BUCK_SS: C5.1 (BUCK_SS), U4.9 (BUCK_SS)
BUCK_SW: L1.1 (BUCK_SW), U4.1 (BUCK_SW), U4.2 (BUCK_SW), U4.3 (BUCK_SW)
DB_IRQ_N: J5.7 (DB_IRQ_N), R50.2 (DB_IRQ_N), U1.80 (DB_IRQ_N)
DB_SPI_CS_N: J5.4 (DB_SPI_CS_N), R49.2 (DB_SPI_CS_N), U1.73 (DB_SPI_CS_N)
DB_SPI_MISO: J5.5 (DB_SPI_MISO), U1.75 (DB_SPI_MISO)
DB_SPI_MOSI: J5.6 (DB_SPI_MOSI), U1.76 (DB_SPI_MOSI)
DB_SPI_SCK: J5.3 (DB_SPI_SCK), U1.74 (DB_SPI_SCK)
FORCE_MUTE_N: J5.9 (FORCE_MUTE_N), R48.1 (FORCE_MUTE_N), U1.113 (FORCE_MUTE_N)
GND: C1.2 (GND), C2.2 (GND), C3.2 (GND), C4.2 (GND), C5.2 (GND), C6.2 (GND), C7.2 (GND), C10.2 (GND), C11.2 (GND), C12.2 (GND), C13.2 (GND), C14.2 (GND), C15.2 (GND), C16.2 (GND), C17.2 (GND), C18.2 (GND), C19.2 (GND), C20.2 (GND), C21.2 (GND), C22.2 (GND), C23.2 (GND), C24.2 (GND), C25.2 (GND), C26.2 (GND), C27.2 (GND), C28.2 (GND), C29.2 (GND), C30.2 (GND), C31.2 (GND), C32.2 (GND), C33.2 (GND), C34.2 (GND), C40.2 (GND), C41.2 (GND), C42.2 (GND), C43.2 (GND), C44.2 (GND), C45.2 (GND), C46.2 (GND), C47.2 (GND), C48.2 (GND), D1.1 (GND), D3.1 (GND), J1.2 (GND), J2.3 (GND), J2.5 (GND), J2.6 (GND), J2.7 (GND), J2.13 (GND), J2.14 (GND), J2.21 (GND), J2.22 (GND), J2.23 (GND), J2.29 (GND), J2.36 (GND), J3.2 (GND), J4.2 (GND), J4.11 (GND), J4.12 (GND), J5.2 (GND), J5.10 (GND), J6.2 (GND), J6.15 (GND), J6.16 (GND), J7.3 (GND), J7.5 (GND), J7.9 (GND), R3.2 (GND), R4.2 (GND), R42.2 (GND), R48.2 (GND), SW1.2 (GND), TP3.1, U1.16 (GND), U1.31 (GND), U1.38 (GND), U1.51 (GND), U1.61 (GND), U1.83 (GND), U1.94 (GND), U1.107 (GND), U1.120 (GND), U1.130 (GND), U2.6 (GND), U2.12 (GND), U2.28 (GND), U2.41 (GND), U2.46 (GND), U2.52 (GND), U2.54 (GND), U3.4 (GND), U4.5 (GND), U4.6 (GND), U4.7 (GND), U4.8 (GND), U4.15 (GND), U4.16 (GND), U4.17 (GND), U5.3 (GND), U5.7 (GND), Y1.2 (GND), Y1.4 (GND)
HSE_IN: C28.1 (HSE_IN), U1.23 (HSE_IN), Y1.1 (HSE_IN)
HSE_OUT: C29.1 (HSE_OUT), U1.24 (HSE_OUT), Y1.3 (HSE_OUT)
LCD_B3: J2.24 (LCD_B3), R10.2 (LCD_B3)
LCD_B3_MCU: R10.1 (LCD_B3_MCU), U1.126 (LCD_B3_MCU)
LCD_B4: J2.25 (LCD_B4), R11.2 (LCD_B4)
LCD_B4_MCU: R11.1 (LCD_B4_MCU), U1.127 (LCD_B4_MCU)
LCD_B5: J2.26 (LCD_B5), R12.2 (LCD_B5)
LCD_B5_MCU: R12.1 (LCD_B5_MCU), U1.37 (LCD_B5_MCU)
LCD_B6: J2.27 (LCD_B6), R13.2 (LCD_B6)
LCD_B6_MCU: R13.1 (LCD_B6_MCU), U1.139 (LCD_B6_MCU)
LCD_B7: J2.28 (LCD_B7), R14.2 (LCD_B7)
LCD_B7_MCU: R14.1 (LCD_B7_MCU), U1.140 (LCD_B7_MCU)
LCD_CLK: J2.30 (LCD_CLK), R15.2 (LCD_CLK)
LCD_CLK_MCU: R15.1 (LCD_CLK_MCU), U1.92 (LCD_CLK_MCU)
LCD_DE: J2.34 (LCD_DE), R16.2 (LCD_DE)
LCD_DE_MCU: R16.1 (LCD_DE_MCU), U1.22 (LCD_DE_MCU)
LCD_G2: J2.15 (LCD_G2), R17.2 (LCD_G2)
LCD_G2_MCU: R17.1 (LCD_G2_MCU), U1.42 (LCD_G2_MCU)
LCD_G3: J2.16 (LCD_G3), R18.2 (LCD_G3)
LCD_G3_MCU: R18.1 (LCD_G3_MCU), U1.125 (LCD_G3_MCU)
LCD_G4: J2.17 (LCD_G4), R19.2 (LCD_G4)
LCD_G4_MCU: R19.1 (LCD_G4_MCU), U1.69 (LCD_G4_MCU)
LCD_G5: J2.18 (LCD_G5), R20.2 (LCD_G5)
LCD_G5_MCU: R20.1 (LCD_G5_MCU), U1.70 (LCD_G5_MCU)
LCD_G6: J2.19 (LCD_G6), R21.2 (LCD_G6)
LCD_G6_MCU: R21.1 (LCD_G6_MCU), U1.97 (LCD_G6_MCU)
LCD_G7: J2.20 (LCD_G7), R22.2 (LCD_G7)
LCD_G7_MCU: R22.1 (LCD_G7_MCU), U1.117 (LCD_G7_MCU)
LCD_HSYNC: J2.32 (LCD_HSYNC), R23.2 (LCD_HSYNC)
LCD_HSYNC_MCU: R23.1 (LCD_HSYNC_MCU), U1.96 (LCD_HSYNC_MCU)
LCD_LED_A: C6.1 (LCD_LED_A), D2.2 (LCD_LED_A), J2.2 (LCD_LED_A), TP6.1
LCD_R3: J2.8 (LCD_R3), R24.2 (LCD_R3)
LCD_R3_MCU: R24.1 (LCD_R3_MCU), U1.46 (LCD_R3_MCU)
LCD_R4: J2.9 (LCD_R4), R25.2 (LCD_R4)
LCD_R4_MCU: R25.1 (LCD_R4_MCU), U1.103 (LCD_R4_MCU)
LCD_R5: J2.10 (LCD_R5), R26.2 (LCD_R5)
LCD_R5_MCU: R26.1 (LCD_R5_MCU), U1.101 (LCD_R5_MCU)
LCD_R6: J2.11 (LCD_R6), R27.2 (LCD_R6)
LCD_R6_MCU: R27.1 (LCD_R6_MCU), U1.47 (LCD_R6_MCU)
LCD_R7: J2.12 (LCD_R7), R28.2 (LCD_R7)
LCD_R7_MCU: R28.1 (LCD_R7_MCU), U1.91 (LCD_R7_MCU)
LCD_STBY_N: J2.31 (LCD_STBY_N), U1.1 (LCD_STBY_N)
LCD_VSYNC: J2.33 (LCD_VSYNC), R29.2 (LCD_VSYNC)
LCD_VSYNC_MCU: R29.1 (LCD_VSYNC_MCU), U1.40 (LCD_VSYNC_MCU)
LSE_IN: C30.1 (LSE_IN), U1.8 (LSE_IN), Y2.1 (LSE_IN)
LSE_OUT: C31.1 (LSE_OUT), U1.9 (LSE_OUT), Y2.2 (LSE_OUT)
MODEL_ENC_A: J6.6 (MODEL_ENC_A), U1.134 (MODEL_ENC_A)
MODEL_ENC_B: J6.7 (MODEL_ENC_B), U1.135 (MODEL_ENC_B)
MODEL_PUSH: J6.8 (MODEL_PUSH), U1.128 (MODEL_PUSH)
MOTOR_BOARD_ID: J4.10 (MOTOR_BOARD_ID), U1.27 (MOTOR_BOARD_ID)
MOTOR_CURRENT_ADC: J4.7 (MOTOR_CURRENT_ADC), U1.28 (MOTOR_CURRENT_ADC)
MOTOR_DIR: J4.4 (MOTOR_DIR), U1.118 (MOTOR_DIR)
MOTOR_FAULT_N: J4.6 (MOTOR_FAULT_N), U1.122 (MOTOR_FAULT_N)
MOTOR_PWM: J4.3 (MOTOR_PWM), U1.43 (MOTOR_PWM)
MOTOR_SLEEP: J4.5 (MOTOR_SLEEP), U1.119 (MOTOR_SLEEP)
MUTE_BUTTON: J6.12 (MUTE_BUTTON), U1.111 (MUTE_BUTTON)
NRST: C32.1 (NRST), J7.10 (NRST), R41.2 (NRST), SW1.1 (NRST), TP8.1, U1.25 (NRST)
PARAM_ENC_A: J6.9 (PARAM_ENC_A), U1.81 (PARAM_ENC_A)
PARAM_ENC_B: J6.10 (PARAM_ENC_B), U1.82 (PARAM_ENC_B)
PARAM_PUSH: J6.11 (PARAM_PUSH), U1.129 (PARAM_PUSH)
POT_A_ADC: J4.8 (POT_A_ADC), U1.29 (POT_A_ADC)
POT_B_ADC: J4.9 (POT_B_ADC), U1.36 (POT_B_ADC)
QSPI_CLK: R31.2 (QSPI_CLK), U3.6 (QSPI_CLK)
QSPI_CLK_MCU: R31.1 (QSPI_CLK_MCU), U1.48 (QSPI_CLK_MCU)
QSPI_CS_N: R47.2 (QSPI_CS_N), U1.136 (QSPI_CS_N), U3.1 (QSPI_CS_N)
QSPI_IO0: U1.20 (QSPI_IO0), U3.5 (QSPI_IO0)
QSPI_IO1: U1.21 (QSPI_IO1), U3.2 (QSPI_IO1)
QSPI_IO2: U1.19 (QSPI_IO2), U3.3 (QSPI_IO2)
QSPI_IO3: U1.18 (QSPI_IO3), U3.7 (QSPI_IO3)
SDRAM_A0: U1.10 (SDRAM_A0), U2.23 (SDRAM_A0)
SDRAM_A1: U1.11 (SDRAM_A1), U2.24 (SDRAM_A1)
SDRAM_A2: U1.12 (SDRAM_A2), U2.25 (SDRAM_A2)
SDRAM_A3: U1.13 (SDRAM_A3), U2.26 (SDRAM_A3)
SDRAM_A4: U1.14 (SDRAM_A4), U2.29 (SDRAM_A4)
SDRAM_A5: U1.15 (SDRAM_A5), U2.30 (SDRAM_A5)
SDRAM_A6: U1.50 (SDRAM_A6), U2.31 (SDRAM_A6)
SDRAM_A7: U1.53 (SDRAM_A7), U2.32 (SDRAM_A7)
SDRAM_A8: U1.54 (SDRAM_A8), U2.33 (SDRAM_A8)
SDRAM_A9: U1.55 (SDRAM_A9), U2.34 (SDRAM_A9)
SDRAM_A10: U1.56 (SDRAM_A10), U2.22 (SDRAM_A10)
SDRAM_A11: U1.57 (SDRAM_A11), U2.35 (SDRAM_A11)
SDRAM_A12: U1.87 (SDRAM_A12), U2.19 (SDRAM_A12)
SDRAM_BA0: U1.89 (SDRAM_BA0), U2.20 (SDRAM_BA0)
SDRAM_BA1: U1.90 (SDRAM_BA1), U2.21 (SDRAM_BA1)
SDRAM_CAS_N: U1.132 (SDRAM_CAS_N), U2.38 (SDRAM_CAS_N)
SDRAM_CKE: U1.45 (SDRAM_CKE), U2.18 (SDRAM_CKE)
SDRAM_CLK: R30.2 (SDRAM_CLK), U2.17 (SDRAM_CLK)
SDRAM_CLK_MCU: R30.1 (SDRAM_CLK_MCU), U1.93 (SDRAM_CLK_MCU)
SDRAM_CS_N: U1.44 (SDRAM_CS_N), U2.36 (SDRAM_CS_N)
SDRAM_D0: U1.85 (SDRAM_D0), U2.2 (SDRAM_D0)
SDRAM_D1: U1.86 (SDRAM_D1), U2.4 (SDRAM_D1)
SDRAM_D2: U1.114 (SDRAM_D2), U2.5 (SDRAM_D2)
SDRAM_D3: U1.115 (SDRAM_D3), U2.7 (SDRAM_D3)
SDRAM_D4: U1.58 (SDRAM_D4), U2.8 (SDRAM_D4)
SDRAM_D5: U1.59 (SDRAM_D5), U2.10 (SDRAM_D5)
SDRAM_D6: U1.60 (SDRAM_D6), U2.11 (SDRAM_D6)
SDRAM_D7: U1.63 (SDRAM_D7), U2.13 (SDRAM_D7)
SDRAM_D8: U1.64 (SDRAM_D8), U2.42 (SDRAM_D8)
SDRAM_D9: U1.65 (SDRAM_D9), U2.44 (SDRAM_D9)
SDRAM_D10: U1.66 (SDRAM_D10), U2.45 (SDRAM_D10)
SDRAM_D11: U1.67 (SDRAM_D11), U2.47 (SDRAM_D11)
SDRAM_D12: U1.68 (SDRAM_D12), U2.48 (SDRAM_D12)
SDRAM_D13: U1.77 (SDRAM_D13), U2.50 (SDRAM_D13)
SDRAM_D14: U1.78 (SDRAM_D14), U2.51 (SDRAM_D14)
SDRAM_D15: U1.79 (SDRAM_D15), U2.53 (SDRAM_D15)
SDRAM_LDQM: U1.141 (SDRAM_LDQM), U2.15 (SDRAM_LDQM)
SDRAM_RAS_N: U1.49 (SDRAM_RAS_N), U2.37 (SDRAM_RAS_N)
SDRAM_UDQM: U1.142 (SDRAM_UDQM), U2.16 (SDRAM_UDQM)
SDRAM_WE_N: U1.26 (SDRAM_WE_N), U2.39 (SDRAM_WE_N)
SOURCE_ENC_A: J6.3 (SOURCE_ENC_A), U1.34 (SOURCE_ENC_A)
SOURCE_ENC_B: J6.4 (SOURCE_ENC_B), U1.35 (SOURCE_ENC_B)
SOURCE_PUSH: J6.5 (SOURCE_PUSH), U1.88 (SOURCE_PUSH)
STANDBY_BUTTON: J6.13 (STANDBY_BUTTON), U1.112 (STANDBY_BUTTON)
STATUS_LED: R51.1 (STATUS_LED), U1.2 (STATUS_LED)
STATUS_LED_A: D3.2 (STATUS_LED_A), R51.2 (STATUS_LED_A)
SWCLK: J7.4 (SWCLK), U1.109 (SWCLK)
SWDIO: J7.2 (SWDIO), U1.105 (SWDIO)
SWO: J7.6 (SWO), U1.133 (SWO)
TOUCH_INT_N: J3.5 (TOUCH_INT_N), R45.2 (TOUCH_INT_N), U1.124 (TOUCH_INT_N)
TOUCH_RESET_N: J3.6 (TOUCH_RESET_N), R46.2 (TOUCH_RESET_N), U1.123 (TOUCH_RESET_N)
TOUCH_SCL: J3.3 (TOUCH_SCL), R43.2 (TOUCH_SCL), U1.100 (TOUCH_SCL)
TOUCH_SDA: J3.4 (TOUCH_SDA), R44.2 (TOUCH_SDA), U1.99 (TOUCH_SDA)
UI_12V_IN: F1.1 (UI_12V_IN), J1.1 (UI_12V_IN)
UI_ALIVE: J5.8 (UI_ALIVE), U1.116 (UI_ALIVE)
VCAP_CORE: C22.1 (VCAP_CORE), C23.1 (VCAP_CORE), TP4.1, U1.71 (VCAP_CORE), U1.106 (VCAP_CORE)
VDDA: C24.1 (VDDA), C25.1 (VDDA), FB1.2 (VDDA), R40.1 (VDDA), TP5.1, U1.33 (VDDA)
VREF_PLUS: C26.1 (VREF_PLUS), C27.1 (VREF_PLUS), R40.2 (VREF_PLUS), U1.32 (VREF_PLUS)

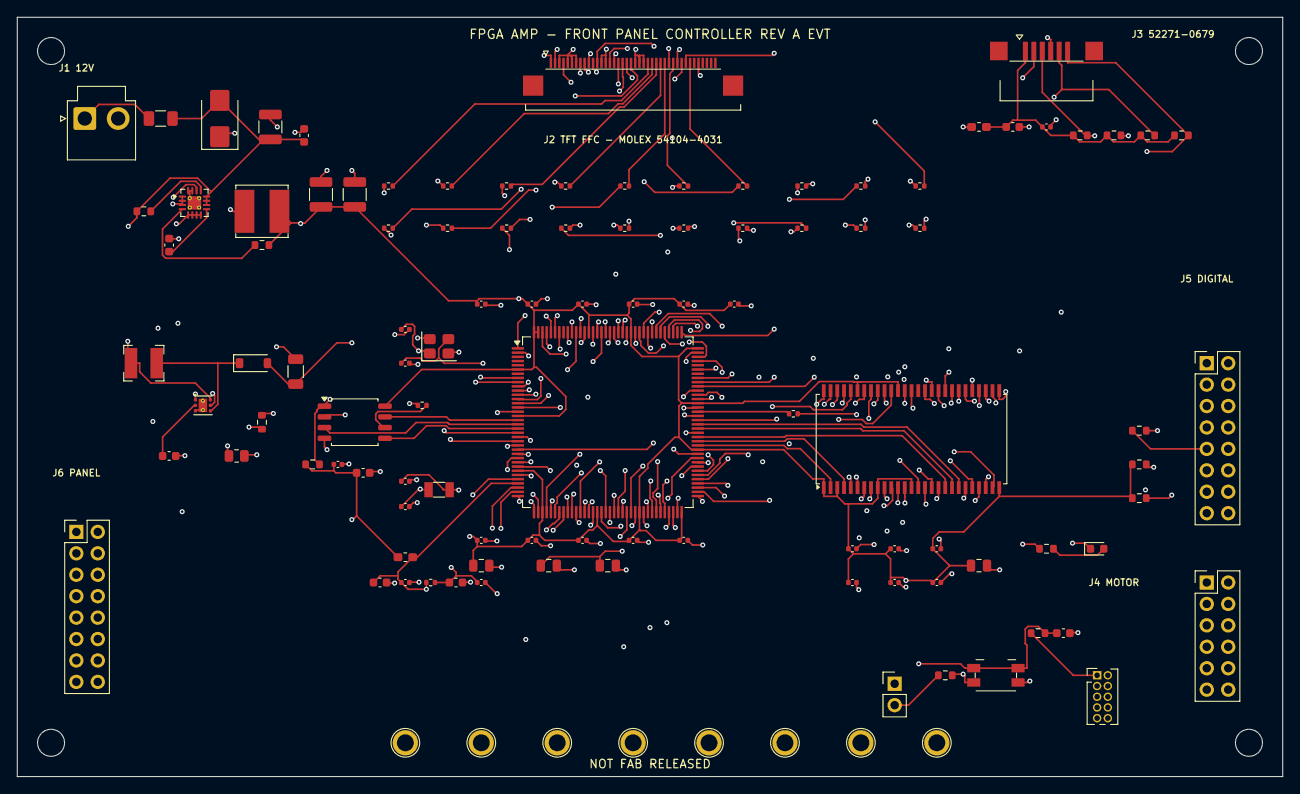
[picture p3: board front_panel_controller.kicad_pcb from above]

Board: 6 copper layers, 150.0 x 90.0 mm, 115 parts (0 on the bottom side), 147 nets.

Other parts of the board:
H1, H2, H3, H4: M3_CHASSIS; MountingHole_3.2mm_M3

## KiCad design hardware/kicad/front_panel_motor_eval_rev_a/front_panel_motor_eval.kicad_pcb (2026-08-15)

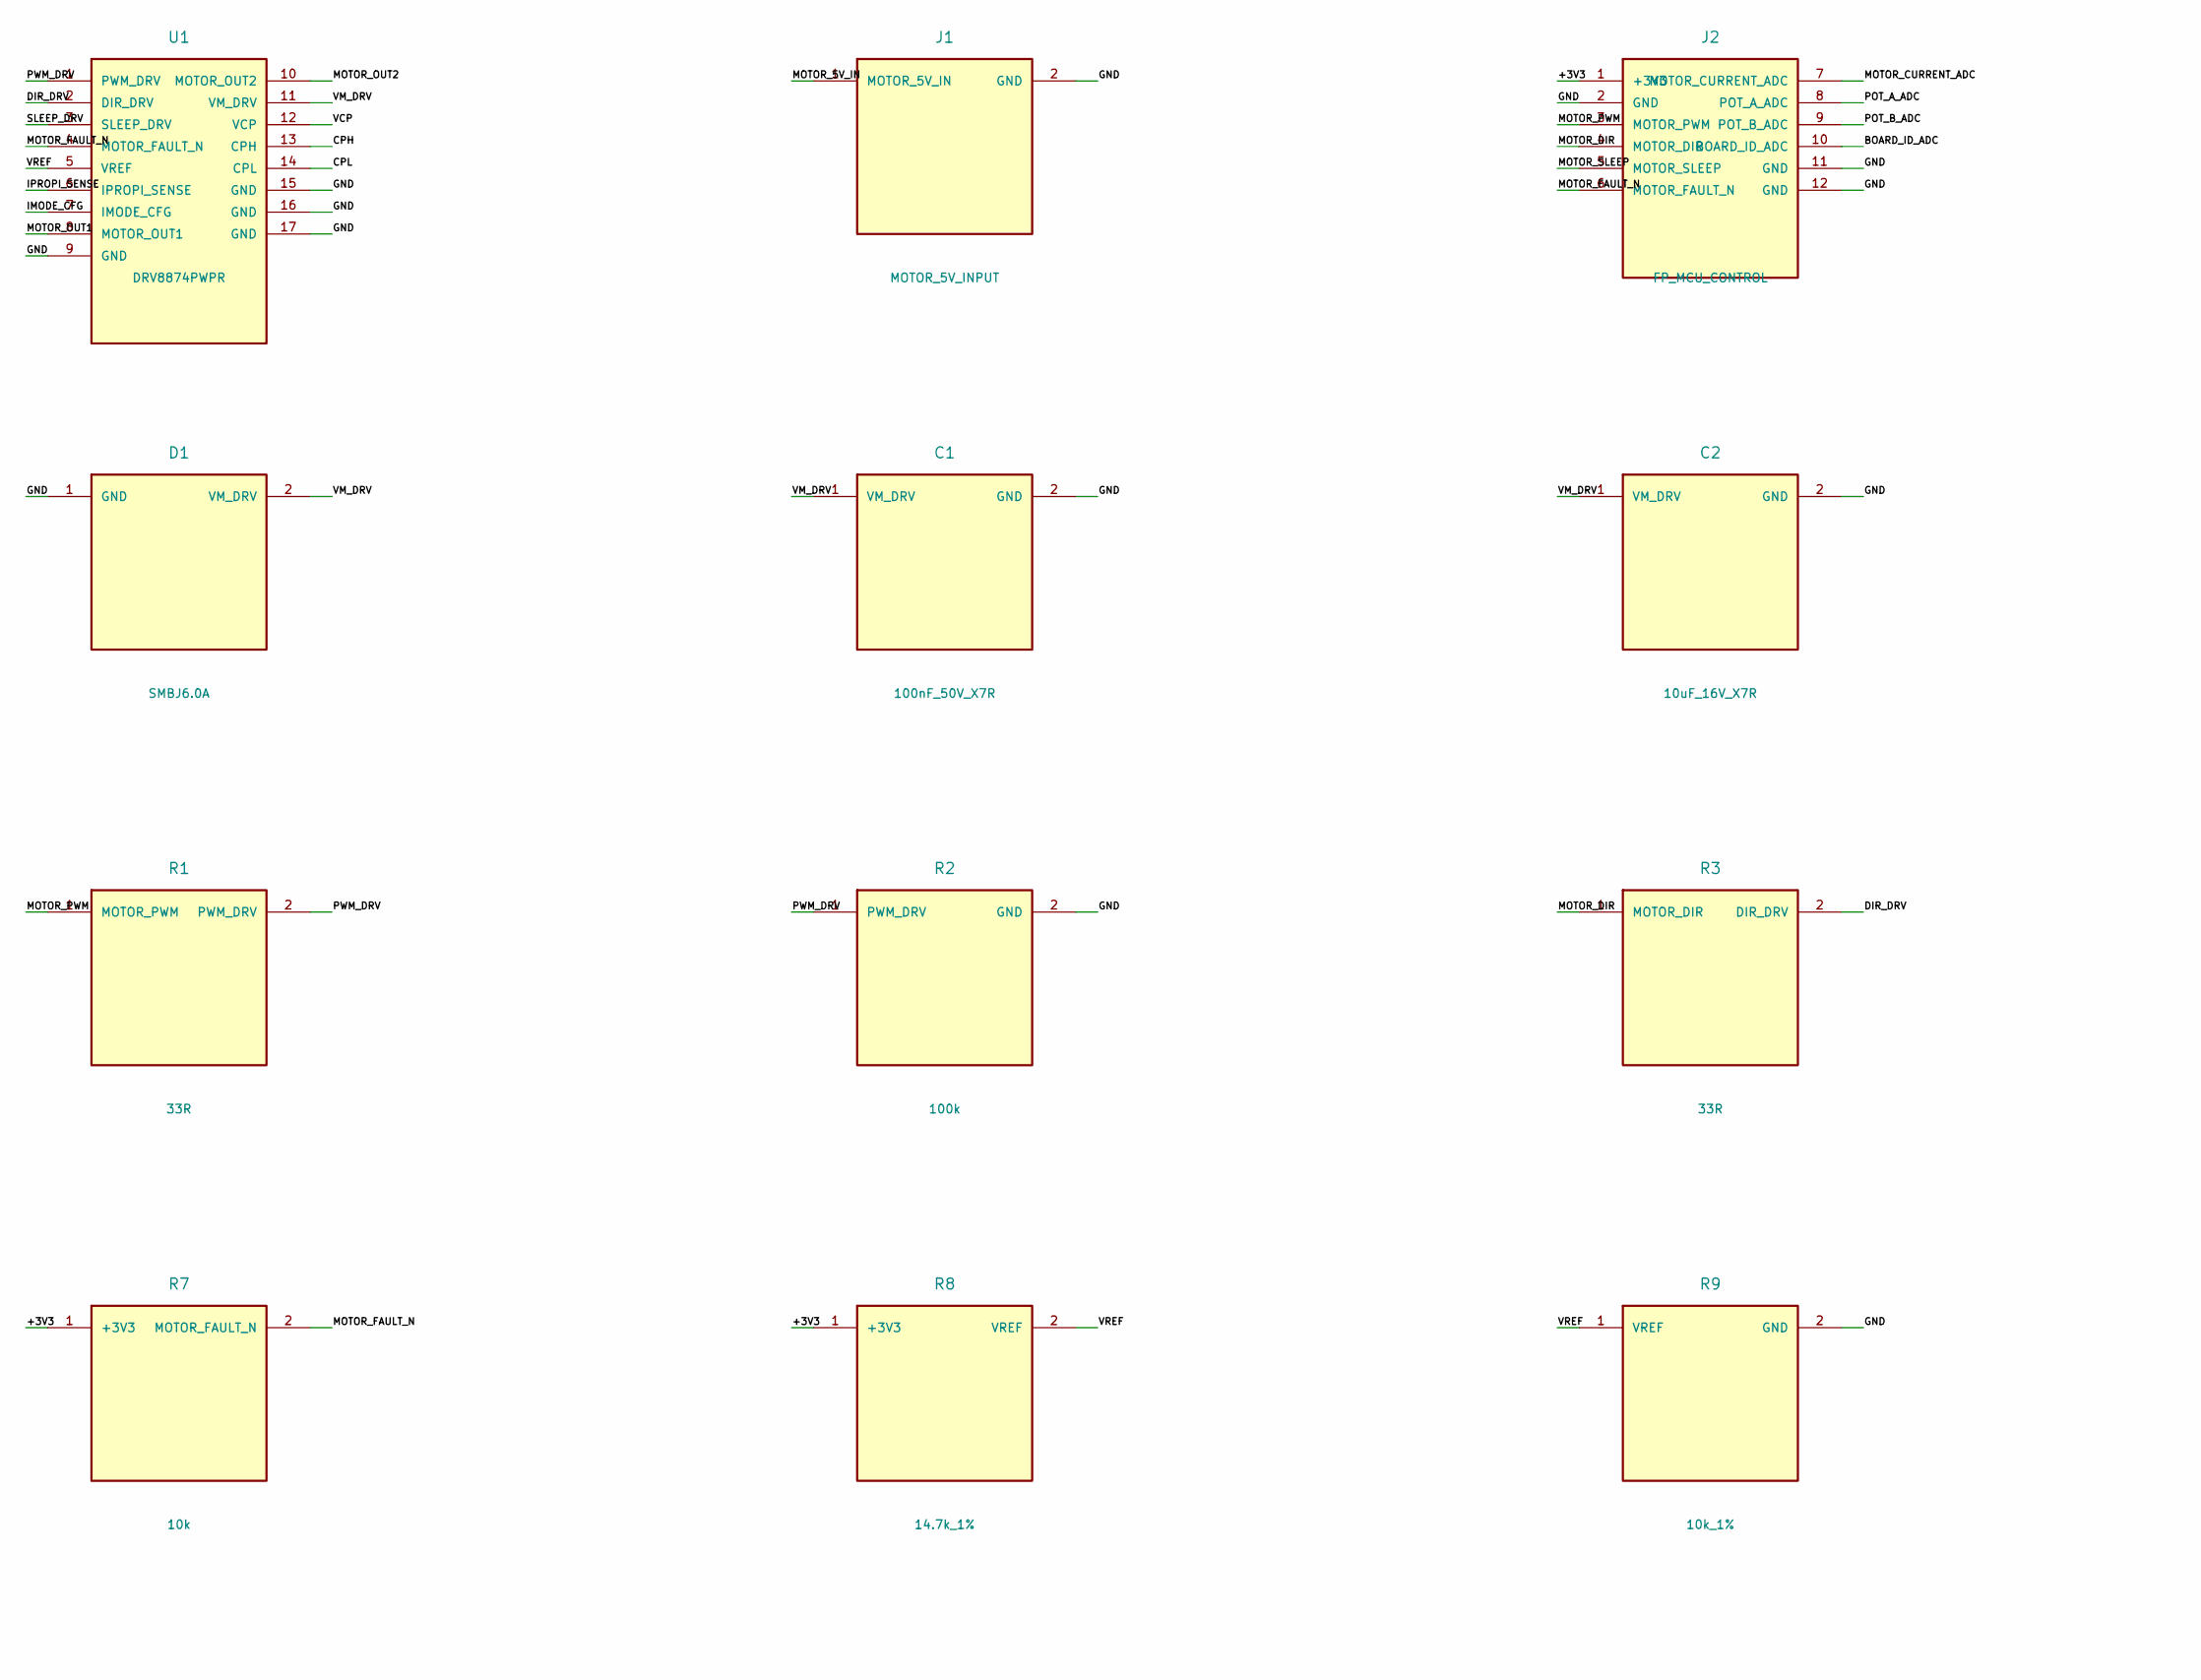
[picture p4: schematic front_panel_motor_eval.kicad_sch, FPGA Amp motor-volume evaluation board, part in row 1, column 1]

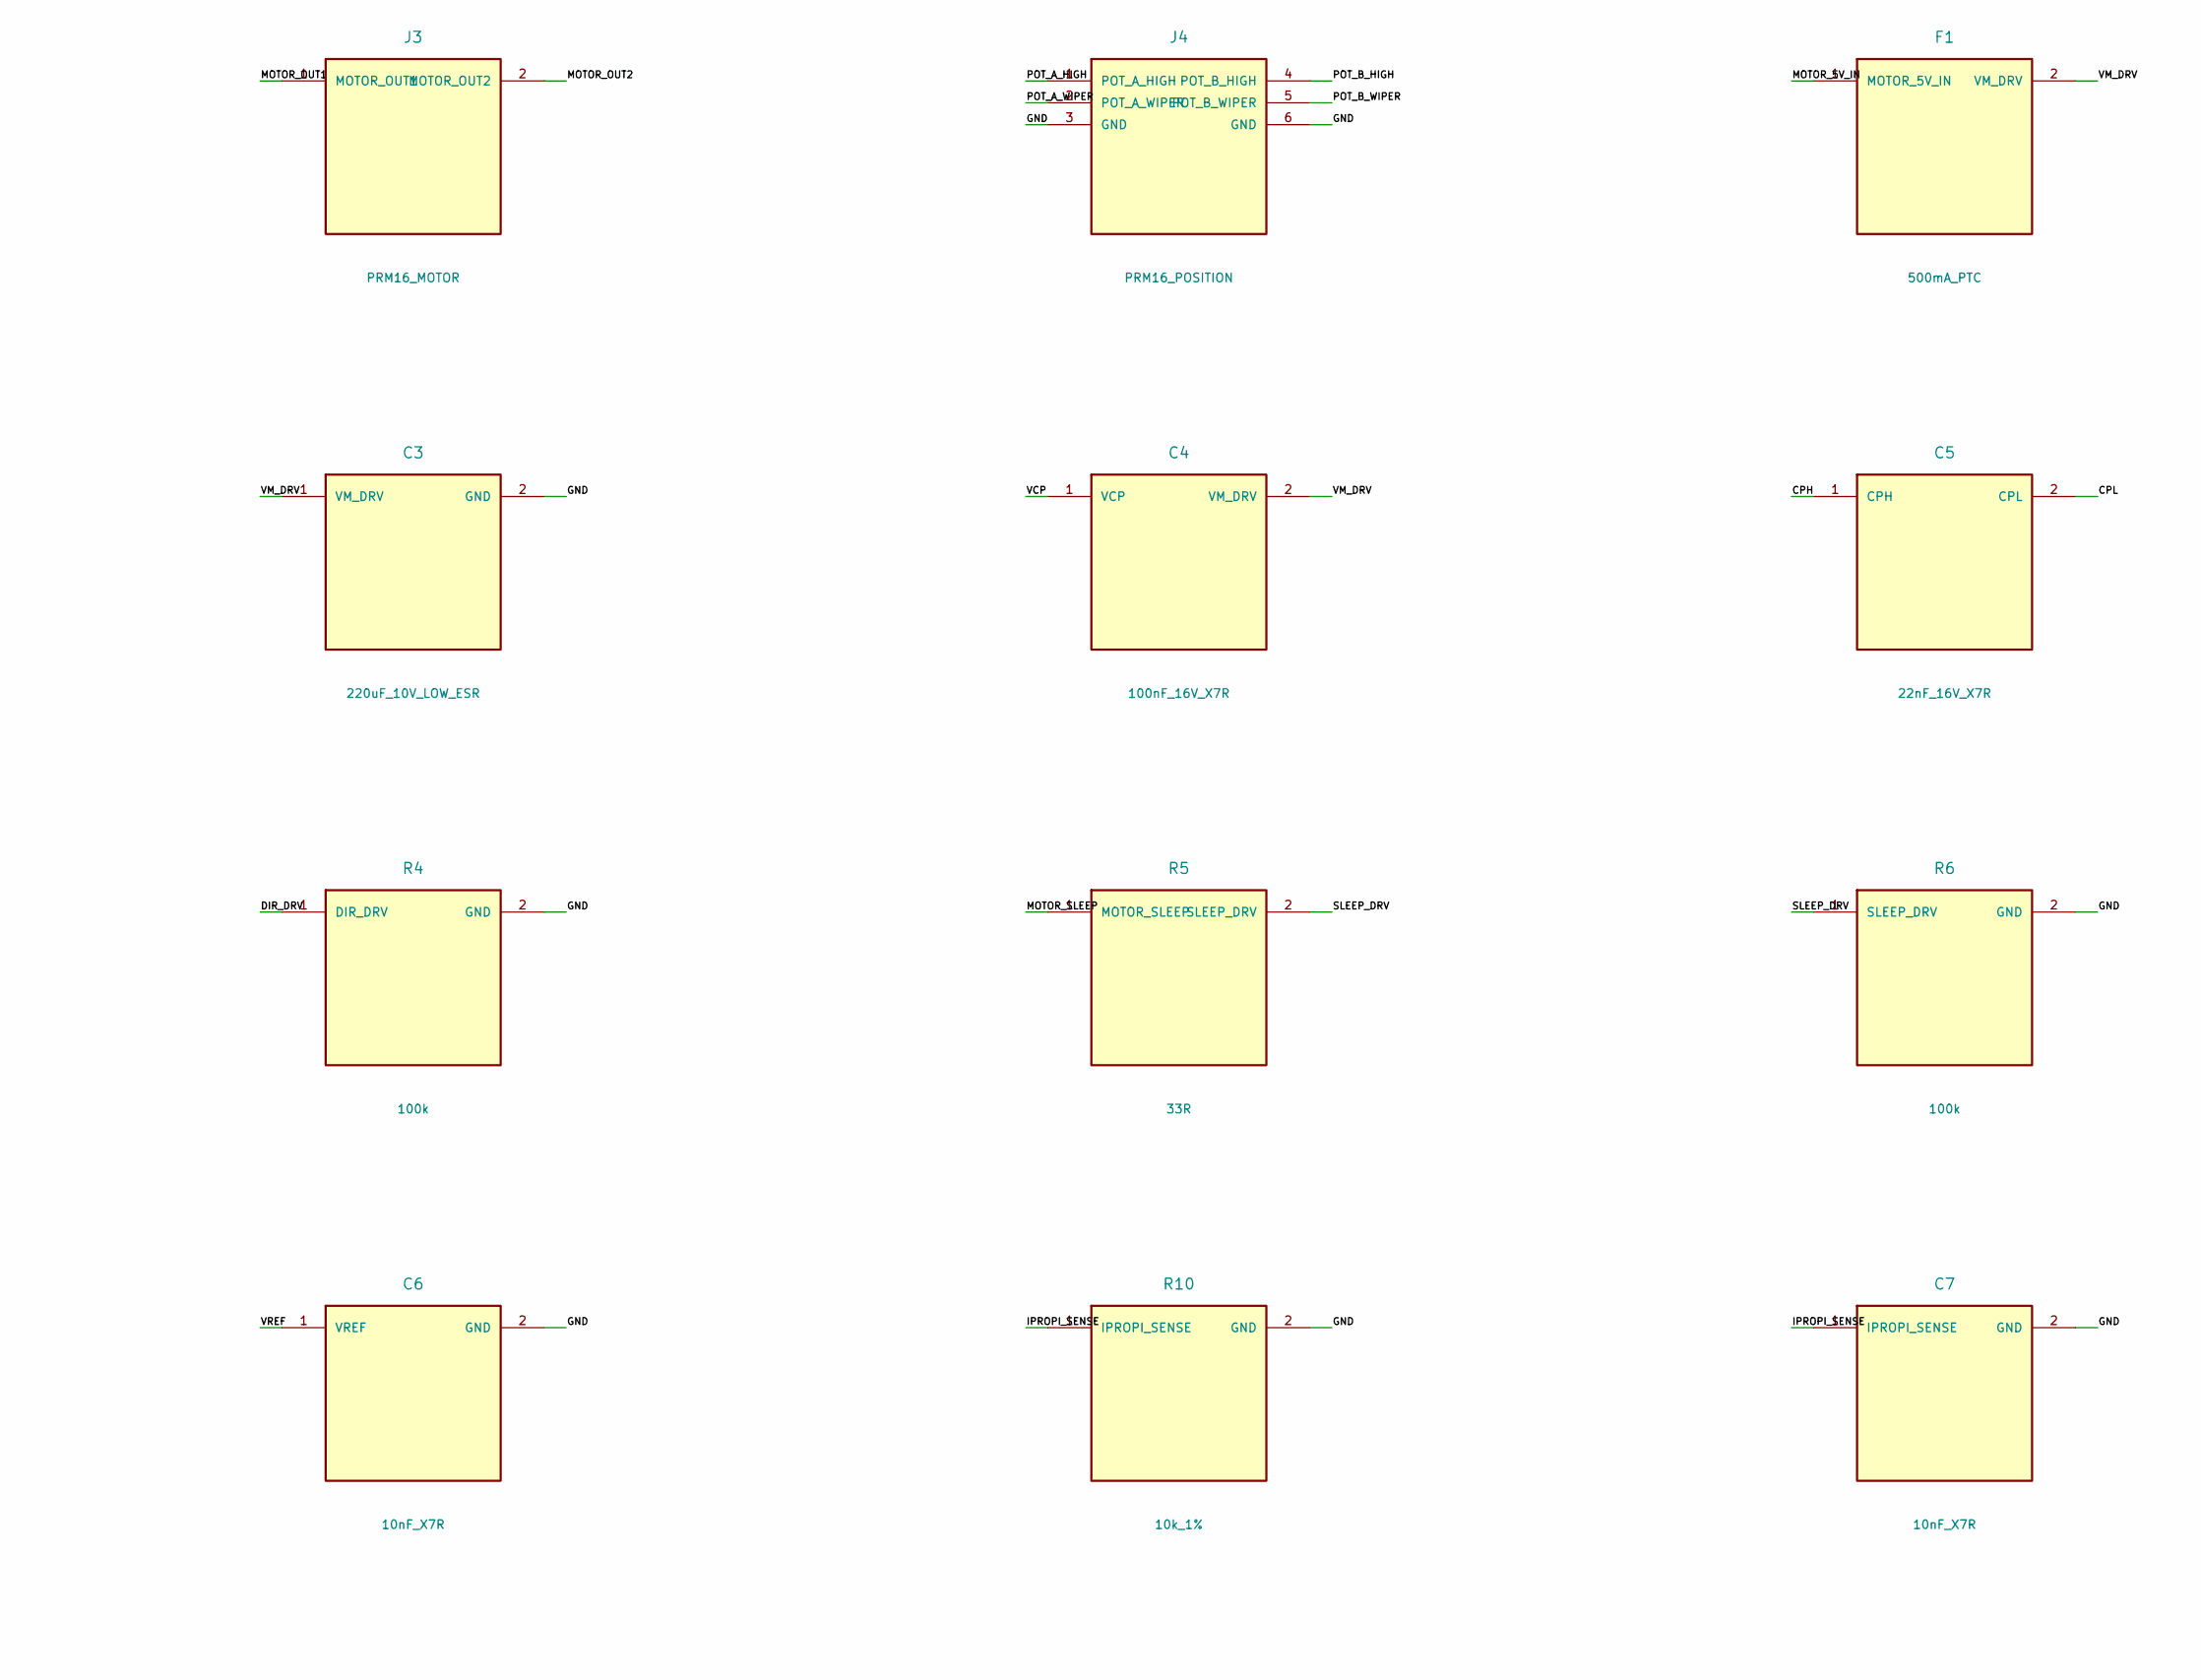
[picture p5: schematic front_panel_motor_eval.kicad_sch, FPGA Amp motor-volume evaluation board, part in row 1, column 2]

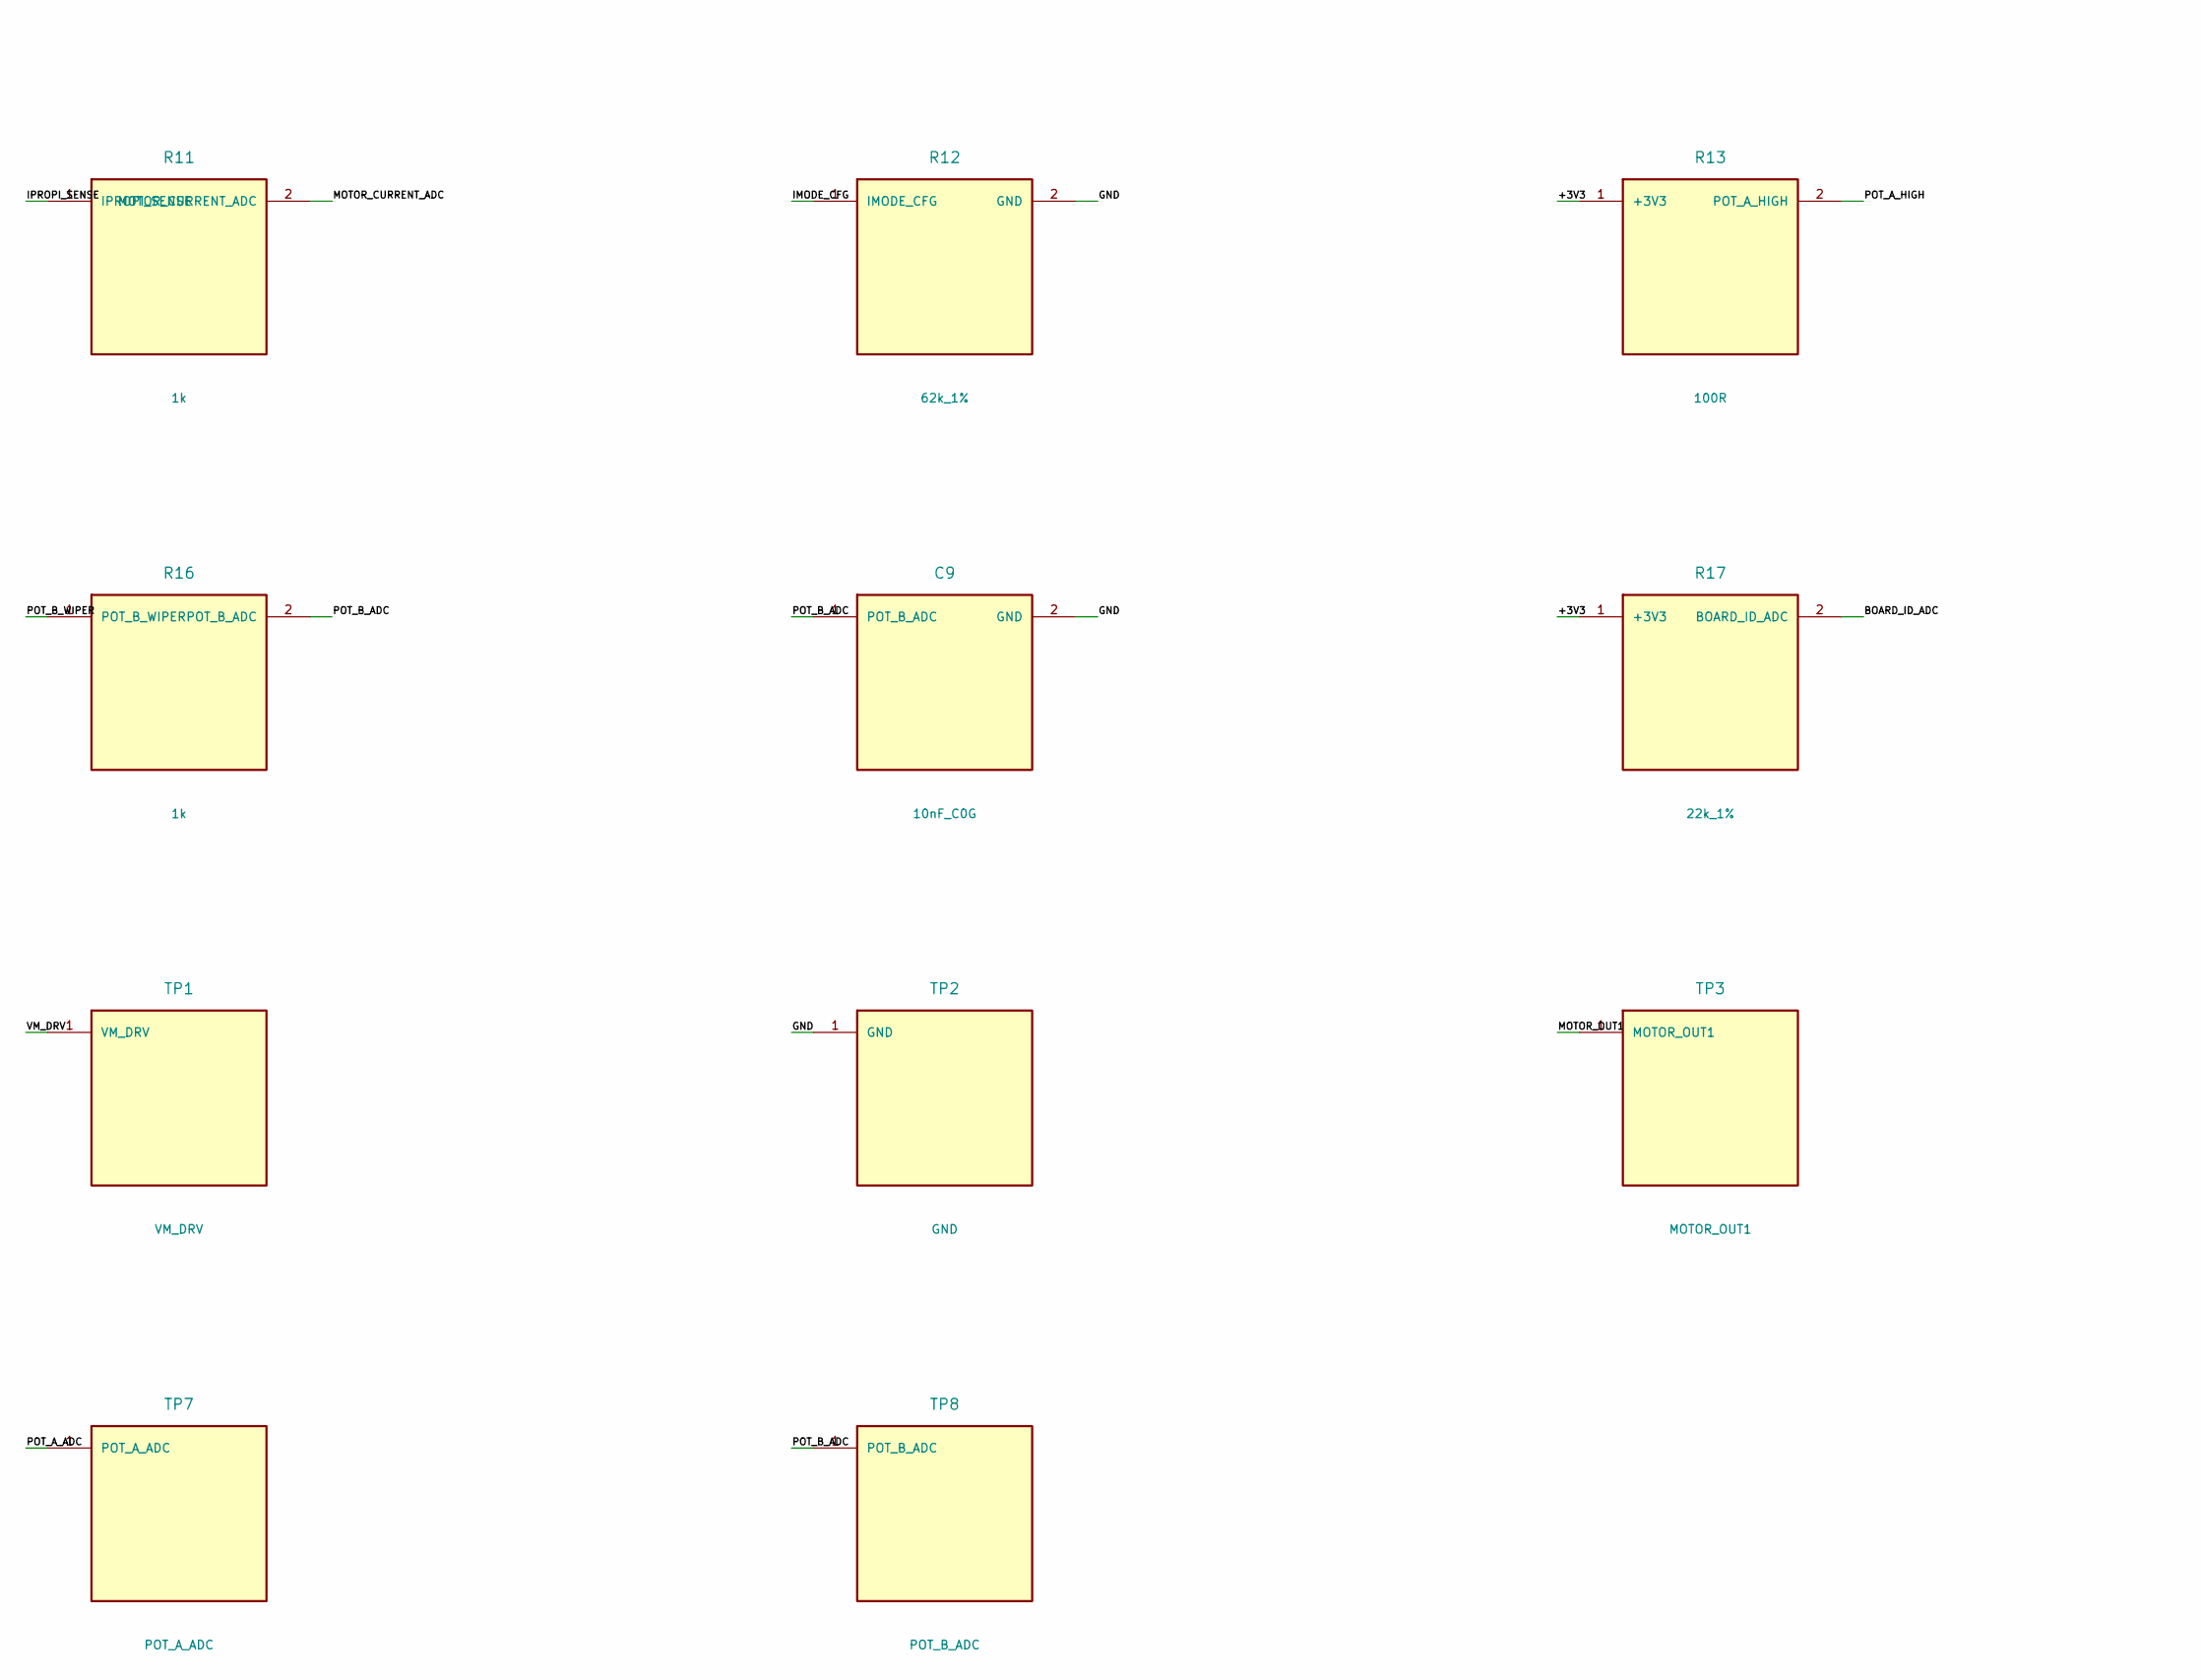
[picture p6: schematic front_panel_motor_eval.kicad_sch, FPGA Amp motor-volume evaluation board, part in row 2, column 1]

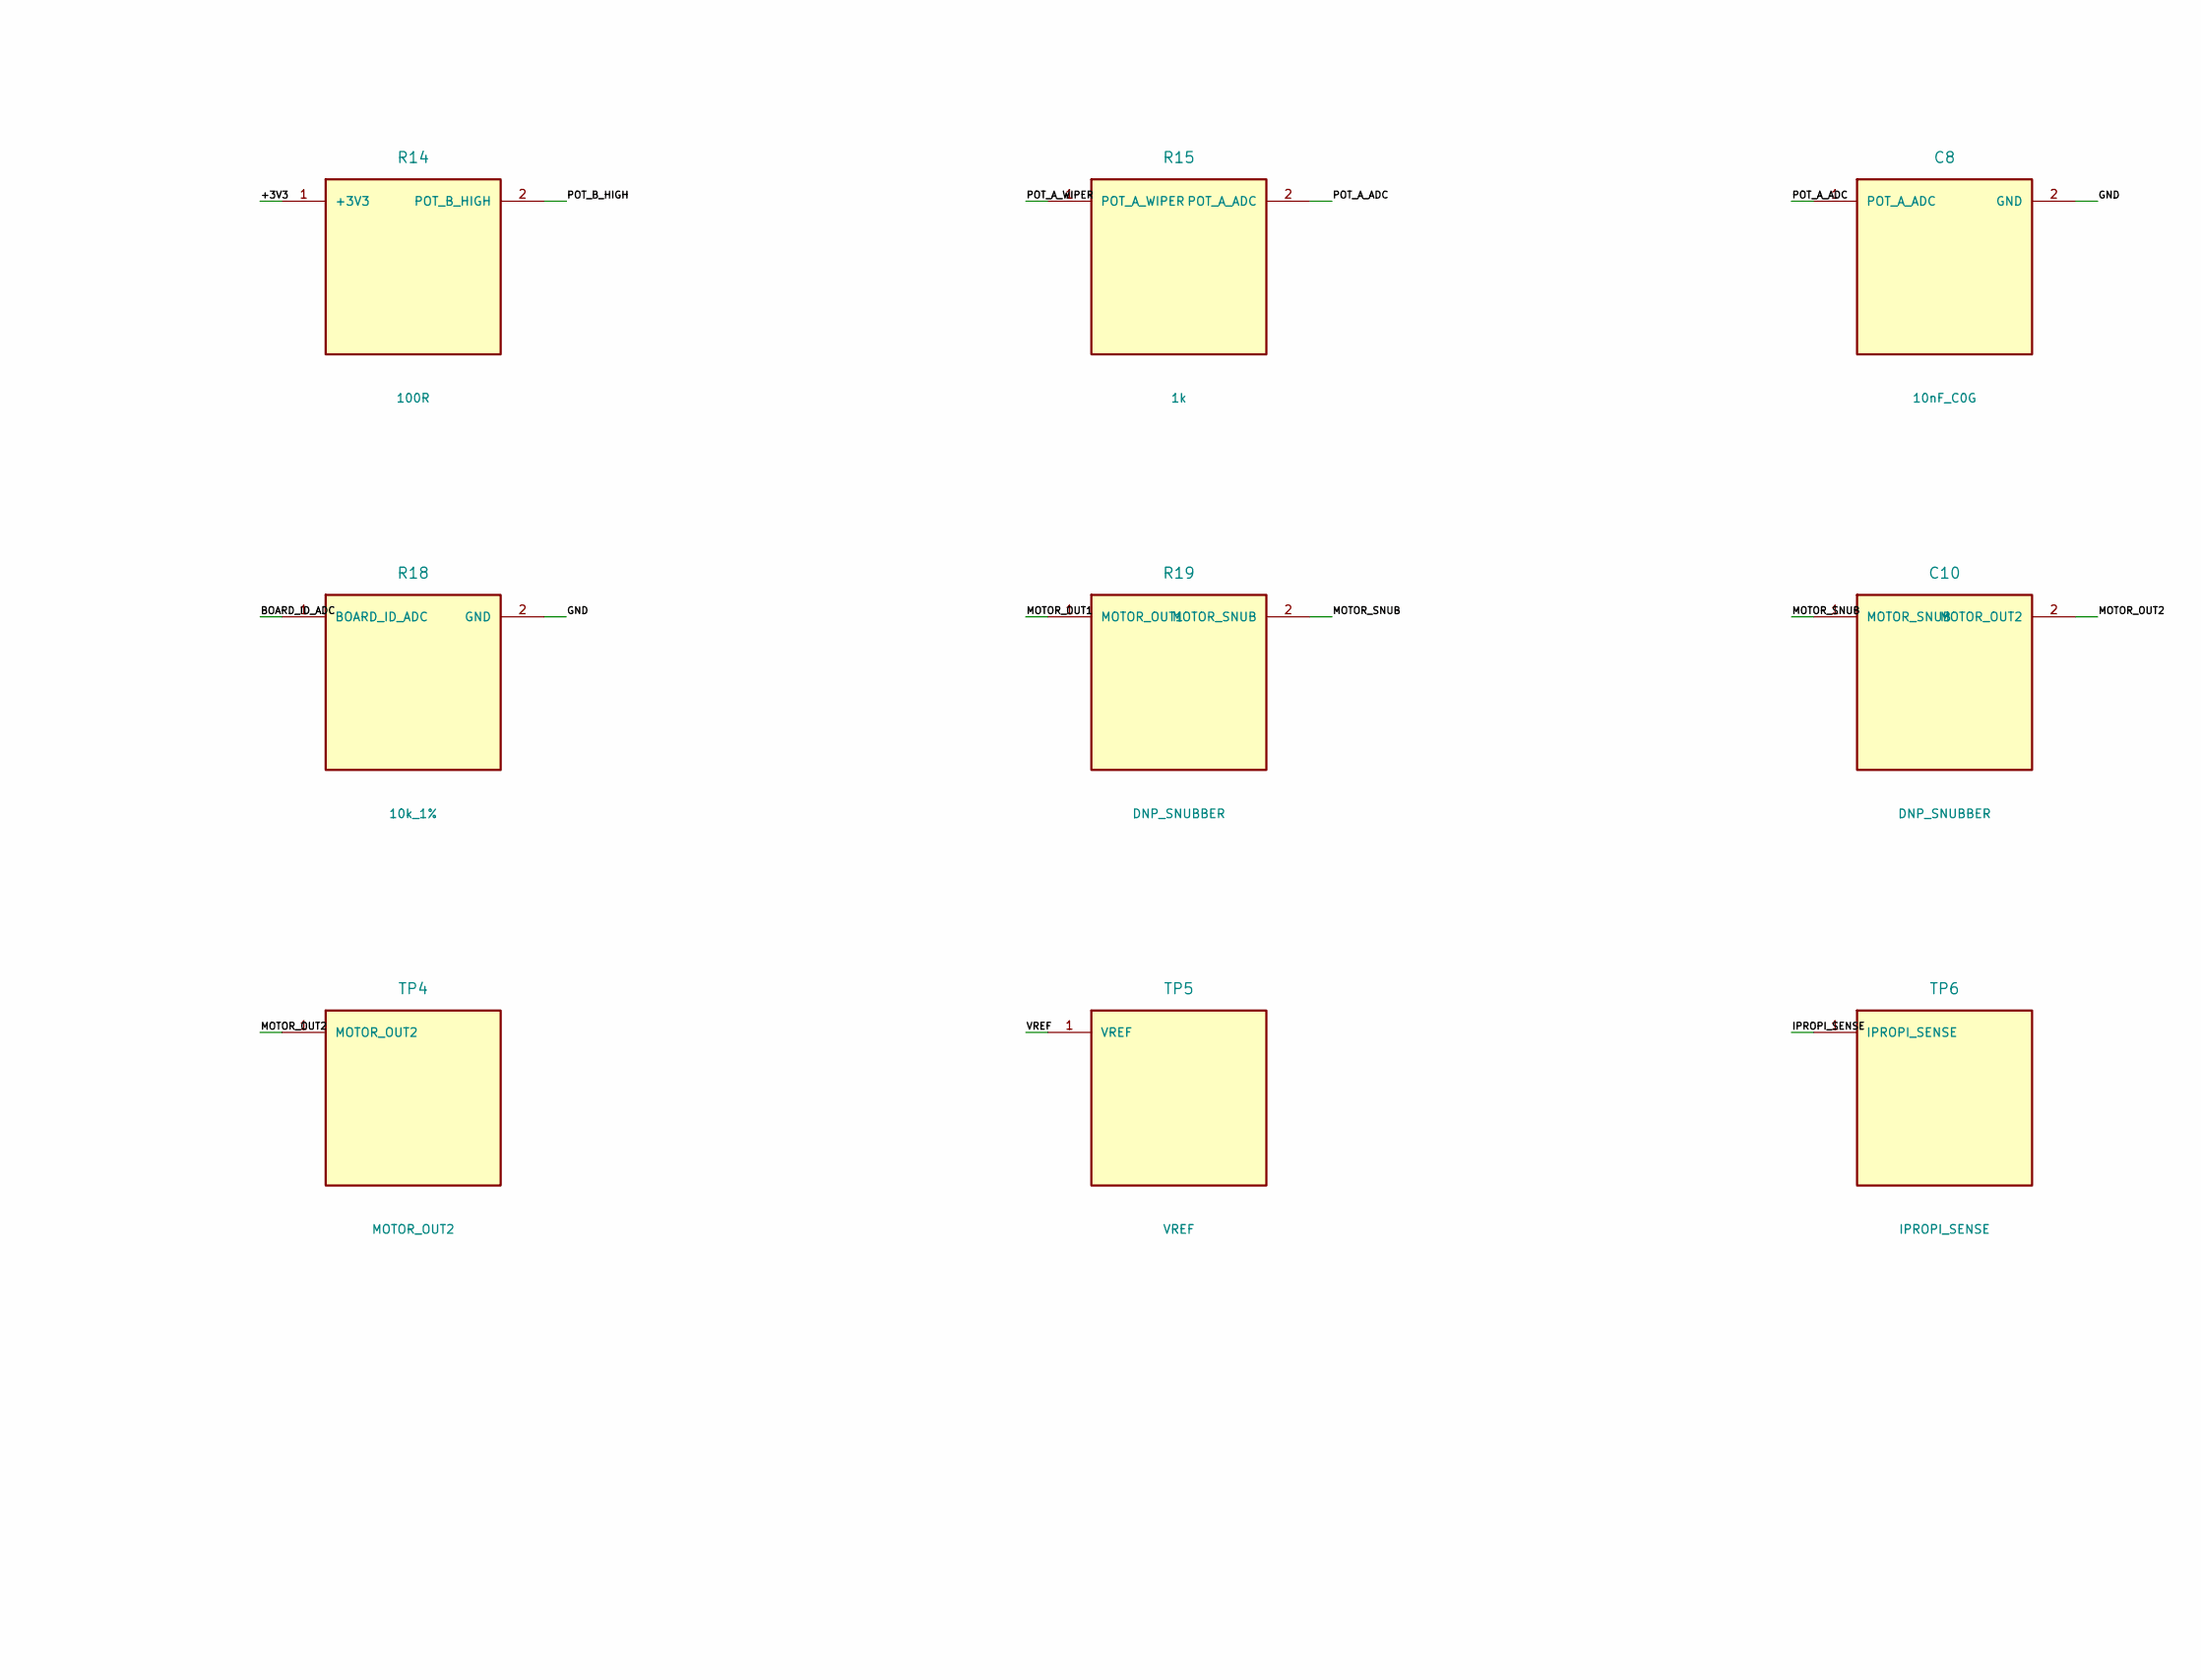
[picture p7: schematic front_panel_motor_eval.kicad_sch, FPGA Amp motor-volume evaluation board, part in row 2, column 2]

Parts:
C1: 100nF_50V_X7R; C_0805_2012Metric
C2: 10uF_16V_X7R; C_1210_3225Metric
C3: 220uF_10V_LOW_ESR; C_Elec_6.3x5.8
C4: 100nF_16V_X7R; C_0805_2012Metric
C5: 22nF_16V_X7R; C_0805_2012Metric
C6, C7: 10nF_X7R; C_0805_2012Metric
C8, C9: 10nF_C0G; C_0805_2012Metric
C10: DNP_SNUBBER; C_0805_2012Metric
D1: SMBJ6.0A; D_SMB
F1: 500mA_PTC; Fuse_1206_3216Metric
J1: MOTOR_5V_INPUT; JST_VH_B2P-VH-B_1x02_P3.96mm_Vertical
J2: FP_MCU_CONTROL; PinHeader_2x06_P2.54mm_Vertical
J3: PRM16_MOTOR; JST_VH_B2P-VH-B_1x02_P3.96mm_Vertical
J4: PRM16_POSITION; JST_XH_B6B-XH-A_1x06_P2.50mm_Vertical
R1, R3, R5: 33R; R_0805_2012Metric
R2, R4, R6: 100k; R_0805_2012Metric
R7: 10k; R_0805_2012Metric
R8: 14.7k_1%; R_0805_2012Metric
R9, R10, R18: 10k_1%; R_0805_2012Metric
R11, R15, R16: 1k; R_0805_2012Metric
R12: 62k_1%; R_0805_2012Metric
R13, R14: 100R; R_0805_2012Metric
R17: 22k_1%; R_0805_2012Metric
R19: DNP_SNUBBER; R_0805_2012Metric
TP1: VM_DRV; TestPoint_Plated_Hole_D2.0mm
TP2: GND; TestPoint_Plated_Hole_D2.0mm
TP3: MOTOR_OUT1; TestPoint_Plated_Hole_D2.0mm
TP4: MOTOR_OUT2; TestPoint_Plated_Hole_D2.0mm
TP5: VREF; TestPoint_Plated_Hole_D2.0mm
TP6: IPROPI_SENSE; TestPoint_Plated_Hole_D2.0mm
TP7: POT_A_ADC; TestPoint_Plated_Hole_D2.0mm
TP8: POT_B_ADC; TestPoint_Plated_Hole_D2.0mm
U1: DRV8874PWPR; HTSSOP-16-1EP_4.4x5mm_P0.65mm_EP3.4x5mm_Mask2.46x2.31mm

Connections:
+3V3: J2.1 (+3V3), R7.1 (+3V3), R8.1 (+3V3), R13.1 (+3V3), R14.1 (+3V3), R17.1 (+3V3)
BOARD_ID_ADC: J2.10 (BOARD_ID_ADC), R17.2 (BOARD_ID_ADC), R18.1 (BOARD_ID_ADC)
CPH: C5.1 (CPH), U1.13 (CPH)
CPL: C5.2 (CPL), U1.14 (CPL)
DIR_DRV: R3.2 (DIR_DRV), R4.1 (DIR_DRV), U1.2 (DIR_DRV)
GND: C1.2 (GND), C2.2 (GND), C3.2 (GND), C6.2 (GND), C7.2 (GND), C8.2 (GND), C9.2 (GND), D1.1 (GND), J1.2 (GND), J2.2 (GND), J2.11 (GND), J2.12 (GND), J4.3 (GND), J4.6 (GND), R2.2 (GND), R4.2 (GND), R6.2 (GND), R9.2 (GND), R10.2 (GND), R12.2 (GND), R18.2 (GND), TP2.1, U1.9 (GND), U1.15 (GND), U1.16 (GND), U1.17 (GND)
IMODE_CFG: R12.1 (IMODE_CFG), U1.7 (IMODE_CFG)
IPROPI_SENSE: C7.1 (IPROPI_SENSE), R10.1 (IPROPI_SENSE), R11.1 (IPROPI_SENSE), TP6.1, U1.6 (IPROPI_SENSE)
MOTOR_5V_IN: F1.1 (MOTOR_5V_IN), J1.1 (MOTOR_5V_IN)
MOTOR_CURRENT_ADC: J2.7 (MOTOR_CURRENT_ADC), R11.2 (MOTOR_CURRENT_ADC)
MOTOR_DIR: J2.4 (MOTOR_DIR), R3.1 (MOTOR_DIR)
MOTOR_FAULT_N: J2.6 (MOTOR_FAULT_N), R7.2 (MOTOR_FAULT_N), U1.4 (MOTOR_FAULT_N)
MOTOR_OUT1: J3.1 (MOTOR_OUT1), R19.1 (MOTOR_OUT1), TP3.1, U1.8 (MOTOR_OUT1)
MOTOR_OUT2: C10.2 (MOTOR_OUT2), J3.2 (MOTOR_OUT2), TP4.1, U1.10 (MOTOR_OUT2)
MOTOR_PWM: J2.3 (MOTOR_PWM), R1.1 (MOTOR_PWM)
MOTOR_SLEEP: J2.5 (MOTOR_SLEEP), R5.1 (MOTOR_SLEEP)
MOTOR_SNUB: C10.1 (MOTOR_SNUB), R19.2 (MOTOR_SNUB)
POT_A_ADC: C8.1 (POT_A_ADC), J2.8 (POT_A_ADC), R15.2 (POT_A_ADC), TP7.1
POT_A_HIGH: J4.1 (POT_A_HIGH), R13.2 (POT_A_HIGH)
POT_A_WIPER: J4.2 (POT_A_WIPER), R15.1 (POT_A_WIPER)
POT_B_ADC: C9.1 (POT_B_ADC), J2.9 (POT_B_ADC), R16.2 (POT_B_ADC), TP8.1
POT_B_HIGH: J4.4 (POT_B_HIGH), R14.2 (POT_B_HIGH)
POT_B_WIPER: J4.5 (POT_B_WIPER), R16.1 (POT_B_WIPER)
PWM_DRV: R1.2 (PWM_DRV), R2.1 (PWM_DRV), U1.1 (PWM_DRV)
SLEEP_DRV: R5.2 (SLEEP_DRV), R6.1 (SLEEP_DRV), U1.3 (SLEEP_DRV)
VCP: C4.1 (VCP), U1.12 (VCP)
VM_DRV: C1.1 (VM_DRV), C2.1 (VM_DRV), C3.1 (VM_DRV), C4.2 (VM_DRV), D1.2 (VM_DRV), F1.2 (VM_DRV), TP1.1, U1.11 (VM_DRV)
VREF: C6.1 (VREF), R8.2 (VREF), R9.1 (VREF), TP5.1, U1.5 (VREF)

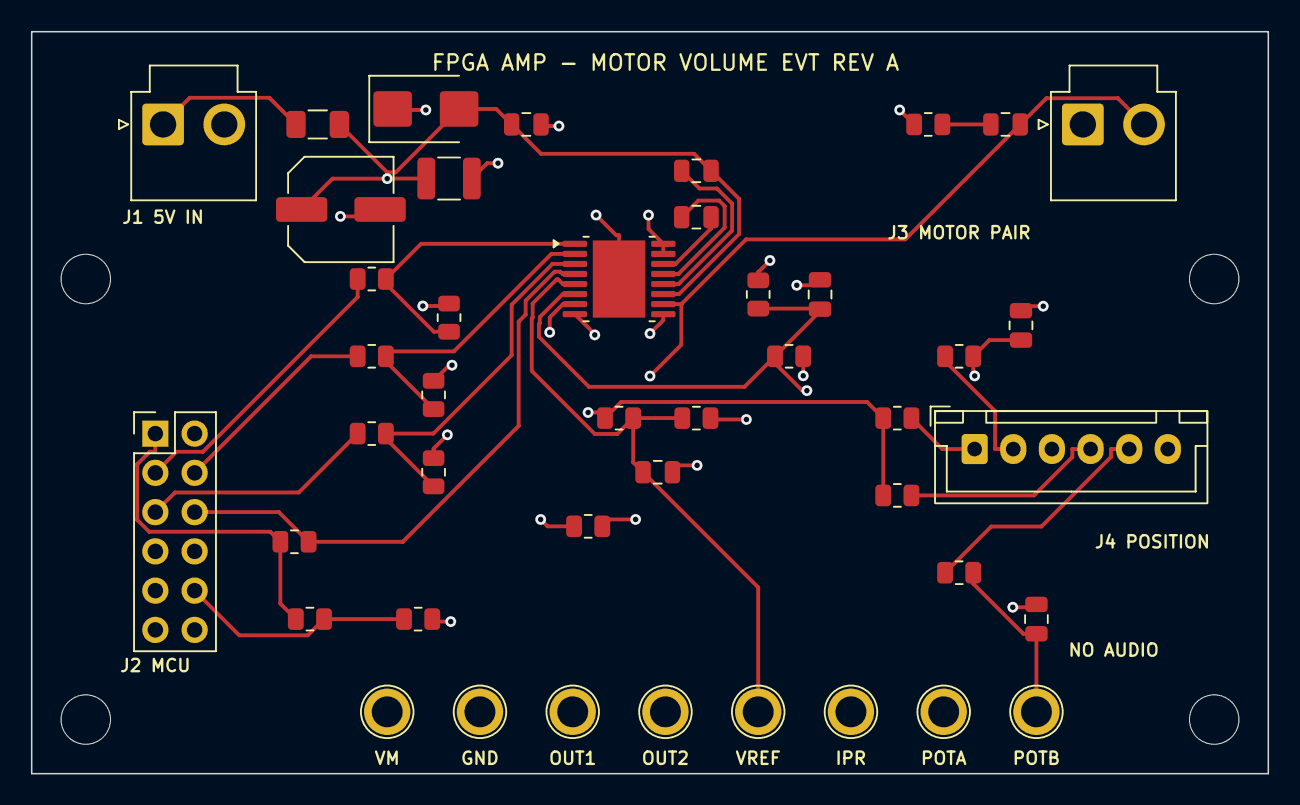
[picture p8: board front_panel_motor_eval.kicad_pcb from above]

Board: 4 copper layers, 80.0 x 48.0 mm, 48 parts (0 on the bottom side), 28 nets.

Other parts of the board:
H1, H2, H3, H4: M3_CHASSIS; MountingHole_3.2mm_M3

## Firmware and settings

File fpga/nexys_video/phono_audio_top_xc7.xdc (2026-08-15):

# Nexys Video Rev. A pins. Provenance: Digilent master XDC and board manual.
set_property LOC R4 [get_ports clk_100mhz]
set_property IOSTANDARD LVCMOS33 [get_ports clk_100mhz]
create_clock -period 10.000 [get_ports clk_100mhz]

set_property LOC G4 [get_ports cpu_resetn]
set_property IOSTANDARD LVCMOS15 [get_ports cpu_resetn]
set_property LOC E22 [get_ports force_mute_switch]
set_property IOSTANDARD LVCMOS12 [get_ports force_mute_switch]

set_property LOC U6 [get_ports codec_mclk]
set_property IOSTANDARD LVCMOS33 [get_ports codec_mclk]
set_property LOC T5 [get_ports codec_bclk]
set_property IOSTANDARD LVCMOS33 [get_ports codec_bclk]
# BCLK is a fabric-divider output routed through a BUFG and also clocks the
# digital audio domain.  nextpnr cannot derive this divide-by-16 relation from
# arbitrary logic, so constrain the shared internal/output clock explicitly.
create_clock -period 325.520833 [get_nets audio_and_control.i2s_bclk]
set_property LOC U5 [get_ports codec_lrclk]
set_property IOSTANDARD LVCMOS33 [get_ports codec_lrclk]
set_property LOC T4 [get_ports codec_adc_serial_data]
set_property IOSTANDARD LVCMOS33 [get_ports codec_adc_serial_data]
set_property LOC W6 [get_ports codec_dac_serial_data]
set_property IOSTANDARD LVCMOS33 [get_ports codec_dac_serial_data]
set_property LOC W5 [get_ports codec_i2c_scl]
set_property IOSTANDARD LVCMOS33 [get_ports codec_i2c_scl]
set_property LOC V5 [get_ports codec_i2c_sda]
set_property IOSTANDARD LVCMOS33 [get_ports codec_i2c_sda]

# Pmod JA: CS_N, SCLK, MOSI, MISO.
set_property LOC AB22 [get_ports spi_cs_n]
set_property IOSTANDARD LVCMOS33 [get_ports spi_cs_n]
set_property LOC AB21 [get_ports spi_sclk]
set_property IOSTANDARD LVCMOS33 [get_ports spi_sclk]
set_property LOC AB20 [get_ports spi_mosi]
set_property IOSTANDARD LVCMOS33 [get_ports spi_mosi]
set_property LOC AB18 [get_ports spi_miso]
set_property IOSTANDARD LVCMOS33 [get_ports spi_miso]

set_property LOC T14 [get_ports led_clocks_locked]
set_property IOSTANDARD LVCMOS25 [get_ports led_clocks_locked]
set_property LOC T15 [get_ports led_codec_configured]
set_property IOSTANDARD LVCMOS25 [get_ports led_codec_configured]
set_property LOC T16 [get_ports led_codec_error]
set_property IOSTANDARD LVCMOS25 [get_ports led_codec_error]
set_property LOC U16 [get_ports led_output_muted]
set_property IOSTANDARD LVCMOS25 [get_ports led_output_muted]

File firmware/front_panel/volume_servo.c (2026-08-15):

#include "volume_servo.h"

#include <limits.h>
#include <stddef.h>
#include <string.h>


static uint16_t clamp_position(const volume_servo_config_t *config, uint16_t position) {
    if (position < config->soft_min_position) {
        return config->soft_min_position;
    }
    if (position > config->soft_max_position) {
        return config->soft_max_position;
    }
    return position;
}


static uint16_t absolute_difference(uint16_t left, uint16_t right) {
    return left >= right ? (uint16_t)(left - right) : (uint16_t)(right - left);
}


static bool sensor_position_valid(
    const volume_servo_config_t *config,
    uint16_t position
) {
    return position >= config->hard_min_position && position <= config->hard_max_position;
}


static bool config_valid(const volume_servo_config_t *config) {
    return config != NULL
        && config->hard_min_position < config->soft_min_position
        && config->soft_min_position < config->soft_max_position
        && config->soft_max_position < config->hard_max_position
        && config->deadband_counts > 0u
        && config->approach_span_counts > config->deadband_counts
        && config->manual_takeover_counts > config->deadband_counts
        && config->minimum_duty_per_mille > 0u
        && config->minimum_duty_per_mille <= config->maximum_duty_per_mille
        && config->maximum_duty_per_mille <= 1000u
        && config->current_limit_ma > 0u
        && config->stall_tick_limit > 0u
        && config->motion_timeout_ticks > config->stall_tick_limit;
}


static void saturating_increment_u16(uint16_t *value) {
    if (*value != UINT16_MAX) {
        *value = (uint16_t)(*value + 1u);
    }
}


static void saturating_increment_u32(uint32_t *value) {
    if (*value != UINT32_MAX) {
        *value += 1u;
    }
}


static uint16_t requested_duty(
    const volume_servo_config_t *config,
    uint16_t error_counts
) {
    if (error_counts >= config->approach_span_counts) {
        return config->maximum_duty_per_mille;
    }
    const uint32_t duty_span =
        (uint32_t)config->maximum_duty_per_mille - config->minimum_duty_per_mille;
    const uint32_t scaled = duty_span * error_counts;
    return (uint16_t)(
        config->minimum_duty_per_mille + scaled / config->approach_span_counts
    );
}


static volume_servo_output_t make_output(
    const volume_servo_state_t *state,
    bool target_changed,
    uint16_t duty
) {
    volume_servo_output_t output = {
        .drive = state->drive,
        .duty_per_mille = state->drive == VOLUME_DRIVE_COAST ? 0u : duty,
        .target_position = state->target_position,
        .latched_faults = state->latched_faults,
        .accumulated_motor_ticks = state->accumulated_motor_ticks,
        .moving = state->drive != VOLUME_DRIVE_COAST,
        .target_changed = target_changed,
    };
    return output;
}


bool volume_servo_init(
    volume_servo_state_t *state,
    const volume_servo_config_t *config,
    uint16_t initial_position
) {
    if (state == NULL) {
        return false;
    }
    memset(state, 0, sizeof(*state));
    state->drive = VOLUME_DRIVE_COAST;
    if (!config_valid(config)) {
        state->latched_faults = VOLUME_FAULT_CONFIG;
        return false;
    }
    state->config = *config;
    if (!sensor_position_valid(config, initial_position)) {
        state->latched_faults = VOLUME_FAULT_SENSOR;
        return false;
    }
    state->target_position = clamp_position(config, initial_position);
    state->last_position = initial_position;
    state->configured = true;
    return true;
}


volume_servo_output_t volume_servo_step(
    volume_servo_state_t *state,
    const volume_servo_input_t *input
) {
    if (state == NULL || input == NULL) {
        volume_servo_output_t invalid = {0};
        invalid.latched_faults = VOLUME_FAULT_CONFIG;
        return invalid;
    }
    if (!state->configured) {
        state->drive = VOLUME_DRIVE_COAST;
        state->latched_faults |= VOLUME_FAULT_CONFIG;
        return make_output(state, false, 0u);
    }

    const volume_servo_config_t *config = &state->config;
    bool target_changed = false;
    const bool position_valid = sensor_position_valid(config, input->measured_position);

    if (!position_valid) {
        state->latched_faults |= VOLUME_FAULT_SENSOR;
    }
    if (input->driver_fault) {
        state->latched_faults |= VOLUME_FAULT_DRIVER;
    }

    if (input->clear_faults) {
        const bool safe_to_clear = position_valid
            && !input->driver_fault
            && input->measured_current_ma <= config->current_limit_ma
            && !input->manual_override;
        state->drive = VOLUME_DRIVE_COAST;
        state->motion_ticks = 0u;
        state->overcurrent_ticks = 0u;
        state->reverse_dead_remaining = 0u;
        if (safe_to_clear) {
            state->latched_faults = 0u;
            const uint16_t held_position = clamp_position(config, input->measured_position);
            target_changed = held_position != state->target_position;
            state->target_position = held_position;
            state->target_pending = false;
        }
        state->last_position = input->measured_position;
        return make_output(state, target_changed, 0u);
    }

    if (state->latched_faults != 0u) {
        state->drive = VOLUME_DRIVE_COAST;
        state->motion_ticks = 0u;
        state->reverse_dead_remaining = 0u;
        state->last_position = input->measured_position;
        return make_output(state, false, 0u);
    }

    if (input->manual_override) {
        const uint16_t manual_position = clamp_position(config, input->measured_position);
        target_changed = manual_position != state->target_position;
        state->target_position = manual_position;
        state->target_pending = false;
        state->drive = VOLUME_DRIVE_COAST;
        state->motion_ticks = 0u;
        state->overcurrent_ticks = 0u;
        state->reverse_dead_remaining = 0u;
        state->last_position = input->measured_position;
        return make_output(state, target_changed, 0u);
    }

    if (input->target_valid) {
        const uint16_t commanded = clamp_position(config, input->target_position);
        target_changed = commanded != state->target_position;
        state->target_position = commanded;
        state->target_pending = true;
    } else if (
        state->drive == VOLUME_DRIVE_COAST
        && state->reverse_dead_remaining == 0u
        && !state->target_pending
        && absolute_difference(input->measured_position, state->target_position)
            >= config->manual_takeover_counts
    ) {
        /* A manually back-driven idle dial becomes the new authoritative target. */
        const uint16_t manual_position = clamp_position(config, input->measured_position);
        target_changed = manual_position != state->target_position;
        state->target_position = manual_position;
        state->target_pending = false;
    }
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

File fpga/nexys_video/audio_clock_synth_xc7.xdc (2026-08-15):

# Nexys Video Rev. A clock-synthesis harness pins from Digilent's master XDC.
# R4 is the fixed 100 MHz oscillator. U6 is the ADAU1761 MCLK connection; the
# LED only proves divided generated-clock activity. This harness does not
# configure or exercise the codec.
set_property LOC R4 [get_ports clk_100mhz]
set_property IOSTANDARD LVCMOS33 [get_ports clk_100mhz]
create_clock -period 10.000 [get_ports clk_100mhz]

set_property LOC G4 [get_ports cpu_resetn]
set_property IOSTANDARD LVCMOS15 [get_ports cpu_resetn]

set_property LOC U6 [get_ports codec_mclk_12m288]
set_property IOSTANDARD LVCMOS33 [get_ports codec_mclk_12m288]

set_property LOC T14 [get_ports activity]
set_property IOSTANDARD LVCMOS25 [get_ports activity]

set_property LOC T15 [get_ports locked]
set_property IOSTANDARD LVCMOS25 [get_ports locked]

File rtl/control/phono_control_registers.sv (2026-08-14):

`timescale 1ns/1ps
`default_nettype none

// Protocol-neutral, fabric-clocked host boundary. The bus accepts one request
// per clock and returns a registered response one clock later. Diagnostic words
// are copied together only on an explicit snapshot command; reads never sample
// a moving counter directly.
module phono_control_registers #(
    parameter int unsigned DIAGNOSTIC_WORD_COUNT = 16,
    parameter int unsigned SNAPSHOT_TIMEOUT_CLOCKS = 131072
) (
    input  logic                 clk,
    input  logic                 rst_n,

    input  logic                 request_valid,
    input  logic                 request_write,
    input  logic [7:0]           request_address,
    input  logic [31:0]          request_write_data,
    output logic                 response_valid,
    output logic [31:0]          response_read_data,
    output logic                 response_error,

    input  logic [DIAGNOSTIC_WORD_COUNT*32-1:0] diagnostic_words_flat,
    input  logic                 diagnostic_capture_available,
    output logic                 diagnostic_capture_request,
    input  logic                 diagnostic_capture_valid,
    input  logic                 output_muted,
    input  logic                 output_ramping,

    output logic                 mute_request,
    output logic                 fabric_clear_diagnostics,
    output logic signed [31:0]   calibration_candidate_input_peak_q24,
    output logic signed [31:0]   calibration_candidate_output_reciprocal_q24,
    output logic                 calibration_update_valid,
    input  logic                 calibration_update_ack,
    input  logic                 calibration_invalid_update_sticky,
    input  logic                 calibration_unsafe_update_sticky,
    input  logic signed [31:0]   calibration_active_input_peak_q24,
    input  logic signed [31:0]   calibration_active_output_reciprocal_q24,

    output logic [31:0]          snapshot_sequence,
    output logic [31:0]          calibration_commit_sequence,
    output logic [31:0]          calibration_accepted_sequence,
    output logic                 bus_error_sticky,
    output logic                 calibration_rejected_sticky,
    output logic                 snapshot_capture_timeout_sticky
);

    localparam logic [7:0] ADDRESS_IDENTITY = 8'h00;
    localparam logic [7:0] ADDRESS_ABI_VERSION = 8'h01;
    localparam logic [7:0] ADDRESS_CAPABILITIES = 8'h02;
    localparam logic [7:0] ADDRESS_STATUS = 8'h03;
    localparam logic [7:0] ADDRESS_CONTROL = 8'h04;
    localparam logic [7:0] ADDRESS_SNAPSHOT_SEQUENCE = 8'h05;
    localparam logic [7:0] ADDRESS_CALIBRATION_COMMIT_SEQUENCE = 8'h06;
    localparam logic [7:0] ADDRESS_CALIBRATION_ACCEPTED_SEQUENCE = 8'h07;
    localparam logic [7:0] ADDRESS_CALIBRATION_SHADOW_INPUT = 8'h08;
    localparam logic [7:0] ADDRESS_CALIBRATION_SHADOW_OUTPUT = 8'h09;
    localparam logic [7:0] ADDRESS_CALIBRATION_COMMAND = 8'h0a;
    localparam logic [7:0] ADDRESS_CALIBRATION_ACTIVE_INPUT = 8'h0b;
    localparam logic [7:0] ADDRESS_CALIBRATION_ACTIVE_OUTPUT = 8'h0c;
    localparam logic [7:0] ADDRESS_STICKY_STATUS = 8'h0d;
    localparam logic [7:0] ADDRESS_DIAGNOSTIC_BASE = 8'h20;
    localparam int unsigned DIAGNOSTIC_INDEX_WIDTH =
        (DIAGNOSTIC_WORD_COUNT <= 2) ? 1 : $clog2(DIAGNOSTIC_WORD_COUNT);
    localparam logic [5:0] DIAGNOSTIC_WORD_COUNT_6 =
        DIAGNOSTIC_WORD_COUNT[5:0];
    localparam int unsigned SNAPSHOT_TIMEOUT_COUNTER_WIDTH =
        (SNAPSHOT_TIMEOUT_CLOCKS <= 2)
            ? 1 : $clog2(SNAPSHOT_TIMEOUT_CLOCKS);

    initial begin
        if (SNAPSHOT_TIMEOUT_CLOCKS < 2)
            $error("SNAPSHOT_TIMEOUT_CLOCKS must be at least two");
    end

    logic [31:0] diagnostic_snapshot [0:DIAGNOSTIC_WORD_COUNT-1];
    logic [DIAGNOSTIC_INDEX_WIDTH-1:0] diagnostic_read_index;
    logic [1:0] calibration_result_delay;
    logic [31:0] pending_calibration_sequence;
    logic calibration_busy;
    logic snapshot_valid;
    logic snapshot_busy;
    logic [SNAPSHOT_TIMEOUT_COUNTER_WIDTH-1:0] snapshot_timeout_counter;
    integer diagnostic_index;

    always_comb begin
        // The diagnostic aperture is the aligned 0x20--0x3f word page.
        diagnostic_read_index =
            request_address[DIAGNOSTIC_INDEX_WIDTH-1:0];
    end

    function automatic logic [31:0] increment_saturating(
        input logic [31:0] value
    );
        begin
            increment_saturating = (&value) ? value : value + 32'd1;
        end
    endfunction

    function automatic logic [31:0] status_word;
        begin
            status_word = '0;
            status_word[0] = mute_request;
            status_word[1] = output_muted;
            status_word[2] = output_ramping;
            status_word[3] = calibration_busy;
            status_word[4] = snapshot_valid;
            status_word[5] = snapshot_busy;
            status_word[6] = diagnostic_capture_available;
        end
    endfunction

    function automatic logic [31:0] sticky_status_word;
        begin
            sticky_status_word = '0;
            sticky_status_word[0] = bus_error_sticky;
            sticky_status_word[1] = calibration_rejected_sticky;
            sticky_status_word[2] = calibration_invalid_update_sticky;
            sticky_status_word[3] = calibration_unsafe_update_sticky;
            sticky_status_word[4] = snapshot_capture_timeout_sticky;
        end
    endfunction

    always_ff @(posedge clk or negedge rst_n) begin
        if (!rst_n) begin
            response_valid <= 1'b0;
            response_read_data <= '0;
            response_error <= 1'b0;
            mute_request <= 1'b1;
            fabric_clear_diagnostics <= 1'b0;
            diagnostic_capture_request <= 1'b0;
            calibration_candidate_input_peak_q24 <= '0;
            calibration_candidate_output_reciprocal_q24 <= '0;
            calibration_update_valid <= 1'b0;
            snapshot_sequence <= '0;
            calibration_commit_sequence <= '0;
            calibration_accepted_sequence <= '0;
            pending_calibration_sequence <= '0;
            calibration_result_delay <= '0;
            calibration_busy <= 1'b0;
            snapshot_valid <= 1'b0;
            snapshot_busy <= 1'b0;
            snapshot_timeout_counter <= '0;
            bus_error_sticky <= 1'b0;
            calibration_rejected_sticky <= 1'b0;
            snapshot_capture_timeout_sticky <= 1'b0;
            for (diagnostic_index = 0;
                 diagnostic_index < DIAGNOSTIC_WORD_COUNT;
                 diagnostic_index = diagnostic_index + 1) begin
                diagnostic_snapshot[diagnostic_index] <= '0;
            end
        end else begin
            response_valid <= request_valid;
            response_read_data <= '0;
            response_error <= 1'b0;
            fabric_clear_diagnostics <= 1'b0;
            diagnostic_capture_request <= 1'b0;
            calibration_update_valid <= 1'b0;
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

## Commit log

2026-08-12 reference: establish frozen V1 phono baseline
    [ge_12ax7_digitized.csv, riaa_e1_1978.csv]
2026-08-13 phono: integrate factorized tube solver mode
2026-08-13 model: expose capacitor state deadband
2026-08-13 rtl: implement wide branch-current network
2026-08-13 rtl: add trapezoidal capacitor KCL mode
2026-08-13 model: extract physical circuit recovery modes
2026-08-13 rtl: close capacitor delta width overflow
2026-08-13 rtl: saturate wide tube pin differences
2026-08-13 model: tighten trapezoidal cutoff selector
2026-08-13 tube: validate cutoff domain to minus eight volts
2026-08-13 tube: resolve grid conduction overload error
2026-08-13 model: split tube evaluation from circuit error
2026-08-14 io: add physical audio calibration
2026-08-14 io: align audio frames to core phase
2026-08-14 top: integrate calibrated mono fabric path
2026-08-14 control: guard atomic calibration updates
2026-08-14 test: measure pin-level transport latency
2026-08-14 control: integrate register-owned pin hierarchy
2026-08-14 control: add oversampled SPI transport
2026-08-14 control: compose SPI-controlled audio top
2026-08-14 control: add tested Python SPI client
2026-08-14 formal: prove atomic calibration commits
2026-08-14 formal: prove frame scheduler cadence
2026-08-14 formal: prove converter calibration arithmetic
2026-08-14 formal: bound SPI transport safety
2026-08-14 fpga: adopt open XC7 implementation flow
2026-08-14 rtl: add value-only factorized tube candidate
2026-08-14 rtl: isolate terminal current timing path
2026-08-14 rtl: stage KCL finish reductions
2026-08-14 rtl: share terminal-current arithmetic
2026-08-14 fpga: close shared terminal-current timing
2026-08-15 rtl: share KCL capacitor multiplier
2026-08-15 rtl: verify 384 kHz fixed solver
    [terminal_current_update_v1.sv]
2026-08-15 fpga: move tube selector after pin conversion
2026-08-15 audio: integrate 384 kHz pin hierarchy
2026-08-15 io: add open-drain I2C register writer
2026-08-15 fix: correct Nexys Video reset polarity
    [audio_clock_synth_xc7.xdc]
2026-08-15 fix: block pre-configuration I2S frames
2026-08-15 hardware: specify eARC touchscreen product platform
    [interface_budget.csv]
2026-08-15 firmware: add safe motor volume servo
2026-08-15 hardware: add KiCad motor-volume EVT board
    [bom.csv, front_panel_motor_eval.kicad_pcb, front_panel_motor_eval.kicad_sch]
2026-08-15 hardware: route front-panel controller EVT board
    [bom.csv, front_panel_controller.kicad_pcb, front_panel_controller.kicad_sch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]
2026-08-15 hardware: verify exact display FFC footprints
    [bom.csv, front_panel_controller.kicad_pcb, front_panel_controller.kicad_sch]
2026-08-15 hardware: add routed MM phono ADC EVT board
    [bom.csv, phono_adc_eval.kicad_pcb, phono_adc_eval.kicad_sch]
2026-08-15 hardware: add routed PCM5242 line-output EVT board
    [bom.csv, dac_line_output_eval.kicad_pcb, dac_line_output_eval.kicad_sch]
2026-08-15 rtl: add I2C register read primitive
2026-08-15 rtl: sequence DAC relays and soft unmute
